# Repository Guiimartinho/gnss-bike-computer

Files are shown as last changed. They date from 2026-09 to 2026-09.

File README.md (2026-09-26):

<div align="center">

# GNSS Bike Computer

**Computador de bordo para ciclismo com GPS: segmentos do Strava em tempo real, percursos, altimetria por fusão de sensores e sensores sem fio. Portado do stravaV10 para Zephyr, do nRF52840 da myStravaB V3 para o nRF54LM20A de uma placa própria com GNSS de banda dupla e painel solar.**











</div>

O projeto leva para o nRF Connect SDK o **stravaV10**, firmware aberto de Vincent Gollé para a placa **myStravaB V3**: um aparelho em retrato com LCD de memória Sharp, GNSS MediaTek, barômetro, acelerômetro, medidor de bateria, microSD e rádio BLE + ANT+. O código original fica em [`legacy/`](legacy/) como referência de comportamento; o port em C puro sobre Zephyr fica em [`zephyr_app/`](zephyr_app/) e compila para o nRF54LM20 DK, para a placa do projeto (`gnssbike/nrf54lm20a/cpuapp`) e ainda para o nRF52840-DK, que saiu de uso. A próxima placa é própria, com o nRF54LM20A, GNSS de banda dupla, tela colorida e painéis solares na caixa que estendem a autonomia, sem sustentar o aparelho sozinhos; a especificação e a avaliação dos componentes estão em [`docs/`](docs/README.md).

> [!WARNING]
> O port **compila e passa nos testes de host, mas nunca rodou em placa nem nos DKs**. Segmentos, percursos, sensores BLE e ANT+, log no SD e a interface do legacy ainda não funcionam de ponta a ponta. A placa nova ainda não existe: nenhum componente foi comprado nem medido. O estado de cada área está em [docs/10-status-do-port.md](docs/10-status-do-port.md).

## Índice

- [Visão geral](#visão-geral)
- [Placa nova](#placa-nova)
- [Funcionalidades](#funcionalidades)
- [Início rápido](#início-rápido)
- [Estrutura](#estrutura)
- [Documentação](#documentação)
- [Estado e próximos passos](#estado-e-próximos-passos)
- [Créditos e licenças](#créditos-e-licenças)

## Visão geral

```mermaid
flowchart LR
    subgraph DEV["myStravaB V3 · nRF52840"]
        MODEL["modelo<br/>altitude, potência,<br/>segmentos, percurso"]
        VUE["interface<br/>LCD LS027 + 3 botões"]
        LOG["log no microSD"]
    end
    GNSS["GNSS M10578-A3"] -->|NMEA| MODEL
    SENS["BME280 · FXOS8700 · STC3100"] -->|I2C| MODEL
    SENSORS["frequência cardíaca, cadência,<br/>potência, rolo"] -->|"ANT+ / BLE"| MODEL
    PHONE["celular<br/>Komoot, LNS"] -->|BLE| MODEL
    MODEL --> VUE
    MODEL --> LOG
    PC["PC"] <-->|"USB / stravaAP"| DEV
```

## Placa nova

<div align="center">

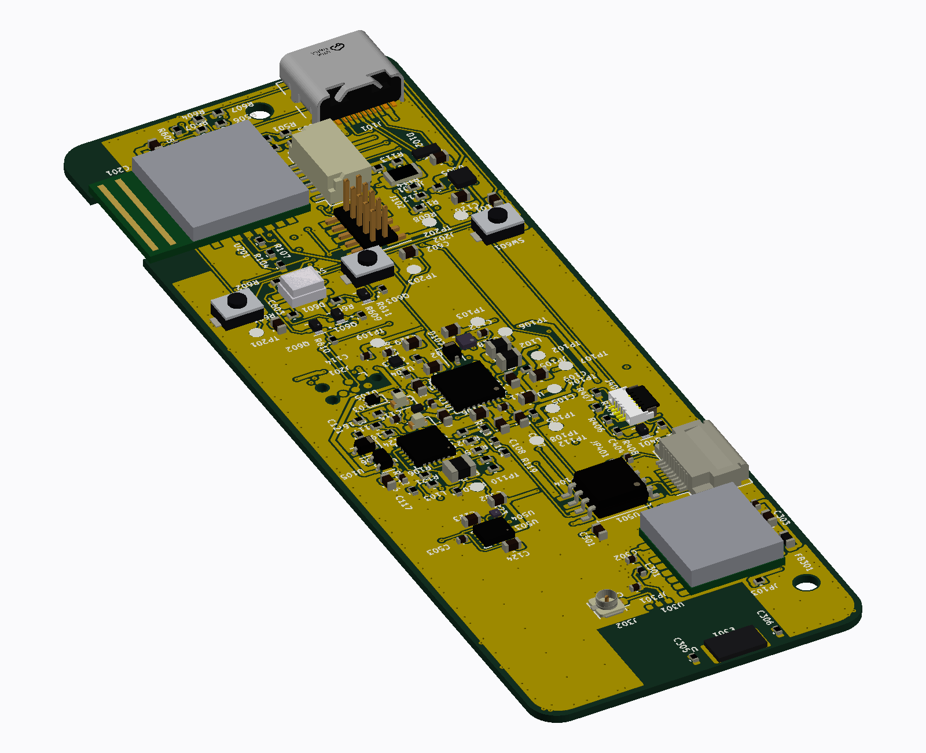
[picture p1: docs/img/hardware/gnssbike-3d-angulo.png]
A placa em CAD, vista em ângulo: o USB-C na borda de cima, o módulo de rádio à esquerda e o receptor GNSS à direita


*A placa `gnssbike`, 34 × 95 mm em 4 camadas, gerada por programa a partir dos documentos de `hardware_gnssbike/`.*

</div>

| | |
|---|---|
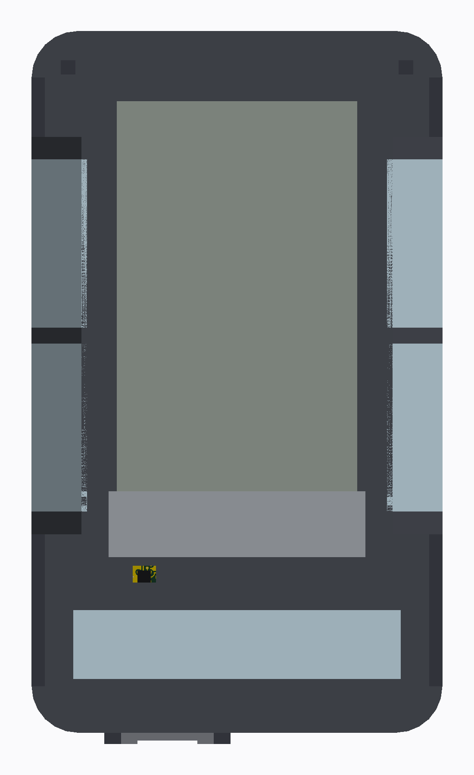
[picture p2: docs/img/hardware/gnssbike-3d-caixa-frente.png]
A caixa proposta, vista de frente: janela do display, três teclas sob a membrana, módulos solares nos chanfros e na faceta
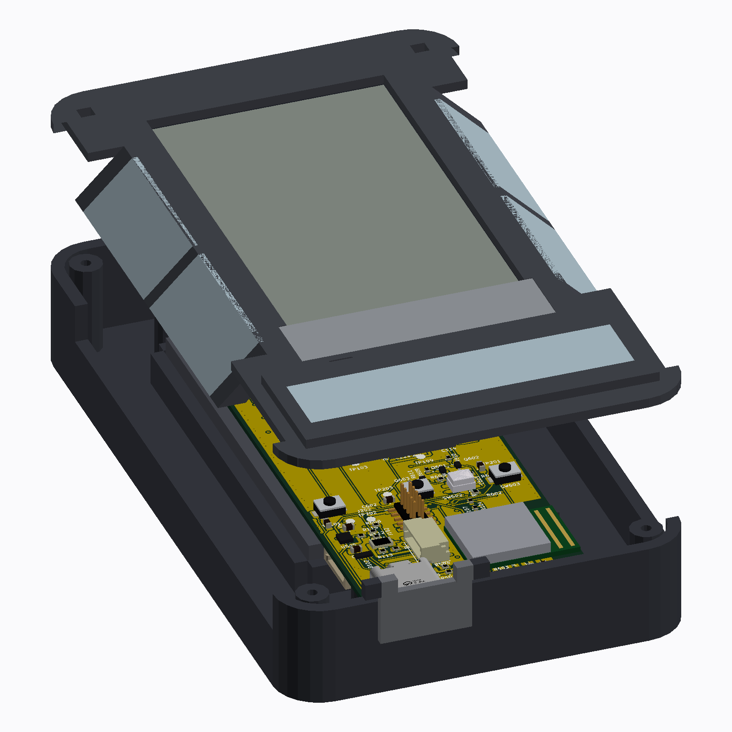
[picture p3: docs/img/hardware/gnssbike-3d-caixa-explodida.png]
A caixa em vista explodida: tampa com o display colado, teclas, módulos e coberturas, a porta do USB-C
|  |  |
| *A caixa proposta em 2026-09-26, 62 × 106 × 17 mm, medida por um dry run próprio* | *Explodida: tampa com o display, teclas, módulos solares, porta do USB-C* |

Manual de montagem: as peças em escala e os oito passos, do chicote solar ao fechamento do aparelho

A caixa foi desenhada em volta da placa real ([`hardware_gnssbike/caixa/`](hardware_gnssbike/caixa/README.md), decisões em [`hardware_gnssbike/04`](hardware_gnssbike/04-pcb-e-caixa.md#a-placa-de-hoje-dentro-da-caixa-do-conceito)); a placa, dimensionada pelo circuito e **não** pela caixa, tem 34 × 95 mm em 4 camadas, 6 módulos solares na faceta e nos chanfros laterais da caixa. A escolha de cada componente, com os números dos datasheets, está em [docs/15-avaliacao-componentes.md](docs/15-avaliacao-componentes.md); a lista de compras, validada peça a peça, em [docs/19-lista-de-compras.md](docs/19-lista-de-compras.md).

A placa existe como **arquivo de CAD**, gerado por programa: 156 peças, 114
redes, 1.417 segmentos, 549 vias, **196 ligações roteadas e 75 ainda sem
trilha**, 0 erros no DRC completo, e 25 das 29 medidas que as fichas dos
componentes e a IPC-2221B impõem, feitas uma a uma
([dry-run de 2026-09-26](hardware_gnssbike/10-dry-run-2026-09-26.md)); a
caixa existe como proposta em volta dela, medida por um dry run próprio (12
regras cumpridas, 0 violadas). Nenhuma placa foi fabricada, nada foi
impresso e nenhum componente passou por bancada. O esquemático, a placa, a
caixa e como se confere cada etapa estão em
[hardware_gnssbike/](hardware_gnssbike/README.md).

```mermaid
flowchart LR
    MCU["MinewSemi ME54BS13<br/>nRF54LM20A, BLE e ANT+"]
    GNSS2["u-blox MAX-F10S<br/>L1 + L5, 46,8 mW"] -->|UART| MCU
    LCD2["JDI LPM027M128C de 8 cores,<br/>com luz frontal integrada"] ---|SPI| MCU
    PWR["nPM1300, ADP5091, MAX17262<br/>USB-C e painel solar"] -.->|I2C| MCU
    SENS2["BMP585, BMI270,<br/>MMC5603NJ, OPT3001"] -->|I2C| MCU
    MEM["flash MX25R6435F<br/>8 MB, soldada"] ---|SPI| MCU
```

| Bloco | Escolha | Por quê |
|---|---|---|
| Carga | nPM1300 no USB-C, ADP5091 no painel, MAX17262 na célula | o painel carrega com o aparelho desligado e corte térmico próprio; o USB bloqueia a carga solar no hardware |
| GNSS | u-blox MAX-F10S, banda dupla L1 + L5, com o MAX-M10N-10B (só L1) no mesmo footprint | 1 m de CEP contra 1,5 m, e o código do L5 contra o multipercurso de prédio e mata. Custa autonomia: o aparelho gasta cerca de 58 mW e dura cerca de 115 h sem sol, e o painel devolve de 23 a 46 min por hora de sol em vez de cobrir o consumo. Com o M10N em LEAP seriam cerca de 21 mW e 310 h (estimativas) |
| Tela | JDI LPM027M128C de 8 cores, **com luz frontal integrada** (escolha do dono em 2026-09-23, no lugar do par Sharp + filme); a Sharp LS027B7DH01A com filme no mesmo conector, de reserva | o firmware atende as duas pelo mesmo driver, em retrato, com um tema para cada |
| USB e armazenamento | USB-C HRO TYPE-C-31-M-12 e flash MX25R6435F soldada | caixa sem tampas e sem cartão solto na vibração |

## Funcionalidades

| Funcionalidade | Legacy | Port |
|---|---|---|
| Segmentos do Strava com avanço contra o recorde | sim | lógica portada, sem carga de dados |
| Percurso com mapa e zoom | sim | parcial, não ligado |
| Altitude por Kalman de 3 estados, subida, inclinação | sim | portado com diferenças |
| Potência estimada | sim | fórmula diferente |
| Sensores ANT+ (FC, velocidade e cadência, rolo FE-C) | sim | a pilha do add-on `sdk-ant` compila com o NCS v3.3.0 (`ANT=1`) e o firmware abre canal escravo; **nenhum canal abre de fato**, porque os perfis ficam fora do repositório e `GNSS_ANT_*_DEV_TYPE` valem 0 |
| BLE (potência, posição do celular, Komoot) | sim | parcial |
| Zonas de potência, suffer score, variabilidade da FC | sim | portados e testados, sem dados reais |
| Log no microSD e download pelo PC | sim | FatFs de verdade, gravado pelo serviço de armazenamento; não testado com cartão |
| USB serial e mass storage | sim | serviço `usb` no build (CDC dos comandos e o disco do ciclista); não testada com cabo |
| Telas em retrato, menu, notificações, botões | sim | LVGL no firmware com driver próprio da tela, 44 quadros testados no PC; nunca vistos num painel |

## Início rápido

**Pré-requisitos** (Windows): nRF Connect SDK v3.3.0 em `C:\ncs` com o toolchain `936afb6332`, SEGGER J-Link, nRF54LM20 DK (o nRF52840-DK ainda compila, mas saiu de uso). Para o ANT, o add-on `sdk-ant` em `C:\ncs\sdk-ant`, depois de aceitar o acordo ANT+ ([07](docs/07-radio-ant-ble.md#ant-no-ncs-v330)). Para os testes de host: MinGW-w64 GCC, CMake e Ninja. Detalhes em [docs/03-ambiente-build.md](docs/03-ambiente-build.md).

Código: [github.com/Guiimartinho/gnss-bike-computer](https://github.com/Guiimartinho/gnss-bike-computer) (`git clone https://github.com/Guiimartinho/gnss-bike-computer.git`).

```sh
# Git Bash, na raiz do repositório
bash tools/fw/fw.sh build          # compila o zephyr_app (sysbuild) para o nRF54LM20 DK
bash tools/fw/fw.sh flash          # grava no DK pelo J-Link
BOARD=gnssbike/nrf54lm20a/cpuapp BUILD_DIR=zephyr_app/build_custom bash tools/fw/fw.sh build   # a placa do projeto
ANT=1 bash tools/fw/fw.sh build pristine   # com a pilha ANT do sdk-ant
bash tools/fw/host_tests.sh        # 53 conjuntos, 714 casos
python tools/ui/render_screens.py  # desenha os 44 quadros no PC (docs/telas)
python tools/docs/mermaid_check.py # valida os diagramas da documentação
```

No `cmd` ou com duplo clique: `build.bat`, `flash.bat`, `recover.bat`, `serial.bat COMx`.

O CI (`.github/workflows/ci.yml`) está **desligado**: só roda à mão, pela aba Actions do GitHub ([detalhes](docs/03-ambiente-build.md#ci)).

## Estrutura

```mermaid
flowchart TB
    ROOT["gnss_bike_computer/"]
    ROOT --> ZA["zephyr_app/<br/>port Zephyr: src, include, boards, modules, tests/host"]
    ROOT --> LEG["legacy/<br/>stravaV10 original (referência)"]
    ROOT --> LIB["libraries/<br/>bibliotecas do legacy"]
    ROOT --> TOOLS["tools/<br/>fw e docs do projeto · TDD, zpm, MMD, jumper do legacy"]
    ROOT --> HW["hardware/<br/>Eagle da myStravaB V3 (Gerbers da V2)"]
    ROOT --> HWN["hardware_gnssbike/<br/>a placa nova: docs 01 a 10, cad (KiCad e geradores),<br/>esquematico, placa, caixa (PDF, STL, dry run), datasheets"]
    ROOT --> DOCS["docs/<br/>documentação numerada, img (telas, hardware), historico"]
    ROOT --> AI["CLAUDE.md · AGENTS.md · .claude/skills/"]
    ROOT --> BAT["build.bat · flash.bat · recover.bat · serial.bat"]
```

## Documentação

| Documento | Assunto |
|---|---|
| [01 · Visão geral](docs/01-visao-geral.md) | produto, modos, legacy e port |
| [02 · Hardware](docs/02-hardware.md) | placa, pinagem, alimentação, alvo no DK |
| [03 · Ambiente e build](docs/03-ambiente-build.md) | NCS v3.3.0, scripts, gravação, problemas conhecidos |
| [04 · Arquitetura do legacy](docs/04-arquitetura-legacy.md) | tasks, modos, glossário |
| [05 · Arquitetura do port](docs/05-arquitetura-zephyr.md) | threads, fluxo de dados, pilhas, devicetree |
| [06 · Algoritmos](docs/06-algoritmos.md) | fórmulas e constantes, legacy × port |
| [07 · Rádio](docs/07-radio-ant-ble.md) | ANT+, BLE, stravaAP, Komoot |
| [08 · Interface](docs/08-interface.md) | telas, menus, botões |
| [09 · Armazenamento e USB](docs/09-armazenamento-usb.md) | formatos de arquivo, SD, USB |
| [10 · Status do port](docs/10-status-do-port.md) | matriz, correções, defeitos, roteiro, decisões |
| [11 · Qualidade e MISRA](docs/11-qualidade-misra.md) | regras e análise estática |
| [12 · Ferramentas e testes](docs/12-ferramentas-testes.md) | testes de host, simulador do legacy, licenças |
| [13 · Placa nova](docs/13-placa-nova.md) | proposta de hardware da placa própria |
| [14 · Hardware da placa nova](docs/14-hardware-placa-nova.md) | especificação técnica: alimentação, lista de materiais, pinos, PCB |
| [15 · Avaliação dos componentes](docs/15-avaliacao-componentes.md) | escolha de cada componente da placa nova, com números de datasheet |
| [16 · Arquitetura do firmware](docs/16-arquitetura-firmware.md) | arquitetura-alvo e máquinas de estado para a placa nova |
| [17 · Dispositivos BLE e ANT+](docs/17-dispositivos-ble-ant.md) | catálogo de sensores e acessórios, prioridades e limites do rádio |
| [18 · Interface e telas](docs/18-interface-telas.md) | interface LVGL da placa nova: todas as telas, desenhadas e testadas no PC, em 8 cores e em preto e branco |
| [19 · Lista de compras](docs/19-lista-de-compras.md) | peças validadas em duas passagens, trocas, correções de integração e códigos da DigiKey |
| [Hardware da placa nova](hardware_gnssbike/README.md) | o esquemático folha a folha, os cálculos, a lista de nós, a placa e a caixa, os conectores, o layout e os dois dry runs; o CAD em [`cad/`](hardware_gnssbike/cad/README.md), a caixa em [`caixa/`](hardware_gnssbike/caixa/README.md), os PDF em [`esquematico/`](hardware_gnssbike/esquematico/) e [`placa/`](hardware_gnssbike/placa/) |
| [CHANGELOG](CHANGELOG.md) | histórico de mudanças |

## Estado e próximos passos

- **Feito em 2026-09-18:** build no NCS v3.3.0 com sysbuild; correção de 13 defeitos críticos (estouro de pilha no Kalman, GPS e modelo dentro de ISR, corrupção de memória no log, botões e pinos do GPS invertidos, conflitos de pinos com o DK); testes de host; documentação e contexto para assistentes de IA.
- **Fase 1 do roteiro:** a base da arquitetura nova (serviços com thread própria, eventos no zbus, máquinas de sistema e de modo no SMF, watchdog por serviço, desligamento automático do legacy), feita em 2026-09-19.
- **Novos alvos e rádio:** o port compila para o nRF54LM20 DK, e a pilha ANT do add-on `sdk-ant` v2.1.1 compila sobre o NCS v3.3.0 nos dois DKs (`ANT=1`); nada disso foi testado em placa.
- **Interface:** os 44 quadros em LVGL, testadas no PC, rodam no firmware desde 2026-09-19 com um driver próprio da tela (JDI LPM027M128B em 8 cores ou Sharp em preto e branco, em retrato), teclas com toque longo e a máquina da luz; nunca vistas num painel.
- **Placa nova:** desenho do aparelho, especificação ([14](docs/14-hardware-placa-nova.md)) e avaliação dos componentes ([15](docs/15-avaliacao-componentes.md)). O esquemático é do dono; antes do layout vêm os testes de bancada da carga dupla, do GNSS (C/N0 por banda e isolamento da antena contra o rádio de 2,4 GHz), da coexistência dos rádios e do display.
- **Hardware da placa nova (2026-09-23 a 26):** o esquemático em sete folhas, a placa de 34 × 95 mm colocada e roteada por programa, o desenho de montagem, o manual e o chicote solar, dois dry runs (as regras das fichas e da IPC-2221 medidas no arquivo; a caixa medida contra a placa) e a proposta de caixa de 62 × 106 × 17 com STL para a primeira prova. Nada fabricado, nada impresso, nenhum componente na bancada; o que falta antes de mandar fabricar está em [`hardware_gnssbike/README.md`](hardware_gnssbike/README.md#antes-de-mandar-fabricar).
- **Decidido:** ANT+ e BLE juntos (os equipamentos externos falam ANT+) e placa própria com o nRF54LM20A. Decisões e pendências em [docs/10-status-do-port.md](docs/10-status-do-port.md#decisões-do-dono).
- **Próximo:** os testes de bancada da placa nova (carga dupla, isolamento entre as antenas, o display sobre a antena GNSS), o roteamento que falta e a primeira prova impressa da caixa; no firmware, fidelidade dos algoritmos, armazenamento, rádio e interface. Roteiro em [docs/10-status-do-port.md](docs/10-status-do-port.md#roteiro).

## Créditos e licenças

- **stravaV10** e **myStravaB**: Vincent Gollé ([vincent290587/stravaV10](https://github.com/vincent290587/stravaV10)), licenciado sob **Creative Commons Atribuição-NãoComercial 4.0 (CC BY-NC 4.0)**. O port deriva desse código; ver [`legacy/README.md`](legacy/README.md).
- Bibliotecas de terceiros em `libraries/` e `tools/` mantêm suas licenças (BSD, LGPL-2.1, GPL-2.0, Nordic, SEGGER): tabela em [docs/12-ferramentas-testes.md](docs/12-ferramentas-testes.md#bibliotecas-e-licenças).
- O add-on `sdk-ant` e o material ANT+ não fazem parte do repositório: o ANT+ Adopter Agreement proíbe redistribuir ([07](docs/07-radio-ant-ble.md#decisão-ant-e-ble)).
- **Este projeto é CC BY-NC 4.0** ([`LICENSE`](LICENSE), decisão do dono em 2026-09-26): código, hardware e documentação podem ser copiados, estudados, modificados e redistribuídos, com atribuição, e **não podem ser usados comercialmente**. É a mesma licença do stravaV10, do qual o port deriva, e por isso a restrição vale sobre o todo. Não é uma licença "open source" no sentido da OSI, que não admite restrição de uso: é código aberto com uso não comercial. Uso comercial só com autorização por escrito do dono e, para o que vem do stravaV10, do autor dele.

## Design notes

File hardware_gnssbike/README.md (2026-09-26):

<div align="center">

# Hardware · GNSS Bike Computer

**Placa `gnssbike`, nRF54LM20A no módulo MinewSemi ME54BS13**










</div>

A placa vista em ângulo, com o USB-C na borda de cima, o módulo de rádio à esquerda e o receptor GNSS à direita

O hardware completo do aparelho: cada folha do esquemático, cada ligação, a
conta que justifica cada valor — e a placa, com as peças postas, o cobre
roteado e as vistas 2D e 3D. Nasce da especificação de
[`docs/14`](../docs/14-hardware-placa-nova.md), da avaliação de
[`docs/15`](../docs/15-avaliacao-componentes.md) e da lista validada de
[`docs/19`](../docs/19-lista-de-compras.md), e fecha o que faltava: os nós
com nome, os passivos com valor, e o mapa de pinos do
[devicetree](../zephyr_app/boards/gnss/gnssbike/) levado até o pino do
componente.

> [!WARNING]
> **Nada disto foi montado, medido ou fabricado.** A placa existe como
> arquivo de CAD — 156 peças, 114 redes, 1.417 segmentos, 549 vias, **196
> ligações roteadas e 75 sem trilha** (58 itens desconectados no DRC
> completo, 0 erros) e 25 das 33 regras das fichas cumpridas
> ([09](09-dry-run-da-pcb.md), [10](10-dry-run-2026-09-26.md), 2026-09-26)
> —, e a caixa existe como proposta medida por um dry run próprio (12
> regras cumpridas, 0 violadas, [04](04-pcb-e-caixa.md#a-placa-de-hoje-dentro-da-caixa-do-conceito));
> mas nenhuma foi feita e nenhum componente passou por bancada. Este aviso já disse "0 ligações sem trilha" com 47 em aberto:
> o DRC rodava só com erros, e os não roteados são aviso. Todo valor
> abaixo vem de ficha ou de conta feita aqui, e está marcado como tal. O
> que depende de decisão, de ficha por ler ou de medida está na lista de
> [Antes de mandar fabricar](#antes-de-mandar-fabricar).

## O CAD e o que sai dele

Tudo em [`cad/`](cad/) é **gerado por programa**, não desenhado à mão: o
esquemático, o footprint de cada peça, a colocação, o roteamento e as
vistas. A cadeia inteira e os comandos estão em
[`cad/README.md`](cad/README.md). Os arquivos que se leem ficam fora das
fontes, cada um na sua pasta (2026-09-26):

| Pasta | Arquivo | O que é |
|---|---|---|
| [`esquematico/`](esquematico/) | [`gnssbike-esquematico.pdf`](esquematico/gnssbike-esquematico.pdf) | as sete páginas do esquemático, com símbolo de peça de verdade |
| [`placa/`](placa/) | [`gnssbike-pcb.pdf`](placa/gnssbike-pcb.pdf) | sete páginas: uma por camada de cobre, mais a de conjunto |
| | [`gnssbike-2d.svg`](placa/gnssbike-2d.svg) | as quatro camadas numa folha só, para olhar rápido |
| | [`gnssbike-montagem.pdf`](placa/gnssbike-montagem.pdf) | o desenho de montagem, 156 peças com linha de chamada |
| [`caixa/`](caixa/README.md) | [`gnssbike-caixa.pdf`](caixa/gnssbike-caixa.pdf) e os `caixa-*.stl` | a proposta de caixa, medida pelo `dry_run_caixa.py`, e as peças para a primeira prova impressa |
| [`docs/img/hardware/`](../docs/img/hardware/) | `gnssbike-3d-frente.png`, `-tras.png`, `-angulo.png` | a placa vista de cima, de baixo e em ângulo |
| | `gnssbike-3d-montagem.png` | a pilha: display, placa e célula |
| | `gnssbike-3d-caixa-aberta.png`, `-frente.png`, `-explodida.png` | a caixa com a placa, a célula e o display dentro |
| [`docs/img/`](../docs/img/) | [`manual-de-montagem.svg`](../docs/img/manual-de-montagem.svg) | o **manual de montagem**: as peças em escala e os oito passos |
| [`docs/img/chicote-solar.svg`](../docs/img/chicote-solar.svg) | como ligar os seis módulos solares na placa |

## Índice

| Documento | O que traz |
|---|---|
| [01 · Folhas do esquemático](01-esquematico.md) | as seis folhas, bloco a bloco, com todas as ligações |
| [02 · Cálculos](02-calculos.md) | cada valor de componente, com a conta e a origem |
| [03 · Lista de nós](03-netlist.md) | o esquemático como lista: nó, de onde sai, aonde chega |
| [04 · Placa e caixa](04-pcb-e-caixa.md) | tamanho, camadas, posicionamento, zonas proibidas |
| [05 · Materiais por folha](05-materiais.md) | o que cada folha consome, ligado à lista de compras |
| [06 · Conectores e pontos de teste](06-conectores-e-pontos-de-teste.md) | cada conector pino a pino, e onde encostar a ponta de prova |
| [07 · Sequências e proteção](07-sequencias-e-protecao.md) | em que ordem os trilhos sobem e descem, e o que protege o que sai da caixa |
| [08 · Plano de layout](08-layout.md) | regras de projeto, ordem de roteamento, terra e retorno, os nós críticos e a subida da primeira placa |
| [09 · Dry-run da placa](09-dry-run-da-pcb.md) | as regras das fichas e da IPC-2221 medidas no arquivo de CAD, com o que passa, o que falha e o que ninguém mediu |
| [10 · Dry-run de 2026-09-26](10-dry-run-2026-09-26.md) | placa roteada, esquemático, mecânica e contas, em três análises independentes: o que foi corrigido no dia e o que fica para o dono |
| [CAD](cad/README.md) | como o esquemático e a placa são gerados, e como se confere cada etapa |
| [Caixa](caixa/README.md) | a proposta de caixa em volta da placa: o gerador, o dry run de 13 regras, o PDF e os STL |

## O aparelho em blocos

```mermaid
flowchart TB
    subgraph F1["Folha 1 · Energia"]
        USBC["USB-C<br/>HRO TYPE-C-31-M-12"] --> NPM["nPM1300<br/>PMIC e carregador"]
        CELL["LiPo 1S 2000 mAh"] --> GAUGE["MAX17262<br/>medidor, sensor 7 mΩ"]
        GAUGE --> NPM
        PV["6 módulos solares<br/>KXOB25-05X3F"] --> AEM["ADP5091<br/>colheita solar"]
        AEM --> GAUGE
        NPM --> RAILS(("3V0 · SD3V0 · 3V3BL<br/>1V8 montado, sem carga"))
        CELL --> TPS["TPS7A02 1,8 V"] --> VBCKP(("VBCKP"))
    end

    subgraph F2["Folha 2 · MCU"]
        MOD["MinewSemi ME54BS13<br/>nRF54LM20A"]
        SWD["Tag-Connect TC2030-NL<br/>e J202, Cortex de 10 vias"] --- MOD
        PADS["pads do console<br/>uart20"] --- MOD
    end

    subgraph F3["Folha 3 · GNSS"]
        MAXF["u-blox MAX-F10S<br/>L1 + L5 · a 3,0 V, sem tradutor"]
        ANT1["antena L1/L5<br/>Unictron H2UJ4U1H2Q0100"] --- MAXF
    end

    subgraph F4["Folha 4 · Display"]
        FPC["Hirose FH12-10S-0.5SH<br/>10 vias"] --- PANEL["JDI LPM027M128C<br/>8 cores, com luz"]
        BL["luz do painel<br/>HC-FPC-05, 5 vias"] -.->|"ordem das vias em aberto"| PANEL
    end

    subgraph F5["Folha 5 · Memória e sensores"]
        NOR["MX25R6435F<br/>8 MB"]
        SENS["BMP585 · BMI270<br/>MMC5603NJ · OPT3001"]
    end

    subgraph F6["Folha 6 · Interface"]
        KEYS["3 teclas<br/>XunPu TS-1088R"]
        BUZ["buzzer<br/>Murata PKLCS1212"]
        RGB["LED RGB<br/>S4-3528RGBTA-A"]
    end

    RAILS --> F2
    RAILS --> F3
    RAILS --> F4
    RAILS --> F5
    RAILS --> F6
    MOD -.->|"spi00"| NOR
    MOD -.->|"i2c23"| SENS
    MOD -.->|"uart21"| TXU
    MOD -.->|"spi22"| FPC
    MOD -.->|"i2c30"| NPM
    MOD -.->|"GPIO e PWM"| F6
```

## Referências que este esquemático segue

Seguir a referência de projeto quer dizer coisas diferentes para cada
bloco, e vale dizer exatamente qual foi usada em cada caso:

| Bloco | Referência seguida | Onde foi conferida |
|---|---|---|
| Rádio de 2,4 GHz e alimentação do MCU | **módulo ME54BS13**: casamento, antena de PCB e cristais são do módulo, não deste projeto; o que sobra para a placa é o desacoplamento, a zona livre da antena e os pads de USB, SWD e console | ficha MinewSemi ME54BS13 V1.0.0, de 2026-06-23 (pinagem, p. 6 a 9; regras de PCB, 7.2 e 7.3); a pinagem e as cotas do desenho mecânico estão transcritas em [`cad/parts.py`](cad/parts.py) e [`cad/footprints.py`](cad/footprints.py) |
| Caminho de energia | **configuração 1 da lista de referência da Nordic** para o nPM1300 (tabelas 39 e 40 da ficha), com os indutores e capacitores que ela pede | ficha nPM1300 v1.1, conferida em [15](../docs/15-avaliacao-componentes.md#detalhes-para-o-esquemático) |
| Colheita solar | **lista mínima de materiais da e-peas** (tabela 43 da ficha do AEM10900), com a exceção registrada do indutor | ficha AEM1090x v2.4.0 |
| Medidor de bateria | **circuito de aplicação do MAX17262** com sensor entre BATT e SYS | ficha Maxim |
| GNSS | **projeto de referência do MAX-F10S**: entrada com SAW, LNA e SAW já dentro do módulo; a placa entrega alimentação limpa, a linha de 50 Ω e a zona livre | ficha MAX-F10S R03, conferida em [15](../docs/15-avaliacao-componentes.md#gnss) |
| Display | ficha do painel e do conector: ordem dos 10 pinos, EXTMODE no VDD, VCOM pelo EXTCOMIN | fichas JDI LPM027M128**B** Ver.01 e Sharp LS027B7DH01 (LD-28305A); do **C**, que é a tela montada, as especificações publicadas da `3LPM027M128C specification ver.02` — 10 vias de sinal, **5 vias só para a luz**, 2,67 V e 16 mA ([06](06-conectores-e-pontos-de-teste.md#j402--luz-do-lpm027m128c)). Os PDF da JDI estão 404: falta a **ordem das cinco vias** |

> [!IMPORTANT]
> **O documento de diretrizes de projeto de hardware do nRF54LM20 da
> Nordic não foi lido nesta sessão.** O que protege o projeto disso é o
> módulo: a parte de radiofrequência, que é onde essas diretrizes mandam,
> vem pronta no ME54BS13, e o que a placa faz em volta dele segue a ficha
> do módulo. Se o dono quiser o chip direto na placa algum dia, essas
> diretrizes passam a ser obrigatórias e este esquemático não serve como
> está. **O que muda com o ME54BS13 é a certificação:** a ficha V0.5.0 não
> traz nenhuma, e a V1.0.0 não foi lida quanto a isso — o BM20C trazia FCC,
> ISED, TELEC e conformidade europeia, e **esse aval não pode ser assumido
> aqui** ([abaixo](#fichas-que-precisam-ser-lidas)).

## Os dry-runs

O esquemático foi escrito e depois **revisado contra si mesmo e contra as
fontes**, duas vezes: em **2026-09-22**, sobre a primeira versão, e em
**2026-09-23**, sobre a versão completa, já com os cálculos novos e os
documentos [06](06-conectores-e-pontos-de-teste.md) e
[07](07-sequencias-e-protecao.md).

### O primeiro, em 2026-09-22

Duas passagens independentes: uma refez todas as contas e
procurou contradição interna, a outra conferiu folha por folha contra
[`docs/13`](../docs/13-placa-nova.md), [`14`](../docs/14-hardware-placa-nova.md),
[`15`](../docs/15-avaliacao-componentes.md), [`19`](../docs/19-lista-de-compras.md)
e o devicetree. Acharam **43 problemas**, sendo **6 graves**.

Vale dizer o que isso significa: quase todos os graves eram **erro de quem
escreveu o esquemático, não falha da especificação**. A especificação já
trazia o arranjo certo e o rascunho não a leu com cuidado suficiente.

| Grave | O que era | Como ficou |
|---|---|---|
| Direção dos canais do tradutor de nível | o rascunho pôs o `RX` num canal que vai do MCU ao receptor e o `RESET_N` num que vai do receptor ao MCU: **saída contra saída nos dois pares**, e o receptor nunca falaria com o MCU. Daí concluiu que "cinco sinais não cabem em quatro canais" e deixou o `EXTINT` sem componente | refeito: o `RESET_N` **não passa pelo tradutor** (dreno aberto, pull-up interno do módulo), e os quatro canais atendem `TX`, `EXTINT`, `RX` e `TIMEPULSE`, dois em cada sentido, como a [especificação](../docs/14-hardware-placa-nova.md#gnss) já dizia |
| Sensor do medidor de bateria | o rascunho criou um resistor externo de 7 mΩ e pinos `CSP`/`CSN` que o CI não tem. Montado assim, a resistência dobra e o medidor erra **toda** corrente | o sensor é **interno** à `MAX17262REWL+T`; a peça inventada saiu |
| `STO_CFG[1]` do AEM10900 | ausente de todos os arquivos. Pino de configuração aberto lê alto, e é ele que decide o limiar de carga da célula ao sol | ao `GND`, com os outros dois no `VINT`: H, L, H, carga até 3,90 V e corte em 3,01 V |
| `OE` do tradutor | não existia em nó nenhum; aberto, as saídas ficam indefinidas na partida | fixo no `VCCA` |
| `CSB` do BMP585 e do BMI270 | condição enunciada em prosa e sem nó: os dois nasceriam em SPI e o barramento não acharia ninguém | na tabela de [pinos de configuração](03-netlist.md#pinos-de-configuração-amarrados-em-cobre) |
| Acionamento do LED RGB | catodo direto no pino do MCU, com o anodo num trilho que chega a 5,5 V | um MOSFET por cor, com 1 kΩ, como a especificação já pedia |

### O segundo, em 2026-09-23

Sobre a versão completa, já com os cálculos novos e os documentos
[06](06-conectores-e-pontos-de-teste.md) e
[07](07-sequencias-e-protecao.md). Achou **65 problemas, 2 graves** — e de
novo quase tudo era erro de quem escreveu.

**Os dois graves foram na mesma peça, o LED RGB, em rodadas diferentes.**
Na primeira, o catodo estava no pino do MCU, cujo anodo chega a 5,5 V com o
cabo; entrou um MOSFET por cor. Na segunda descobriu-se que o **resistor
tinha ficado do lado errado**: o LED é de **anodo comum**, os três dies
dividem um pino, e com o resistor ali ele fica em paralelo com o die, que
passa a ver o `VSYS` nu. O resistor vai entre cada catodo e o seu MOSFET —
e a mesma inversão estava na luz do display.

Dos médios, os que mudaram o desenho: o resistor de série do `MISO` estava
na ponta que **recebe**, onde não amacia borda nenhuma; o divisor do
`DIS_STO_CH`, que é o único intertravamento sem firmware, **não tem
orientação definida em fonte nenhuma**; a derivação da tecla central para o
`SHPHLD` não estava dita como saindo depois do resistor; e a lista de
materiais montava **os dois** caminhos do termistor do colhedor, que é o
caso que mata a carga solar.

E quatro contas estavam erradas, com a pior no calor: dentro da caixa não é
"o carregador mais a perda dos reguladores", é **tudo o que entra pelo cabo
e não vira química na célula** — 1,89 W, que põem a caixa em **45,1 °C** a
25 °C de ambiente (44,7 na caixa do conceito, de 192 cm²; a proposta de
62 × 106 × 17 tem 189), empate com o corte do JEITA **antes de qualquer sol**.

### O que os dry-runs deixaram para trás

Dos 43 do primeiro, os 6 graves foram corrigidos na hora. Dos demais, os que mudavam o
circuito entraram em 2026-09-23 — a proteção das três teclas, os
resistores de série do buzzer e do SPI da flash, os pull-downs das portas
e dos sinais ativos altos, o capacitor de volume do módulo, a topologia do
painel solar, o orçamento do USB e os pontos de teste. O que **não** foi
fechado está na lista logo abaixo, e é de dois tipos: decisão do dono e
ficha por ler.

## Antes de mandar fabricar

Nada aqui é opinião: é o que precisa estar fechado para a placa poder ser
feita. Enquanto houver item aberto nas duas primeiras seções, **o
esquemático não está pronto para virar layout**.

### Decisões que são do dono

- [x] **Ligação da tecla central** — **decidido em 2026-09-26: ao `SHPHLD` e ao P1.27, com o Schottky `D107` isolando o pino do MCU** do nó do PMIC, que sobe até 5,5 V com o cabo. O firmware continua lendo a tecla pelo GPIO ([01](01-esquematico.md#folha-6--interface)).
- [x] **Alimentação do receptor GNSS** — **decidido em 2026-09-26: 3,0 V, no trilho do MCU**, `VIO_SEL` aberto (opção 1 da tabela 35 do manual de integração). O BUCK1 é de ±5 % e o projeto de 1,8 V pede ±2 %; o LDO de ±1 % custava 35 mW na bateria contra 11 mW da opção 1. Saíram o tradutor de nível e o LDO; o BUCK1 fica montado, sem carga ([02](02-calculos.md#o-receptor-no-3v0-e-o-1v8-sem-carga)).
- [x] **Corte térmico da carga solar** — **decidido em 2026-09-26: comparador TLV7031 com o divisor do NTC alimentado pelo painel**, saída em OU de diodos no `DIS_SW`. Só o lado quente; o frio está logo abaixo ([07](07-sequencias-e-protecao.md#o-corte-térmico-da-carga-solar)).
- [ ] **Carga solar abaixo de 0 °C** — o comparador só corta o lado quente, e uma célula de lítio carregada abaixo de zero deposita lítio metálico. Segundo comparador (a outra metade de um TLV7032) com a referência do frio, ou aceitar o risco pelo clima de uso ([01](01-esquematico.md#folha-1--energia)).
- [ ] **Célula de 60 mm numa placa com 58,1 mm entre as duas antenas** — a célula de 36 × 60 não cabe atrás da placa sem entrar 1,9 mm na área da antena GNSS ou na do módulo, que recusam metal; e o display de 61,8 mm cobre 7,2 mm da antena GNSS. Célula de até 58 mm, ou outra caixa ([04](04-pcb-e-caixa.md#as-duas-sombras-display-e-bateria)).
- [x] **Qual painel** — **decidido em 2026-09-23: o JDI LPM027M128C**, peça única de 2,7", 400 × 240, MIP de 8 cores e **com luz frontal integrada**, no lugar do par Sharp LS027B7DH01A + filme Azumo. Sem etapa de laminação, mesma resolução, consumo menor e cor. A Sharp continua sendo o **plano B** no mesmo conector. O que a decisão custa: R$ 776 contra US$ 90,06 do par, **sem canal autorizado e sem garantia** ([01](01-esquematico.md#folha-4--display), [19](../docs/19-lista-de-compras.md#display)).
- [x] **Qual antena** — **resolvida no CAD**: a **Unictron H2UJ4U1H2Q0100**, de 5 × 3 mm, no lugar da TE L000670 de 10,75 mm que não cabia na zona reservada. A zona da antena caiu de 40,5 × 14,5 para 15,0 × 9,35 mm e a peça passou a morar **na placa**, e não fora dela ([04](04-pcb-e-caixa.md#zonas-proibidas)).
- [ ] **Acertar `docs/15` e `docs/19` ao módulo montado** — este esquemático e o CAD já usam o **MinewSemi ME54BS13**, mas a [avaliação](../docs/15-avaliacao-componentes.md#módulo-do-mcu) e a [lista de compras](../docs/19-lista-de-compras.md#mcu-e-rádio) ainda dão o Fanstel BM20C como escolhido e o ME54BS13 como plano B a US$ 9,00, quando a loja da MinewSemi o vende a **US$ 6,00**. Os dois documentos só mudam com a decisão do dono.

### Fichas que precisam ser lidas

- [ ] **Ordem das cinco vias do conector da luz** — a ficha do C dá duas interfaces, **10 vias de sinal e 5 vias só para a luz**, as duas com passo de 0,5 mm, mais 2,67 V e 16 mA, e o `J402` já é esse conector. Falta **qual via é anodo, qual é catodo e quais não se usam**: os dois PDF da JDI respondem 404 ([06](06-conectores-e-pontos-de-teste.md#j402--luz-do-lpm027m128c)).
- [x] **Peça do conector de 5 vias** — **resolvida**: o `J402` é a **HCTL HC-FPC-05-10-5RLTAG** (LCSC C5213728), 5 vias com passo de 0,5 mm, no lugar do Molex de 4 vias herdado do filme da Sharp. Falta só a **ordem** das vias, logo acima.
- [ ] **Domínio de tensão dos pinos digitais do nPM1300** — se for o `VSYS`, o `PMIC_INT` e o I²C da energia não casam com os 3,0 V do MCU ([02](02-calculos.md#pull-ups-do-i²c)).
- [ ] **De que lado do sensor interno ficam o `BATT` e o `SYS` do MAX17262** — trocar os dois inverte o sinal da corrente ([01](01-esquematico.md#folha-1--energia)).
- [ ] **Brown-out e `VSYSPOF` do nPM1300** — a partida suave já está levantada (cerca de 1,2 ms, 360 µs/V), estes dois não ([07](07-sequencias-e-protecao.md)).
- [x] **Pinagem do cabo Tag-Connect TC2030-CTX-NL** — conferida em 2026-09-25 na ficha oficial `TC2030-CTX_1.pdf`: o `nRESET` fica no contato **3** e o `SWO` no **6**. O projeto tinha o reset no 6 e **foi corrigido** ([06](06-conectores-e-pontos-de-teste.md#j201--depuração-swd)).
- [x] **Pad de cada GPIO do módulo** — **levantado**, da ficha ME54BS13 V1.0.0 (p. 6 a 9): os 80 pads estão transcritos em [`cad/parts.py`](cad/parts.py) (`PADS_ME54BS13`), e os 31 pinos desta placa, mais os dois reservados, saem todos neles ([01](01-esquematico.md#folha-2--mcu)).
- [ ] **Espelhamento do mapa de pads do ME54BS13** — a V1.0.0 e a V0.5.0 discordam de qual lado é qual. Conferir **num módulo real** que os `GND` `D0`, `E0` e `F0` ficam do lado do `VDD` (pad 19) antes de mandar fabricar.
- [ ] **Certificação do ME54BS13** — a ficha V0.5.0 não traz nenhuma e a V1.0.0 não foi lida quanto a isso. O módulo que este esquemático descrevia antes, o Fanstel BM20C, trazia FCC, ISED, TELEC e conformidade europeia; **esse aval não vale para o ME54BS13 até alguém ler a ficha**.
- [ ] **Tolerância do cristal de 32,768 kHz do módulo** — o ANT+ pede ±50 ppm e essa tolerância **não está levantada para o ME54BS13**. Perguntar à MinewSemi, e medir o LFCLK contra o 1 PPS do receptor no protótipo.
- [ ] **Um termistor para o corte térmico, não dois** — o `RT101` da placa é o do comparador; a via 4 do `J102` (`TH_MON`) fica sem montar. Em paralelo dão 5 kΩ e o comparador corta a carga solar com cada NTC a 25,7 °C ([01](01-esquematico.md#folha-1--energia)).
- [ ] **Pinagem e faixas do TLV7031 na ficha SNOSD54** — o `U105` está em `cad/parts.py` como **não confirmado**: conferir pino a pino, e a faixa de modo comum das entradas, antes de fabricar ([07](07-sequencias-e-protecao.md#o-corte-térmico-da-carga-solar)).
- [ ] **Indutor do ADP5091** — o `L103` está em 22 µH, Isat ≥ 390 mA, **sem peça escolhida na LCSC** (`cad/parts.py`); o AEM10900 e o seu 4,7 µH saíram em 2026-09-25 ([02](02-calculos.md#colheita-solar)).
- [ ] **Os seis pinos do ADP5091 sem nó** — `REF` ganhou nó em 2026-09-26 (os divisores do `TERM` e do `SETSD` penduram nele, figura 42 da ficha, e não no `BAT` como estava); ficam abertos `SETPG`, `SETHYST`, `PGOOD` e `LLD` (saídas e ajustes do `PGOOD`, que ninguém lê) e `BACK_UP` (sem célula primária; `SETBK` ao `AGND` como a ficha manda). Conferir na Rev. A se `SETPG`/`SETHYST` abertos são aceitos ([03](03-netlist.md#pinos-de-configuração-amarrados-em-cobre)).
- [ ] **O filme Azumo na LS027B7DH01A** — só no plano B: ele foi feito para a LS027B7DH01 sem o A ([19](../docs/19-lista-de-compras.md#display)).

### O que precisa de bancada

- [ ] **Painel com um módulo tapado** — confirmar que o arranjo em paralelo sem diodo perde pouco ([02](02-calculos.md#série-ou-paralelo)).
- [ ] **Calor do carregador na caixa vedada** — 1,50 W no pior caso põem a junção perto de 73 °C e a caixa inteira de 8 a 16 °C acima do ambiente; o corte por temperatura da célula pode disparar antes do fim da carga, e ao sol isso fica pior ([02](02-calculos.md#calor-do-carregador), [calor da caixa](02-calculos.md#calor-da-caixa-inteira)).
- [ ] **Isolação entre a antena do GNSS e a do rádio** — o S21, não só a geometria ([04](04-pcb-e-caixa.md#as-duas-antenas)).
- [ ] **Tensão direta do filme de luz** — só no plano B: sem ela o `R_BL` da montagem com a Sharp não fecha. Com o JDI o `R_BL` é 39 Ω, fechado pela ficha ([02](02-calculos.md#luz-do-display)).

### O que falta definir

- [ ] **Pilha de camadas do fabricante** — sem ela não há largura de trilha, nem 50 Ω da antena, nem 90 Ω do USB ([02](02-calculos.md#corrente-por-trilho-e-largura-de-trilha)).
- [ ] **Atribuição das quatro vias do conector do filme de luz** — só no plano B: o número de vias é 4, mas **qual contato leva o quê não está em arquivo nenhum do projeto**; sai do desenho 12369-01_T4 da Azumo ([06](06-conectores-e-pontos-de-teste.md#no-plano-b-o-filme-e-o-conector-de-4-vias)).
- [ ] **Pinagem do conector da bateria, com o fabricante do pack** — o cobre segue a proposta de [06](06-conectores-e-pontos-de-teste.md#j102--bateria) desde 2026-09-26 (1 e 6 `VBAT+`, 2 e 5 `GND`, 3 `NTC_BAT`, 4 reservada); até então tinha 1, 4 e 6 com os outros soltos, e um cabo feito como o documento pedia punha o positivo no `GND`. Falta o fabricante do pack confirmar.
- [ ] **Ordem das quatro vias do chicote do painel** — a tabela de [J103](06-conectores-e-pontos-de-teste.md#j103--painel-solar) segue a ordem dos pinos do footprint; confirmar o contato 1 na marca da carcaça `ZHR-4` antes de crimpar.

## Verificação

```sh
python tools/docs/mermaid_check.py     # diagramas
python tools/docs/links_check.py       # links e âncoras
python tools/fw/board_check.py         # o mapa de pinos do firmware
python hardware_gnssbike/net_check.py  # a lista de nós contra o devicetree
python tools/docs/solar_harness_drawing.py  # o desenho do chicote solar
python tools/docs/assembly_manual.py        # o manual de montagem
```

O `net_check.py` é deste esquemático: lê a [lista de nós](03-netlist.md) e
o devicetree da placa e confere **cinco coisas, todas no nível do pino do
MCU** — pino do firmware ausente do esquemático, pino do esquemático que o
firmware não usa, pino em dois nós, pino além do tamanho da porta e nome
de nó repetido.

> [!IMPORTANT]
> **Ele não confere o circuito.** Não vê dois acionadores no mesmo nó, não
> vê entrada flutuando, e não enxerga nada fora das tabelas com coluna
> "Pino do MCU" — de modo que `STO_CFG[1]`, `OE`, `CSB` e `EXTMODE` estão
> fora do alcance dele. Ele imprimiu "esquemático e devicetree batem" com
> três erros elétricos graves dentro, que só a revisão de 2026-09-22
> achou. Passar no `net_check.py` quer dizer que os pinos do MCU batem com
> o firmware, e nada mais.

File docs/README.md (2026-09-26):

# Documentação do GNSS Bike Computer

Índice da documentação técnica. Comece pela visão geral; para trabalhar no firmware, leia o ambiente de build e o status do port.

| # | Documento | Assunto |
|---|---|---|
| 01 | [Visão geral](01-visao-geral.md) | o produto, as funcionalidades, os modos, o legacy e o port |
| 02 | [Hardware](02-hardware.md) | placa myStravaB V3, componentes, pinagem das três revisões, overlay, alimentação, alvo híbrido no DK |
| 03 | [Ambiente e build](03-ambiente-build.md) | NCS v3.3.0, scripts, build, gravação, console, problemas conhecidos |
| 04 | [Arquitetura do legacy](04-arquitetura-legacy.md) | firmware original stravaV10: tasks, modos, módulos, glossário dos nomes em francês |
| 05 | [Arquitetura do port Zephyr](05-arquitetura-zephyr.md) | threads, módulos, fluxo de dados, HAL, devicetree, Kconfig |
| 06 | [Algoritmos](06-algoritmos.md) | Kalman de altitude, drift do barômetro, potência estimada, segmentos, posição relativa, zonas, suffer score, RMSSD |
| 07 | [Rádio: ANT+ e BLE](07-radio-ant-ble.md) | perfis ANT+ do legacy, serviços BLE, stravaAP, Komoot, LNS, estratégia do port |
| 08 | [Interface](08-interface.md) | display, telas, menus, botões, notificações |
| 09 | [Armazenamento e USB](09-armazenamento-usb.md) | arquivos no SD e na flash NOR, formatos, USB CDC e MSC |
| 10 | [Status do port](10-status-do-port.md) | matriz legacy × port, defeitos conhecidos, roteiro |
| 11 | [Qualidade e MISRA](11-qualidade-misra.md) | revisão MISRA do legacy, regras do port, cppcheck |
| 12 | [Ferramentas e testes](12-ferramentas-testes.md) | simulador TDD do legacy, zpm, testes de host do port, renderizador de telas, bibliotecas e licenças |
| 13 | [Placa nova](13-placa-nova.md) | proposta de hardware da placa própria: nRF54LM20A, display colorido, GNSS e antena interna, energia com painel solar, sensores, orçamentos de pinos e de energia |
| 14 | [Hardware da placa nova](14-hardware-placa-nova.md) | especificação técnica: decisões, arquitetura, árvore de alimentação, lista de materiais, barramentos, pinos, PCB, empilhamento, regras de layout, bring-up |
| 15 | [Avaliação dos componentes](15-avaliacao-componentes.md) | escolha de cada componente da placa nova: carga por USB-C e painel solar, GNSS, MCU, display, antena, sensores, armazenamento, USB, bateria; testes de bancada antes do layout |
| 16 | [Arquitetura do firmware](16-arquitetura-firmware.md) | arquitetura-alvo para a placa nova: serviços, threads, eventos no zbus, máquinas de estado no SMF (sistema e energia, modo, gravação, GNSS, sensores, carga, interface, luz), partida e desligamento, energia por estado, atualização de firmware, migração do port |
| 17 | [Dispositivos BLE e ANT+](17-dispositivos-ble-ant.md) | catálogo dos dispositivos externos (FC, velocidade e cadência, potência, rolo, radar, luzes, câmbio, e-bike, celular), perfis ANT+ e serviços BLE, o que o SDK já tem, prioridades, limites de canais e conexões, pareamento |
| 18 | [Interface e telas](18-interface-telas.md) | interface da placa nova: LVGL sobre driver próprio, implementação em `src/ui`, teste no PC, paleta de 8 cores e tema preto e branco, grade e barra de estado, fontes, todas as telas, botões, atualização e luz, memória, diferenças para o legacy |
| 19 | [Lista de compras](19-lista-de-compras.md) | lista de materiais do protótipo da placa nova, validada em duas passagens (compra e integração): trocas, correções do circuito, códigos, estoque e preço da DigiKey, passivos, placas de avaliação, custo e compras fora da DigiKey |

Os 44 quadros da interface, um a um, com o que cada uma mostra, estão em [`telas/`](telas/README.md). Imagens da interface e fotos do aparelho ficam em [`img/`](img/); as vistas da placa e da caixa, geradas do CAD, em [`img/hardware/`](img/hardware/). Os documentos de novembro de 2025, substituídos por estes, estão em [`historico/`](historico/).

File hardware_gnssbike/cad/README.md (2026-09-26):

# Projeto KiCad da placa

Este diretório é o projeto de CAD do GNSS Bike Computer: **esquemático
hierárquico em sete folhas** e **placa com as 156 peças posicionadas e
roteadas**, em KiCad 8, gerados a partir dos documentos de
[`hardware_gnssbike/`](../README.md) e conferidos contra eles por programa.

> [!WARNING]
> **Nada aqui foi fabricado, montado ou medido.** Não existe placa, não existe
> protótipo e nenhum número desta página saiu de bancada. O roteamento é
> automático e **não está completo**: as ligações de RF ficam de fora de
> propósito e parte das ligações continua sem trilha.

## O que abrir

| Arquivo | O que é |
|---|---|
| `gnssbike.kicad_pro` | o projeto; **abra este** no KiCad |
| `gnssbike.kicad_sch` | folha raiz: o diagrama de blocos |
| `folha1-energia.kicad_sch` … `folha6-interface.kicad_sch` | as seis folhas |
| `gnssbike.kicad_pcb` | a placa |
| `gnssbike.kicad_dru` | as duas regras locais de folga |
| `zonas.dxf`, `contorno-r3.dxf`, `contorno-r4.dxf` | as zonas e o contorno da placa em DXF, gerados pelo `make_dxf.py` (entradas da placa, não saídas) |

O que se **lê** sai daqui para as pastas do assunto (reorganização de 2026-09-26): o esquemático em PDF para [`../esquematico/`](../esquematico/), a placa em PDF e SVG e o desenho de montagem para [`../placa/`](../placa/), a proposta de caixa (PDF, STL e os dois scripts dela) para [`../caixa/`](../caixa/README.md), e as vistas 3D da placa e da caixa para [`../../docs/img/hardware/`](../../docs/img/hardware/). A tabela de [`../README.md`](../README.md#o-cad-e-o-que-sai-dele) lista cada arquivo. O `gnssbike.glb` que o `kicad-cli` exporta fica aqui e fora do git (45 MB, regenerado quando a placa muda).

## O esquemático

```mermaid
flowchart TB
    RAIZ["folha raiz · A3<br/>diagrama de blocos<br/>as linhas entre as folhas"]
    RAIZ --> F1["1 Energia · A3<br/>79 posicoes em 6 blocos"]
    RAIZ --> F2["2 MCU e depuracao · A4<br/>14 posicoes em 2 blocos"]
    RAIZ --> F3["3 GNSS · A4<br/>13 posicoes em 2 blocos"]
    RAIZ --> F4["4 Display e luz · A4<br/>15 posicoes em 2 blocos"]
    RAIZ --> F5["5 Memoria e sensores · A4<br/>18 posicoes em 5 blocos"]
    RAIZ --> F6["6 Interface · A4<br/>23 posicoes em 3 blocos"]
```

### Desenhado por bloco funcional, desde 2026-09-26

Até esse dia cada folha era a lista de nós desenhada em fios: as peças numa
grade por ordem de ligação e o roteador de labirinto puxando um fio de cada
pino até o outro extremo, fosse ele do outro lado da página. O dono pediu o
padrão industrial — ligações e rótulos, A4 ou A3, peças certas, fácil de
ler, os circuitos subdivididos em caixas tracejadas —, e o `blocos.py` é
isso:

| Regra | Como | De onde vem |
|---|---|---|
| Cada folha é uma fila de **blocos funcionais**, na ordem em que o sinal flui, cada um numa **caixa tracejada com título** | a tabela `BLOCOS` de `blocos.py` diz as âncoras de cada bloco (o CI ou o conector); os passivos seguem `make_pcb.DECOPLA` e `JUNTO` (as tabelas que já dizem de quem é cada capacitor na placa), depois `sheets.SEGUE`, depois a lista de nós sem os trilhos (o vizinho mais próximo por saltos) | SparkFun, "How to read a schematic": "truly expansive schematics should be split into functional blocks", "following the flow of circuit from input to output" |
| Dentro do bloco, o passivo fica **ao lado do pino que serve**, do lado para onde o pino aponta; o desacoplamento vai numa **prateleira** sob o CI | `_colocar_bloco()`: a âncora no meio, cada membro a dois passos da ponta do pino que compartilha com ela, empurrado para fora até caber sem sobrepor nem encostar ponta de outra rede; o que só toca trilho vai para a prateleira, que quebra linha na largura da âncora | prática corrente; a razão é o roteador: um fio curto sempre passa |
| Um passivo de dois terminais é **espelhado** quando o pino que serve ao CI é o de trás, e **posto em pé** (90° ou 270°) na prateleira e quando é pull-up ou pull-down de uma linha rotulada | `Part.espelho` e `Part.rotacao`. A **biblioteca** guarda sempre o desenho base (`pin_base()`); a instância leva o giro e o espelho, e `pin_local()` diz onde as pontas ficam depois deles. **Medido** no KiCad 8 em 2026-09-26, com treze resistores de biblioteca base e um rótulo colado em cada ponta (`kicad-cli sch export netlist`): `(mirror y)` troca esquerda por direita, `(mirror x)` troca cima por baixo; `(at x y 90)` manda o pino da esquerda para **baixo**, `270` para cima; a rotação vem antes do espelho. E, pelo `sch export pdf`: a justificação do campo de texto também é transformada (sob `(mirror y)` "left" imprime como "right"; a 90° trocam os dois eixos; a 270° nada), e `instance()` escreve a justificação que **renderiza** como a pedida | a primeira "medição" saiu invertida porque foi feita através do gerador, que escrevia a biblioteca já espelhada e ainda punha o `(mirror ...)` na instância: transformação duas vezes. Foi assim que todos os capacitores em pé saíram com as duas pontas no ar em 2026-09-26 |
| Alimentação e terra por **símbolo**, apontando **para longe do pino**: deitado ao longo da linha num pino lateral (seta ou barras para fora, o nome na linha, depois delas), em pé num pino de cima ou de baixo; pinos vizinhos do mesmo trilho no mesmo lado, ou os topos de uma fileira de capacitores em pé, ganham **um fio pela ponta deles e um símbolo só** | `PowerPort.sentido` (U, D, L, R); o nome fica a 3,3 mm do ponto, entre duas linhas de pino. Em pé num pino lateral, o símbolo punha a seta na linha de cima e o nome na seguinte. O fio da corrida é um por par de vizinhos: "wires connect with other wires or pins only if their ends coincide exactly" — um pino no meio de um fio comprido **não** está nele; e cada célula do fio é marcada no roteador (só as pontas e o meio deixavam um rótulo de outra rede pousar no meio dele) | manual do Eeschema 8; prática corrente nos esquemáticos densos |
| A **prateleira** é uma fileira de capacitores em pé, agrupados por trilho, com passo de 12,7 mm; o trilho corre pelos topos e o terra pelos pés, um símbolo por fileira; os pontos de teste ficam em pé com o pad pendurado da linha | `_colocar_bloco()` (prateleira), `PASSO_PRATELEIRA`, `ENTRE_LINHAS_PRATELEIRA`, `LARGURA_PRATELEIRA`; a referência e o valor à direita da peça, escritos a 90° (o KiCad soma o giro da instância ao ângulo do campo) | é como toda folha de desacoplamento é desenhada |
| Pull-up ou pull-down de uma linha que **sai do bloco** fica **em pé, depois do rótulo**; quando a linha segue para outra âncora (os contatos do FPC ao painel), fica **fora do corredor** das linhas, acima (trilho) ou abaixo (terra), e o roteador desce um fio até a linha cruzando as outras em ângulo reto | `_colocar_bloco()`: `em_pe`, distância pelo comprimento do maior rótulo vizinho (`GAP_ROTULO` no mínimo). Deitado na linha, ficava debaixo do texto do rótulo; em pé sobre a linha, era um muro para as linhas ao lado | é como uma fileira de pull-ups é desenhada |
| Os **rótulos têm o lugar reservado antes** das peças: cada pino de âncora cuja rede sai do bloco ganha um retângulo (toco de dois passos, texto, pentágono) que nenhum corpo nem texto de membro toma; e o que cada peça ocupa é testado como retângulos **separados** (corpo com pinos, cada texto), nunca uma caixa envolvente só | `retangulos` em `_colocar_bloco()`; `Part.caixas_de_texto()`. Uma caixa só em volta do conector FPC e do seu valor de 26 mm murava todas as linhas à direita dele | — |
| Sinal que sai do bloco vira **rótulo local**; sinal que sai da folha vira **rótulo hierárquico**, os dois num toco curto saído do pino; o texto do rótulo não pousa sobre peça, valor nem nome de símbolo | `_rotulo()`: toco reto de 2 a 12 passos se o caminho está livre **e** o texto cabe, senão o labirinto leva o toco à célula livre mais próxima onde o texto caiba (e, em último caso, a qualquer célula livre, para o pino nunca ficar aberto). As duas células em frente de todo pino são da rede dele (`dono_da_celula`): nenhuma outra rede passa ali. Num conector **de passagem** (`nets.PASSA_DIRETO`: o pino está em duas redes que são um nó só) o fio do painel continua do ponto do rótulo, e as duas redes podem partilhar células no roteador (`Router.irmas`) | manual do Eeschema 8: "local labels connect items located in the same sheet"; SparkFun: "give a net a name and label it, rather than routing a wire all over the schematic" |
| Um conector de biblioteca do KiCad com os pinos todos de um lado é **espelhado** para encarar a âncora com quem fala, e **alinhado** com ela pela mediana das linhas dos pares de pinos ligados, para as linhas correrem retas | `_colocar_bloco()` (âncoras); `Part.espelho_token()` devolve `y` para símbolo do KiCad. Com os pinos virados para fora, as dez linhas do FPC davam a volta por cima | — |
| Um pino de trilho sem lugar para o símbolo ganha o símbolo no fim de um toco roteado — **nunca um rótulo local com o nome do trilho** | **medido** na lista de nós do KiCad: um rótulo local `3V0` é a rede `/folha/3V0`, outra rede, e não se junta ao `3V0` dos símbolos de alimentação | medida de 2026-09-26 |
| Tudo na **grade de 50 mil** (1,27 mm) | `snap()` em toda coordenada | manual do Eeschema 8: "always use a 50 mil grid" |
| O tamanho da folha continua **medido**: a menor de A4, A3, A2 em que os blocos cabem | `escolher_papel()` coloca os blocos na candidata e aceita quando a última prateleira termina acima da margem | ver abaixo |

O `check_sch.py` é quem diz se deu certo: a lista de nós que o KiCad extrai
tem de bater com a de `nets.py` pino a pino, o ERC não pode acusar erro novo,
nenhum fio pode cruzar componente e nada pode sair da folha. Em 2026-09-26,
depois da passada de legibilidade que o dono pediu (símbolos de alimentação
deitados nos pinos laterais, nome e número do pino escondidos neles, texto
horizontal nas peças em pé, prateleira por trilho, pull-ups em pé depois
dos rótulos, lugar dos rótulos reservado, conector do FPC espelhado e
alinhado com o painel), ele passa com a folha 1 em **A3** e as outras em
A4; oito redes fecham por rótulo em vez de fio porque o labirinto não achou
caminho dentro do bloco (sete na folha 1, uma na 6: o gerador lista quais),
e dois símbolos ficaram onde couberam, com o nome encostado em alguma coisa
(`VBAT_SYS` no `SYS` do medidor, `3V0_GNSS` no ferrite). O que ainda não está
bom: o bloco da colheita solar (os seis módulos em série e paralelo, com
três laços de 0 R, e o lado esquerdo do ADP5091, com os divisores) e a
esquerda do medidor de bateria, que continuam apertados. `SCH_DEBUG=1
python make_sch.py` imprime por que cada símbolo ou rótulo não achou lugar
reto e onde um fio não achou caminho.

### O tamanho da folha é medido, não escolhido

**Cinco das sete folhas são A4 e as outras duas A3.** Antes eram A0, A2 e
cinco A3, e a causa era a mesma do contorno da placa: o desenho era espalhado
para encher o papel em vez de o papel ser escolhido para caber o desenho.

| O que fazia | O que faz agora |
|---|---|
| Orçava **54 × 48 mm por peça**, fosse um 0402 ou um módulo de 80 pads | **desenha** na folha candidata e pergunta se a última linha terminou acima da margem — é o mesmo código que desenha, então a resposta não pode divergir do desenho |
| Nunca considerava A4: a busca começava em A3 | começa em **A4** |
| Corredores de 24 e 30 mm entre peças, mais largos que os próprios símbolos | **16 e 22 mm**, e quem prova que ainda cabe fio é o `check_sch.py`, que falha se um fio cruzar componente |
| Raiz em **A0 fixo**, blocos de 190 × 240 mm num passo de 370 × 350 | blocos dimensionados pelo que contêm (o do MCU tem 33 sinais atravessando), **A3** medido |

Um pino de folha ganhava um espaço de 5,08 mm para um rótulo de 1,27. A dois
passos de grade — o padrão do KiCad — o bloco do MCU caiu de 116 para 73 mm de
altura, e foi isso que tirou o diagrama de A2.

### Bloco é só para circuito integrado

Um retângulo com nomes de pino nas laterais é como se desenha um **CI**, e só
um CI. Este gerador desenhava **tudo** assim — 127 peças, todas retângulos:
resistores, capacitores cerâmicos, diodos, o TVS. Uma folha de blocos ligados
por linhas não mostra circuito nenhum.

Cada classe passou a ter o símbolo dela, no padrão, com o eixo dos terminais
em x e o corpo entre −1,27 e +1,27 mm:

| Classe | Símbolo | Quantas |
|---|---|---|
| `R`, `JP` | ziguezague | 42 |
| `C` | duas placas paralelas (cerâmico); placa curva e `+` quando for eletrolítico | 31 |
| `L` | quatro arcos | 4 |
| `FB` | quatro arcos dentro do retângulo, que é o que distingue a ferrite do indutor | 1 |
| `RT` | ziguezague com a seta na diagonal | 1 |
| `D` | triângulo e barra; com setas para fora se for LED | 2 |
| `SW` | dois contatos, a barra e o êmbolo | 3 |
| `LS` | círculo com a diagonal | 1 |
| `TP` | círculo na ponta do terminal | 14 |
| `U`, `J`, `DS` | **retângulo**, que é o certo para eles | 36 |

Peça de dois terminais não mostra **número nem nome de pino**: "1" e "2" num
resistor é ruído, e o símbolo já diz onde é o quê onde importa — a barra do
catodo, a placa curva.

Três tipos de nó, cada um desenhado do jeito que se faz:

| Tipo | Como aparece | Quantos |
|---|---|---|
| **Trilho** (alimentação e terra) | símbolo de alimentação junto do pino que ele alimenta; o KiCad junta todos os de mesmo nome | 18 |
| **Entre folhas** | rótulo hierárquico na margem, pino no bloco da raiz, e a linha entre os blocos | 36 |
| **Dentro da folha** | só fio | 57 |

Dentro de cada folha as peças são colocadas na ordem em que se ligam, não por
tamanho: o capacitor de desacoplamento cai ao lado do CI que ele desacopla.

## A placa

| Item | Valor |
|---|---|
| Contorno | **34 × 95 mm**, canto de 3 mm, 0,8 mm de espessura — **derivado das regras**, não escrito à mão; os 5 mm além dos 90 de 2026-09-24 são das três teclas no passo de 13,4 (a área da antena do módulo desce com ele; `GNSSBIKE_H` troca a altura) |
| Camadas | **4**: `F.Cu`, `In1.Cu` (terra), `In2.Cu` (alimentação), `B.Cu` |
| Por que esse tamanho | a 7.2 do ME54BS13 pede **50 mm entre dois módulos de rádio**, e esta placa tem dois. Varrendo cada milímetro que cumpre isso e ainda cabe a fila de teclas, 34 × 90 é o menor contorno com folga — **3.060 mm² contra os 5.335 do 55 × 97, 43 % menos** |
| Relação com a caixa | **nenhuma.** A placa sai do circuito; a caixa sai do display, da bateria e da mão. Encolher uma não encolhe a outra |
| Peças na placa | **156**, com rotação (2026-09-26); as de trás (`U502`, `RT101`, `LS601`, `J103`) estão em `make_pcb.ATRAS` |
| Fora da placa | 7 (o painel, a célula e os seis módulos solares moram na caixa; a antena GNSS passou a morar na placa) |
| Redes | **114** |
| Furos de fixação | **2**, M2, em (3,2; 7,0) e (14,4; 91,7) — decisão do dono em 2026-09-25 (dois furos), depois da conta de [02](../02-calculos.md#quantos-parafusos-a-placa-precisa); as posições são do dry run da caixa de 2026-09-26: nenhum sobre a célula, o segundo entre o USB-C (que andou 0,4 para a esquerda por ele) e o módulo, fora do lugar do sensor de luz e da faixa do verso que segura o `J103` |
| Planos de terra | **3**, em `In1.Cu` e nas duas faces, preenchidos pelo `fill_zones.py` (com o Python do KiCad) |
| Roteamento | **196 ligações**, 1.417 segmentos, 549 vias (2026-09-26, à tarde, na placa de 95 mm); o par USB à mão, num corredor reservado de `D102` a `J101`; `RF_IN`, `RF_ANT`, `RF_CHIP` e `RF_UFL` ficam de fora de propósito |
| Ligações sem trilha | **75**, em 33 redes, pelo roteador; **58 itens desconectados** em 37 redes pelo DRC completo (`--severity-all`) com as malhas preenchidas — a regra `RT1` do `dry_run_pcb.py` |
| Erros de DRC | **0** (20 avisos, todos de biblioteca de footprint); os 3 do par USB contra o ponto de teste `TP101`, que o furo M2 novo empurrou para o caminho do par, saíram com o corredor |

### O que decide a posição de cada peça

1. **A borda**, para quem tem de alcançá-la: o USB-C com a boca para fora, os
   dois cabos planos saindo pela esquerda, os contatos de mola nas laterais e
   o módulo de rádio deitado no canto de baixo à direita, com a antena sobre o
   recorte — que é o arranjo que a figura 1 da seção 7.5 da ficha dele chama
   de "Best". Nada disso é a caixa mandando no tamanho da placa: é o circuito
   dizendo de que lado cada coisa sai.
2. **A zona** de [`04-pcb-e-caixa.md`](../04-pcb-e-caixa.md), para quem tem
   uma. As zonas são **derivadas de `W` e `H`**, não retângulos fixos.
3. **A ligação**, para todo o resto: cada peça vai ao centro de gravidade das
   peças a que se liga.
4. **A rotação**: peça de dois terminais deita ao longo da linha entre as duas
   peças que ela junta, para a trilha sair reta.

### O que a regra dos 50 mm impôs ao arranjo

Com 34 mm de largura, três decisões deixaram de ser gosto:

| O que | Por quê |
|---|---|
| A fila de teclas **não** fica na borda de baixo | o módulo ocupa 17,0 mm dela e a fila pede 30,6; e os 5 mm que a 7.4 pede em volta da antena comem mais. A fila subiu para acima do módulo |
| O buzzer vai na **face de trás** | 10,5 × 9,5 mm não cabem na faixa de 9,25 mm que sobra na frente entre as teclas e o módulo. Empurrado, ele parava a 0,84 mm do TPS7A02 e tomava o anel que o desacoplamento dele precisa |
| O receptor GNSS fica a **180°** | a 0 o pino `RF_IN` saía do lado da borda, a 1,2 mm dela, e a rede π não tinha para onde ir — ficava a 10,5 mm de um pino que a 4.4 quer "as short as possible". Virado, o pino olha para dentro e a rede cabe em linha |

## Verificação

```sh
python hardware_gnssbike/cad/check_sch.py                 # regera e confere o esquematico
"D:/KiCAD/bin/kicad-cli.exe" sch export pdf --output hardware_gnssbike/esquematico/gnssbike-esquematico.pdf hardware_gnssbike/cad/gnssbike.kicad_sch
python hardware_gnssbike/cad/make_pcb.py                  # 1. coloca as pecas
python hardware_gnssbike/cad/route.py                     # 2. roteia o que consegue
"D:/KiCAD/bin/python.exe" hardware_gnssbike/cad/fill_zones.py   # 3. preenche as malhas de terra
python hardware_gnssbike/cad/check_pcb.py --como-esta      # 4. confere o arquivo como esta
python hardware_gnssbike/cad/dry_run_pcb.py               # 5. as regras das fichas
```

A ordem importa por dois motivos. Sem `--como-esta`, o passo 4 **regera a
placa** e apaga as trilhas. E **sem o passo 3 o DRC mente**: os geradores
escrevem a zona de terra como contorno e mais nada, que é arquivo legal — o
KiCad preenche ao abrir —, mas o `kicad-cli pcb drc` **não preenche**. Numa
placa sem preenchimento todo pad que só chega ao plano aparece como
desligado e toda via de costura como solta, e nenhuma folga é medida contra
o cobre despejado, que é justamente a mais importante numa placa coberta de
terra. O `fill_zones.py` chama o preenchedor do próprio KiCad, pelo `pcbnew`,
e por isso roda com o Python do KiCad. O que isso mudou nos números, medido:
**296 ligações sem trilha caíram para 100**, e apareceram **11 erros reais**
de haste térmica insuficiente que a placa vazia escondia.

Depois, as vistas:

```sh
python hardware_gnssbike/cad/make_dxf.py     # contorno e zonas em DXF
"D:/KiCAD/bin/kicad-cli.exe" pcb export glb --output hardware_gnssbike/cad/gnssbike.glb     --include-tracks --include-zones --subst-models hardware_gnssbike/cad/gnssbike.kicad_pcb
python hardware_gnssbike/cad/make_3d.py      # as quatro vistas 3D em PNG, em docs/img/hardware/
python hardware_gnssbike/caixa/dry_run_caixa.py   # a caixa medida contra a placa: 13 regras (falha = codigo 1)
python hardware_gnssbike/caixa/make_caixa.py   # a caixa: PDF e STL em caixa/, tres vistas em docs/img/hardware/
"D:/KiCAD/bin/kicad-cli.exe" pcb export svg --output hardware_gnssbike/placa/gnssbike-2d.svg     --layers "F.Cu,In1.Cu,In2.Cu,B.Cu,F.SilkS,Edge.Cuts,F.Fab"     --page-size-mode 2 --exclude-drawing-sheet hardware_gnssbike/cad/gnssbike.kicad_pcb
python hardware_gnssbike/cad/make_2d.py      # o PDF em placa/, uma pagina por camada
```

O `make_2d.py` existe por causa do preenchimento. As quatro camadas numa
folha só eram legíveis enquanto as malhas estavam vazias; cheias, o despejo é
área sólida e **cobre as trilhas de baixo**, e a folha passa a mostrar o
contorno do cobre e quase nada mais. Quem lê uma placa lê **uma camada de
cada vez**, e é o que ele gera: quatro páginas com uma camada cada sobre o
contorno e a serigrafia, mais a quinta de conjunto.

### Por que o 3D não sai do KiCad sozinho

O `kicad-cli pcb export glb` só lê modelos **STEP**. Os corpos desenhados
aqui são VRML, então eles não entram no GLB — e o `make_3d.py` desenha esses
por conta própria, lendo o `.wrl` de cada um: a forma e a **cor** que o
arquivo traz, não uma caixa. A diferença não é estética. Enquanto ele
desenhava um paralelepípedo preto de contorno de footprint para os 23 corpos
próprios, o módulo de rádio, o receptor GNSS, as três teclas, o buzzer e o
receptáculo USB-C eram **tijolos pretos iguais** numa vista que existe
justamente para conferir se a peça é a que se pensa.

**Esquemático** — os 7 arquivos abrem; o **próprio KiCad** percorre a
hierarquia e exporta o netlist; os **100 nós elétricos saem iguais** aos da
lista de nós, pino a pino; nenhum nó a mais; os 37 pinos sem ligação são
exatamente os que a lista deixa soltos; **nenhum fio passa por cima de
componente** em folha nenhuma; nada fora da folha; nenhuma peça sobre outra;
e todo rótulo hierárquico tem o pino de folha que responde por ele.

**Placa** — o KiCad abre e roda o **DRC, que fecha em zero erro**, com as
malhas preenchidas e 58 itens ainda sem trilha (2026-09-26); as **156 peças** estão lá,
uma vez cada; **todo pad leva a rede da lista de nós** e nenhuma ligação ficou
sem pad; nenhum contorno sobre outro; nada passa da borda; nada dentro das
áreas de antena; a placa cabe na caixa; os três planos de terra existem.

**Regras das fichas** ([09](../09-dry-run-da-pcb.md)) — **17 cumpridas, 0
violadas, 5 que só bancada ou fabricante decidem**. As duas que falhavam na
placa de 55 × 97 caíram sozinhas quando a placa passou a ser dimensionada
pelo circuito:

| Regra | Na placa de 55 × 97 | Na de 34 × 90 |
|---|---|---|
| `RF9`, os 25 mm do display | falhava: a sombra do display chegava a **11,3 mm** do módulo | **passa**: o display é mais largo que a placa e não fica mais sobre ela; o pior agora é o cabo plano `J402`, a 31,3 mm |
| `AL1`, desacoplamento | falhava: `C114` a 3,3 mm do `U104` contra 2 | **passa**: o buzzer saiu de cima do regulador e o anel dele ficou livre |

### As duas regras locais de folga

`gnssbike.kicad_dru` abre exceção em dois footprints, e só neles:

| Regra | Por quê |
|---|---|
| `J101`, furo a cobre ≥ **0,175 mm** | os furos da blindagem do receptáculo USB-C ficam a **0,1801 mm** dos próprios pads |
| `U104`, folga ≥ **0,115 mm** | o pad térmico do TPS7A02 em X2SON de 1 × 1 mm fica a **0,1196 mm** dos próprios pinos |

Os dois são land patterns de fabricante, não desenho nosso. O resto da placa
segue **0,127 mm** de folga e **0,2 mm** de furo a cobre, que é o que uma
fábrica de quatro camadas faz sem custo extra. **Nenhuma fábrica foi
consultada** — e a pilha de camadas, a largura de 50 Ω e a de 90 Ω
diferencial esperam a mesma resposta.

## Serigrafia e pontos de teste

**Os dezesseis pontos de teste de [06](../06-conectores-e-pontos-de-teste.md)
estão na placa**, menos dois que o próprio documento não pode ter: o `TP111`
mede `ST_STO`, que a ficha do AEM10900 não tem, e o `TP401` mede `5V0`, de um
regulador que não é montado com o painel JDI. A lista mora em `parts.TESTE` e
o `nets.py` **recusa** um ponto que aponte para um nó inexistente.

**As referências estão em serigrafia nas duas faces**, cada peça na sua, no
mínimo que a fábrica imprime — **0,8 mm de altura com traço de 0,15** — e
**nenhuma cai sobre outra**. Não é automático: com todas no mesmo deslocamento
de 1,8 mm acima da peça, **37 pares ficavam sobrepostos**. O `rotulos()` de
[`make_pcb.py`](make_pcb.py) procura, para cada rótulo, o lugar livre mais
perto do contorno da própria peça, com duas regras em ordem — nunca sobre
outro rótulo, de preferência fora do contorno de outra peça.

| Medida | Antes | Agora |
|---|---|---|
| Altura do texto | 0,7 mm, traço 0,1 | **0,8 mm, traço 0,15** (mínimo de fábrica) |
| Pares sobrepostos | **37** | **0**, medidos no export do KiCad |
| Referências visíveis | 128, uma delas `REF**` | **127** (o `REF**` do furo foi escondido) |

### O desenho de montagem não sai de camada nenhuma do KiCad

Nem a serigrafia nem o `F.Fab` dão um desenho de montagem legível desta placa,
e as duas razões são diferentes.

A **serigrafia** é serigrafia: obedece à fabricação, 0,6 mm de texto, e 127
designadores numa placa de 34 × 90 mm a 48 % de ocupação não cabem em volta
das peças sem cair um sobre o outro ou se afastar tanto da peça que deixam de
nomear alguma coisa.

O **`F.Fab`** carrega o que cada footprint da biblioteca resolveu pôr lá, no
tamanho que o autor daquele footprint escolheu, mais o valor — então imprime
`TP110` a 1,0 mm ao lado de `100 nF` a 0,5 e os dois por cima do contorno.

Desenho de montagem não é camada de cobre. É desenho, e pode fazer a única
coisa que a serigrafia não pode: pôr o rótulo onde se lê e traçar uma **linha
de chamada** até a peça. É o que o [`montagem.py`](montagem.py) faz — rótulo
dentro do contorno quando cabe, e fora com ponto e linha quando não cabe.
Das 127 peças, **92 usam chamada**.

### Por que a conferência é feita no export, e não aqui

O `make_pcb.py` tem um modelo de quanto espaço um rótulo ocupa, e ele estava
**30 % estreito**: 0,75 do tamanho do texto por caractere, contra os **1,06**
que o `textLength` do próprio KiCad mede. Com isso ele reportava **zero**
sobreposições enquanto a serigrafia exportada tinha **35 pares** um sobre o
outro. Havia um segundo erro por trás: o deslocamento era escolhido no
referencial da **placa**, e o KiCad gira uma propriedade de footprint pelo
ângulo do próprio footprint — um rótulo posto "acima" de uma peça girada 90°
saía ao lado dela.

Por isso o `check_pcb.py` **exporta as duas camadas de serigrafia em SVG** e
conta as sobreposições nos retângulos que o KiCad escreve, com o `textLength`
e o tamanho de fonte de cada texto. Modelo interno não confere modelo interno.

## Três footprints eram de outra peça

A conferência `ME3` compara o **corpo que a ficha de cada peça cota** com o
contorno do footprint desenhado para ela. Ao ganhar as cotas dos conectores,
ela pegou três casos em que o land pattern na placa é de uma peça **diferente
da que está na lista de compras** — e um land pattern errado não é detalhe:
a peça não solda.

| Peça da lista | Footprint que estava em uso | O que a ficha diz | Diferença |
|---|---|---|---|
| **Same Sky CPT-1117-83-SMT** (buzzer) | `Buzzer_CUI_CPT-9019S-SMT`, **redondo de 9 mm** | corpo **retangular de 11,0 × 9,0 × 1,7**, preso por duas abas de 2,0 × 0,2 mm, uma em cada ponta e em lados opostos, com furo de 0,8; padrão de solda de **duas ilhas de 2,5 × 2,5 a 10,5 mm** | **corrigido**: footprint desenhado aqui |
| **Molex 2036150003** (USB-C IPX8) | `USB_C_Receptacle_Palconn_UTC16-G` | corpo **9,99 × 8,58 × 4,21** | o footprint desenha **8,94 × 7,32**: falta **1,05 × 1,26 mm**. **Em aberto** |
| **Hirose FH28-10S-0.5SH(05)** (FPC do display) | `Hirose_FH12-10S-0.5SH`, outra série | corpo **9,90 × 5,70 × 2,55** | o footprint desenha **8,10** de largura: falta **1,80 mm**. **Em aberto** |

> [!CAUTION]
> **Os dois em aberto não foram consertados de propósito.** Reconstruir um
> land pattern de USB-C ou de conector FPC a partir de um desenho
> **renderizado** é exatamente o tipo de palpite que essa conferência existe
> para pegar, e errar o padrão de solda de um USB-C mata a placa. Nem a
> Molex 2036150003 nem a Hirose FH28 existem na biblioteca do KiCad 8. O que
> resolve é o arquivo de land pattern do fabricante, ou ler o desenho com
> confiança maior do que uma imagem dá. Enquanto isso, o `ME3` **falha**, e é
> para falhar.

A altura do USB-C também estava errada e foi corrigida: **4,21 mm** acima da
superfície de montagem, não os 3,26 que estavam escritos como "conferir".

## Footprints

| Origem | Quantos | O que significa |
|---|---|---|
| **EXATO** | 10 | o footprint da KiCad é desta peça |
| **ENCAPSULAMENTO** | 92 | mesmo encapsulamento, desenhado para outra peça. Cabe, e **ainda tem de ser conferido contra a ficha** |
| **GERADO** | 10 | não existe na KiCad; gerado aqui a partir das dimensões, com o land pattern **aproximado** |

O **módulo de rádio** é o `MinewSemi ME54BS13` (nRF54LM20A), 16,5 × 12,0 ×
2,4 mm, **80 pads**: 20 castelados nas laterais e uma matriz LGA de 60 no
miolo, 64 GPIO. O footprint foi gerado das cotas do desenho mecânico da ficha
V1.0.0, porque **a Minew não publica land pattern** — a ficha diz para pedir o
dela.

> [!CAUTION]
> **Os dois desenhos da Minew discordam do espelhamento.** O da ficha V1.0.0
> põe os pinos 1–10 (RF, SWD, USB) na lateral **esquerda**; o da V0.5.0 e o da
> página do produto põem na **direita**. Este projeto seguiu a V1.0.0, que é a
> mais nova e a única com números de pino. **Confira num módulo real antes de
> fabricar**: pelo desenho adotado, os três GND da primeira linha da matriz
> (D0, E0, F0) ficam do **mesmo lado do VCC (pino 19)**. Se estiverem do lado
> do SWD, o footprint está espelhado.

Oito peças **não estão na placa** porque moram na caixa: o painel `DS401`, a
antena `E301` e os seis módulos solares `PV101` a `PV106`. Os pads que os
recebem **passaram a existir**: `J302` para a antena e `J103` a `J105` para os
três grupos de módulos solares, dois pads de 2,0 × 2,0 mm a 3,0 mm de passo,
sem pasta de solda. **A mola em si ainda não foi escolhida** — a altura de
1,5 mm que o 3D desenha está declarada em `footprints.ALTURA` como não lida de
ficha nenhuma, e `parts.py` manda conferir antes de fabricar.

## De onde vem cada coisa

```mermaid
flowchart LR
    DOCS["hardware_gnssbike/<br/>01 esquematico · 03 netlist<br/>04 placa e caixa · 05 materiais"]
    DOCS --> PARTS["parts.py<br/>pecas e pinagem"]
    DOCS --> NETS["nets.py<br/>ligacoes"]
    DOCS --> DXF["make_dxf.py<br/>contorno e zonas"]
    PARTS --> SCH["make_sch.py + blocos.py + sheets.py"]
    NETS --> SCH
    PARTS --> PCB["make_pcb.py + make_pro.py"]
    NETS --> PCB
    DXF --> PCB
    FP["footprints.py + fp_load.py"] --> PCB
    SCH --> CS["check_sch.py"]
    PCB --> CP["check_pcb.py"]
    PCB --> D3["make_3d.py<br/>GLB do KiCad renderizado em numpy"]
```

Nenhum arquivo do KiCad é editado à mão: tudo sai dos geradores, e os
geradores leem os documentos. Editar no KiCad e regerar apaga a edição — o
lugar de mudar é o gerador.

## O que falta

- [ ] **Terminar o roteamento.** 127 ligações têm trilha e **101 não**; as duas
      de RF (`RF_IN`, `RF_ANT`) ficam de fora de propósito, porque impedância
      e caminho delas não são negociáveis e o roteador automático não sabe
      disso.
- [ ] **Os 25 mm entre o módulo de rádio e o display** (`RF9`): decidir entre
      blindagem, camada ou aceitar e medir na bancada.
- [ ] **O desenho cotado do Hirose FH28.** O PDF que está aqui é só a folha de
      especificação: sem vista, sem corte, sem cotas. Sem ele os 3,4 × 10 mm
      da área do FPC em [04](../04-pcb-e-caixa.md) continuam sem origem.
- [ ] Conferir cada footprint **ENCAPSULAMENTO** contra a ficha da peça; onze
      já estão conferidos, com a cota do desenho mecânico em
      `footprints.PACOTE` e a conferência automática em `ME3`.
- [ ] Desenhar os footprints exatos do Molex 2036150003 (USB-C IPX8), do
      Hirose FH28-10S-0.5SH(05) e do Molex 503480-0500, e pedir à Minew o land
      pattern oficial do ME54BS13.
- [ ] Escolher a **mola** dos contatos do painel solar e da antena. Os pads
      existem (`J103` a `J105`, `J302`); a peça não.
- [ ] A pilha de camadas do fabricante, e com ela as larguras de 50 Ω e 90 Ω.
- [ ] As pendências que os documentos já carregam: a ordem das cinco vias da
      luz, o lado do sensor do MAX17262, a orientação do divisor do
      `DIS_STO_CH`, o `I2C_ADDR` e o `ST_STO` do AEM10900 (que **não existem**
      na ficha) e a tecla central ligada em dois lugares.

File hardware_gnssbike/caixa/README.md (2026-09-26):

# A caixa

A proposta de caixa em volta da placa real, desenhada por programa e medida
por um dry run próprio. **Nada foi impresso.** As decisões, o que cada regra
mede e o que ficou para o dono estão em
[04 · Placa e caixa](../04-pcb-e-caixa.md#a-placa-de-hoje-dentro-da-caixa-do-conceito);
o que ela mudou na placa, em
[10 · Dry-run de 2026-09-26](../10-dry-run-2026-09-26.md#adendo-da-tarde-a-caixa-medida-e-o-que-ela-mudou-na-placa).

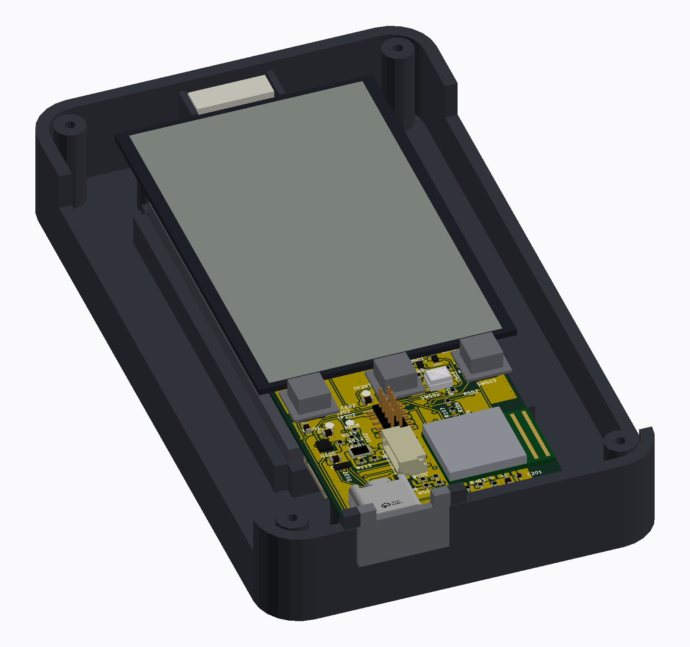
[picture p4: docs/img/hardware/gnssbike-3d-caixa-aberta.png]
A caixa aberta, com a placa, o display e a célula dentro


| Arquivo | O que é |
|---|---|
| [`make_caixa.py`](make_caixa.py) | desenha a caixa em volta de `cad/gnssbike.kicad_pcb` (o courtyard, a altura e a face de cada peça, e o GLB da placa): o PDF, as três vistas 3D e os STL |
| [`dry_run_caixa.py`](dry_run_caixa.py) | mede a mesma `Caixa` com 13 regras: folga sob a tampa e sobre a célula, o teto do display, capas sobre as chaves, janela e vidro, entalhe e porta do USB-C, bossas e pilares, bossas da tampa contra as antenas, janelas do LED e do sensor, furos do buzzer e do barômetro, bolsos, coberturas e fendas de fio dos módulos, o chanfro assentando na parede e a folga da face interna dele, o berço da antena externa; uma regra que não acha o que medir **falha** |
| [`gnssbike-caixa.pdf`](gnssbike-caixa.pdf) | três páginas: frente com a tampa e a porta, por dentro com o berço, cortes A-A e B-B, a tecla e o bolso de um módulo, as premissas, o que não bate e as peças |
| `caixa-concha.stl`, `caixa-tampa.stl` | a concha e a tampa (PETG ou ASA, 0,2 mm; a tampa de cabeça para baixo, com suporte sob os chanfros) |
| `caixa-tecla-1.stl`, `-2`, `-3` | as três capas das teclas, cada uma com a sua aba |
| `caixa-membrana-teclas.stl` | a membrana de TPU de 0,3 mm sobre as teclas |
| `caixa-cobertura-faceta.stl`, `caixa-cobertura-chanfro.stl` | as coberturas transparentes dos módulos solares (a do chanfro, quatro vezes) |
| `caixa-porta-usb.stl` | a porta do USB-C (o pino de ø1,5 à parte) |

Os STL são sopas de triângulos de caixas sobrepostas, que o fatiador une: servem
para a primeira prova impressa, não para usinar. As vistas 3D ficam em
[`docs/img/hardware/`](../../docs/img/hardware/) (`gnssbike-3d-caixa-aberta.png`,
`-frente.png`, `-explodida.png`).

## Como rodar

Depois da cadeia da placa ([`cad/README.md`](../cad/README.md#verificação)),
porque os dois leem a placa colocada e o `make_caixa.py` precisa do GLB que o
`dry_run_pcb.py` exporta:

```sh
python hardware_gnssbike/caixa/dry_run_caixa.py   # 13 regras; código 1 se alguma falhar
python hardware_gnssbike/caixa/make_caixa.py      # PDF e STL aqui, vistas em docs/img/hardware/
```

Resultado de 2026-09-26: **12 regras medidas e cumpridas, 0 violadas, 1 não
medida** (a passagem dos fios dos módulos, as juntas, o aperto das capas e os
parafusos auto-atarraxantes só uma prova impressa mede).

## O que a caixa é

| Item | Valor |
|---|---|
| Caixa | 62 × 106 × 17 mm, raio 7, paredes 2, fundo e tampa 1,5 |
| Placa | 34 × 95, centrada, a 0,5 mm da parede de baixo; duas bossas M2 e quatro pilares |
| Pilha | célula colada no fundo entre nervuras; 1,2 mm de peças do verso; placa em z 10,5 a 11,3; 3,0 mm sob o display; display colado sob a tampa em volta da janela |
| Teclas | três capas de 5 em furos de 5,6, exatamente sobre as chaves da placa (passo 13,4), sob membrana de TPU |
| Painéis | dois módulos de 23 × 8 na faceta abaixo das teclas e dois em cada chanfro de 45° e 7,5 mm, sob coberturas transparentes, com furos e fendas de fio |
| USB-C | entalhe na parede de baixo e na aba da tampa, com porta articulada por fora |
| Antena GNSS externa | berço com duas nervuras e lábio contra a parede de cima, para uma patch de 12 × 12 × 4 em pé (opção) |
| Tampa | quatro parafusos M2 nos cantos |

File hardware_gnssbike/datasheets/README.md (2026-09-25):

# Fichas técnicas

**Os arquivos deste diretório não vão para o repositório.** São documentos do
fabricante, e o repositório é público: aqui ficam só os endereços de onde
baixá-los e o que foi lido em cada um. O `.gitignore` ao lado cuida disso.

Baixe o que precisar e trabalhe localmente.

## MinewSemi ME54BS13 — o módulo de rádio

| Arquivo | O que é | Onde |
|---|---|---|
| `ME54BS13-nRF54LM20A_Datasheet_K_EN_v1.0.0.pdf` | **a ficha boa**: V1.0.0, 2026-06-23, 16 páginas, com números de pino, desenho mecânico cotado e as regras de PCB | <https://store.minewsemi.com/wp-content/uploads/2026/07/ME54BS13-nRF54LM20A_Datesheet_K_EN.pdf> |
| `ME54BS13-nRF54LM20A_Datasheet_K_EN_Brief.pdf` | versão anterior, V0.5.0 de 2026-03-06, 12 páginas. É a que a DigiKey serve | <https://en.minewsemi.com/file/ME54BS13-nRF54LM20A_Datasheet_K_EN_Brief.pdf> |
| `ME54BS13_3rdparty_girishji.kicad_mod` | footprint KiCad de terceiro, **não oficial**; a geometria bate com as cotas da ficha | <https://github.com/girishji/tmr-keyboard> |

Páginas: [produto](https://en.minewsemi.com/bluetooth-module/nrf54lm20a-me54bs13)
· [loja, US$ 6,00](https://store.minewsemi.com/product/bluetooth-modules-nrf54lm20a-me54bs13/).
Na página do produto o download pede login; pela URL direta do arquivo, não.

O que saiu dessas fichas e entrou no projeto está em
[`cad/parts.py`](../cad/parts.py) (`PADS_ME54BS13`, os 80 pads) e em
[`cad/footprints.py`](../cad/footprints.py) (`me54bs13()`, as cotas do desenho
mecânico). **A Minew não publica land pattern** — a ficha manda pedir o dela.

## As outras peças

As pinagens do nPM1300, MAX17262, AEM10900, TPS7A02, ESD761, TPD4E05U06,
MAX-F10S, TXU0204, MX25R6435F, BMP585, BMI270, MMC5633NJL, OPT3001, do
receptáculo USB-C, do JST GH, do Hirose FH28, do LED da Kingbright, da tecla
Omron e do painel JDI estão transcritas em [`cad/parts.py`](../cad/parts.py),
cada uma com o documento e a revisão de onde veio, no comentário logo acima.

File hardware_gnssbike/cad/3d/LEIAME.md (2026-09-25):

# Corpos 3D das peças

Das 113 peças da placa, **85 usam o modelo STEP da própria biblioteca do
KiCad** e aparecem sem que ninguém faça nada. As **18** desta página o KiCad
não tem, e para elas este projeto **desenha uma caixa** com a medida do
encapsulamento. As outras 5 (o furo M2, os três pontos de teste e os pads do
Tag-Connect) não têm corpo, e isso está certo: um ponto de teste é um pad.

> [!NOTE]
> Os `.wrl` desta pasta são **gerados** por
> [`../footprints.py`](../footprints.py) a cada `make_pcb.py`. Não os edite:
> a próxima execução os reescreve.

## Como pôr um modelo de verdade

Baixe o STEP do fabricante (ou do SnapEDA, Ultra Librarian, Mouser, DigiKey)
e salve em **`3d/real/`** com o **nome do footprint**. O gerador prefere o que
estiver lá e nem escreve a caixa:

```text
cad/3d/real/SW_SPST_B3S-1000.step
cad/3d/real/USB_C_Receptacle_Palconn_UTC16-G.step
```

Aceita `.step`, `.stp` e `.wrl`, nessa ordem. **STEP é melhor**: é o único
formato que a exportação GLB e STEP do KiCad lê, então só ele aparece na
imagem gerada por `make_3d.py`. Um `.wrl` aparece apenas no visualizador 3D
do KiCad.

> [!WARNING]
> **`3d/real/` não vai para o repositório.** Este repositório é público e um
> modelo 3D de fabricante vem com os termos do fabricante — a mesma razão que
> mantém as fichas fora de [`../../datasheets/`](../../datasheets/). O
> `.gitignore` da pasta cuida disso. Os `.wrl` gerados também ficam de fora,
> como todo arquivo gerado neste repositório: quem os reconstrói é o
> `make_pcb.py`. O que é versionado é o **gerador**, em
> [`../footprints.py`](../footprints.py).

## As 18 peças, e o que procurar

Nome do footprint é o nome do arquivo a salvar em `3d/real/`.

| Footprint | Peça a procurar | Medida usada (mm) | Altura: de onde veio |
|---|---|---|---|
| `SW_SPST_B3S-1000` | Omron **B3S-1002P** | 6,00 × 6,60 × **5,00** | corpo de 3,5 mais o botão — **conferir na ficha da Omron** |
| `USB_C_Receptacle_Palconn_UTC16-G` | Molex **2036150003** | 8,94 × 7,32 × **3,26** | altura corrente de receptáculo USB-C — **conferir na ficha do Molex** |
| `Buzzer_CUI_CPT-9019S-SMT` | CUI **CPT-1117-83-SMT** | 9,00 × 9,00 × **3,00** | **conferir**: a lista de compras traz o CPT-1117, não o CPT-9019S |
| `TE_0-1734839-5_1x05-1MP_P0.5mm_Horizontal` | Molex **503480-0500** | 7,93 × 4,40 × **1,20** | **conferir**: a peça ainda não está escolhida ([06](../../06-conectores-e-pontos-de-teste.md)) |
| `SOIC-8_5.23x5.23mm_P1.27mm` | Macronix **MX25R6435F** | 5,23 × 5,23 × 2,00 | altura normal do SOIC-8 |
| `QFN-28-1EP_4x4mm_P0.4mm_EP2.3x2.3mm` | e-peas **AEM10900** | 4,00 × 4,00 × 0,90 | altura normal de um QFN |
| `Texas_X2SON-4_1x1mm_P0.65mm` | TI **TPS7A0218PDQN** | 1,00 × 1,00 × 0,40 | altura normal do X2SON |
| `SOT-523` | Diodes **DMG1012T-7** | 0,80 × 1,60 × 0,60 | altura normal do SOT-523 |
| `MinewSemi_ME54BS13_16.5x12mm` | MinewSemi **ME54BS13** | 12,00 × 16,50 × 2,40 | **ficha V1.0.0, desenho mecânico** |
| `u-blox_MAX-F10S_9.7x10.1mm` | u-blox **MAX-F10S** | 9,70 × 10,10 × 2,40 | medida do encapsulamento MAX |
| `MAX17262_WLP-9_1.4x1.4mm_P0.4mm` | Analog **MAX17262REWL** | 1,40 × 1,40 × 0,50 | ficha |
| `BMP585_LGA-8_3.25x3.25mm` | Bosch **BMP585** | 3,25 × 3,25 × 1,96 | ficha |
| `MMC5633_WLP-4_0.85x0.85mm` | MEMSIC **MMC5633NJL** | 0,85 × 0,85 × 0,40 | ficha |
| `OPT3001_USON-6_2x2mm_P0.65mm` | TI **OPT3001DNPR** | 2,00 × 2,00 × 0,65 | ficha |
| `TXU0204_WQFN-14_3x2.5mm_P0.5mm` | TI **TXU0204BQAR** | 3,00 × 2,50 × 0,80 | ficha |
| `TPD4E05U06_USON-10_1x2.5mm_P0.5mm` | TI **TPD4E05U06DQAR** | 1,00 × 2,50 × 0,55 | ficha |
| `ESD761_X1SON-2_1x0.6mm` | **ESD761DPYR** | 1,00 × 0,60 × 0,45 | ficha |
| `LED_RGB_APTF1616_1.6x1.6mm` | Kingbright **APTF1616SEEZGKQBKC** | 1,60 × 1,60 × 0,70 | ficha |

### As duas que valem mais a pena

Os dois módulos são os únicos desenhados com mais de um bloco, porque neles a
forma diz alguma coisa:

- **ME54BS13** — substrato de 12,00 × 16,50 × 0,80 mm, blindagem metálica de
  1,60 mm sobre tudo **menos os 4,46 mm da ponta**, que é a antena e fica
  aberta. É o que o desenho mecânico da ficha V1.0.0 mostra, e é o que
  permite ver na imagem que a antena olha para a borda.
- **MAX-F10S** — substrato mais blindagem sobre a peça inteira, que é por que
  o manual de integração pode pedir terra por baixo dela ([§4.4](../../09-dry-run-da-pcb.md)).

**Nenhum dos dois fabricantes publica STEP.** A página do ME54BS13 na
MinewSemi e a loja deles listam só a ficha; a da u-blox não responde a
requisição automática. Por isso esses dois foram **desenhados a partir das
cotas**, não baixados.

## Prioridade, se for baixar

Só quatro alturas mudam alguma coisa, e são as das peças altas, que decidem se
a tampa fecha: a **tecla** (5,0 mm), o **USB-C** (3,26), o **buzzer** (3,0) e
o **conector da luz** (1,2). As outras catorze ficam abaixo de 2,4 mm, bem
dentro dos 2,6 mm que a sombra do display deixa
([04](../../04-pcb-e-caixa.md#as-duas-sombras-display-e-bateria)).

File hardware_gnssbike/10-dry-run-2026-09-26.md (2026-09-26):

# Dry-run de 2026-09-26: placa, esquemático, mecânica e contas

O terceiro dry-run do projeto, e o primeiro que olhou as quatro coisas de
uma vez: a placa roteada, o esquemático, a mecânica da caixa e as contas
que sustentam os dois. Foi feito em três análises independentes (placa e
roteamento; esquemático; cálculos e mecânica), cada uma com o arquivo na
mão e as fichas dos fabricantes, e depois a cadeia do CAD rodou de novo com
o que saiu delas. Este documento diz o que foi medido, o que foi corrigido
no mesmo dia, o que continua errado e o que só o dono decide.

**Nesta página:** [O que foi medido](#o-que-foi-medido-e-como) · [Placa e roteamento](#placa-e-roteamento) · [Esquemático](#esquemático) · [Mecânica](#mecânica-a-caixa-e-a-placa) · [Contas](#contas) · [O que mudou hoje](#o-que-mudou-hoje) · [O que fica](#o-que-fica) · [Verificação](#verificação)

> [!WARNING]
> **Nada foi fabricado, montado nem medido.** Todo número abaixo sai de um
> arquivo de CAD, de uma ficha ou de uma conta feita aqui, e diz de qual.
> Dois erros meus do próprio dia estão registrados onde aconteceram: a
> conta do consumo do receptor a 3,0 V (dei 21 mA e 63 mW; a ficha dá
> 19 mA e 57 mW) e o `podar_soltas` que apagou vias de costura legítimas
> antes de aprender a ver uma junção em T.

## O que foi medido, e como

```mermaid
flowchart LR
    SCH["check_sch.py<br/>esquemático regenerado,<br/>ERC do KiCad"] --> PCB["check_pcb.py<br/>placa regenerada:<br/>contorno, redes, DRC"]
    PCB --> ROUTE["route.py<br/>labirinto A*, par USB à mão"]
    ROUTE --> FILL["fill_zones.py<br/>malhas, com o Python do KiCad"]
    FILL --> DRY["dry_run_pcb.py<br/>27 regras das fichas e da IPC-2221"]
    DRY --> DOCS["04 · 09 · README · este relatório"]
    FW["fw.sh build<br/>placa própria"] --> DOCS
```

| Etapa | Resultado de 2026-09-26 |
|---|---|
| Esquemático | 6 folhas, 162 posições em `parts.py`, 124 nós, 114 elétricos; **o ERC do KiCad não acusa erro novo** (4 aceitos, um a um, com o motivo) |
| Placa gerada | 155 peças, 114 redes, 2 áreas de regra, 2 furos M2; **0 erros de DRC** antes do roteamento; nenhuma peça fora da borda, sobre outra ou em área de antena |
| Roteamento | 1.506 segmentos, 544 vias, **204 ligações fechadas, 59 sem trilha** em 26 redes; `RF_IN`, `RF_ANT`, `RF_CHIP` e `RF_UFL` de fora de propósito |
| Regras das fichas | **18 cumpridas, 5 violadas, 4 sem medida** ([09](09-dry-run-da-pcb.md#resultado-da-posição)) |
| DRC completo, malhas preenchidas | **44 itens desconectados em 30 redes**; **4 violações de isolamento** de 0,125 contra 0,127 mm (2 µm) entre `PWR_SCL` e `VBAT` junto do nPM1300; 20 avisos de biblioteca |
| Firmware da placa própria | build com **0 avisos de compilador**, FLASH 636.376 B, RAM 393.120 B, depois do devicetree acompanhar o receptor a 3,0 V |

A ordem e o intérprete importam, e errar qualquer um dos dois dá um resultado
que parece válido: o `check_pcb.py` regera a placa (nunca depois do
`route.py`), e o `fill_zones.py` só roda com `D:/KiCAD/bin/python.exe` —
com o Python do sistema ele avisa, sai, e o DRC conta centenas de pads de
terra "soltos" que não existem. Aconteceu duas vezes hoje antes de virar
armadilha registrada no `CLAUDE.md`.

## Placa e roteamento

O que a análise da placa achou, e o que foi feito com cada item:

| Achado | Gravidade | Situação |
|---|---|---|
| **Os documentos diziam "0 ligações sem trilha" com 47 e 55 em aberto.** O DRC rodava com `--severity-error`, que esconde os não roteados porque para o KiCad eles são aviso | grave (honestidade) | **corrigido**: a regra `RT1` roda o DRC com `--severity-all` e conta; `check_pcb.py` diz que não julga isso; 09 e os READMEs retificados |
| **O par USB nunca roteava.** Duas causas: a reserva de cada ilha arredondava para fora nos dois sentidos e fechava toda fileira de 0,5 mm de passo (`Grade._ret`); e nenhuma busca em labirinto tira um par de classe USB de duas fileiras de 0,5 mm em série | grave | **corrigido**: reserva pelo centro da célula; o trecho receptáculo → diodo → saída desenhado à mão (`ligar_usb()`), a 0,150 nos pescoços e 0,207 no resto; `US1` cumprida |
| A terceira tecla não cabia (a 3,56 mm da área da antena do módulo, que pede 5) | média | **corrigido**: passo 8,5 (4,5 · 13,0 · 21,5) |
| A reserva do furo M2 (1,7 mm) era menor que o courtyard do footprint (2,45): o Tag-Connect a 2,0 mm do furo, DRC de sobreposição | média | **corrigido**: reserva = courtyard + folga; o diodo do USB subiu 0,3 mm |
| `check_pcb.py` acusava o USB-C de passar da borda (centrava um courtyard que não é centrado) e cobrava um furo só | baixa | **corrigido** |
| O roteador e o verificador tomavam os números das redes do `nets.py` em vez do arquivo; uma rede acrescentada no meio de uma cadeia deslocou o `GND` em um | média | **corrigido**: `fp_load.redes_da_placa` |
| `AL2`: 3 segmentos do `VBAT_SYS` a 0,40 mm onde a IPC-2221 pede 0,57 | baixa | **em aberto**: largura por rede no `route.py` |
| `AL1`: `C117` a 6,7 mm do `U103` (limite 5) e `C114` a 2,3 do `U104` (limite 2) | baixa | **em aberto**: o colocador não achou lugar mais perto; à mão |
| 4 violações de isolamento de 2 µm entre `PWR_SCL` e `VBAT` | baixa | **em aberto**: um passo de grade à mão |
| 59 ligações sem trilha | — | **em aberto**: o roteador é A\* sem *rip-up*; o caminho é terminar no KiCad ou pelo FreeRouting ([09](09-dry-run-da-pcb.md#por-que-metade-e-o-que-fazer-com-a-outra-metade)) |
| A linha de 50 Ω calculada com Hammerstad (0,196 mm) ignora a espessura do cobre: com ela a linha fica em 44 a 46 Ω | média | **registrado** em 09; a largura final é do empilhamento do fabricante |

## Esquemático

| Achado | Gravidade | Situação |
|---|---|---|
| **Os divisores do `TERM` e do `SETSD` do ADP5091 pendiam do `BAT`, com o pino `REF` aberto.** A figura 42 da ficha (Rev. A, p. 19) pendura os quatro divisores externos no `REF`, que o CI liga ao `BAT` por chaves, com o resistor de histerese em série, e ao `TERM_REF` na comparação do fim de carga. Do jeito que estava, a equação 6 (fim de carga em 3,97 V) não valia e a histerese do `SETSD` não existia | **grave** | **corrigido**: nó `ADP_REF`; valores mantidos ([03](03-netlist.md#nós-sem-ligação-ao-mcu)) |
| **A pinagem do conector da célula em cobre não era a de [06](06-conectores-e-pontos-de-teste.md#j102--bateria)**: 1 `VBAT+`, 4 NTC e 6 `GND`, com 2, 3 e 5 soltos; um cabo feito como o documento manda punha o positivo no `GND` | **grave** | **corrigido**: 1 e 6 `VBAT+`, 2 e 5 `GND`, 3 `NTC_BAT`, 4 reservada |
| O divisor do NTC estava na placa **sem ninguém para lê-lo**: o ADP5091 não tem entrada de temperatura | grave | **corrigido** (decisão do dono): comparador TLV7031 alimentado pelo painel, saída em OU de diodos no `DIS_SW`. **Só o lado quente**: a carga abaixo de 0 °C ficou em aberto |
| A tecla central ligada ao `SHPHLD` (até 5,5 V) e ao P1.27 ao mesmo tempo | grave | **corrigido** (decisão do dono): Schottky `D107` isolando o pino |
| O receptor GNSS a 1,8 V pelo BUCK1, de ±5 %, onde a tabela 35 do manual pede ±2 % | média | **corrigido** (decisão do dono): receptor a **3,0 V** no trilho do MCU, sem tradutor; o LDO de ±1 % que existiu por umas horas custava 35 mW na bateria contra 11 da opção escolhida ([02](02-calculos.md#o-receptor-no-3v0-e-o-1v8-sem-carga)) |
| `REF`, `SETPG`, `SETHYST`, `LLD`, `BACK_UP` e `PGOOD` do ADP5091 sem nó e sem justificativa | média | `REF` **corrigido**; `SETBK` ao `AGND` como a tabela 5 manda; os outros quatro são saídas sem consumidor e ajustes do `PGOOD` — **conferir na ficha se `SETPG`/`SETHYST` abertos são aceitos** |
| `R111`, pull-up de um `IRQ` que o ADP5091 não tem, numa rede de um pino só | baixa | **corrigido**: saiu |
| `TXU0204` e o LDO de 1,8 V, com quatro capacitores | — | **saíram** com o receptor a 3,0 V |
| `FB301` com 230 mΩ onde o manual permite 0,2 Ω em série no `VCC`; `D105` de proteção do `SRC` | baixa | **corrigidos** (BLM18KG601SN1D de 150 mΩ; PESD3V3S1UB) |
| A pinagem do TLV7031 não confirmada na SNOSD54 (entrou hoje) | média | **em aberto**, marcado como não confirmado em `parts.py` |
| O `L103` de 22 µH do ADP5091 sem peça escolhida | média | **em aberto** |
| Os documentos 02, 04, 13, 14, 15 e 19 ainda dimensionam o **AEM10900**, que saiu do CAD em 2026-09-25 sem linha no CHANGELOG | média | 01, 03, 05, 06 e 07 **acertados hoje**; os outros seis **em aberto**, e o motivo da troca precisa ser registrado por quem a fez |
| O devicetree e o serviço de energia do firmware ainda falam AEM10900 e I²C `bias-pull-up` | média | **em aberto** ([10](../docs/10-status-do-port.md#defeitos-abertos)) |

## Mecânica: a caixa e a placa

Este é o achado que ninguém tinha visto, e o mais grave do dia:

> [!CAUTION]
> **A caixa desenhada (de manhã) era a da placa antiga, de 55 × 97 mm.** O
> desenho do conceito (`tools/docs/case_drawing.py`, retirado à tarde, quando
> a proposta medida de [`caixa/`](caixa/) o substituiu) e a seção "As duas sombras" de
> [04](04-pcb-e-caixa.md#as-duas-sombras-display-e-bateria) traziam
> retângulos de 47 mm de largura para uma placa de 34, e nenhum arquivo dizia
> onde o display e a célula caem sobre a placa de 34 × 90. A regra `ME2`
> passava **sem medir peça nenhuma**, e a análise mecânica apontou o que a
> regra deveria ter apontado: conector USB-C que não alcança a parede da
> caixa antiga, furo a 10 mm do lugar, peças de 4,29, 3,0 e 1,96 mm sob um
> teto de 1,2, e pilha de 19,9 mm numa caixa de 19 — **estes últimos números
> são da análise, não foram conferidos aqui**, porque a caixa certa ainda não
> existe.

O que foi feito: as duas sombras existem como **proposta** em
`cad/make_dxf.py` — o display de 61,8 mm acabando em y = 64,5 (acima das
teclas) e começando em 2,7; a célula de 60 mm de 9,9 a 69,9, logo abaixo da
antena GNSS —, a regra mede, e o que ela mede está em
[04](04-pcb-e-caixa.md#as-duas-sombras-display-e-bateria):

| Medida | Resultado |
|---|---|
| Peças mais altas que o teto da sombra | **5**: `J102` (4,25 mm), `LS601` (3,00) e `U502` (1,86) sob a célula, teto de 1,2; `J103` (3,75) e **`U301`, o próprio receptor (2,70)** sob o display, teto de 2,6 |
| O display sobre a antena GNSS | cobre **7,2 mm** da área da antena (y de 2,7 a 9,88); a ficha da Unictron não diz o que um vidro com ITO faz ao ganho |
| A célula entre as duas antenas | há **58,1 mm** entre a antena GNSS e a área da antena do módulo; a célula tem **60**: entra 1,9 mm no canto que a ficha do ME54BS13 reserva |
| `RF9` | a sombra do display fica a **6,8 mm** da área da antena do módulo; a ficha pede 25. Numa placa de 90 mm com um display de 61,8, a regra é impossível de cumprir |
| Área com teto dos dois lados | **61 %** da placa; só 25 % está livre das duas sombras |

O que segue disso é decisão do dono, e a ordem importa:

1. **A célula**: uma de até 58 mm (36 × 58 ou menor), ou aceitar o canto na
   área da antena do módulo e medir o S21 na bancada.
2. **O teto sob o display**: o receptor tem 2,70 mm e não tem para onde ir
   (fica junto da antena, que fica sob o display). O afastamento do display
   à placa tem de ser pelo menos 2,7 mm mais a folga — é número da caixa,
   não da placa.
3. **A face de trás abaixo da célula** (y de 70 a 90): é o único lugar para
   `J102`, o buzzer e o barômetro com o respiro, e o `J103` do painel
   também cabe lá. É uma nova passagem de colocação, e o roteamento inteiro
   muda com ela.
4. **`RF9`**: registrar que a regra do ME54BS13 não se cumpre com display
   nesta placa, e medir a dessensibilização na bancada.

## Os corpos 3D, peça a peça

O dono viu no 3D o conector do painel com as pernas para a borda e
desconfiou dos passivos e dos CIs. As duas coisas foram medidas em vez de
olhadas, e viraram regra:

| Medida | Resultado |
|---|---|
| `ME5`, os rabichos de solda dos cinco conectores de borda | `J101`, `J102`, `J401` e `J402` saem do corpo pelo lado das ilhas; **`J103` saía pelo lado oposto, 3,3 mm além do centro do corpo**: o giro de 180° que eu tinha posto no STEP do JST ZH em 2026-09-25 era o erro. Sem giro e com o deslocamento resolvido por medida (2,25; −2,00), o corpo cai exatamente no F.Fab |
| `ME6`, o eixo de todos os corpos contra o F.Fab | **132 peças medidas, 128 certas na primeira medida**; os quatro **SOT-523** saíam deitados (1,60 × 0,66 sobre um F.Fab de 0,80 × 1,60), porque a cota em `footprints.PACOTE` estava no eixo da ficha e não no do footprint. Corrigido; nenhum passivo e nenhum CI além desses estava fora do eixo |
| Corpos duplicados | o `make_3d.py` desenhava o `.wrl` da biblioteca por cima do `.step` que o GLB já traz: 105 passivos com dois corpos no mesmo lugar. Só quem não tem `.step` instalado é desenhado daqui agora |

O que a regra **não** mede: a marca de pino 1 de um encapsulamento quadrado
(nPM1300, ADP5091, os LGA) contra a ilha 1, e a faixa de catodo de um diodo
contra a ilha do catodo — os dois dependem de cor ou de um chanfro no
modelo, e um teste que "responde o que eu quero" já custou um dia. Ficam
para a inspeção visual do dono nas vistas 3D, que foram redesenhadas.

## Contas

| Conta | Resultado | Onde |
|---|---|---|
| Receptor a 3,0 V | 19 mA em rastreio (57 mW) e 24 na aquisição, 100 mA de pico na partida; o `3V0` vai a 47 mA em regime e 123 no pico (61,5 % do BUCK2); o `VSYS` a cerca de 74 mA; **+11 mW** na bateria contra o arranjo de 1,8 V, autonomia sem sol de cerca de 115 h para cerca de **97 h** | [02](02-calculos.md#o-receptor-no-3v0-e-o-1v8-sem-carga) |
| Rampa do `V_IO` na partida | agora pelo BUCK2: 167, 333 e 1.667 µs/V para partidas de 0,5, 1 e 5 ms, dentro de 25 a 35.000 | [02](02-calculos.md#rampa-do-v_io-na-partida) |
| Limiar do corte térmico | NTC 10 kΩ B3380 = 4,90 kΩ a 45 °C; com `R106` de 4,87 kΩ o divisor cruza a metade do `SRC` exatamente aí; com dois NTC em paralelo, corta a 25,7 °C | [01](01-esquematico.md#folha-1--energia) |
| `DIS_SW` com o cabo | 5,5 × 180 ÷ 280 = 3,5 V; acima do 1 V de nível alto, abaixo dos 6,0 V de máximo absoluto | [03](03-netlist.md#nós-sem-ligação-ao-mcu) |
| Fim de carga e corte de descarga do ADP5091 | 3/2 × 1,011 × (1 + 4,32/2,67) = **3,97 V**; 1,011 × (1 + 6,65/3,32) = **3,04 V** — válidas agora que os divisores pendem do `REF` | [03](03-netlist.md#nós-sem-ligação-ao-mcu) |
| Parafusos | a conta do dia 25 usava o braço de alavanca errado (40,8 mm em vez dos 3,7 do furo ao ponto de inserção): dois M2 dão 74 N·mm contra 40 pedidos, **1,85×**, não os "20×" que este projeto chegou a escrever | [02](02-calculos.md#quantos-parafusos-a-placa-precisa) |
| Largura de trilha | IPC-2221B com k = 0,048 externo e 0,024 interno; 0,8 A pedem 0,57 mm fora e o dobro dentro; 3 segmentos do `VBAT_SYS` a 0,40 | [09](09-dry-run-da-pcb.md) |
| Linha de 50 Ω | 0,196 mm por Hammerstad sem a espessura do cobre; 44 a 46 Ω com ela: só o empilhamento do fabricante fecha | [09](09-dry-run-da-pcb.md#por-que-rf_in-rf_ant-rf_chip-e-rf_ufl-não-são-roteadas) |
| εr | **conferido**: `ER_FR4 = 4.3` em `route.py` (marcado como assumido) e `epsilon_r 4.5` nas três camadas dielétricas do `.kicad_pcb`; os dois são palpite, e as larguras de 50 e 90 Ω saem do primeiro | **por acertar** num valor só, o do fabricante |

## O que mudou hoje

Em ordem de gravidade, tudo verificado na cadeia do CAD, no ERC e no build;
nada em placa:

1. o receptor GNSS a 3,0 V, no trilho do MCU, sem tradutor de nível nem LDO
   (CAD, devicetree, 01, 02, 03, 05, 07, 13, 14, 15, 16, 19);
2. os divisores do ADP5091 pendurados no `REF`;
3. o corte térmico da carga solar por comparador, alimentado pelo painel;
4. a tecla central isolada por Schottky;
5. a pinagem do `J102` igual à de 06;
6. as sombras do display e da célula como proposta, a regra `ME2` medindo,
   e os cinco conflitos que ela achou;
7. o par USB à mão e o roteador destravado nas fileiras de 0,5 mm;
8. a regra `RT1` e os "0 desconectados" retificados em 09 e nos READMEs;
9. as teclas a 8,5 mm de passo, a reserva dos furos igual ao courtyard, o
   `check_pcb.py` sem falsos positivos, o roteador e o verificador lendo as
   redes do arquivo;
10. `FB301`, `D105` e `R111`; os documentos 01, 03, 05, 06 e 07 acertados
    ao ADP5091.

## O que fica

**Do dono:**

- [ ] a célula de até 58 mm, ou aceitar o canto na antena do módulo;
- [ ] o teto sob o display (≥ 2,7 mm mais folga), e a caixa nova para a
      placa de 34 × 90;
- [ ] a carga solar abaixo de 0 °C: segundo comparador ou o risco;
- [ ] o motivo registrado da troca AEM10900 → ADP5091, e o `L103`.

**Do CAD:**

- [ ] nova colocação da face de trás abaixo da célula (`J102`, buzzer,
      barômetro, `J103`), e o roteamento de novo;
- [ ] as 59 ligações sem trilha, as 4 de isolamento e os 3 segmentos do
      `VBAT_SYS`;
- [x] **o esquemático no padrão industrial**, pedido do dono em 2026-09-26:
      **feito no mesmo dia** — blocos funcionais em caixas tracejadas com
      título, passivo ao lado do pino, rótulos em vez de fios compridos, A3 e
      A4 ([01](01-esquematico.md#como-as-folhas-são-desenhadas)). Fica por
      afinar a densidade em volta dos pinos do nPM1300 e do ADP5091, onde os
      nomes dos símbolos de alimentação se encostam;
- [ ] εr num valor só.

**Das fichas e da bancada:**

- [ ] pinagem e faixas do TLV7031 (SNOSD54); `SETPG`/`SETHYST` abertos no
      ADP5091;
- [ ] o display sobre a antena GNSS e a 6,8 mm da antena do módulo: medir;
- [ ] o empilhamento do fabricante, para as larguras de 50 e 90 Ω;
- [ ] tudo o que [09](09-dry-run-da-pcb.md#o-que-não-foi-medido) já
      listava.

**Do firmware** ([10](../docs/10-status-do-port.md#defeitos-abertos)):

- [ ] o standby do receptor não corta trilho nenhum: só `UBX-RXM-PMREQ`;
- [ ] o devicetree e o serviço de energia ainda falam AEM10900;
- [ ] os 46 µA do receptor em standby no orçamento.

## Adendo da tarde: a caixa medida, e o que ela mudou na placa

O dono pediu, ainda em 2026-09-26, as chaves da placa exatamente sob as capas
da caixa, um dry run da caixa inteira, a porta do USB-C, o berço de uma antena
GNSS externa e a fixação dos painéis laterais conferida. O
[`caixa/dry_run_caixa.py`](caixa/dry_run_caixa.py) mede a mesma `Caixa` que
desenha o PDF, as vistas e os STL, com 13 regras; na primeira rodada
**seis falharam**, e cada uma mudou alguma coisa:

| Regra | O que mediu | O que mudou |
|---|---|---|
| `CX1`, `CX3` | `J103` (3,75) a 0,05 mm da tampa e sob o display; `U301` (2,7) sob o display com teto de 2,6 | `J103` foi para o **verso**, em pé na borda esquerda; o teto sob o display subiu para **3,0** (a placa desceu 0,4 na caixa) |
| `CX4` | os furos das capas (5,6) entravam 1,3 mm no vidro do display, que acabava 1,5 mm acima das chaves | o display subiu 1,6 mm na placa (`make_dxf.DISPLAY_Y1` = 62,9); cobre 8,8 mm da área da antena GNSS em vez de 7,2 |
| `CX6` | o entalhe do USB-C começava 0,2 mm acima da base do receptáculo | começa 0,3 abaixo da face da placa |
| `CX10`, `CX11` | o chanfro de 6,2 tem 8,8 mm de rampa e o módulo ocupa 8,4: o degrau da cobertura passava das duas pontas; a placa da tampa atravessava a rampa 2,7 mm; o bolso atravessava a tampa de 1,5 | chanfro de **7,5** (rampa de 10,6, paredes de 1,1 nas pontas, 0,5 atrás do bolso), face rebaixada com tira de ponta a ponta, fendas de fio, placa da tampa começando dentro do sólido do chanfro, face interna a 1,0 do vidro |
| `CX12` | o berço da antena externa entrava 1,6 mm na placa | a caixa cresceu para **62 × 106** |
| `CX5` | 1,0 mm de vidro em volta da janela nos lados curtos | é o que o display dá; a regra pede 1,0 |

Depois disso: **12 regras medidas e cumpridas, 0 violadas, 1 não medida**
(fios dos módulos, juntas, aperto das capas, parafusos auto-atarraxantes).

Na placa, as mudanças do dia trouxeram três regras novas ao vermelho e todas
saíram: `OP1` contava o barômetro do verso e os 0402 como vizinhos do sensor
de luz (a regra passou a olhar só a mesma face e só peças mais altas que o
sensor); `ME6` chamava o `J202` de girado com as faces do buzzer, que está no
verso debaixo dele (a leitura dos corpos passou a separar as faces também para
os `.wrl`); `ME5` não achava rabichos no `J102` novo (o STEP do
kicad-packages3D está em `cad/3d/real/`); e o modelo do `J103` no verso
caía 2,14 mm fora do `F.Fab`, com os rabichos para o lado oposto ao das
ilhas, porque o `kicad-cli` espelha as ilhas do verso e não o modelo — e a
`ME4`, que só olhava z > 0,95, media o sensor de luz e o diodo da frente por
cima dele. Exportações do GLB com valores de prova, lidas de volta, deram
o giro de 180° e o deslocamento (−2,25; 1,86) de
`footprints.MODELO_GIRADO_VERSO`, conferidos pelas três regras; a `ME4`
passou a olhar a face da peça. O furo M2 de baixo, que
foi para (14,4; 91,7), empurrou o `TP101` para o caminho do par USB — curto,
isolamento de 0,071 e ponte de máscara no DRC —, e o par ganhou um corredor
reservado no colocador. O colocador, por sua vez, entrava em laço sem fim
quando uma peça não cabia (a mesma onda voltava a cada volta): hoje desiste
dela e diz qual.

Depois da publicação, o dono viu no 3D o **`J402`** (o FPC do filme de luz,
HCTL) com o STEP **180° fora**. Medido por cor no GLB: os cinco contatos
dourados saíam do corpo pela esquerda, sobre nada, com as ilhas de sinal à
direita; a `ME5` e a `ME6` tinham deixado passar porque a chapa das unhas de
fixação, do lado das ilhas no modelo errado, pesa mais que cinco rabichos de
0,3 mm. O modelo é girado pela `footprints.MODELO_GIRADO` (180°, sem
deslocamento, medido), e as duas regras passaram a medir pela cor dos
contatos quando o modelo a tem (`CONTATOS_POR_COR`): o modelo errado dá
−0,26 mm, lado oposto; o certo, +0,26.

| Medida | Antes (manhã) | Depois (tarde) |
|---|---|---|
| Placa | 34 × 90 | **34 × 95**, teclas em x 3,6, 17 e 30,4 (passo 13,4) |
| Regras do `dry_run_pcb.py` | 24 cumpridas, 5 violadas, 4 não medidas | **25 cumpridas, 4 violadas** (`RF9`, `AL1`, `AL2`, `RT1`), 4 não medidas |
| DRC completo | 4 erros | **0 erros**, 20 avisos de biblioteca |
| Ligações | 204 roteadas, 59 sem trilha | 196 roteadas, 75 sem trilha; 58 itens desconectados em 37 redes (`RT1`) |
| Peças fora das sombras (`ME2`) | 5 dentro | **0**: `J102` (SH, frente), `J103` e `LS601` e `U502` (verso), `U301` (teto de 3,0) |
| Caixa | conceito de 62 × 104 × 19, sem medida | **62 × 106 × 17**, 12 regras cumpridas, 0 violadas |

Nada impresso, nada montado.

## Verificação

- `python hardware_gnssbike/cad/check_sch.py`: o esquemático confere com a
  lista de nós; o ERC não acusa erro novo; 16 peças com pinagem por confirmar
  na ficha.
- `python hardware_gnssbike/cad/check_pcb.py` (regera) → `route.py` →
  `"D:/KiCAD/bin/python.exe" fill_zones.py` → `check_pcb.py --como-esta` →
  `dry_run_pcb.py` → `make_3d.py` → `make_2d.py` → `montagem.py` →
  `caixa/dry_run_caixa.py` → `caixa/make_caixa.py`: os números deste documento (o adendo
  é a rodada da tarde).
- `BOARD=gnssbike/nrf54lm20a/cpuapp BUILD_DIR=zephyr_app/build_custom bash tools/fw/fw.sh build`:
  0 avisos de compilador.
- `python tools/docs/mermaid_check.py` e `python tools/docs/links_check.py`:
  rodados depois de fechar os documentos deste dia.
- Nada testado na placa, nem no DK, nem com componente nenhum.

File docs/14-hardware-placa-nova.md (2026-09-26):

# Arquitetura de hardware da placa nova

Especificação técnica preliminar da placa própria do GNSS Bike Computer: decisões, arquitetura, alimentação, componentes principais, barramentos, alocação de pinos, placa de circuito impresso, empilhamento mecânico, regras de layout e bring-up. A pesquisa de mercado e as alternativas estão em [13-placa-nova.md](13-placa-nova.md); a avaliação que escolheu cada componente, em [15-avaliacao-componentes.md](15-avaliacao-componentes.md); o aparelho desenhado, em [Como fica o aparelho](13-placa-nova.md#como-fica-o-aparelho).

> [!IMPORTANT]
> Especificação de conceito, anterior ao esquemático. O **devicetree da placa já existe e compila** (`zephyr_app/boards/gnss/gnssbike/`, alvo `gnssbike/nrf54lm20a/cpuapp`), mas nenhum componente foi montado nem medido. Tensões, correntes e endereços vêm dos datasheets citados em [Referências](#referências); potências médias e autonomia são estimativas de [13](13-placa-nova.md#orçamento-de-energia).

**Nesta página:** [Estado das decisões](#estado-das-decisões) · [Arquitetura](#arquitetura) · [Alimentação](#alimentação) · [Componentes principais](#componentes-principais) · [GNSS](#gnss) · [Barramentos e endereços](#barramentos-e-endereços) · [Alocação de pinos](#alocação-de-pinos) · [Placa de circuito impresso](#placa-de-circuito-impresso) · [Empilhamento mecânico](#empilhamento-mecânico) · [Regras de layout](#regras-de-layout) · [Teste e bring-up](#teste-e-bring-up) · [Pendências](#pendências) · [Referências](#referências)

## Estado das decisões

| Bloco | Escolha | Estado | Como fechar |
|---|---|---|---|
| MCU e rádio | nRF54LM20A no módulo Fanstel BM20C (antena em chip) | MCU decidido; módulo conferido na ficha Draft 0.99 ([19](19-lista-de-compras.md#mcu-e-rádio)) | tolerância do cristal de 32,768 kHz, que a ficha não dá (o ANT exige no máximo ±50 ppm), e o lote: nenhum em estoque na DigiKey, 1.000 previstos para 12/11/2026 |
| Pilha de rádio | BLE do NCS v3.3.0 e ANT do `sdk-ant` v2.1.1 | decidido | — |
| Display | Sharp LS027B7DH01A (MIP monocromático, 2,7", 400 × 240, 5 V) com o filme de luz frontal Azumo 11103-06_A1; a placa aceita também o JDI LPM027M128C (MIP de 8 cores, 3,0 V) no mesmo conector | validado para compra ([19](19-lista-de-compras.md#display)); o JDI saiu da lista por falta de canal autorizado | voltar à cor é decisão do dono: amostras do JDI de revendedores ou outra tela ([19](19-lista-de-compras.md#antes-de-fechar-o-pedido)) |
| Painéis solares | 6 módulos de 3 células de 23 × 8 mm (classe ANYSOLAR KXOB25-05X3F) na frente inclinada e nos chanfros laterais | arranjo decidido | fixação, janela e vedação na mecânica |
| GNSS | u-blox MAX-F10S (L1 + L5, sem modo econômico) no footprint MAX, que aceita também o MAX-M10N-10B (L1, com LEAP) | recomendado ([15](15-avaliacao-componentes.md#gnss)) | protótipo: C/N0 por banda, trajeto, consumo e isolamento da antena; A/B com o M10N no mesmo footprint |
| Carga e medição | nPM1300 (USB e reguladores), AEM10900 (solar), MAX17262 (medidor na célula); o USB bloqueia o solar no hardware | recomendado ([15](15-avaliacao-componentes.md#carga-usb-c-e-painel-solar)) | bancada com as placas de avaliação do nPM1300 e do AEM10900 e o MAX17262 na mesma célula |
| Bateria | LiPo de 1 célula, 2000 mAh, 60 × 36 × 7 mm, com proteção (PCM) e dois NTC de 10 kΩ | recomendado | especificação com o fornecedor do pack (dois NTC, UN38.3) |
| Sensores | BMP585, BMI270, MMC5633NJL, OPT3001 | validado para compra ([19](19-lista-de-compras.md#sensores)); o LSM6DSV16X e o LIS2MDL saíram por falta de estoque | o footprint do IMU aceita o LSM6DSV16X quando ele voltar |
| Armazenamento | microSD (Hirose DM3AT-SF-PEJM5) e **MX25R6435F** (NOR SPI de 8 MB) no `spi00` no protótipo; só a NOR no produto | ficha lida e comparada com a Winbond W25Q128JV ([15](15-avaliacao-componentes.md#armazenamento)) | confirmar preço e estoque; o FatFs sobre flash já compila e roda no DK, que traz a mesma peça |
| USB | USB-C IPX8 Molex 2036150003 (o Amphenol 12402484E512A fica de alternativa até o desenho), ESD761 no VBUS e TPD4E05U06 nos dados e no CC, USB High Speed | validado ([19](19-lista-de-compras.md#usb)) | placa de 0,8 mm, anel e furo na parede pelo desenho da Molex |

O display é um LCD de memória refletivo (MIP), legível ao sol como o e-paper, e não e-paper: o e-paper colorido leva de 11 a 20 s por quadro em cor e gasta cerca de 144 mJ por atualização, contra menos de 0,2 s e cerca de 30 µJ do MIP, e o aparelho redesenha dados a cada segundo ([13](13-placa-nova.md#display)).

## Arquitetura

```mermaid
flowchart LR
    subgraph PWR["Energia"]
        USBC["USB-C"] --> PMIC["nPM1300<br/>carregador, BUCK1, BUCK2,<br/>chaves de carga, ship mode"]
        PV["6 módulos solares"] --> HARV["AEM10900<br/>MPPT"]
        PMIC --- NODE(("nó da bateria"))
        HARV --- NODE
        PMIC -.->|"VBUSOUT bloqueia a carga solar"| HARV
        NODE --- GAUGE["MAX17262"] --- CELL["LiPo 1S 2000 mAh"]
        NODE --> BCK["TPS7A02 1,8 V<br/>backup do GNSS"]
    end
    subgraph CORE["Módulo BM20C"]
        MCU["nRF54LM20A<br/>BLE e ANT+"]
    end
    subgraph GNSSB["GNSS"]
        ANT["antena L1/L5"] --> GMOD["u-blox MAX-F10S<br/>ou MAX-M10N-10B"]
        GMOD --- DIRETO["sem tradutor: receptor a 3,0 V<br/>no mesmo trilho do MCU (2026-09-26)"]
    end
    subgraph HMI["Interface"]
        LCD["Sharp LS027B7DH01A<br/>com luz frontal, ou JDI"]
        KEYS["3 botões"]
        BUZ["buzzer piezo"]
        LED["LED RGB"]
        ALS["OPT3001"]
    end
    subgraph SENS["Sensores"]
        BARO["BMP585"]
        IMU["BMI270"]
        MAG["MMC5633NJL"]
    end
    SD["microSD e flash NOR"]
    XLAT ---|"uart21"| MCU
    LCD ---|"spi22"| MCU
    SD ---|"spi00"| MCU
    BARO ---|"i2c23"| MCU
    IMU ---|"i2c23"| MCU
    MAG ---|"i2c23"| MCU
    ALS ---|"i2c23"| MCU
    PMIC -.-|"i2c30"| MCU
    GAUGE -.-|"i2c30"| MCU
    HARV -.-|"i2c30"| MCU
    USBC ---|"USB HS"| MCU
    KEYS --> MCU
    MCU --> BUZ
    MCU --> LED
    BCK --> GMOD
```

## Alimentação
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

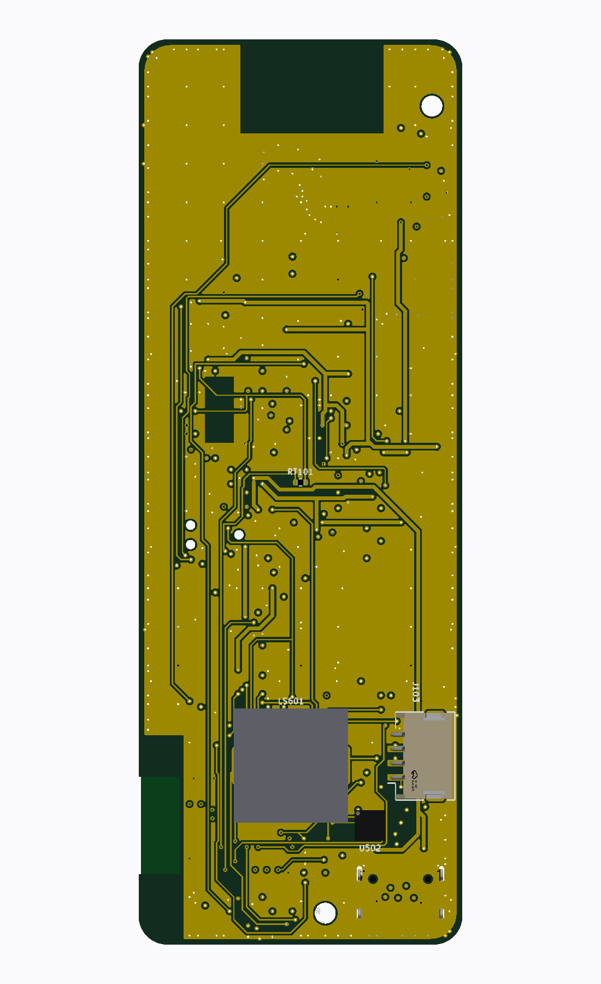
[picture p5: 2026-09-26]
docs/img/hardware/gnssbike-3d-tras.png

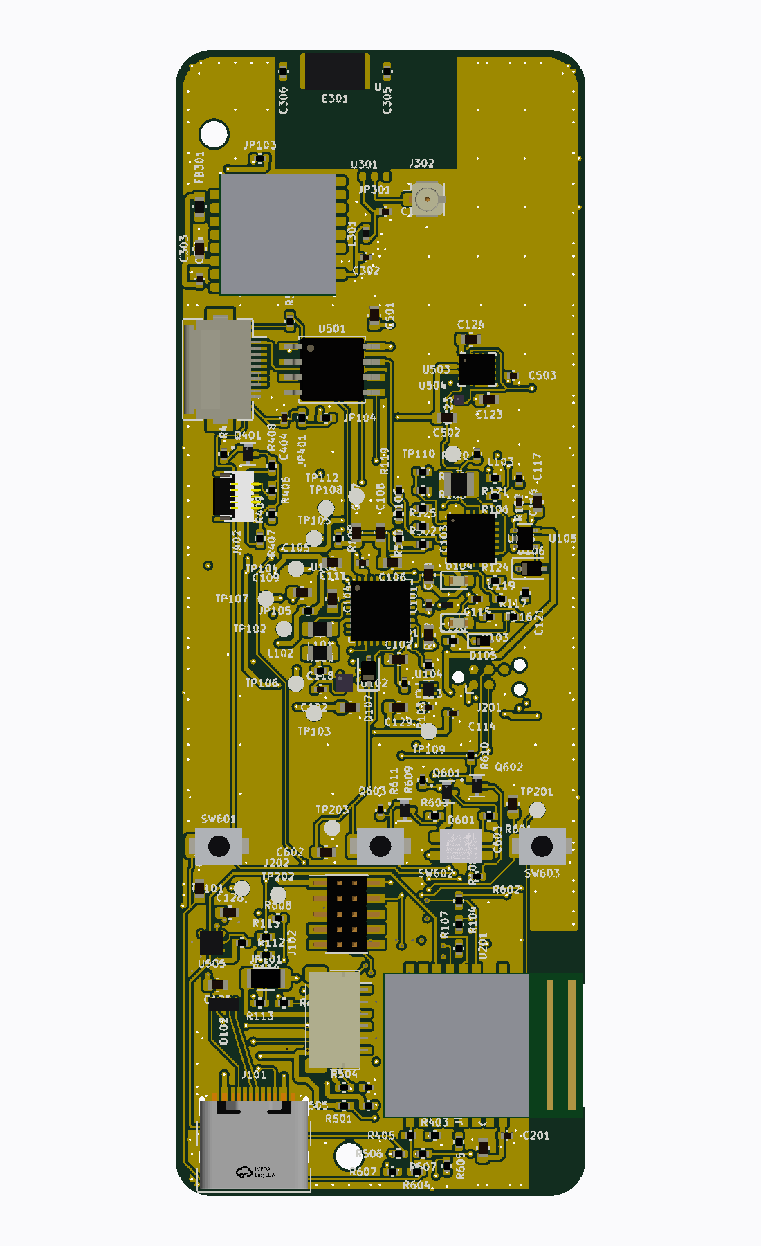
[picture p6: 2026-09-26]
docs/img/hardware/gnssbike-3d-frente.png

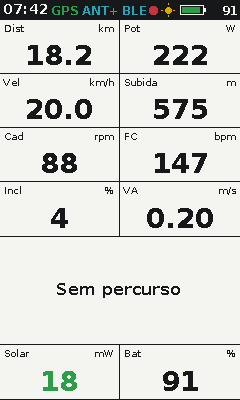
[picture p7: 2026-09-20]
docs/telas/14_prc_sem_percurso_cor.png

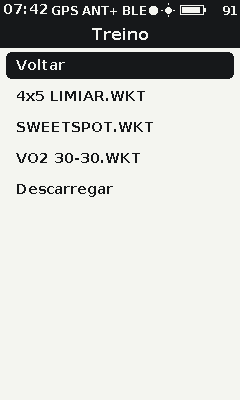
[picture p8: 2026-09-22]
docs/telas/40_treinos_mono.png

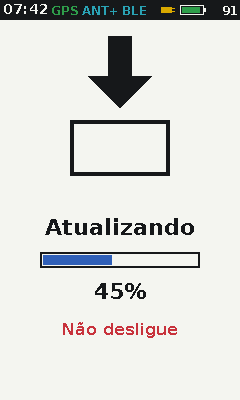
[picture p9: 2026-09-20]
docs/telas/28_atualizacao_cor.png

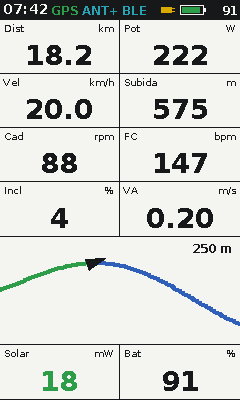
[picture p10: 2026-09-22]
docs/telas/34_proxima_subida_cor.png

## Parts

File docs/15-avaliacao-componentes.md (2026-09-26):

# Avaliação dos componentes da placa nova

Avaliação de engenharia, bloco a bloco, dos componentes principais da placa nova. Para cada bloco: o que ele precisa atender, os candidatos comparados com números de datasheet, os riscos, a escolha e os detalhes que o esquemático precisa. A especificação que resulta daqui está em [14-hardware-placa-nova.md](14-hardware-placa-nova.md); a pesquisa de mercado e as fontes de cada bloco, em [13-placa-nova.md](13-placa-nova.md).

> [!IMPORTANT]
> Avaliação feita sobre datasheets e notas de aplicação, sem bancada: nenhum componente foi montado nem medido. Cada escolha diz qual medida a confirma. Preço e estoque são da DigiKey em 2026-09-18 e mudam rápido.

> [!NOTE]
> A [lista de compras](19-lista-de-compras.md) validou cada peça em duas passagens, compra e integração, e o texto abaixo já traz o que mudou: o BMI270 e o MMC5633NJL entram no lugar do LSM6DSV16X e do LIS2MDL, sem estoque; o BUCK2 dá os 3,0 V e o BUCK1, os 1,8 V, pela tabela dos resistores de VSET; o indutor do AEM10900 passa a 4,7 µH; o ESD761, o NTC da TDK, o JST GH e o receptáculo da Molex substituem o ESD751, o NTC da Murata, o JST SH e o Amphenol.
>
> **A tela voltou a ser o JDI em 2026-09-23**, por decisão do dono: o
> **LPM027M128C**, peça única com luz frontal integrada, no lugar do par
> Sharp LS027B7DH01A + filme Azumo que a lista tinha adotado. A Sharp segue
> como plano B ([Display](#display)).

**Nesta página:** [Resumo](#resumo) · [Critérios](#critérios) · [Carga: USB-C e painel solar](#carga-usb-c-e-painel-solar) · [GNSS](#gnss) · [Módulo do MCU](#módulo-do-mcu) · [Display](#display) · [Antena GNSS](#antena-gnss) · [Sensores](#sensores) · [Armazenamento](#armazenamento) · [USB-C e proteção](#usb-c-e-proteção) · [Bateria](#bateria) · [Tradutor de nível e backup do GNSS](#tradutor-de-nível-e-backup-do-gnss) · [Interface](#interface) · [Bancada antes do layout](#bancada-antes-do-layout) · [Referências](#referências)

## Resumo

| Bloco | Escolha | Por quê | Plano B |
|---|---|---|---|
| Carga pelo USB-C | Nordic nPM1300 (QFN32) | carregador de 32 a 800 mA com power path, CC sem resistor externo, 2 bucks, 2 chaves, ship mode de 370 nA e driver no NCS v3.3.0 | nenhum candidato junta tudo isso com driver |
| Carga pelo painel | e-peas AEM10900 (QFN28), indutor de 4,7 µH | o único avaliado com MPPT na faixa das strings de 3 células, cerca de 90 % de rendimento a 1,5–1,7 V e corte térmico sem MCU | nenhum com corte térmico e 80 mA; o BQ25798 pediria strings de 7 células ou mais |
| Convivência das cargas | o USB bloqueia o solar no hardware (DIS_STO_CH pelo VBUSOUT) | os dois carregadores nunca trabalham juntos | bloqueio por registrador, pelo firmware |
| Medição | Analog Devices MAX17262 | vê as duas fontes, também com o aparelho desligado | nRF Fuel Gauge corrigido pelo APM (perde a carga em ship mode) |
| GNSS | u-blox MAX-F10S, L1 + L5 | 1 m de CEP contra 1,5 m, no mesmo encapsulamento MAX e com o mesmo driver UBX; é o multibanda que menos consome (46,8 mW contra 59 do LC79H e 79 do LC29H). Custa autonomia: o aparelho vai a cerca de 58 mW e dura cerca de 115 h, contra 21 mW e 310 h do MAX-M10N-10B em LEAP | MAX-M10N-10B no mesmo footprint |
| MCU | Fanstel BM20C (nRF54LM20A) | módulo certificado, 64 GPIO, antena e cristais inclusos; o QFN52 não tem pinos suficientes | chip em CSP98 com antena própria |
| Display | **JDI LPM027M128C**, MIP de 8 cores com luz frontal integrada (decidido em 2026-09-23) | peça única: sem etapa de laminação, mesma resolução, 30 µW a 1 quadro/s contra 175 µW da Sharp, e cor. Custa R$ 776 contra US$ 90,06 do par, **sem canal autorizado e sem garantia** | Sharp LS027B7DH01A com o filme Azumo 11103-06_A1, no mesmo conector |
| Antena GNSS | TE L000670 no protótipo | L1 e L5 numa alimentação só: o F10S precisa das duas bandas, e ela ainda serve ao M10N do A/B | elementos de parede sob medida |
| Barômetro | Bosch BMP585 | robusto a água e produtos químicos (15 bar sem efeito, pela ficha), 1,3 µA a 1 Hz, ±0,5 Pa/K | ST LPS28DFW |
| IMU e magnetômetro | Bosch BMI270 e Memsic MMC5633NJL | em estoque, com driver no NCS v3.3.0 e despertar por movimento; o footprint do IMU aceita o ST LSM6DSV16X | ST LSM6DSV16X e LIS2MDL, quando voltarem ao estoque |
| Luz ambiente | TI OPT3001 | resposta do olho humano, 1,8 µA | Vishay VEML7700 |
| Armazenamento | **flash NOR SPI soldada** (microSD só no protótipo) | preço: o SD NAND de 1 Gbyte sai por mais que o resto do armazenamento vale, e o aparelho usa dezenas de megabytes, não gigabytes | SD NAND XTX; microSD em soquete com tampa |
| USB-C | receptáculo IPX8 Molex 2036150003 | dispensa a tampa de borracha; o desenho confirma o anel de vedação | Amphenol 12402484E512A, depois do desenho; GCT USB4105-GF-A com tampa |
| Proteção do USB | TI ESD761 no VBUS, TI TPD4E05U06 no D+, D−, CC1 e CC2 | o TVS do VBUS não conduz até 24 V e preserva os 22 V do nPM1300 | TI TVS2200 no VBUS |
| Bateria | LiPo de 1 célula, 2000 mAh, com PCM e 2 NTC | 60 × 36 × 7 mm; o PCM é obrigatório (o nPM1300 não tem UVLO) | 2500 mAh se a caixa crescer |
| Backup do GNSS | TI TPS7A02 | 25 nA no backup | — |
| Tradutor de nível | **nenhum, desde 2026-09-26**: o receptor passou a 3,0 V, no trilho do MCU (opção 1 da tabela 35 do manual de integração) | o BUCK1 é de ±5 % e o projeto de 1,8 V pede ±2 %; o LDO de ±1 % custava 35 mW na bateria, a opção 1 custa 11 | TI TXU0204 com o receptor a 1,8 V, o que era |

## Critérios

1. **Energia no uso típico.** O GNSS domina o [orçamento de energia](13-placa-nova.md#orçamento-de-energia): cada miliwatt economizado nele vale mais que em qualquer outro bloco e decide se o painel sustenta o aparelho num pedal de sol.
2. **Funcionar desligado e ao sol.** O painel carrega com o MCU em ship mode, então toda proteção da célula precisa funcionar sem firmware.
3. **Driver no NCS v3.3.0**, ou um esforço conhecido para escrever um.
4. **Montagem do protótipo:** QFN, LGA e módulos com castelação antes de WLCSP de passo fino.
5. **Compra:** estoque em distribuidor autorizado, datasheet público e ciclo de vida ativo.
6. **Robustez:** chuva, vibração e a faixa de 0 a 60 °C da caixa ao sol.
7. **Risco técnico:** comportamento não documentado conta contra e vira item de [bancada](#bancada-antes-do-layout).

## Carga: USB-C e painel solar

### Requisitos

| Requisito | Valor | Origem |
|---|---|---|
| Entrada USB | USB-C de 5 V como sink, sem USB PD; capacidade da fonte lida pelo CC (padrão, 1,5 A ou 3 A) | [14](14-hardware-placa-nova.md#alimentação) |
| Carga pelo USB | 2000 mAh em cerca de 3,5 h (600 mA, 0,3C), JEITA, fim de carga em 4,20 V (ou 4,10 V para vida longa) | [14](14-hardware-placa-nova.md#carga) |
| Painel | 6 módulos ANYSOLAR KXOB25-05X3F em paralelo, em 3 faces com orientações diferentes. Cada módulo é uma string de 3 células: 2,07 V em aberto a 25 °C (cerca de 2,30 V a −20 °C) e 1,67 V com 18,4 mA no ponto de máxima potência a 1 sol | [13](13-placa-nova.md#painel-solar) |
| Corrente do painel | pico de cerca de 80 a 88 mA ao meio-dia, com o aparelho na horizontal; de 1 a 30 mA na maior parte do tempo | cálculo abaixo |
| Carga desligado | o painel carrega com o aparelho em ship mode; o corte térmico não pode depender do MCU, porque a caixa ao sol passa de 45 °C | [13](13-placa-nova.md#dois-carregadores-na-mesma-célula) |
| Medição | estado de carga com as duas fontes, inclusive o que o painel põe com o aparelho desligado | — |

Pico do painel: com o sol a pino e o aparelho na horizontal, os 2 módulos da face da frente (inclinada cerca de 10°, pelo [desenho](13-placa-nova.md#como-fica-o-aparelho)) dão 2 × 18,4 × cos 10° ≈ 36 mA, e os 4 dos chanfros de 45° dão 4 × 18,4 × cos 45° ≈ 52 mA: cerca de 88 mA antes das perdas da janela. Com o sol de lado, um chanfro recebe o sol de frente e o outro só luz difusa, e o total cai para 65 a 72 mA. As 3 faces nunca recebem o sol de frente ao mesmo tempo, então os 110 mA da soma dos 6 módulos nunca acontecem.

### Topologias comparadas

| Topologia | Como funciona | Veredito |
|---|---|---|
| **A. nPM1300 + AEM10900 + MAX17262** | cada fonte com o seu carregador, os dois no nó da bateria; o medidor fica entre esse nó e a célula | **escolhida** |
| B. TI BQ25798 sozinho | um carregador buck-boost com duas entradas e MPPT | descartada. A entrada começa em 3,6 V, o que pede strings de 7 células ou mais em série; a 65 °C, a tensão de máxima potência de 7 células cai para cerca de 3,4 V (−1,74 mV/K por célula) e o carregador para no sol forte. Uma string em série atravessaria faces com sol diferente e ficaria presa à célula mais escura. Consome 17 µA só com a bateria, não tem reguladores nem driver no NCS, e o rendimento com poucos miliwatts não é publicado |
| C. Painel direto no VBUS do nPM1300 | sem harvester | descartada. O VBUS pede de 4,0 a 5,5 V, e o nPM1300 só limita a corrente (100 mA até o firmware mudar) e desliga o SYSREG abaixo do VBUSMIN: sem regulação da tensão de entrada não há MPPT. O carregador é linear, com cerca de 75 % de rendimento de 5 V para 3,7 V |
| D. Harvester no VSYS do nPM1300 | o solar alimentaria o sistema | descartada. O datasheet proíbe ("VSYS must not be supplied from an external source"), e nada carregaria com o aparelho desligado |
| E. A, com outro harvester | BQ25570, ADP5091, MAX20361, AEM10330, AEM10941 | ver [Harvester](#harvester) |
| F. A, sem o MAX17262 | o nRF Fuel Gauge do nPM1300, corrigido pela energia que o APM do AEM10900 informa | descartada. O nRF Fuel Gauge só vê a corrente que passa pelo nPM1300; a correção pede o fator α do APM (a e-peas fornece sob pedido) e perde tudo o que o painel carrega em ship mode. O MAX17262 custa 5,2 µA e um CI |

### Harvester

O corte térmico autônomo é eliminatório: com o aparelho desligado ao sol, só o harvester decide se carrega uma LiPo a 50 °C.

| CI | Entrada (MPPT) | Partida a frio | Corrente de entrada | Corte térmico sem MCU | Encapsulamento | Veredito |
|---|---|---|---|---|---|---|
| **e-peas AEM10900** | 0,12 a 2,73 V (circuito aberto até 3,0 V) | 250 mV, 2,47 µW | 65,5 mA com 6,8 µH e 175,5 mA com 3,3 µH (tabela 6; a fórmula da seção 6.7.2 dá 85 mA com 6,8 µH) | sim (0 e 45 °C por padrão) | QFN28 de 4 × 4 mm | **escolhido** |
| e-peas AEM10941 | 50 mV a 4,5 V | 380 mV, 3 µW | 110 mA | não listado | QFN | sem corte térmico confirmado; os 2 LDOs internos não servem aqui |
| e-peas AEM10330 | 0,1 a 4,5 V | 275 mV, 3 µW | curva publicada até 50 mA | não (só o bloqueio externo EN_STO_CH) | QFN | sem corte térmico |
| TI BQ25570 | 0,1 a 5,1 V depois da partida | 600 mV | 100 mA | não | QFN | sem corte térmico; limiares por resistores |
| ADI ADP5091 | 0,08 a 3,3 V | 380 mV | 6 µW a 600 mW | não confirmado | LFCSP | corte térmico não confirmado |
| ADI MAX20361 | não confirmada | 225 mV | 15 µW a mais de 300 mW | sim (0 e 45 °C) | WLP de 1,63 × 1,23 mm | difícil de montar no protótipo; faixa de entrada não confirmada |

Por que o AEM10900:

- **Faixa certa para strings de 3 células:** MPPT até 2,73 V e circuito aberto até 3,0 V cobrem os 2,30 V das 3 células a −20 °C com folga; 4 células chegariam a 2,97 V a −5 °C, no limite.
- **Rendimento publicado:** a figura 4 do datasheet (com 6,8 µH) dá cerca de 87 a 91 % com 1,5 a 1,7 V na entrada, de 0,1 a 10 mA, com a bateria de 2,85 a 4,5 V.
- **Tudo sem firmware:** limiares de carga pelos pinos, corte térmico por NTC, bloqueio da carga pelo pino DIS_STO_CH, keep-alive pela bateria (162 a 242 nA).
- **Com firmware, se quiser:** I2C para limiares, medidor de energia (APM) e interrupção. Não há driver no Zephyr; são poucos registradores.

### Medição da carga

O nRF Fuel Gauge da Nordic roda no MCU e usa a corrente que o nPM1300 mede no próprio caminho da bateria. A corrente do AEM10900 entra na célula por fora desse caminho, e em ship mode ninguém mede nada. O MAX17262 fica em série com a célula e vê a corrente líquida de todas as fontes, também com o aparelho desligado, com o algoritmo ModelGauge m5 EZ, que dispensa a caracterização da célula.

| Item | Valor (ficha da Maxim) |
|---|---|
| Encapsulamento | WLP de 9 pinos, 1,5 × 1,5 mm, passo de 0,4 mm (a DigiKey lista o MAX17262REWL+T, ativo); não há versão com terminais, então a montagem é por estêncil e forno |
| Ligação | BATT no positivo da célula (depois do PCM), com 0,1 µF; SYS no nó da bateria (VBAT do nPM1300 e STO do AEM10900); o sensor de 7 mΩ fica entre os dois pinos |
| Corrente | 1,7 A contínuos, 2,4 A com 10 % de uso e 3,1 A em pulsos de 250 ms: sobra para os 600 mA de carga e os picos de descarga |
| Consumo | 5,2 µA em hibernação (12 µA no máximo), 16 µA ativo, 0,5 µA desligado |
| Medição de tensão | erro de ±7,5 mV a 25 °C (±20 mV de −40 a 85 °C) |
| Temperatura | TH no BATT, usando o sensor interno de ±1 °C: os dois NTC da célula já estão ocupados; o CI fica junto do conector da bateria. A configuração de fábrica (0x2210) liga o ETHRM, e o firmware grava ETHRM = 0 com TSel = 0 |
| Outros pinos | REG (1,8 V interno) com 0,47 µF, sem carga externa; ALRT em dreno aberto para o MCU |
| I2C | 0x36; binding `maxim,max17262`, que pede capacidade, tensões de projeto, de carga e de vazio, e a corrente de carga |

### Convivência das duas cargas

1. **USB presente bloqueia o solar no hardware.** O pino DIS_STO_CH do AEM10900 recebe o VBUSOUT do nPM1300 por um divisor de 100 kΩ e 1 MΩ: cerca de 4,5 V com 5 V no VBUS, abaixo dos 5,5 V do máximo absoluto do pino. O VBUSOUT só existe com VBUS válido e já desliga acima de 5,5 V. O AEM10900 lê o pino a cada 1 s, e o pino vale mesmo com a configuração por I2C. Assim o nPM1300 nunca carrega junto com outro carregador, e a detecção de fim de carga funciona como a Nordic especifica. O MCU deixa de gastar um pino nisso.
2. **Sem USB, só o AEM10900 carrega**, até 3,90 V pelos pinos (STO_CFG = H, L, H, o perfil "Li-ion long life"). Parada ao sol, a célula fica longe dos 4,2 V, que envelhecem a LiPo no calor. Com o aparelho ligado e a célula fria, o firmware pode subir o limiar para cerca de 4,05 V por I2C.
3. **Dois NTC na célula:** o do pack no nPM1300, com JEITA de 0, 10, 45 e 60 °C, e um segundo no AEM10900, com corte em 0 e 45 °C.
4. **Proteção do pack (PCM) obrigatória:** o nPM1300 não tem proteção contra descarga profunda ("An undervoltage lockout circuit is not included on the device and must be set up on the battery pack").

```mermaid
stateDiagram-v2
    [*] --> Solar
    Solar --> USB: VBUS válido
    USB --> Solar: VBUS some
    note right of Solar
        só o AEM10900 carrega
        até 3,90 V pelos pinos
        corte fora de 0 a 45 °C
    end note
    note right of USB
        DIS_STO_CH alto pelo VBUSOUT
        só o nPM1300 carrega, até 4,20 V
        JEITA pelo NTC do pack
    end note
```

### Bloco escolhido

```mermaid
flowchart LR
    USBC["USB-C<br/>VBUS, CC1, CC2"] --> PROT["TVS no VBUS<br/>ESD no CC e no D+ e D−"]
    PROT --> NPM["nPM1300 QFN32<br/>carregador linear de 32 a 800 mA<br/>BUCK2 3,0 V, BUCK1 1,8 V"]
    NPM -->|"VBUSOUT"| DIV["divisor<br/>100 kΩ e 1 MΩ"]
    DIV -->|"DIS_STO_CH"| AEM
    PV["6 módulos de 3 células<br/>em paralelo"] --> AEM["AEM10900 QFN28<br/>MPPT a 80 %, indutor de 4,7 µH"]
    NPM ---|"VBAT"| NODE(("nó da bateria"))
    AEM ---|"STO"| NODE
    NODE --- FG["MAX17262<br/>sensor interno"]
    FG --- CELL["LiPo 1S 2000 mAh<br/>PCM e 2 NTC"]
    CELL -.-|"NTC 1"| NPM
    CELL -.-|"NTC 2"| AEM
```

### Detalhes para o esquemático

**nPM1300**

- QFN32 de 5 × 5 mm. O WLCSP é sensível à luz, segundo o datasheet, e a caixa tem janelas.
- VBUS com capacitor de 10 µF e 25 V (o CI tolera 22 V em transitório) e a proteção de [USB-C e proteção](#usb-c-e-proteção). CC1 e CC2 direto no conector: o Rd de 5,1 kΩ é interno.
- VBUSOUT com o capacitor de desacoplamento; alimenta o VBUS do BM20C e o divisor do DIS_STO_CH.
- BUCK2 em 3,0 V (RVSET2 de 150 kΩ) e BUCK1 em 1,8 V (RVSET1 de 47 kΩ), resistores de 5 % no máximo: a tabela do VSET1 vai de 1,0 a 2,7 V e não tem 3,0 V, e a do VSET2 vai de 1,8 a 3,3 V (tabelas 18 e 19); é a configuração 1 da referência da Nordic (tabela 39), e nenhum VSET pode ficar aberto. Indutores de 2,2 µH com DCR abaixo de 400 mΩ, em 0806, como na lista de referência (tabela 40): Murata DFE201610E-2R2M=P2, com 140 mΩ. A lista de referência tem ainda dois de 1,0 µF e 10 V, nove de 10 µF e 25 V, um de 2,2 µF e 16 V e um de 100 nF.
- LDSW1 como chave do armazenamento (100 mA), com entrada no 3V0; LDSW2 como LDO de 3,3 V com entrada no VSYS, para a luz do display (até 50 mA; entrada de 2,6 V ao VSYS; tabelas 23 e 24).
- NTC do pack no pino NTC; botão de ligar só no SHPHLD, que tem pull-up interno de 50 kΩ; GPIO3 como interrupção para o MCU, que recebe os eventos `NPM13XX_EVENT_SHIPHOLD_PRESS` e `RELEASE`. Segurar o botão mais de 10 s religa o sistema inteiro (reset por toque longo, ligado de fábrica e desligável pelo registrador LPRESETCONFIG).
- **LED de carga sem firmware:** o LED1 do nPM1300 sai de fábrica como indicador de carga (registrador `LEDDRV1MODESEL` = 1) e o LED0 como indicador de erro do carregador (`LEDDRV0MODESEL` = 0). Cada um afunda 5 mA; com o anodo no VSYS, o LED de carga acende com o aparelho desligado.
- **Firmware:** o limite do VBUS começa em 100 mA e volta a 100 mA a cada reconexão; depois da detecção pelo CC, o firmware sobe para 500 mA, 1,5 A ou 3 A. Carga de 600 mA, limite de descarga alto (1 A).
- **Calor:** o carregador é linear e dissipa (VBUS − VBAT) × ICHG, de 0,7 a 1,0 W na fase de corrente constante a 600 mA. A regulação térmica do CI reduz a corrente se precisar; a temperatura da célula se mede na bancada.

**AEM10900**

- QFN28 de 4 × 4 mm. O WLCSP16 só tem o R_MPP[0] e perde o T_MPP e o ZMPP.
- **Indutor de 4,7 µH:** TDK VLS252012HBX-4R7M-1 (2,5 × 2,0 × 1,2 mm, 1,4 A de saturação, 240 mΩ). No modo de alta potência, que vem ligado, a tabela 6 do datasheet dá 65,5 mA de entrada máxima com 6,8 µH e 175,5 mA com 3,3 µH, e a fórmula da seção 6.7.2 (579 / L) dá 85 mA com 6,8 µH. Os dois números não batem, e o pico estimado do arranjo é de 88 mA: com 4,7 µH, a entrada vai de 95 mA (escalando a tabela) a 123 mA (pela fórmula). O de 6,8 µH (VLS252012HBX-6R8M-1), o valor das curvas de rendimento publicadas, fica para a comparação na bancada; o datasheet pede pico de pelo menos 1 A com 3,3 µH, e menos com indutância maior. A dúvida da tabela vai para a e-peas.
- CSRC e CINT de 22 µF, 0402 e 6,3 V: a lista mínima do datasheet pede o Murata GRM158R60J226ME01, sem estoque, e a [lista de compras](19-lista-de-compras.md#passivos) usa o Samsung CL05A226MQ5N6J8. No CSTO, 22 µF de 10 V em 0603 dá cerca de 9 µF com 4 V aplicados, acima dos 5 µF efetivos que o datasheet pede com a bateria num conector.
- R_MPP[2:0] no VINT (abertos também leem alto): 80 %, a razão do silício monocristalino (1,67 V / 2,07 V = 0,81).
- T_MPP[1:0] no VINT (padrão); o tempo entre medidas do MPP se ajusta na bancada, pedalando sob árvores.
- STO_CFG[2:0] = H, L, H (STO_CFG[2] e STO_CFG[0] no VINT, STO_CFG[1] no GND): 3,90 V de carga e 3,01 V de descarga.
- KEEP_ALIVE no VINT; I2C_ADDR no I2C_VDD (endereço 0x41); I2C_VDD no 3V0; IRQ para o MCU; ST_STO num ponto de teste.
- TH_REF e TH_MON com NTC de 10 kΩ e B3380 e RDIV de 22 kΩ 1 %, os valores dos limites padrão de 0 e 45 °C. O NTC vem do pack (segundo NTC, pelo conector) ou é um TDK NTCG103JF103FT1 na face de trás da placa, sob a célula; o Murata NCP15XH103J03RC da lista do datasheet não é mais recomendado para projetos novos.
- **Layout:** nó SWDCDC curto e sem plano embaixo, indutor e capacitores junto dos pinos, nó TH_REF com pouca capacitância (seção 13 do datasheet).
- **Firmware:** esperar o IRQ subir, gravar os registradores e validar com `CTRL.UPDATE`. Os registradores partem dos valores de fábrica, não dos pinos (o VOVCH de fábrica é 4,1 V), então o firmware grava todos antes de validar, mantendo TMONEN, HPEN e KEEPALEN em 1. Com o keep-alive, a configuração por I2C continua valendo com o 3V0 desligado, até a bateria cair abaixo do limiar de descarga sem luz no painel. Por isso, antes do ship mode, o firmware volta o limiar para 3,90 V ou devolve o controle aos pinos (`CTRL.UPDATE` = 0).

## GNSS

### Requisitos

- **Precisão** em estrada, na cidade e sob árvores: os segmentos do Strava são a razão de ser do legacy.
- **Consumo:** o GNSS é o maior bloco do orçamento.
- **Partida rápida sem celular:** o equivalente do EPO do legacy.
- **Convivência com o rádio de 2,4 GHz** do nRF54LM20A, que transmite até +8 dBm na mesma placa.
- **Footprint e driver.**

### Candidatos

Rastreio contínuo a 1 Hz, GPS + Galileo + BeiDou (o padrão de cada módulo), com os números das fichas. Os do M10N vêm da ficha do MAX-M10N-10B (R05, UBXDOC-304424225-18248), que dá figura de ruído de 3 dB contra 1,5 dB do 00B, por causa do SAW na frente do LNA; os do F10S, da UBXDOC-963802114-12732 R03 (tabelas 2, 15, 16 e 17).

| | **u-blox MAX-F10S** | u-blox MAX-M10N-10B | u-blox MAX-M10S | Quectel LC76G(PA) | Quectel LC29H(AA) | Quectel LC79H(AL) |
|---|---|---|---|---|---|---|
| Bandas | **L1 + L5** | L1 | L1 | L1 | L1 + L5 | L1 + L5 |
| Sistemas | GPS, Galileo, BeiDou, QZSS, NavIC e SBAS; sem GLONASS | GPS, Galileo, BeiDou, QZSS e SBAS; sem GLONASS | GPS, Galileo, BeiDou, GLONASS, QZSS e SBAS | GPS, GLONASS, Galileo, BeiDou e QZSS | GPS, GLONASS, Galileo, BeiDou, QZSS e SBAS | GPS, GLONASS (L1), Galileo, BeiDou, QZSS e NavIC |
| Consumo em rastreio | 26 mA a 1,8 V (46,8 mW); 19 mA a 3,0 V (57 mW) | LEAP: 7,6 mA a 1,8 V (13,7 mW); potência plena: 15,2 mA (27,4 mW) | 15,2 mA a 1,8 V (27 mW) | 10 mA a 3,3 V (33 mW); modo ALP: 5,5 mA (18 mW) | 24 mA a 3,3 V (79 mW) | 33 mA a 1,8 V (59 mW) |
| Modo econômico | nenhum: a ficha do F10 não tem o grupo `CFG-PM` | LEAP, com 1,5 m de CEP | rastreio cíclico | ALP | citado sem número na ficha | não levantado |
| CEP em céu aberto | **1 m** | 1,5 m | 1,5 m | 1,5 m | 1 m | 1 m |
| Sensibilidade de rastreio | −167 dBm | −167 dBm; −159 dBm em LEAP | não levantada | −166 dBm | −165 dBm | não levantada |
| Backup de hardware | 28 µA | 34 µA | 28 µA | não levantado | 25 µA | não levantado |
| Entrada de RF | SAW, LNA e SAW | SAW, LNA e SAW | LNA e SAW (pede SAW externo) | LNA com cancelador de interferência | não levantada | LNA e SAW |
| Firmware | ROM; AssistNow Offline e Autonomous, só de L1 | flash, atualizável; AssistNow Live Orbits vitalício | ROM | EASY e EPO | não levantado | não levantado |
| Encapsulamento | **MAX, 10,1 × 9,7 × 2,5 mm** | MAX, o mesmo | MAX | L76, 10,1 × 9,7 × 2,4 mm | 16,0 × 12,2 × 2,5 mm | L76 (pinagem igual à do LC76G não confirmada) |
| Protocolo e driver | UBX; driver próprio do port (`u-blox,max-f10`) | UBX; o mesmo driver | UBX | NMEA; `quectel,lc76g` no NCS v3.3.0 | NMEA com `PQTM` próprio; driver novo | não levantado |
| Preço (DigiKey) | US$ 13,14 | US$ 14,52 | US$ 11,42 | US$ 9,72 | não levantado | US$ 14,09 |

```mermaid
xychart-beta
    title "GNSS em rastreio contínuo a 1 Hz (mW)"
    x-axis ["M10N LEAP", "M10N plena", "M10S", "LC76G", "F10S", "LC79H", "LC29H"]
    y-axis "mW" 0 --> 80
    bar [13.7, 27.4, 27, 33, 46.8, 59, 79]
```

Entre os de banda dupla — F10S, LC29H(AA) e LC79H(AL) — o F10S é o que menos consome, o menor, o único no encapsulamento que a placa já tem e o único que fala o protocolo que o firmware já implementa.

### Efeito no aparelho

Resto do aparelho no uso típico do [orçamento](13-placa-nova.md#orçamento-de-energia): 5,5 mW (MCU e rádios, display, sensores e armazenamento, PMIC), com o **JDI**, que é a tela decidida; no plano B, a Sharp com o REG710 somaria cerca de 0,2 mW. Reguladores a cerca de 90 % e 90 % dos 7,4 Wh da célula de 2000 mAh utilizáveis.

| GNSS | Aparelho, na bateria | Autonomia sem sol | Pedal de sol com os painéis do desenho (22 a 44 mW) |
|---|---|---|---|
| MAX-M10N-10B em LEAP (13,7 mW), a alternativa | cerca de 21 mW | cerca de 310 h | o painel cobre o consumo e a bateria carrega enquanto se pedala |
| MAX-M10N-10B em potência plena (27,4 mW) | cerca de 37 mW | cerca de 180 h | devolve de 36 a 72 min por hora |
| **MAX-F10S (46,8 mW), o escolhido** | cerca de 58 mW | cerca de 115 h | devolve de 23 a 46 min por hora |

### Banda dupla vale o consumo?

- **A favor:** o L5 tem código 10 vezes mais rápido e resiste melhor ao multipercurso de prédios e árvores; a u-blox fala em precisão de metro em ambiente urbano, e a ficha do F10S dá 1 m de CEP contra 1,5 m do M10.
- **Contra:**
  - O MAX-F10S gasta 3,5 vezes o M10N em LEAP e não tem modo só L1 ("Single-band operation is not supported. Both L1 and L5 signals must be enabled or disabled", seção 1.3 da ficha) nem modo econômico nenhum: a descrição de interface do F10 (UBX-23002975 R02, seção 4.8) não tem o grupo `CFG-PM`.
  - O GPS L5 ainda é pré-operacional e a ficha o deixa fora da solução por padrão; o ganho vem do Galileo E5a, do BeiDou B2a e do QZSS.
  - Numa caixa pequena, o L5 é o ponto fraco da antena: a TE L000670 tem 56 % de eficiência em L5 contra 66 % em L1, num plano de 90 × 41 mm, sem LCD nem bateria. A placa tem 55 mm de largura.
  - O AssistNow do F10S só cobre os sinais de L1, e o módulo é ROM: não tem o AssistNow Live Orbits vitalício do M10N, que é de flash.
- **No mercado:** Garmin, COROS e Wahoo têm banda dupla, mas a Garmin a oferece como modo à parte, que "roughly halves your battery" segundo o DC Rainmaker.

### Escolha: MAX-F10S

> [!NOTE]
> Esta seção foi refeita em 2026-09-20. A avaliação de 2026-09-19 escolhia o MAX-M10N-10B pela energia; o dono decidiu pela banda dupla ("aceito mudar para pegarmos um que nos atenda, consuma pouco e melhore a precisão e caiba na case e na PCB"). O M10N continua válido no mesmo footprint e é a peça do teste A/B.

O F10S é, entre os multibanda avaliados, o que menos consome (46,8 mW contra 59 do LC79H(AL) e 79 do LC29H(AA) a 3,3 V), o único no mesmo encapsulamento da placa e o único que não pede driver novo.

1. **Cabe sem mexer em nada.** Encapsulamento MAX de 10,1 × 9,7 × 2,5 mm, pino a pino com o M10N-10B na alimentação, na UART, no RESET_N, no EXTINT, no TIMEPULSE e no RF_IN. A antena TE L000670 do protótipo já é de L1 e L5, escolhida para este A/B. Layout, empilhamento e caixa não mudam.
2. **Precisão:** 1 m de CEP contra 1,5 m, sensibilidade de rastreio de −167 dBm, partida a frio em 28 s e a quente em 1 s. O código do L5 é dez vezes mais rápido que o do L1, que é o que ataca o multipercurso de prédio e de mata — o pior caso do legacy.
3. **Firmware:** o driver do port (`u-blox,max-f10`, no mesmo arquivo do M10) já falava UBX; as chaves da UART, da taxa, do modelo dinâmico e da saída de mensagens têm os mesmos IDs nas duas firmwares. Muda o grupo `CFG-SIGNAL`, que ganha L5 e NavIC, e some o `CFG-PM`.
4. **Rádio na mesma placa:** entrada com SAW, LNA e SAW, como o 10B — obrigatória com o BLE a +8 dBm do nRF54LM20A a centímetros da antena.
5. **Preço:** US$ 13,14 contra US$ 14,52 do M10N (DigiKey, 2026-09-18).

**O que custa, sem maquiagem:**

- **Energia.** O aparelho passa de cerca de 21 mW para cerca de 58 mW, e a autonomia sem sol cai de cerca de 310 h para cerca de 115 h. O painel deixa de cobrir o consumo num pedal de sol e passa a devolver de 23 a 46 min por hora ([Efeito no aparelho](#efeito-no-aparelho)).
- **Não dá para economizar desligando o L5:** a peça não faz banda única.
- **Sem modo econômico de rastreio.** O que sobra é o standby por software (`UBX-RXM-PMREQ`), que o firmware já usa entre modos, e o backup de hardware de 28 µA.
- **ROM, sem flash:** perde o AssistNow Live Orbits vitalício; ficam o AssistNow Offline e o Autonomous, e só de L1.
- **GPS L5 pré-operacional:** os satélites ainda transmitem como não saudáveis e ficam fora da solução. O ganho de hoje é Galileo E5a, BeiDou B2a e QZSS L5.

O **MAX-M10N-10B** fica como a peça do teste A/B no mesmo footprint, e como saída se a bancada mostrar que a autonomia importa mais que o metro de precisão: 13,7 mW em LEAP a 1,8 V, 1,5 m de CEP, firmware de flash com AssistNow Live Orbits vitalício. O firmware aceita os dois pelo devicetree, sem recompilar nada além do overlay.

O LC76G(PA) e o LC29H(AA) ficam de fora. O LC76G(PA) é de banda única, tem driver no NCS v3.3.0, GLONASS e EPO, mas gasta 33 mW (18 mW em ALP), tem outro footprint e não especifica imunidade ao rádio de 2,4 GHz. O LC29H(AA) é de banda dupla e 1 m de CEP, mas gasta 79 mW a 3,3 V, mede 16,0 × 12,2 mm e fala NMEA com comandos proprietários `PQTM`, ou seja, driver novo.

Não avaliado: o ST Teseo-LIV4F, da mesma classe de tamanho. A busca do dia se esgotou e o site da ST não respondeu; fica como segundo candidato se o A/B da bancada decepcionar.
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

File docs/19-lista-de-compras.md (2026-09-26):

# Lista de compras da placa nova

Lista de materiais do protótipo da placa nova, com cada peça validada em duas passagens: a **compra** (a peça existe, está ativa e tem estoque num distribuidor autorizado) e a **integração** (a peça funciona no circuito da [especificação](14-hardware-placa-nova.md): pinos, tensões, componentes externos, altura, driver e firmware). Onde uma peça falhou, a lista já traz a substituta, e a especificação, a [avaliação](15-avaliacao-componentes.md) e a [arquitetura do firmware](16-arquitetura-firmware.md) seguem as correções.

> [!IMPORTANT]
> Estoque e preço são da DigiKey em 2026-09-18, em US$ por unidade para 1 e 10 peças, e mudam rápido: confira no dia do pedido. A Mouser bloqueia acesso automático, então **nenhum dado da Mouser foi conferido**. Nenhuma peça foi montada nem medida: a validação é sobre datasheets, desenhos e o código do NCS v3.3.0.

> [!NOTE]
> **A tela mudou em 2026-09-23, por decisão do dono:** entra o **JDI
> LPM027M128C**, peça única de 2,7", 400 × 240, MIP de 8 cores e **com luz
> frontal integrada**, e saem do pedido a Sharp LS027B7DH01A, o filme Azumo
> 11103-06_A1, o conector dele (Molex 5034800440) e o REG710NA-5/3K dos 5 V.
> A Sharp com o filme continua na lista como **plano B**, no mesmo conector.
> Custo: **+US$ 54 na tela** e cerca de **+US$ 52 na placa** ([Custo](#custo)),
> **sem canal autorizado de compra e sem garantia** ([Display](#display)).

**Nesta página:** [Como a lista foi validada](#como-a-lista-foi-validada) · [Resultado](#resultado) · [Trocas](#trocas) · [Correções de integração](#correções-de-integração) · [Lista por bloco](#lista-por-bloco) · [Passivos](#passivos) · [Placas de avaliação e ferramentas](#placas-de-avaliação-e-ferramentas) · [Custo](#custo) · [Compras fora da DigiKey](#compras-fora-da-digikey) · [Antes de fechar o pedido](#antes-de-fechar-o-pedido) · [Referências](#referências)

## Como a lista foi validada

```mermaid
flowchart LR
    P["peça da avaliação"] --> C{"passagem 1 · compra<br/>PN, estoque, preço,<br/>ciclo de vida"}
    C -->|"falha"| S["substituta<br/>com estoque"]
    S --> C
    C -->|"passa"| I{"passagem 2 · integração<br/>pinos, tensões, externos,<br/>altura, driver"}
    I -->|"falha"| F["correção do circuito<br/>ou troca da peça"]
    F --> I
    I -->|"passa"| L["lista de compras"]
```

- **Passagem 1, compra:** o PN que se encomenda, a página da DigiKey (estoque, preço, situação, prazo de fábrica) e, quando a DigiKey não vende, a página do fabricante ou de outro distribuidor. Passa a peça ativa, com ficha pública e estoque que cubra 5 placas.
- **Passagem 2, integração:** a peça contra o circuito, pino a pino com a ficha; os máximos absolutos contra os trilhos; os componentes externos que a ficha exige; a altura contra o [empilhamento](14-hardware-placa-nova.md#empilhamento-mecânico); o driver no NCS v3.3.0 local; e o que o firmware precisa fazer.
- **Protótipo:** 5 placas. Os CIs têm uma peça de reserva; os passivos saem em múltiplos de 10.

## Resultado

| Bloco | Peças conferidas | Trocadas na compra | Correções de integração |
|---|---|---|---|
| MCU e rádio | 1 | — | tamanho real do módulo, regras da antena, refusões |
| Energia | 14 | NTC, conector da bateria | trilhos dos bucks, pinos do AEM10900, indutor, configuração do MAX17262, luz pela LDSW2 |
| GNSS | 6 | módulo, do MAX-M10N-10B para o MAX-F10S | V_IO travado em 1,8 V, 0 dBm no RF_IN sem exceção fora da banda |
| Sensores | 5 | IMU, magnetômetro | pinos comuns do IMU, CSB do barômetro, nada de varredura no I2C |
| Display | 7 | tela, conectores, REG710 — e a tela **de volta ao JDI** em 2026-09-23 | tela de 8 cores com luz integrada em 3,0 V; o REG710 e os 5 V saíram da montagem |
| Armazenamento | 2 | preço e estoque da NOR ainda não conferidos | MX25R6435F de 8 MB, pull-ups de WP e HOLD, pinos com o trilho desligado |
| USB | 4 | TVS do VBUS, receptáculo | placa de 0,8 mm |
| Interface | 4 | botões sem vedação | LEDs no VSYS, buzzer em alta corrente |
| Passivos | 18 | três capacitores sem estoque ou obsoletos | capacitância efetiva pelo DC bias |

Todas as peças passam na integração, com as ressalvas de cada linha. Na compra ficam **três** pendências: o BM20C, sem estoque hoje, com 1.000 previstos para 12/11/2026 na DigiKey e venda direta pela Fanstel, prazo que cabe no tempo do layout, com o plano B na linha dele; o AEM10900, que a DigiKey não vende e que só a Mouser, não conferida, ou a e-peas fornecem; e, desde 2026-09-23, **o JDI LPM027M128C**, que **nenhum distribuidor autorizado vende** e que a decisão do dono aceita comprar de revendedor, sem garantia. Cinco compras saem da DigiKey: o AEM10900, a flash NOR, a bateria, a ferramenta da Tag-Connect e a tela ([Compras fora da DigiKey](#compras-fora-da-digikey)).

## Trocas

| Peça da avaliação | Problema | Substituta | Consequência |
|---|---|---|---|
| ~~JDI LPM027M128C (tela de 8 cores)~~ | nenhum canal autorizado: a DigiKey não tem a peça e marca como obsoletos os módulos da Azumo com ela; a Switch Science encerrou as vendas; a Data Modul não lista JDI; o site da JDI não tem mais MIP | ~~Sharp **LS027B7DH01A** com o filme de luz frontal **Azumo 11103-06_A1**~~ | **Troca desfeita em 2026-09-23**, por decisão do dono: volta o JDI LPM027M128C, e o risco de compra é aceito. O par Sharp + Azumo vira o plano B, no mesmo conector ([Display](#display)) |
| Sharp LS027B7DH01 | sem estoque (400 previstos para 10/11/2026) | Sharp LS027B7DH01A | mesma pinagem; polarizador novo e 1,625 mm de espessura |
| SMK CFP-4610-0150F e Molex 51441-1093 (conectores da ficha antiga da Sharp) | o primeiro sem venda encontrada, o segundo obsoleto | Hirose FH28-10S-0.5SH(05) | as fichas do JDI e da Sharp atual citam o FH28, com contato por baixo |
| TI REG710NA-5/250 | sem estoque | TI REG710NA-5/3K | a mesma peça em rolo maior, vendida em fita cortada |
| ST LSM6DSV16X | sem estoque, como todas as IMUs da ST na DigiKey | Bosch BMI270 no mesmo footprint | sem a fusão interna (vetor de gravidade); driver `bosch,bmi270` |
| ST LIS2MDL | sem estoque | Memsic MMC5633NJL | WLP de 0,85 mm; driver `memsic,mmc56x3`; o barramento não pode ser varrido |
| Murata NCP15XH103J03RC | não recomendado para projetos novos | TDK NTCG103JF103FT1 | o mesmo B3380 e 10 kΩ ±1 % |
| TI ESD751DYAR | sem estoque até 27/11/2026 | TI ESD761DPYR | a mesma família em X1SON de 1,0 × 0,6 mm |
| JST SH de 4 vias | 1 A por contato e trava por atrito | JST GH de 6 vias | VBAT e GND em dois contatos; trava positiva; 4,25 mm de altura |
| JST GH de 6 vias (SM06B-GHS-TB) | 4,25 mm de altura: a caixa desenhada em 2026-09-26 deixa 4,2 mm entre a face da placa e a tampa fora do display, e no verso a faixa livre não o segura ([04](../hardware_gnssbike/04-pcb-e-caixa.md#a-placa-de-hoje-dentro-da-caixa-do-conceito)) | JST SH de 6 vias (SM06B-SRSS-TB, 2,9 mm), carcaça SHR-06V-S-B e terminais SSH-003T-P0.2 | volta a trava por atrito: o cabo da célula é preso à caixa com fita. A alternativa é a caixa 0,5 mm mais alta com o GH; **decisão do dono** |
| Indutor de 6,8 µH do AEM10900 | a tabela 6 da ficha dá 65,5 mA de entrada, abaixo dos 88 mA do painel ao meio-dia | TDK VLS252012HBX-4R7M-1 (4,7 µH) | de 95 a 123 mA; o de 6,8 µH vai para a bancada |
| Amphenol 12402484E512A | o desenho não abriu (403): o anel de vedação incluso não foi confirmado | Molex 2036150003 | o desenho confirma o anel e o IPX8; pede placa de 0,8 mm |
| Chaves táteis comuns (E-Switch TL3340, Panasonic EVP-AA, Omron B3FS) | sem grau IP | Omron B3S-1002P | IP67 pela ficha; a E-Switch TL3780AF240QG, IP67 e mais baixa, fica de alternativa |
| Tag-Connect TC2030-IDC-NL | termina num conector IDC de 6 vias com passo de 0,1", e não no conector Cortex do J-Link | TC2030-CTX-NL e TC2030-CLIP | conector Cortex de 10 vias do J-Link |
| Molex 503480-0400 (sugerido pela Azumo para o filme) | obsoleto | Molex 5034800440 | — |
| Murata GRM188R61E106KA73D, GRM158R60J226ME01D e GRM155R61A105KE15D | os dois primeiros sem estoque, o terceiro obsoleto | ver [Passivos](#passivos) | — |

## Correções de integração

Achados da segunda passagem que mudam o circuito ou o firmware. A especificação já traz todos; as ligações fixas de cada CI estão em [14](14-hardware-placa-nova.md#ligações-fixas-dos-cis).

1. **Trilhos dos bucks trocados.** O resistor do VSET1 só escolhe de 1,0 a 2,7 V e o do VSET2, de 1,8 a 3,3 V (tabelas 18 e 19 do nPM1300): o 3,0 V, de que o MCU depende para ligar, só sai do BUCK2. Fica BUCK2 em 3,0 V com 150 kΩ e BUCK1 em 1,8 V com 47 kΩ, a mesma configuração 1 da referência da Nordic (tabela 39). Nenhum VSET pode ficar aberto.
2. **1V8 travado — superado em 2026-09-26.** Com o VIO_SEL em GND, o V_IO do MAX-F10S tem máximo absoluto de 1,98 V (tabela 12 da UBXDOC-963802114-12732 R03, igual à do M10N-10B), e o registrador do BUCK1 aceita até 3,3 V: o devicetree fixava o mínimo e o máximo do BUCK1 em 1,8 V. Desde 2026-09-26 o receptor está no 3V0 com o VIO_SEL **aberto** (opção 1 da tabela 35 do manual de integração), o BUCK1 ficou sem carga e o tradutor de nível saiu ([hardware_gnssbike/02](../hardware_gnssbike/02-calculos.md#o-receptor-no-3v0-e-o-1v8-sem-carga)).
3. **Luz da tela pela LDSW2.** A LDSW2 do nPM1300 vira LDO de 3,3 V alimentado pelo VSYS (até 50 mA, entrada de 2,6 V ao VSYS), com resistor e N-MOSFET no PWM. O 3,0 V deixaria só 0,33 V para o resistor do LED de 2,67 V do JDI.
4. **Pinos do AEM10900:** STO_CFG[2] e STO_CFG[0] no VINT e STO_CFG[1] no GND (carga até 3,90 V, corte em 3,01 V); R_MPP[2:0] e T_MPP[1:0] no VINT; KEEP_ALIVE no VINT; I2C_ADDR no I2C_VDD (0x41); DIS_STO_CH pelo divisor de 100 kΩ e 1 MΩ do VBUSOUT.
5. **Indutor do AEM10900 em 4,7 µH.** A tabela 6 e a fórmula da seção 6.7.2 da ficha discordam (65,5 contra 85 mA com 6,8 µH); a pergunta vai para a e-peas, e a bancada compara 4,7 e 6,8 µH.
6. **MAX17262:** a configuração de fábrica (0x2210) já deixa o COMMSH e o THSH em 0; com o TH ligado ao BATT, o firmware grava ETHRM = 0 e mantém TSel = 0 (temperatura interna).
7. **Botão de ligar:** só o botão central vai ao SHPHLD, que tem pull-up interno de 50 kΩ; o nPM1300 avisa o MCU pelo GPIO3 (`NPM13XX_EVENT_SHIPHOLD_PRESS` e `RELEASE`). Segurar mais de 10 s religa o sistema inteiro, recurso ligado de fábrica que serve de reset de emergência.
8. **BM20C:** 10,0 × 16,2 mm, e não 14,8 mm; os últimos 5,5 mm são a área da antena, que fica fora da placa ou sem terra e sem trilhas em todas as camadas, com o módulo na borda. No máximo duas passagens pelo forno, com o lado do módulo por último. USB em G6 (D−), G7 (D+) e H7 (VBUS de 4,4 a 5,5 V). A ficha não dá a tolerância do cristal de 32,768 kHz, que o ANT pede em ±50 ppm.
9. **Entrada de RF do GNSS:** a tabela 12 da ficha do **MAX-F10S** dá um único máximo absoluto de **0 dBm** no RF_IN, sem a exceção de +15 dBm fora da banda que a ficha do 10B traz. Com o BLE a +8 dBm na mesma placa, quem segura o nível é o isolamento entre as antenas: meça o S21 em 2,44 GHz antes de ligar o rádio na potência cheia, e o bloqueio pelo C/N0 com o rádio transmitindo ([14](14-hardware-placa-nova.md#gnss)).
10. **IMU com dois fabricantes no mesmo footprint:** pinos 2 e 3 no VDDIO (a Bosch proíbe GND), 10 e 11 abertos, 12 no VDDIO, 1 no GND; o BMI270 responde em 0x68 e o LSM6DSV16X, em 0x6A. O devicetree declara os dois, e o firmware usa o que responder. O despertar por movimento do BMI270 pede a configuração `base` do driver (8 KB, com o compatível extra `bosch,bmi270-base`), sem exemplo no NCS: a testar.
11. **MMC5633NJL:** o endereço 0x7E no barramento o põe em I3C até faltar energia, então o firmware nunca varre o I2C; o VDD pede pelo menos 2,2 µF junto do pino. O ID 0x10 e o mapa de registradores conferem com o driver `memsic,mmc56x3`.
12. **BMP585:** o CSB precisa estar no VDDIO na partida, ou o I2C fica desligado até o próximo reset de energia; o SDO no VDDIO dá o endereço 0x47.
13. **Flash NOR soldada:** o SD NAND XTX saiu em 2026-09-20 e no lugar dele vai a Macronix **MX25R6435F** de 64 Mbit (8 Mbyte), a mesma peça do nRF54LM20 DK, sozinha no `spi00` com CS em P2.05 e `spi-max-frequency = 8000000`. Ela entra no devicetree como `jedec,spi-nor`, e uma partição que toma a peça inteira vira disco por `zephyr,flash-disk`, montado em `/SD:` com FatFs (`CONFIG_DISK_DRIVER_FLASH=y` e `CONFIG_DISK_DRIVER_SDMMC=n`); **não há cartão nem SD NAND na placa**. WP e HOLD levam pull-up; com o trilho da flash desligado, os pinos do `spi00` ficam em nível baixo ou em alta impedância, para não alimentar o chip pelos pinos. Nada disso foi testado em placa.
14. **USB-C da Molex:** o desenho recomenda placa de 0,8 mm, e a especificação passa de 1,0 para 0,8 mm; o anel de vedação passa da borda da placa (a borda fica 2,73 mm atrás da frente do conector); furo de 9,54 × 3,76 mm numa parede de pelo menos 1,2 mm.
15. **Tela.** Com o **JDI LPM027M128C**, decidido em 2026-09-23: VDD e VDDA em 3,0 V do BUCK2 (máximo absoluto de 3,6 V), EXTMODE no VDD da tela, luz de 16 mA a 2,67 V com o resistor de 39 Ω pela LDSW2, e **o REG710 e o trilho de 5 V deixam de ser montados** — com eles o `DISP_PWR_EN` (P3.07) volta a ficar livre. **Falta uma coisa que nenhum documento do projeto tem:** o FPC de 10 vias não traz par para o LED, de modo que **não se sabe por onde a luz do C se liga**; sai da ficha do C ou de uma amostra, **antes do layout**. No **plano B**, com a Sharp: 5 V do REG710 com o EN num pino do MCU, para a sequência de ligar e para cortar os 65 µA do conversor; entradas com VIH a partir de 2,7 V, que a lógica de 3,0 V atende; e o filme de luz com um LED de 10 mA típicos (25 mA no máximo), no Molex 5034800440.
16. **TPS7A02:** pelo menos 0,5 µF efetivos na saída, EN ligado ao IN.
17. **Capacitância efetiva:** pelas curvas da Taiyo Yuden, o 10 µF de 25 V em 0603 fica com cerca de 4,9 µF a 5 V e 7,2 µF a 3 V, e o 22 µF de 10 V, com cerca de 9,0 µF a 4 V, acima dos 5 µF efetivos que o AEM10900 pede no STO.
18. **LEDs e buzzer:** o LED RGB tem anodo comum no VSYS e um N-MOSFET por cor, porque um pino do MCU em 3,0 V não segura um catodo cujo anodo vai a até 5,5 V (com o USB, o VSYS acompanha o VBUS); o brilho varia com a tensão do VSYS. O buzzer usa dois pinos em alta corrente.

## Lista por bloco

Colunas: função, peça, código da DigiKey, estoque, preço em US$ para 1 e 10 peças, quantidade por placa, compra sugerida para 5 placas e situação depois das duas passagens.

### MCU e rádio

| Função | Peça | DigiKey | Estoque | US$ 1 / 10 | Por placa | Compra | Situação |
|---|---|---|---|---|---|---|---|
| Módulo com o nRF54LM20A | Fanstel BM20C | 1914-BM20CCT-ND | 0; 1.000 previstos para 12/11/2026 | 11,47 / 9,96 | 1 | 6 | aprovada com ressalva: sem estoque até novembro (a Fanstel vende por e-mail a US$ 6,50); tolerância do cristal de 32,768 kHz a confirmar |

Plano B, se o BM20C atrasar: MinewSemi ME54BS13-1Y20TI (6024-ME54BS13-1Y20TITR-ND, 50 peças no Marketplace da DigiKey, US$ 9,00), com o nRF54LM20A, antena de PCB e 16,5 × 12,0 × 2,4 mm. O footprint é outro e a ficha (V0.5.0) não traz certificação.

### Energia

| Função | Peça | DigiKey | Estoque | US$ 1 / 10 | Por placa | Compra | Situação |
|---|---|---|---|---|---|---|---|
| PMIC | Nordic nPM1300-QEAA-R (QFN32) | 4823-NPM1300-QEAA-RCT-ND | 10.710 | 2,95 / 2,21 | 1 | 6 | aprovada; o rolo de 7" (-R7) está sem estoque |
| Indutores dos bucks | Murata DFE201610E-2R2M=P2 | 490-17728-1-ND | 90.749 | 0,25 / 0,206 | 2 | 12 | aprovada; 140 mΩ, 2,4 A; alternativa TDK TFM201610ALM-2R2MTAA (445-174186-1-ND, 54.319) |
| Carregador solar | e-peas AEM10900 (10AEM10900C0002, QFN28) | não vende | — | — | 1 | 6 | fora da DigiKey: Mouser (não conferida) ou e-peas |
| Indutor do AEM10900 | TDK VLS252012HBX-4R7M-1 | 445-173029-1-ND | 897 | 0,25 / — | 1 | 6 | aprovada; 1,4 A de saturação, 240 mΩ |
| Indutor de comparação | TDK VLS252012HBX-6R8M-1 | 445-173030-1-ND | 4.174 | 0,25 / 0,206 | — | 3 | para a bancada |
| Medidor de carga | Analog Devices MAX17262REWL+T | 175-MAX17262REWL+TCT-ND | 20.109 | 4,10 / 3,10 | 1 | 6 | aprovada; WLP, montagem por estêncil e forno |
| LDO do backup do GNSS | TI TPS7A0218PDQNR | 296-TPS7A0218PDQNRCT-ND | 5.793 | 0,84 / 0,601 | 1 | 6 | aprovada |
| NTC do AEM10900 | TDK NTCG103JF103FT1 | 445-2550-1-ND | 1.668.979 | 0,11 / 0,075 | 1 | 10 | aprovada; na face de trás, sob a célula |
| Painéis solares | ANYSOLAR KXOB25-05X3F-TR | KXOB25-05X3FCT-ND | 5.038 | 3,23 / 2,64 | 6 | 36 | aprovada |
| Grampo da entrada solar (`D105`) | Nexperia PESD3V3S1UB-N | — | LCSC C920299: 14.270 | 0,023 | 1 | 10 | **escolhido em 2026-09-25**: ESD unidirecional 3,3 V em SOD-523, 1 µA de fuga máx., grampeia polaridade trocada em −0,7 V; não protege de fonte errada sustentada |
| Conector do painel | JST S4B-ZR-SM4A-TF | — | — | — | 1 | 6 | **a conferir na LCSC**; ZH de 1,5 mm, 4 vias, SMD lateral ([J103](../hardware_gnssbike/06-conectores-e-pontos-de-teste.md#j103--painel-solar)) |
| Carcaça do cabo do painel | JST ZHR-4 | — | — | — | 1 | 6 | **faltava na lista**; a contraparte do `J103` |
| Terminais do cabo do painel | JST SZH-002T-P0.5 | — | — | — | 4 | 50 | **faltava na lista**; AWG 32 a 28, crimpagem com o alicate da JST |
| Fio do chicote do painel | AWG 28 flexível, siliconado, 4 cores | — | — | — | ~1 m | 10 m | **faltava na lista**; 110 mA no arranjo inteiro, 37 mA por face |
| LED de carga | Kingbright APT1608SURCK | 754-1123-1-ND | 1.084.493 | 0,21 / 0,144 | 1 | 10 | aprovada; 1,82 V a 5 mA, no LED1 do nPM1300 |
| Conector da bateria | JST SM06B-GHS-TB | 455-1568-1-ND | 34.778 | 0,49 / 0,42 | 1 | 6 | aprovada |
| Carcaça do cabo | JST GHR-06V-S | 455-1596-ND | 67.681 | 0,16 / 0,136 | 1 | 6 | aprovada |
| Terminais do cabo | JST SSHL-002T-P0.2 | 455-1606-500-ND | 3.500 | fita de 500 a 0,0715 | 6 | 500 | a crimpagem pede o alicate da JST |
| Bateria | LiPo de 1 célula, 2000 mAh, 60 × 36 × 7 mm, com PCM e NTC de 10 kΩ B3380 | — | — | — | 1 | 6 | sob encomenda a um fabricante de packs, com UN38.3 |

### GNSS

| Função | Peça | DigiKey | Estoque | US$ 1 / 10 | Por placa | Compra | Situação |
|---|---|---|---|---|---|---|---|
| Módulo GNSS | u-blox MAX-F10S-00B | 672-MAX-F10S-00BCT-ND | 10.818 | 13,14 / — | 1 | 6 | aprovada; L1 + L5; MSL 4: secar antes do forno se a embalagem ficou aberta |
| Módulo do teste A/B | u-blox MAX-M10N-10B | 672-MAX-M10N-10BCT-ND | 1.571 | 14,52 / — | — | 2 | mesmo footprint; a alternativa econômica, só L1 |
| ~~Tradutor de nível~~ | ~~TI TXU0204BQAR~~ | 296-TXU0204BQARCT-ND | 3.776 | 1,17 / 0,846 | **0** | **0** | **saiu em 2026-09-26**: o receptor passou a 3,0 V, no trilho do MCU; não comprar |
| Antena | TE L000670-01 | 343-L000670-01CT-ND | 2.738 | 1,50 / — | 1 | 6 | aprovada; com o F10S a sintonia tem de fechar **L1 e L5** na mesma rede em π, e não só L1: a TE mede com 0 Ω em série e paralelos vazios, e a sintonia na caixa escolhe os valores |
| Ferrite do 1V8 | Murata BLM18KG601SN1D | — | LCSC C85833: 371.955 | 0,019 | 1 | 10 | **trocada em 2026-09-25**: 600 Ω a 100 MHz, 1,3 A, **DCR 150 mΩ** (a BLM15PX601SN1D de 0402 tinha 230 mΩ, acima dos 0,2 Ω que o manual do MAX-F10S, 4.1.1, permite em série no VCC); 0603 |
| Sintonia da antena | Murata GJM1555C1H2R2BB01D (2,2 pF C0G) e LQW15AN3N9C00D (3,9 nH) | — | 86.930 e 60.715 | 0,11 / 0,057 e 0,11 / — | — | 10 de cada | valores de partida para a rede em π; o VNA decide os valores finais |
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

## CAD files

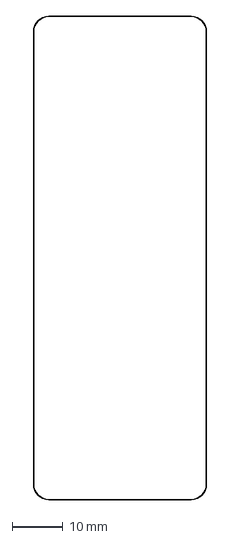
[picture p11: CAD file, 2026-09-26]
hardware_gnssbike/cad/contorno-r3.dxf
34.0 x 95.0 mm

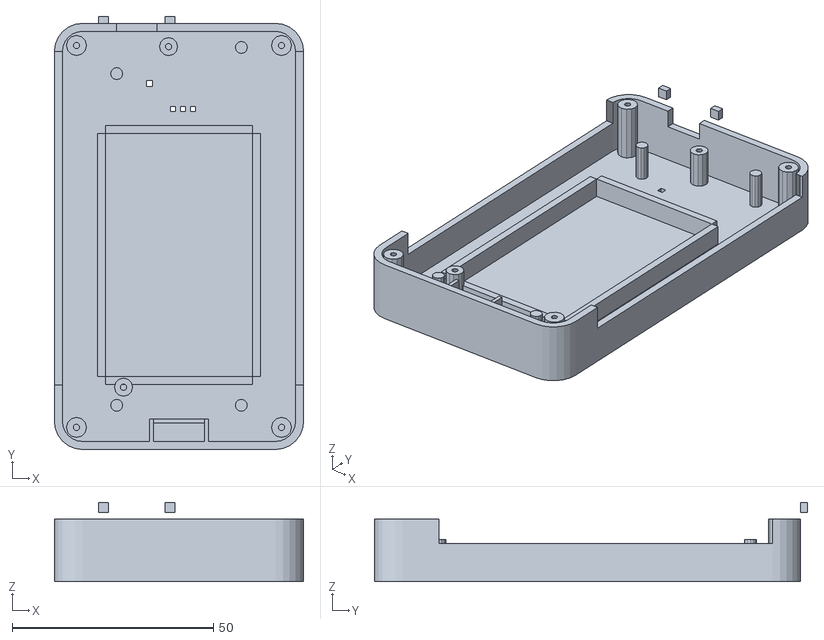
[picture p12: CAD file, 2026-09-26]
hardware_gnssbike/caixa/caixa-concha.stl
62.0 x 107.7 x 19.7

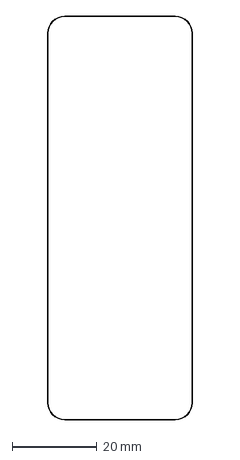
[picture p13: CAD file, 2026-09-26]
hardware_gnssbike/cad/contorno-r4.dxf
34.0 x 95.0 mm

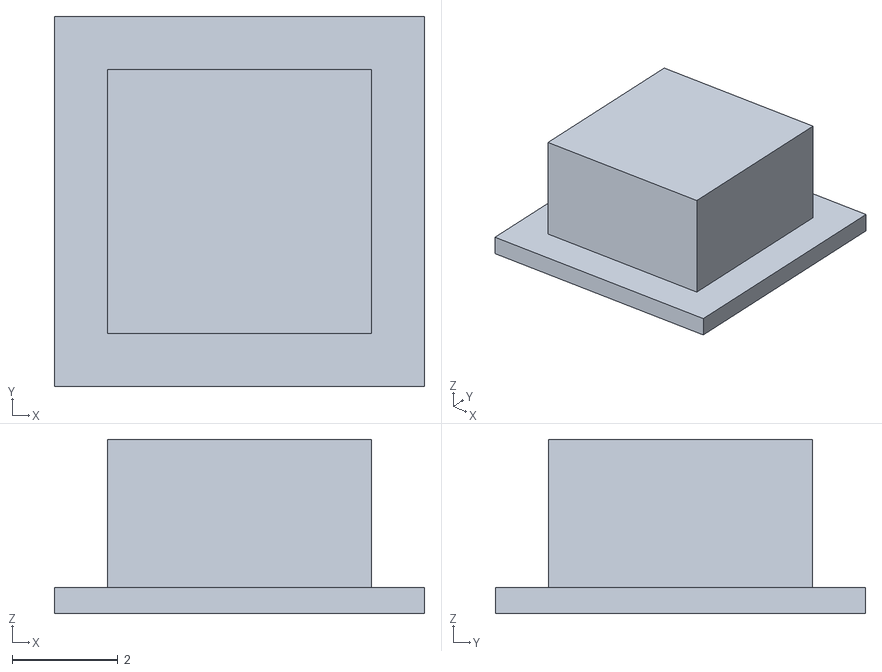
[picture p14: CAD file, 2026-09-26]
hardware_gnssbike/caixa/caixa-tecla-1.stl
7.00 x 7.00 x 3.30

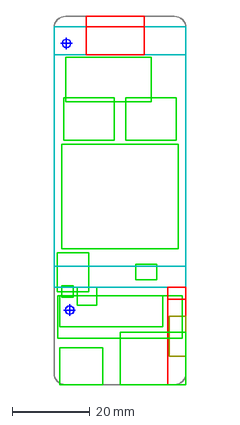
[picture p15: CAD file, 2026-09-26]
hardware_gnssbike/cad/zonas.dxf
34.0 x 95.0 mm

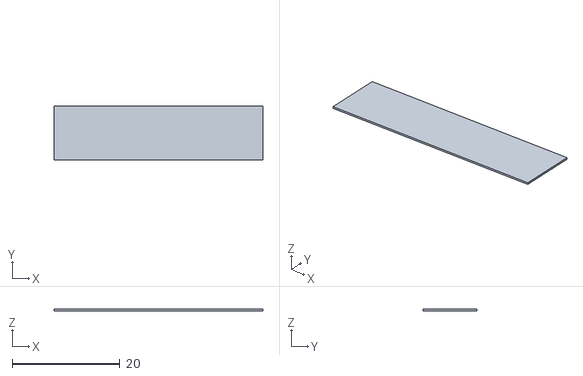
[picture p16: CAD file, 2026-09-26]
hardware_gnssbike/caixa/caixa-membrana-teclas.stl
38.8 x 10.0 x 0.3

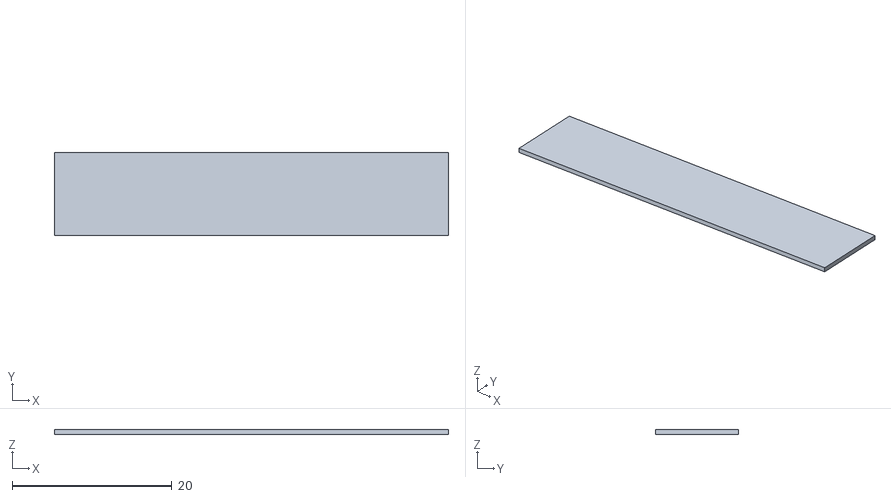
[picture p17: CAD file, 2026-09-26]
hardware_gnssbike/caixa/caixa-cobertura-faceta.stl
49.4 x 10.4 x 0.6

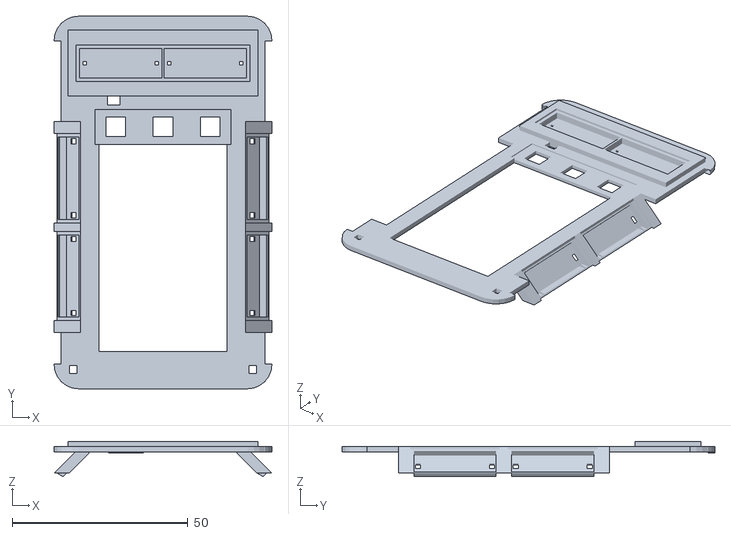
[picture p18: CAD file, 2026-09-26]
hardware_gnssbike/caixa/caixa-tampa.stl
62.0 x 106.0 x 9.99

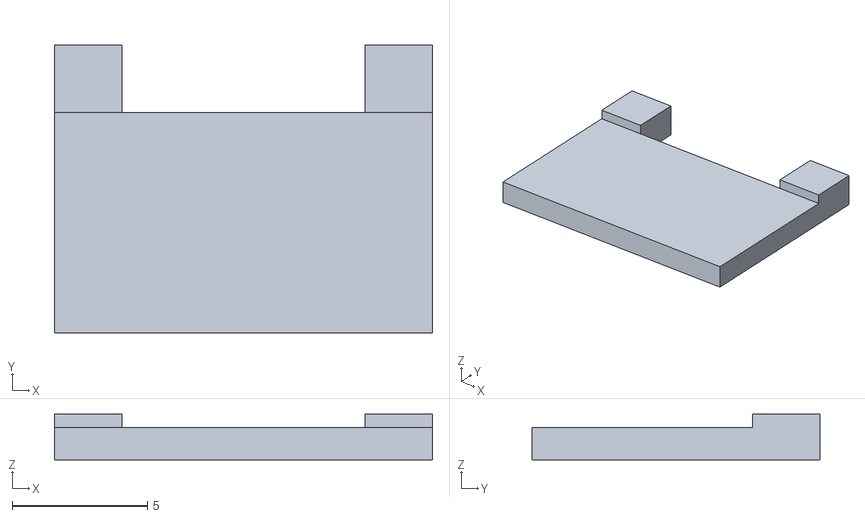
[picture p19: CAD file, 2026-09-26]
hardware_gnssbike/caixa/caixa-porta-usb.stl
14.0 x 10.7 x 1.70

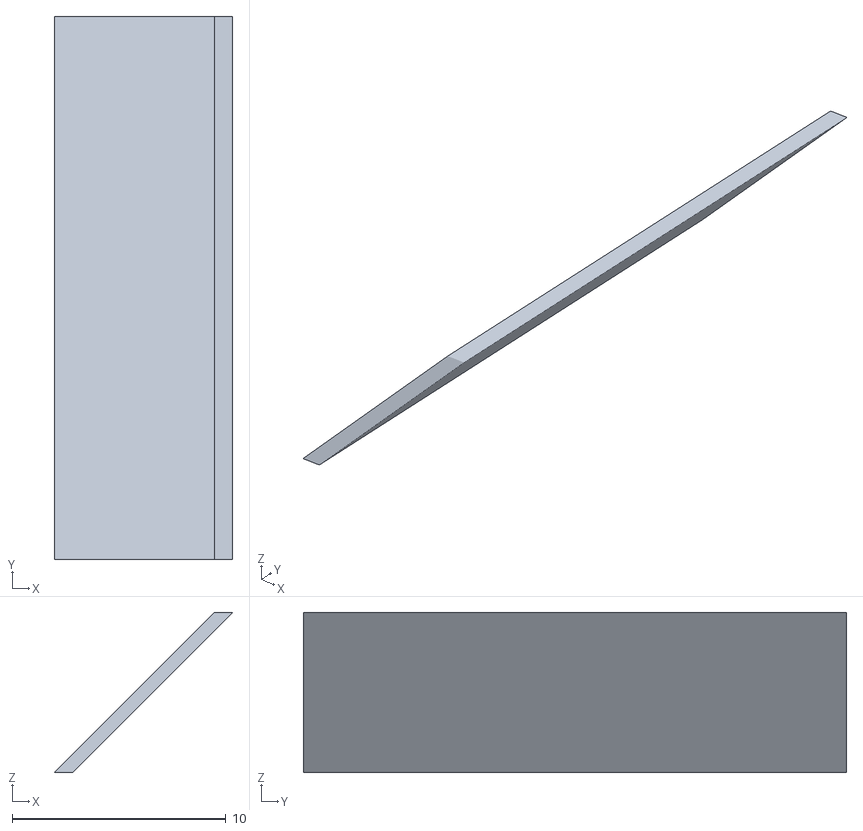
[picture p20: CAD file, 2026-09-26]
hardware_gnssbike/caixa/caixa-cobertura-chanfro.stl
8.35 x 25.4 x 7.50

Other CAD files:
hardware_gnssbike/caixa/caixa-tecla-3.stl
hardware_gnssbike/caixa/caixa-tecla-2.stl

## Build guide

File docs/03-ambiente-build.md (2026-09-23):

# Ambiente, build, gravação e console

Como montar o ambiente do nRF Connect SDK no Windows, compilar o port Zephyr, gravar o DK, ver o log, rodar os testes de host e validar a documentação. Tudo aqui foi executado nesta máquina em 2026-09-18, salvo onde está dito o contrário.

**Nesta página:** [Ferramentas](#ferramentas) · [Scripts](#scripts) · [Build do firmware](#build-do-firmware) · [Gravar e ver o log](#gravar-e-ver-o-log) · [Testes e análise estática](#testes-e-análise-estática) · [Documentação](#documentação) · [CI](#ci) · [Legacy](#legacy) · [Problemas conhecidos](#problemas-conhecidos)

## Ferramentas

| Ferramenta | Versão | Onde | Uso |
|---|---|---|---|
| nRF Connect SDK | v3.3.0 (Zephyr 4.3.99) | `C:\ncs\v3.3.0` | firmware |
| Toolchain do NCS | `936afb6332`: Zephyr SDK 0.17.0, GCC 12.2.0, CMake 4.2.1, Ninja, west 1.5.0, Python 3.12.4, dtc 1.4.7 | `C:\ncs\toolchains\936afb6332` | firmware |
| nrfutil | 8.1.1 com o comando `device` 2.17.5 | no toolchain (`nrfutil\bin`) | gravar, recover, listar placas |
| SEGGER J-Link | V8.76, V8.96, V9.24a | `C:\Program Files\SEGGER` | driver do J-Link OB do DK |
| MinGW-w64 GCC | 15.2.0 (com gcov) | `C:\ProgramData\mingw64\mingw64\bin` | testes de host |
| CMake / Ninja | 4.1.2 / 1.13 | `C:\Program Files\CMake`, pip do Python 3.11 | testes de host |
| cppcheck | 2.20.0 | scoop | análise estática |
| clang-format / clang-tidy | LLVM do scoop | scoop | formatação e lint (sem configuração no projeto ainda) |
| Node.js | 22.18.0 | `C:\Program Files\nodejs` | mermaid-cli (cache do npx) e `tools/zpm` |
| Python | 3.11.9 | usuário | scripts de documentação |

O NCS v3.1.0 e o toolchain `b8b84efebd`, usados até dezembro de 2025, **não existem mais** nesta máquina. Os builds gerados com eles, em outras pastas (`C:\Users\...\Documents\88.Personal\1.Projects\gnss-bike-computer` e `...\stravaV10`), foram apagados em 2026-09-18.

## Scripts

```mermaid
flowchart LR
    subgraph CMD["cmd / duplo clique"]
        BUILD["build.bat [pristine]"]
        BNCS["build_ncs.bat"]
        FLASH["flash.bat [keep]"]
        REC["recover.bat"]
        SER["serial.bat [COMx] [baud]"]
    end
    subgraph BASH["Git Bash"]
        FW["tools/fw/fw.sh build · flash · recover · devices · size"]
        HT["tools/fw/host_tests.sh"]
        BC["tools/fw/board_check.py"]
        MC["tools/docs/mermaid_check.py"]
        LC["tools/docs/links_check.py"]
    end
    BUILD --> ENVB["tools/fw/ncs_env.bat"]
    BNCS --> BUILD
    FLASH --> ENVB
    REC --> ENVB
    SER --> ENVB
    FW --> ENVS["tools/fw/ncs_env.sh"]
```

| Variável | Onde vale | Efeito |
|---|---|---|
| `NCS_ROOT`, `NCS_VERSION`, `NCS_TOOLCHAIN` | `ncs_env.*` | trocam o SDK (padrão `C:\ncs`, `v3.3.0`, `936afb6332`; o `.sh` descobre o toolchain pelo `toolchains.json`) |
| `BUILD_DIR` | `build.bat`, `flash.bat`, `fw.sh` | outra pasta de build (padrão `zephyr_app/build`); relativa, vale a partir da pasta atual |
| `BOARD` | `build.bat`, `flash.bat`, `recover.bat`, `fw.sh` | outro alvo. Os padrões **não são os mesmos**: no `fw.sh` é `nrf54lm20dk/nrf54lm20a/cpuapp` (`tools/fw/fw.sh:33`), nos `.bat` ainda é `nrf52840dk/nrf52840` (`build.bat:27`, `flash.bat:32`, `recover.bat:16`). A placa do projeto é `gnssbike/nrf54lm20a/cpuapp`; o overlay `zephyr_app/boards/<placa>.overlay` entra pelo nome |
| `ANT` | `build.bat`, `fw.sh` | `1` compila com o ANT: o add-on `sdk-ant` em `SDK_ANT_DIR`, `zephyr_app/modules/ant_ncs33_compat` e `zephyr_app/ant.conf`; ao trocar, use `pristine` ou outra `BUILD_DIR` |
| `SDK_ANT_DIR` | `build.bat`, `fw.sh` | pasta do add-on (padrão `C:\ncs\sdk-ant`) |
| `FAMILY` | `flash.bat`, `recover.bat`, `fw.sh` | família do `nrfutil`; sem ela, vem da `BOARD` (`nrf54l` para as placas nRF54L, `nrf52` no resto) |
| `NRF_SERIAL` | `flash.bat`, `recover.bat`, `fw.sh` | escolhe o J-Link pelo número de série |
| `SERIAL_PORT` | `serial.bat` | porta padrão do console (padrão `COM11`) |
| `NOPAUSE` | todos os `.bat` | não espera tecla no fim |

Os `ncs_env.*` reproduzem o `environment.json` do toolchain (PATH, `PYTHONPATH`, `NRFUTIL_HOME`, `ZEPHYR_TOOLCHAIN_VARIANT=zephyr`, `ZEPHYR_SDK_INSTALL_DIR`) e definem `ZEPHYR_BASE`. Eles **não** definem `TOOLCHAIN_ROOT` (ver [problemas conhecidos](#problemas-conhecidos)).

## Build do firmware

```sh
bash tools/fw/fw.sh build            # incremental
bash tools/fw/fw.sh build pristine   # do zero
```

Ou `build.bat` / `build.bat pristine` no cmd. Por baixo (`tools/fw/fw.sh:97-100`):

```sh
source tools/fw/ncs_env.sh
cd zephyr_app
python -m west build -p auto -b nrf54lm20dk/nrf54lm20a/cpuapp -d build --sysbuild . \
  -- -DBOARD_ROOT=<caminho do zephyr_app> -Dmcuboot_BOARD_ROOT=<caminho do zephyr_app>
```

- **Alvo padrão:** `nrf54lm20dk/nrf54lm20a/cpuapp`, com `boards/nrf54lm20dk_nrf54lm20a_cpuapp.overlay` (pinos no conector de expansão do DK) e `boards/nrf54lm20dk_nrf54lm20a_cpuapp.conf` (configurações no ZMS), que o Zephyr aplica pelo nome da placa. Detalhes em [05](05-arquitetura-zephyr.md#devicetree-e-alvos).
- **Placa do projeto:** `BOARD=gnssbike/nrf54lm20a/cpuapp BUILD_DIR=zephyr_app/build_custom bash tools/fw/fw.sh build`. A board mora em `zephyr_app/boards/gnss/gnssbike/`, fora do caminho padrão do Zephyr: quem a encontra são os `-DBOARD_ROOT` e `-Dmcuboot_BOARD_ROOT` que o `fw.sh` passa, o segundo porque o sysbuild constrói o MCUboot à parte. **Não existe placa física:** por enquanto o alvo só compila.
- **nRF52840 DK:** `BOARD=nrf52840dk/nrf52840 bash tools/fw/fw.sh build` ainda compila, com os pinos da myStravaB em `zephyr_app/boards/nrf52840dk_nrf52840.overlay`, mas o alvo **saiu de uso**. Nos `.bat` ele continua sendo o padrão, então ali o alvo do projeto pede `set BOARD=nrf54lm20dk/nrf54lm20a/cpuapp`.
- **ANT:** `ANT=1 bash tools/fw/fw.sh build pristine` (ou `set ANT=1` antes do `build.bat`). Precisa do add-on em `C:\ncs\sdk-ant` ([07](07-radio-ant-ble.md#ant-no-ncs-v330)); mostra um aviso esperado a mais, `Deprecated symbol SOC_SERIES_NRF54LX is enabled` (ou `SOC_SERIES_NRF52X`).
- **Sysbuild** é o fluxo padrão do NCS. O `zephyr_app/sysbuild.conf` desliga o Partition Manager (`SB_CONFIG_PARTITION_MANAGER=n`), depreciado no NCS 3.3; o layout vem do devicetree. O MCUboot entra só nos alvos com o nRF54LM20A (`zephyr_app/Kconfig.sysbuild`): no nRF52840 não cabem dois slots.
- **Saída:** `zephyr_app/build/zephyr_app/zephyr/zephyr.hex` (e `.elf`, `.map`, `.config`, `zephyr.dts`). Nos alvos com o nRF54LM20A o sysbuild gera também `mcuboot/zephyr/zephyr.hex`, a imagem assinada `zephyr_app/zephyr/zephyr.signed.hex` e o `dfu_application.zip` da atualização por BLE. Não há `merged.hex` em nenhum alvo.

### Mapa de memória

**nRF54LM20A** (nRF54LM20 DK e placa do projeto usam o mesmo layout, o do `nrf54lm20_a_b_cpuapp_partition.dtsi`). Dos 2.036 KB de RRAM, os últimos 96 KB são do FLPR: sobram cerca de 1.940 KB.

| Região | Endereço | Tamanho | Conteúdo |
|---|---|---|---|
| RRAM: `mcuboot` | `0x000000` | 64 KB | gerenciador de boot |
| RRAM: `image-0` (slot0) | `0x010000` | 920 KB | firmware; a imagem cabe em 921.456 B, o resto é o rodapé do MCUboot (`CONFIG_ROM_END_OFFSET=0x5090`) |
| RRAM: `image-1` (slot1) | `0x0F6000` | 920 KB | imagem recebida pela atualização por BLE |
| RRAM: `storage` | `0x1DC000` | 36 KB | settings no ZMS: bonds BLE e configurações do usuário |
| RAM | `0x20000000` | 511 KB | tudo |

**nRF52840 DK**, o alvo fora de uso, sem MCUboot:

| Região | Endereço | Tamanho | Conteúdo |
|---|---|---|---|
| flash: aplicação | `0x00000` | até 992 KB | firmware (`CONFIG_FLASH_LOAD_OFFSET=0`) |
| flash: `storage_partition` | `0xF8000` | 32 KB | settings/NVS: bonds BLE e configurações do usuário |
| RAM | `0x20000000` | 256 KB | tudo |

### Resultado de referência

Build com sysbuild da `develop` em 2026-09-23 (atualizado a cada commit que muda o tamanho):

| Alvo | FLASH | RAM | MCUboot | Avisos |
|---|---|---|---|---|
| `nrf54lm20dk/nrf54lm20a/cpuapp` | 636.144 B (69,04 % dos 921.456 B do slot) | 393.080 B (75,12 % dos 511 KB) | 45.676 B de FLASH, 22.880 B de RAM | 0 |
| `gnssbike/nrf54lm20a/cpuapp` | 636.376 B (69,06 %) | 393.120 B (75,13 %) | 45.880 B de FLASH, 22.888 B de RAM | 0 |

Erros: 0 nos dois alvos.

Medidas antigas, de 2026-09-19, não refeitas desde então:

| Item | Valor |
|---|---|
| Tempo de build | cerca de 1 min do zero (pelos horários dos logs) |
| nRF52840 DK | FLASH 474.268 B (45,23 % de 1 MB), RAM 220.352 B (84,06 % de 256 KB), 0 avisos |
| Com `ANT=1` | nRF52840 DK: FLASH 502.860 B, RAM 225.152 B; nRF54LM20 DK: FLASH 528.172 B, RAM 254.928 B; só o aviso do símbolo obsoleto |

Maiores consumidores de RAM (`bash tools/fw/fw.sh size`): o heap do LVGL 32.768 B (`CONFIG_LV_Z_MEM_POOL_SIZE`), `seg_runtime` 22.000 B, o buffer de desenho do LVGL 19.200 B, o heap do sistema 16.384 B (`CONFIG_HEAP_MEM_POOL_SIZE`), o quadro da tela (12.482 B da Sharp no nRF52840, 36.482 B do JDI no nRF54LM20), `points` 8.000 B, a pilha da thread `ui` (6.144 B), o pool do controlador BLE 5.247 B, as outras pilhas ([05](05-arquitetura-zephyr.md#pilhas)) e quatro cópias do retrato da tela (`ui_model_t`, 2.404 B: a do modelo, a do canal, a da thread `ui` e a da interface).

A interface ocupa no nRF54LM20 DK cerca de 151 KB de flash: LVGL 92.467 B, telas 28.753 B, fontes 26.904 B e o driver da tela 2.972 B ([18](18-interface-telas.md#memória)).

## Gravar e ver o log

```sh
bash tools/fw/fw.sh devices      # precisa aparecer um dispositivo com o trait jlink
bash tools/fw/fw.sh flash        # apaga tudo (ERASE_ALL) e grava
bash tools/fw/fw.sh flash keep   # apaga só as faixas do firmware: mantém a storage_partition
bash tools/fw/fw.sh recover      # chip protegido: apaga tudo e libera o APPROTECT
```

- Os scripts filtram `--traits jlink` e a família do chip (`nrf52`, ou `nrf54l` quando a `BOARD` é uma placa nRF54L): nesta máquina costuma haver um ST-LINK e outras seriais USB conectados.
- **Console:** no nRF54LM20 DK o `zephyr,console` é o `uart20` (TX P1.16, RX P1.17, 115200 baud), exposto pela porta VCOM do J-Link; na placa do projeto é o mesmo `uart20`, em TX P1.00 e RX P1.31; no nRF52840 DK é o `uart0` (TX P0.06, RX P0.08). `serial.bat COMx` abre o miniterm do Python do toolchain (pyserial 3.5); `Ctrl+]` sai. O log usa o backend UART; o RTT está desligado no `prj.conf`.
- Até 2026-09-23 nenhum DK foi conectado a esta máquina: **nada foi gravado nem testado em placa**.

## Testes e análise estática

```sh
bash tools/fw/host_tests.sh             # configura, compila e roda todos
bash tools/fw/host_tests.sh -R segment  # filtra pelo nome
```

Os testes compilam os módulos de lógica de `zephyr_app/src` com o GCC do PC e shims mínimos do Zephyr: 53 conjuntos, 714 casos, todos verdes em 2026-09-23. Detalhes em [12-ferramentas-testes.md](12-ferramentas-testes.md) e na skill `fw-testes`.

```sh
cppcheck --enable=warning,style,performance,portability --std=c11 --inline-suppr --quiet \
  --suppress=missingIncludeSystem --suppress=missingInclude --suppress=unusedFunction \
  -I zephyr_app/include zephyr_app/src
```

Sem os headers do Zephyr, o cppcheck acusa `syntaxError` nas macros de GATT e devicetree (`BT_GATT_*`, `DT_*`): são falsos positivos. Os achados reais estão em [11-qualidade-misra.md](11-qualidade-misra.md).

```sh
python tools/fw/board_check.py                  # a placa do projeto
python tools/fw/board_check.py <pasta-da-placa>  # outra
```

O `board_check.py` lê o devicetree da placa e procura o que o build aceita calado: pino em duas funções, SCL de TWIM ou SCK de SPIM fora dos pinos de clock da tabela 79, pads do NFC (P1.01 e P1.02) sem `nfct-pins-as-gpios`, cristal em P1.20/P1.21, limite de pinos de cada porta, dois periféricos no mesmo bloco serial e apelido que falta. Sai com 1 se achar problema. Em 2026-09-23 a placa do projeto passa: **31 pinos usados de 66**, 31 livres, 12 deles de clock.

## Documentação

```sh
python tools/docs/mermaid_check.py   # extrai, procura diagramas em texto e renderiza cada Mermaid
python tools/docs/links_check.py     # links relativos e âncoras
```

O `mermaid_check.py` usa o mermaid-cli que já está no cache do npx e o Chrome headless do puppeteer; não instala nada. Padrão de escrita na skill `docs-gnss`.

## CI

O `.github/workflows/ci.yml` existe, mas está **desligado** por decisão do dono (2026-09-18): o único gatilho é `workflow_dispatch`, então nada roda sozinho no GitHub Actions. Para rodar, use "Run workflow" na aba Actions.

| Job | O que faz |
|---|---|
| `host-tests` | os testes de host no Ubuntu com o GCC do sistema |
| `docs` | `links_check.py` e `mermaid_check.py` com o mermaid-cli do npm (`.github/puppeteer-ci.json` passa `--no-sandbox` ao Chrome) |
| `firmware` | build com sysbuild no container `ghcr.io/nrfconnect/sdk-nrf-toolchain:v3.3.0`, com `west init` do sdk-nrf v3.3.0 |

Nenhum job rodou no GitHub até agora; o Linux pode acusar avisos que o MinGW não acusa. Ligar gatilhos automáticos (`push`, `pull_request`) só com pedido do dono.

## Legacy

O firmware original não compila nesta máquina: exige **nRF5 SDK 16.0.0**, **SoftDevice S340 6.1.1** e **GCC 6 2017-q2-update**, que não estão instalados. Os comandos originais (`make`, `make flash_softdevice`, `make flash`, DFU segurando o botão direito) estão em [`legacy/README.md`](../legacy/README.md). O `nrfutil` antigo do pip (para pacotes DFU do nRF5 SDK), em `Python311\Scripts`, está quebrado.

## Problemas conhecidos

| Sintoma | Causa e solução |
|---|---|
| `ValueError: path is on mount 'F:', start on mount 'C:'` | o `west` calcula caminhos relativos a partir do diretório atual; com o NCS em `C:` e o projeto em `F:`, rode de dentro do `zephyr_app` (os scripts fazem isso). Os `.bat` antigos faziam `cd C:\ncs\...` e só funcionavam com o projeto em `C:` |
| `include could not find requested file: ...\936afb6332\cmake\toolchain\zephyr\generic.cmake` | a variável de ambiente `TOOLCHAIN_ROOT` está definida: o Zephyr a lê como raiz das definições de toolchain. Não a defina; os `.bat` antigos a definiam |
| `Build directory ... is for application ...` | build antigo de outra pasta; `-p auto` (padrão dos scripts) refaz do zero |
| aviso `SB_CONFIG_PARTITION_MANAGER is enabled ... deprecated` | falta o `zephyr_app/sysbuild.conf` |
| `multiple definition of 'ant_stack_init'` | o add-on já define `ant_stack_init()`; no código do port use nomes fora do prefixo `ant_` (`rf_ant_init()`) |
| `lib/soft-float/libant.a ... missing` | o `ant_ncs33_compat` não entrou no build: compile pelos scripts com `ANT=1` |
| `--no-sysbuild` | ainda funciona para imagem única, mas está depreciado desde o NCS 2.7 |
| `JLink.exe` abre a ferramenta do Java | o `JLink.exe` do PATH é do Eclipse Adoptium; o da SEGGER fica em `C:\Program Files\SEGGER\JLink_V924a\` |
| pino da placa se comportando como outro periférico no DK | um nó do DK voltou a ocupar o pino; o overlay desliga `qspi` e `mx25r64`, `spi3` e `pwm0` e tira RTS/CTS do `uart0` (ver [02-hardware.md](02-hardware.md#alvo-híbrido-no-dk)) |
| cppcheck com `syntaxError` nos `ble_*.c` ou nos `#if DT_...` dos serviços | macros do Zephyr sem os headers; falso positivo. Nos serviços, passe `"-DDT_NODE_HAS_STATUS(n,s)=1"` e `"-DDT_ALIAS(a)=a"` |
| diagnósticos do clangd nos testes de host | o clangd usa o `compile_commands.json` do firmware; `zephyr_app/tests/host/.clangd` aponta para o dos testes depois do primeiro `host_tests.sh` |

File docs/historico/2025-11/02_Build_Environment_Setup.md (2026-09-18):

# stravaV10 - Configuracao do Ambiente de Build

**Versao:** 1.0
**Data:** 2025-11-25

---

## 1. Visao Geral

Este documento descreve duas opcoes de ambiente:

| Opcao | SDK | RTOS | Uso |
|---|-----|---|-----|
| **A** | nRF5 SDK 17.1.0 | Nenhum | Buildar codigo atual |
| **B** | nRF Connect SDK 3.x | Zephyr | Migracao futura |

**Recomendacao:** Configurar ambos - usar Opcao A para manter o projeto funcionando enquanto migra para Opcao B.

---

## 2. Opcao A: nRF5 SDK (Codigo Atual)

### 2.1 Requisitos

| Componente | Versao | Link |
|---|---|---|
| VS Code | Latest | https://code.visualstudio.com/download |
| GCC ARM | 10.3-2021.10 | https://developer.arm.com/downloads/-/gnu-rm |
| nRF5 SDK | 17.1.0 | https://www.nordicsemi.com/Products/Development-software/nRF5-SDK/Download |
| nRF Command Line Tools | Latest | https://www.nordicsemi.com/Products/Development-tools/nrf-command-line-tools/download |
| Make | GNU Make 4.x | Incluido no Git for Windows |

### 2.2 Instalacao GCC ARM

1. Baixar de: https://developer.arm.com/downloads/-/gnu-rm
   - Arquivo: `gcc-arm-none-eabi-10.3-2021.10-win32.exe`

2. Instalar em: `C:\Tools\gcc-arm-none-eabi-10.3-2021.10`

3. Adicionar ao PATH do sistema:
   ```
   C:\Tools\gcc-arm-none-eabi-10.3-2021.10\bin
   ```

4. Verificar instalacao:
   ```bash
   arm-none-eabi-gcc --version
   # Esperado: arm-none-eabi-gcc (GNU Arm Embedded Toolchain 10.3-2021.10) 10.3.1
   ```

### 2.3 Instalacao nRF5 SDK

1. Baixar de: https://www.nordicsemi.com/Products/Development-software/nRF5-SDK/Download
   - Versao: 17.1.0

2. Extrair para: `C:\Nordic\nRF5_SDK_17.1.0`

3. Configurar toolchain - Editar `C:\Nordic\nRF5_SDK_17.1.0\components\toolchain\gcc\Makefile.windows`:
   ```makefile
   GNU_INSTALL_ROOT := C:/Tools/gcc-arm-none-eabi-10.3-2021.10/bin/
   GNU_VERSION := 10.3.1
   GNU_PREFIX := arm-none-eabi
   ```

### 2.4 Instalacao nRF Command Line Tools

1. Baixar de: https://www.nordicsemi.com/Products/Development-tools/nrf-command-line-tools/download

2. Instalar (inclui nrfjprog e mergehex)

3. Verificar:
   ```bash
   nrfjprog --version
   ```

### 2.5 Configurar Projeto stravaV10

Editar `pca10056/s340/armgcc/Makefile.local`:

```makefile
# Windows
SDK_ROOT := C:/Nordic/nRF5_SDK_17.1.0
OUTPUT_DIRECTORY := _build_W
COM_PORT := COM8
```

### 2.6 VS Code Extensions (para nRF5 SDK)

Instalar:
- C/C++ (Microsoft)
- Cortex-Debug
- ARM (dan-c-underwood)

### 2.7 VS Code Tasks

Criar `.vscode/tasks.json`:

```json
{
    "version": "2.0.0",
    "tasks": [
        {
            "label": "Build",
            "type": "shell",
            "command": "make",
            "options": {
                "cwd": "${workspaceFolder}/pca10056/s340/armgcc"
            },
            "group": {
                "kind": "build",
                "isDefault": true
            },
            "problemMatcher": ["$gcc"]
        },
        {
            "label": "Clean",
            "type": "shell",
            "command": "make clean",
            "options": {
                "cwd": "${workspaceFolder}/pca10056/s340/armgcc"
            }
        },
        {
            "label": "Flash",
            "type": "shell",
            "command": "make flash",
            "options": {
                "cwd": "${workspaceFolder}/pca10056/s340/armgcc"
            },
            "dependsOn": "Build"
        },
        {
            "label": "Flash SoftDevice",
            "type": "shell",
            "command": "make flash_softdevice",
            "options": {
                "cwd": "${workspaceFolder}/pca10056/s340/armgcc"
            }
        },
        {
            "label": "Erase All",
            "type": "shell",
            "command": "make erase",
            "options": {
                "cwd": "${workspaceFolder}/pca10056/s340/armgcc"
            }
        }
    ]
}
```

### 2.8 VS Code Debug (J-Link)

Criar `.vscode/launch.json`:

```json
{
    "version": "0.2.0",
    "configurations": [
        {
            "name": "Cortex Debug (J-Link)",
            "type": "cortex-debug",
            "request": "launch",
            "servertype": "jlink",
            "cwd": "${workspaceFolder}",
            "executable": "${workspaceFolder}/pca10056/s340/armgcc/_build_W/nrf52840_xxaa.out",
            "device": "nRF52840_xxAA",
            "interface": "swd",
            "runToEntryPoint": "main",
            "svdFile": "${workspaceFolder}/../nRF5_SDK_17.1.0/modules/nrfx/mdk/nrf52840.svd",
            "rtos": "FreeRTOS"
        }
    ]
}
```

### 2.9 VS Code IntelliSense

Criar `.vscode/c_cpp_properties.json`:

```json
{
    "configurations": [
        {
            "name": "nRF52840",
            "includePath": [
                "${workspaceFolder}/**",
                "C:/Nordic/nRF5_SDK_17.1.0/**"
            ],
            "defines": [
                "NRF52840_XXAA",
                "BOARD_CUSTOM",
                "SOFTDEVICE_PRESENT",
                "S340",
                "BLE_STACK_SUPPORT_REQD",
                "ANT_STACK_SUPPORT_REQD",
                "NRF_SD_BLE_API_VERSION=6",
                "APP_TIMER_V2",
                "APP_TIMER_V2_RTC1_ENABLED",
                "USB_ENABLED",
                "DEBUG",
                "DEBUG_NRF",
                "DEBUG_NRF_USER",
                "__HEAP_SIZE=150000",
                "FLOAT_ABI_HARD",
                "ARM_MATH_CM4"
            ],
            "compilerPath": "C:/Tools/gcc-arm-none-eabi-10.3-2021.10/bin/arm-none-eabi-gcc.exe",
            "cStandard": "c11",
            "cppStandard": "c++14",
            "intelliSenseMode": "gcc-arm"
        }
    ],
    "version": 4
}
```

### 2.10 Build e Flash

```bash
# Terminal no VS Code (Ctrl+`)
cd pca10056/s340/armgcc

# Limpar build anterior
make clean

# Compilar
make -j8

# Flash (primeira vez - inclui SoftDevice)
make flash_softdevice
make flash

# Flash (atualizacoes)
make flash
```

---

## 3. Opcao B: nRF Connect SDK (Zephyr)

### 3.1 Requisitos

| Componente | Versao | Link |
|---|---|---|
| VS Code | Latest | https://code.visualstudio.com/download |
| nRF Connect for VS Code | Latest | VS Code Marketplace |
| nRF Connect SDK | 3.0.0+ | Via VS Code extension |
| nRF Command Line Tools | Latest | https://www.nordicsemi.com/Products/Development-tools/nrf-command-line-tools/download |

### 3.2 Instalacao nRF Connect for VS Code

1. Abrir VS Code

2. Extensions (Ctrl+Shift+X)

3. Buscar "nRF Connect for VS Code Extension Pack"

4. Instalar (Nordic Semiconductor)

5. Reiniciar VS Code

### 3.3 Configurar SDK via Extension

1. Clicar no icone nRF Connect na Activity Bar (lateral esquerda)

2. Welcome > Manage SDKs

3. Install SDK > Selecionar versao (recomendado: v3.0.0 ou mais recente)

4. Escolher diretorio: `C:\ncs` (curto, sem espacos!)

5. Aguardar download (~2-5 GB)

### 3.4 Criar Novo Projeto Zephyr

Para iniciar migracao:

1. nRF Connect > Create a new application

2. Selecionar:
   - Application type: Standalone
   - SDK version: v3.0.0+
   - Board: nrf52840dk_nrf52840 (ou custom)
   - Application template: Blank ou sample

3. Estrutura criada:
   ```
   my_app/
   ├── CMakeLists.txt
   ├── prj.conf
   ├── src/
   │   └── main.c
   └── boards/
       └── (custom overlays)
   ```

### 3.5 Build com nRF Connect

1. nRF Connect panel > Add Build Configuration

2. Selecionar board target

3. Clicar em "Build"

4. Flash via "Flash" button

### 3.6 Estrutura de Projeto Zephyr

```
stravaV10_zephyr/
├── CMakeLists.txt
├── prj.conf                 # Configuracao Kconfig
├── Kconfig                  # Custom configs
├── west.yml                 # Manifest (se standalone)
├── boards/
│   └── nrf52840_strava.overlay  # Device tree overlay
├── dts/
│   └── bindings/            # Custom DT bindings
├── src/
│   ├── main.c
│   ├── model/
│   ├── vue/
│   ├── rf/
│   └── drivers/
└── include/
    └── (headers)
```

---

## 4. Comparacao: nRF5 SDK vs nRF Connect SDK

| Aspecto | nRF5 SDK | nRF Connect SDK |
|---|---|---|
| RTOS | Opcional (FreeRTOS) | Zephyr (obrigatorio) |
| Build System | Makefile/SES | CMake + west |
| Device Config | sdk_config.h | Kconfig + Device Tree |
| Debugging | Segger/GDB | nRF Connect Debug |
| BLE Stack | SoftDevice s340 | Zephyr BLE ou SoftDevice |
| ANT+ | Suportado (s340) | Requer SoftDevice |
| Manutencao | Legacy (sem updates) | Ativo |
| Documentacao | InfoCenter | docs.nordicsemi.com |

---

## 5. Estrategia de Migracao Recomendada

### Fase 1: Setup Paralelo
1. Manter build nRF5 SDK funcionando (Opcao A)
2. Instalar nRF Connect for VS Code (Opcao B)
3. Criar projeto Zephyr vazio para nRF52840

### Fase 2: Migracao HAL
1. Abstrair GPIO, SPI, I2C, UART no codigo atual
2. Criar drivers Zephyr equivalentes
3. Testar drivers isoladamente

### Fase 3: Migracao de Modulos
1. Portar drivers (ls027, sensors)
2. Portar model layer (Boucle, Attitude, Locator)
3. Portar RF (BLE primeiro, depois ANT+)
4. Portar Vue

### Fase 4: Integracao
1. Integrar todos modulos
2. Testes de sistema
3. Otimizacao de memoria e performance

---

## 6. Troubleshooting

### Build falha: "arm-none-eabi-gcc not found"
- Verificar PATH contem diretorio bin do GCC
- Reiniciar terminal/VS Code

### Build falha: "SDK_ROOT not found"
- Verificar Makefile.local tem path correto
- Usar barras "/" nao "\" no Windows

### Flash falha: "No J-Link found"
- Verificar J-Link conectado
- Instalar drivers J-Link
- Verificar nrfjprog funciona: `nrfjprog --ids`

### IntelliSense nao funciona
- Recarregar VS Code window
- Verificar c_cpp_properties.json tem paths corretos
- Rodar "C/C++: Reset IntelliSense Database"

---

## 7. Referencias

- [nRF5 SDK Download](https://www.nordicsemi.com/Products/Development-software/nRF5-SDK/Download)
- [nRF Connect for VS Code](https://marketplace.visualstudio.com/items?itemName=nordic-semiconductor.nrf-connect-extension-pack)
- [nRF Connect SDK Docs](https://docs.nordicsemi.com/bundle/ncs-latest/page/nrf/index.html)
- [GCC ARM Downloads](https://developer.arm.com/downloads/-/gnu-rm)
- [Nordic DevZone](https://devzone.nordicsemi.com/)
- [Zephyr Project Docs](https://docs.zephyrproject.org/)

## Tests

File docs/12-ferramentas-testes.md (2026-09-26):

# Ferramentas e testes

As ferramentas herdadas do stravaV10 em `tools/` (simulador de host, scripts Node, debug em monitor mode, emulador), as ferramentas novas do projeto (`tools/fw/`, `tools/docs/`, `tools/ui/`), os testes de host do port, o renderizador das telas e as bibliotecas de terceiros com suas licenças.

**Nesta página:** [Mapa de tools/](#mapa-de-tools) · [Testes de host do port](#testes-de-host-do-port) · [Renderizador de telas](#renderizador-de-telas) · [Simulador TDD do legacy](#simulador-tdd-do-legacy) · [Outras ferramentas herdadas](#outras-ferramentas-herdadas) · [Bibliotecas e licenças](#bibliotecas-e-licenças)

## Mapa de tools/

| Pasta | Origem | Uso |
|---|---|---|
| `tools/fw/` | projeto | `ncs_env.sh`/`.bat` (ambiente do NCS), `fw.sh` (build, flash, recover, devices, size), `host_tests.sh`, `board_check.py` (confere o mapa de pinos de uma placa do projeto: pino em dois lugares, SCL de TWIM ou SCK de SPIM fora dos pinos de clock da tabela 79, pads do NFC e do cristal, limite de cada porta, dois periféricos no mesmo bloco serial e apelido faltando) |
| `tools/docs/` | projeto | `mermaid_check.py` e `links_check.py` (skill `docs-gnss`); `assembly_manual.py` gera o [manual de montagem](img/manual-de-montagem.svg) e `solar_harness_drawing.py` o [chicote solar](img/chicote-solar.svg) da placa nova; `screens_drawing.py`, as maquetes das [telas](18-interface-telas.md#telas). O `case_drawing.py`, desenho do conceito da caixa, foi retirado em 2026-09-26: a proposta medida está em [`hardware_gnssbike/caixa/`](../hardware_gnssbike/caixa/README.md) |
| `tools/ui/` | projeto | `font_gen.py` (fontes de 1 bit da interface) e `render_screens.py` (compila e roda o [renderizador de telas](#renderizador-de-telas) e gera `docs/img/telas-lvgl/`) |
| `tools/TDD/`, `tools/TDDW/` | stravaV10 | simulador de host do firmware original (Linux e Windows) |
| `tools/zpm/` | stravaV10 | scripts Node: posição do Zwift (`$LOC`), download de logs, conversão para GPX |
| `tools/MMD/` | stravaV10 | monitor mode debugging do J-Link |
| `tools/jumper/` | stravaV10 | descrição de placa para o Jumper Virtual Lab |

## Testes de host do port

Os módulos de lógica do `zephyr_app/src` compilam com o GCC do PC contra shims mínimos do Zephyr e rodam com Unity e CTest.

```sh
bash tools/fw/host_tests.sh             # tudo
bash tools/fw/host_tests.sh -R tilt     # um conjunto
```

São **53 conjuntos e 714 casos**, todos verdes em 2026-09-22 (`ctest`: 53/53).

| Conjunto | Código testado | Casos | O que garante |
|---|---|---|---|
| `test_segment_file` | `model/segment_file.c` | 6 | nome de segmento do legacy (12 caracteres, `#` e `.` nas posições certas), posição em base 36 no nome, leitura da linha `lat ; lon ; rtime ; alt`, ida e volta nome↔posição e a conferência dos **138 segmentos reais** de `tools/TDD/DB`: o nome tem de bater com o primeiro ponto de dentro |
| `test_segment` | `model/segment.c`, com `liste_points.c`, `vecteur.c` e `segment_file.c` | 14 | o cartão sem segmento não carrega nada, a varredura pega os nomes do legacy sem abrir os arquivos, o segmento longe fica fechado e o a menos de 300 m entra, o mais comprido que a fatia é partido ao meio, o quarto espera vaga, afastar-se descarrega, entrar ativa e chegar ao fim conclui, a posição ruim é recusada e a lista dos próximos sai em ordem de distância |
| `test_liste_points` | `model/liste_points.c` | 15 | ordem das listas (segmento em ordem de arquivo, histórico com o mais novo no índice 0), corte do histórico, distância à lista, caixa e centro em graus, e a posição relativa com cinco pontos, projetada e fora do triângulo |
| `test_vecteur` | `model/vecteur.c` | 25 | distância dentro de 0,5 % da fórmula do legacy, sinais dos eixos, produto escalar, normalização |
| `test_crash_recovery` | `model/crash_recovery.c` | 8 | a partida limpa não restaura nada, o bloco volta inteiro (com o recorde), não depende de falha registrada, um byte trocado quebra o CRC, o bloco limpo não é aceito e a segunda gravação vale |
| `test_kalman_altitude` | `model/kalman_altitude.c`, `udmatrix.c` | 6 | a elevação acompanha a subida pelo pitch, a rampa e a velocidade vertical saem do filtro, o offset de montagem é estimado, parado não atualiza e a descida dá velocidade vertical negativa |
| `test_udmatrix` | `model/udmatrix.c` | 8 | `ones` preenche tudo (P0 = 900), `bound` compara valor absoluto e mantém covariância negativa, e soma e subtração com o destino igual a uma das entradas |
| `test_distance` | `model/distance.c` | 9 | descarte dos primeiros 25 m, instantâneo a cada 15 m (e um só quando a época traz 100 m), parado não soma, total igual ao do legacy em 300 m e a volta do total pela recuperação de falha |
| `test_attitude` | `model/attitude.c`, com `distance.c`, `power_estimate.c`, `kalman_altitude.c`, `udmatrix.c` e `crash_recovery.c` | 18 | a época pedalada que conta um segundo ativo e o limiar de 7 do legacy, as épocas pouco abaixo de um segundo que ainda contam, a bicicleta parada e o receptor calado que não somam nada, a coordenada zerada e a fora do planeta recusadas, o primeiro salto descartado, a distância que conta qualquer que seja a velocidade, a potência pela velocidade com que a época chegou, a rugosidade como desvio médio absoluto, a referência que espera 15 pontos, o pedal retomado depois de uma queda que mantém os segundos e o de outro dia recusado |
| `test_power_estimate` | `model/power_estimate.c` | 7 | a fórmula do legacy em 64 pontos de velocidade e rampa contra a transcrição em `legacy_ref.h`, os 147 W a 30 km/h no plano, os 151 W a 12 km/h em 5 %, potência negativa na descida e a saturação do `int16_t` |
| `test_power_zone` | `model/power_zone.c` | 6 | limites das 7 zonas pelo FTP, janela de 50 a 1950 W, acumulação |
| `test_power_metrics` | `model/power_metrics.c` | 19 | as métricas de Coggan: nada antes de 30 s e a NP no trigésimo segundo, uma hora no limiar dando TSS 100, meia hora dando metade, o pedal irregular custando mais do que a média diz, a oscilação mais rápida que a janela que não conta, a janela de exatamente 30 s, o pico impossível valendo um segundo de zero, sem FTP não há IF nem TSS, e trocar o FTP muda o que o pedal valeu |
| `test_suffer_score` | `model/suffer_score.c` | 5 | zonas de FC e pontos por hora do legacy |
| `test_rr_zone` | `model/rr_zone.c` | 14 | os intervalos RR por zona: a amostra sem relógio ignorada, a primeira só acertando o relógio, o coração estável sem variabilidade, o denominador que é o buffer e não as diferenças, cada limite do legacy, a faixa pela FC da última amostra, a zona lida como a sua média, os totais e o buffer que nunca passa do fim |
| `test_alerts` | `model/alerts.c` | 22 | os 12 alertas: quem não configurou nada nunca é interrompido, passar do limite avisa uma vez, o limite em si não é passar dele, o rearme com margem (15 W na potência, décimos de km/h na velocidade), o sensor ausente que não dispara alerta de mínimo, a cada 10 km, o intervalo contando só tempo em movimento, mais de um alerta na mesma época e o pedal novo que recomeça |
| `test_workout` | `model/workout.c` | 32 | os arquivos `.WKT`: a sessão mais simples, linhas em branco e comentários, cada tipo de duração e de alvo, a repetição achatada em ordem, a aninhada recusada, a nunca fechada, a sessão grande demais recusada inteira, os passos em sequência, o fim uma vez só, o passo que acaba por distância e o que espera o ciclista, o rolo recebendo o meio da faixa e onde o ciclista está em relação ao alvo |
| `test_sd_logger` | `model/sd_logger.c` | 7 | intervalo de 15 m, lote de 5 com cabeçalho CSV, **nenhuma escrita fora do buffer sem cartão** |
| `test_ui_fmt` | `ui/ui_fmt.c` | 10 | números como o `_fmkstr` do legacy numa varredura, truncamento em `float` (0,21 vira `0.20`), negativos, limite de 100000, NaN, buffer pequeno, horas e hora desconhecida, larguras do `cadran` e do `cadranH`, valores com sinal |
| `test_tilt` | `svc/sensors/tilt.c` | 8 | inclinação, rolagem e rumo contra leituras construídas por rotação (aerospacial, norte-leste-baixo), janela de 50 amostras, rugosidade contra o laço de `fxos.cpp:761-766` |
| `test_backlight` | `svc/ui/backlight.c` | 11 | luz por 10 s depois de uma tecla, nova tecla reinicia, automática com pouca luz até a luz voltar, histerese entre 20 e 50 lux, desligada pelo menu, volta do contador de 32 bits |
| `test_max17262` | `modules/gnss_drivers`: `max17262_regs.h` | 10 | passos da tabela 2 da ficha (78,125 µV, 156,25 µA com sinal, 1/256 %, 0,5 mAh, 5,625 s, 1/256 °C), tempo desconhecido, arredondamento da carga, `DesignCap`, `IChgTerm`, `VEmpty` (o 0xA561 de fábrica) e `ModelCfg` |
| `test_aem10900` | `modules/gnss_drivers`: `aem10900_regs.h` | 7 | limiares de carga e de descarga da ficha (0x32 é 4,05 V, 0x2D é 3,04 V, passos de 56,25 mV, mínimos de 2,70 V e 2,51 V), tensão da bateria (4,8 V em 256 passos), energia do APM (`POWER << OFFSET`, além de 32 bits) e potência em µW sem calibração |
| `test_ubx_m10` | `modules/gnss_drivers`: `ubx_m10.c` | 24 | quadros UBX com o checksum de Fletcher, `UBX-CFG-VALSET` de uma chave e de um lote (`ubx_m10_valset_many()`, usado nos sinais de L5 do F10) e `VALGET` (tamanho do valor pelos bits 30 a 28 da chave, camadas RAM e BBR), `UBX-RXM-PMREQ` com backup e force, `UBX-CFG-RST` de partida fria, e a leitura do `UBX-NAV-PVT` (92 B, Nancy, bits de `valid`, psmState, rumo negativo) e do `UBX-NAV-SAT` (truncado e com elevação negativa); os vetores vêm de uma implementação independente das seções das fichas do F10 SPG 6.00 e do M10 SPG 5.30 |
| `test_activity` | `model/activity.c` | 19 | o cronômetro que conta só em movimento, o semáforo que o para depois de 3 s e o retomar acima de 3 km/h, a bicicleta empurrada a 2 km/h que não faz o cronômetro oscilar, a volta automática por distância e a volta pela tecla, a volta aberta que fecha no fim, a descida com a banda morta de 2 m contra o ruído do barômetro, as médias só do tempo em movimento e a cinta que cai sem derrubar a média |
| `test_fit_encode` | `model/fit_encode.c` | 15 | o cabeçalho de 14 bytes e o `.FIT`, as mensagens de definição e de dados, os tipos base, as escalas de altitude, distância e velocidade, os valores "inválidos" do formato, os semicírculos, a data do legacy virando `date_time`, as voltas numeradas, o CRC-16 conferido contra o cálculo direto para 33 tamanhos de arquivo, o resíduo zero do cabeçalho (que é o que deixa o arquivo fechar sem reler o que foi gravado) e um passeio inteiro lido de volta mensagem a mensagem |
| `test_climb` | `model/climb.c` | 16 | o que é e o que não é subida (a ponte curta demais, o falso plano de 1 %), os números de uma subida de verdade, o falso plano que não parte um colo em dois e o vale que parte, o percurso que acaba no topo, as categorias pelo ganho, o que falta ao ciclista em cada ponto da subida, a próxima subida anunciada no vale, a inclinação dos próximos 200 m e o percurso com mais subidas do que cabem |
| `test_parcours` | `model/parcours.c`, com `route_file.c` e `gpx_scan.c` | 10 | o percurso no formato do legacy, o fim de linha dele que não trava o carregador, o ponto sem altitude, a última linha sem fim de linha, o percurso de um ponto recusado, o arquivo que não existe, a carga que substitui a anterior, o comprimento e o desnível, o ciclista que anda pelo percurso e sai dele, e os percursos reais de `tools/TDD/DB` |
| `test_route_file` | `model/route_file.c` | 11 | a assinatura que separa o `.RTE` do texto do legacy, o cabeçalho que o menu precisa, os pontos que saem como entraram, o ponto abaixo do nível do mar e ao sul do equador, a curva com o nome da rua, a direção desconhecida virando "siga em frente", a versão errada e o arquivo cortado recusados, o CRC do zlib e o do corpo conferido contra o do cabeçalho |
| `test_gpx_scan` | `model/gpx_scan.c` | 11 | a trilha do Strava, os espaços de nomes e as extensões, os atributos em qualquer ordem, o ponto sem altitude tomado como zero, a rota de waypoints valendo como percurso, o arquivo que chega em pedaços, o último ponto que ainda vem, o que não é ponto ignorado, o arquivo que não é GPX reconhecido, o elemento maior que o buffer e mil pontos em ordem |
| `test_route_profile` | `model/route_profile.c`, com `map_project.c` e `vecteur.c` | 8 | o percurso curto que guarda cada ponto e o longo percorrido com passo, a coluna do ciclista, a subida que falta contando só o que está à frente, o percurso plano sem subida nem faixa, o abaixo do nível do mar, a falta de percurso e o ciclista além do fim |
| `test_map_project` | `model/map_project.c` e `vecteur.c` | 8 | o ciclista no centro, a borda da janela igual ao alcance, o metro igual nos dois eixos, o norte para cima e o leste para a direita, o ponto distante que fica fora, os cinco passos de zoom do port, a barra de escala em número redondo e a lista longa percorrida com passo |
| `test_csc_calc` | `model/csc_calc.c` | 13 | a volta de roda por segundo que são 7,58 km/h (o número que o port devolvia como zero), a velocidade de pedalada, a roda de 29", a bicicleta parada com o sensor ainda mandando, a volta do contador de tempo a cada 64 s e a do contador de voltas, a leitura impossível descartada sem travar o sensor, a cadência de 90 rpm, a roda-livre e a volta do contador de pedivela |
| `test_ftms_parse` | `model/ftms_parse.c` | 10 | o pacote que a maioria dos rolos manda (velocidade, cadência e potência instantâneas), o bit *More Data* invertido, os campos de média que têm de ser pulados e não lidos, a notificação com todos os campos, os quatro bytes da energia, a potência negativa, a notificação que mente sobre o próprio tamanho, e a checagem de que as constantes dos flags são uma sequência sem lacuna nem repetição |
| `test_cps_parse` | `model/cps_parse.c` | 23 | o medidor de potência pelo BLE: o que manda só a potência, a potência com sinal, o sprint de 1500 W, o payload curto demais e a notificação que mente sobre o próprio tamanho, o balanço em passos de meio por cento com a perna nomeada, uma volta de pedivela por segundo dando 60 rpm, o relógio da roda ao dobro do relógio do pedivela, 30 km/h, a volta dos contadores, a cadência e a velocidade impossíveis descartadas, os campos de análise de pedalada pulados pela largura certa e o pedido de offset zero |
| `test_lns_parse` | `model/lns_parse.c` | 17 | a posição do celular: só `LNS_POS_OK` é aceito, a estimada e a antiga são recusadas, o status bom sem coordenadas não vale, a velocidade em centésimos de m/s, a posição a sul e a oeste, a elevação abaixo e acima do mar, o rumo, todos os campos de uma vez com o último no lugar certo, a lacuna no meio que não desloca o resto e o payload curto para os flags |
| `test_komoot_turn` | `model/komoot_turn.c` | 13 | as 24 direções do Komoot nas 9 setas: as curvas simples, o início apontando em frente, o fim dizendo que chegou, a bifurcação que não é esquina, todo retorno na mesma seta, a rotatória pelo lado em que se pedala e sem saída nomeada, as duas que são mensagem e não curva, a direção desconhecida, a distância que passa direto e a curva mais longe do que a tela sabe dizer |
| `test_notif_filter` | `model/notif_filter.c` | 23 | o filtro das notificações do iPhone: as categorias que um ciclista quer e a que ele desligou, tudo o que o celular já tinha antes descartado, a notificação retirada, a chamada que ignora as outras regras e a que passa a segui-las, "só chamadas", a chamada perdida que não é recebida, a silenciosa, a repetida, os últimos identificadores lembrados, o intervalo mínimo com a importante furando a fila, e o celular que reconecta começando limpo |
| `test_radar` | `model/radar.c` e `model/radar_wire.c` | 20 | o carro que aparece com a distância, o mais perto vindo primeiro, o mesmo veículo mantendo o lugar enquanto se aproxima, o quadro perdido que não faz a marca piscar, o que sai de alcance, o nível de ameaça por distância e velocidade, o nível que o rádio manda ganhando do palpite, mais veículos do que o modelo guarda, o radar que se desconecta limpando a pista, e os quadros do Varia pelo BLE (dois carros, pista limpa, casa vazia, pacote que não é nosso) |
| `test_incident` | `model/incident.c` | 20 | sobretudo o lado do **não**: pedalar não é incidente, meio-fio não é queda, semáforo não é queda, bicicleta que volta a rolar cancela, vento não toca o alarme; e o lado do sim: a queda que abre contagem, a contagem que zera, a tecla que cancela e desarma, o carro que bate na bicicleta parada, e a amostra sem número que não pode parecer queda |
| `test_e2e_activity` | `model/activity.c` e `model/fit_encode.c` juntos | 6 | um passeio inteiro saindo de Nancy — plano, subida de 400 m, semáforo de 3 min, descida e arrancada — que vira arquivo FIT: as 2.100 mensagens de ponto, as marcas de cronômetro da pausa, a sessão com os mesmos números do modelo, as voltas automáticas a cada 5 km, o CRC do arquivo e o tamanho por ponto |
| `test_e2e_route` | `model/parcours.c`, `route_file.c`, `gpx_scan.c`, `route_profile.c`, `map_project.c`, `file_policy.c` e `vecteur.c` juntos | 9 | um percurso de 100 km que o celular manda: a política aceita percurso e recusa o resto, o percurso vai até o fim, o ciclista o segue e a tela mostra, o perfil sai do mesmo percurso, um segundo substitui o primeiro, o GPX do celular dispensa conversão, o convertido é menor e conferido, o cortado no meio pelo rádio é recusado e as curvas saem em ordem |
| `test_loc_arbiter` | `model/loc_arbiter.c` | 14 | quem manda na posição: sem nada chegando não há fonte, o receptor sozinho é tomado, a amostra é oferecida uma vez só, o pedal simulado ganha do receptor e nada se intromete entre dois quadros dele, o receptor volta quando a simulação para, o celular é recusado com fix e aceito sem, um receptor recente ainda bloqueia o celular, a idade de cada fonte e a volta do contador de 32 bits |
| `test_gnss_power` | `svc/gnss/gnss_power.c` | 21 | backup fora de CRS e PRC, aquisição até o primeiro fix, configuração de novo com 10 s de silêncio e reset com 30 s. Com LEAP (o MAX-M10N): LEAP no rastreio, potência plena depois de 10 épocas sem fix e volta ao LEAP depois de 60 s com fix. **Sem LEAP** (o MAX-F10S, que não tem o grupo `CFG-PM`): os mesmos cinco cenários, conferindo que a máquina nunca pede um modo de energia e mostra o rastreio como potência plena |
| `test_battery` | `svc/power/battery.c` | 10 | bateria fraca uma vez a 10 %, de novo só depois de 15 %, crítica a 0 % descarregando e nunca carregando (VBUS ou corrente do painel) |
| `test_charge` | `svc/power/charge.c` | 11 | cada estado da máquina de carga pelos bits do `BCHGCHARGESTATUS`, do `BCHGERRREASON` e do `NTCSTATUS`; VBUS acima do sol; frio e quente pausam, fresco e morno não; erro vira falha só com VBUS |
| `test_memlcd` | `modules/gnss_drivers`: `memlcd_frame.c` e `memlcd_pixel.h` | 19 | quantização (cores puras, bordas cinza pela média, luminância na Sharp), retrato do legacy e as outras rotações, bits de cada painel, quadro da Sharp com os 12.482 B do legacy e endereços de 10 bits do JDI, linhas marcadas, `pitch`, área fora da tela, trechos de linhas |
| `test_power_scheduler` | `model/power_scheduler.c` | 7 | 15 min exatos mantêm ligado, pings de posição e do rolo, ping desconhecido não conta, nova tentativa 15 min depois, volta do contador de 32 bits |
| `test_sys_fsm` | `svc/power/sys_fsm.c` + `lib/smf/smf.c` do Zephyr | 16 | Partida e Ligado, desligamento que espera cada serviço por até 5 s, System OFF com USB, auto-off por modo (CRS, PRC e DBG pela posição, FEC pelo rolo), bateria no fim, MSC, desligamento no boot, comandos durante o desligamento, energia cortada uma vez só |
| `test_mode_fsm` | `model/mode_fsm.c` + `lib/smf/smf.c` do Zephyr | 22 | começa em CRS e publica o modo na entrada e uma vez por troca, o modo que não existe é recusado, pedir o modo em que já se está não muda nada, o PRC é recusado sem percurso e abre com ele, o percurso que some derruba o ciclista para CRS, a gravação não pula de família mas anda livre dentro dela, e a família de cada modo |
| `test_cmd_parser` | `model/cmd_parser.c` | 12 | as sentenças do legacy: posição do PC, posição a sul e a oeste, FC e cadência, ordem e pergunta, notificação do celular; a sentença que chega pedaço a pedaço, o lixo antes dela jogado fora, o tipo desconhecido ignorado, a que não tem fim de linha e ainda conta, a nova que derruba a anterior, o termo maior que a linha que não transborda e as ordens destrutivas que só saem do menu |
| `test_file_policy` | `model/file_policy.c` e `segment_file.c` | 10 | o que cada nome é (percurso, segmento do legacy, atividade, desconhecido), a transferência presa à raiz, o celular que manda percurso e segmento mas não atividade nem `.FIT`, o arquivo que o firmware não lê e não ocupa espaço, e o nome mais longo do que o armazenamento aceita |
| `test_qry` | `model/qry.c`, com `file_policy.c` e `segment_file.c` | 17 | o `$QRY`: uma linha da listagem, o total no fim, o armazenamento vazio que ainda termina, o arquivo sem tamanho e o maior do que caberia, o nome que não cabe na linha, as respostas de sucesso e de erro com uma palavra por motivo, o pedido de arquivo que aponta para o outro caminho (`USESMP`), o percurso que pode ser apagado e a atividade que não, o nome que sobe para fora do armazenamento e o que não existe |
| `test_dfu_state` | `model/dfu_state.c` | 12 | a atualização recusada em atividade e com bateria fraca e aceita no carregador com qualquer bateria, o progresso que acompanha a imagem, o pedaço repetido que não anda para trás, os bytes além do anunciado que param no fim, a falta de tamanho sem porcentagem, a imagem marcada para bootar que está pronta e a transferência que desistiu |

```mermaid
flowchart LR
    SRC["zephyr_app/src/*.c<br/>modules/gnss_drivers"] --> EXE["test_x.exe"]
    SHIM["tests/host/shim/zephyr/<br/>kernel.h · logging/log.h · fs/fs.h · sys/util.h"] --> EXE
    SUP["tests/host/support/<br/>host_kernel · host_fs · legacy_ref.h"] --> EXE
    ZEP["lib/smf/smf.c do Zephyr<br/>(ZEPHYR_BASE)"] --> EXE
    T["tests/host/test_x.c"] --> EXE
    UNITY["Unity 2.6.1<br/>FetchContent com SHA-256"] --> EXE
    EXE --> CT["ctest"]
```
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

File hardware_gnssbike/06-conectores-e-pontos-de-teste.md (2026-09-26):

# Conectores e pontos de teste

Todo conector e todo ponto de teste da placa, **contato a contato**. As
[folhas do esquemático](01-esquematico.md) dizem quais sinais existem e a
[lista de nós](03-netlist.md) diz de onde cada um sai e aonde chega;
nenhuma das duas diz **em que contato** de cada conector o sinal entra. É
essa lacuna que este documento fecha, porque ela é a forma clássica de
inverter a polaridade da bateria na primeira montagem — e de descobrir
isso pelo cheiro.

**Nesta página:** [Como ler](#como-ler) · [De onde vem cada pinagem](#de-onde-vem-cada-pinagem) · [J101 · USB-C](#j101--usb-c) · [J102 · Bateria](#j102--bateria) · [J201 · Depuração SWD](#j201--depuração-swd) · [J401 · Display](#j401--display) · [A luz do LPM027M128C](#j402--luz-do-lpm027m128c) · [JP401 · Tensão do display](#jp401--tensão-do-display) · [JP101 · Jumper de medição de corrente](#jp101--jumper-de-medição-de-corrente) · [Pontos de teste](#pontos-de-teste) · [O que falta conferir](#o-que-falta-conferir)

> [!WARNING]
> **Nada disto foi montado, medido ou fabricado.** Não existe placa, não
> existe layout, nenhum conector foi encaixado e nenhum ponto de teste foi
> tocado por ponta de prova. Cada pinagem abaixo vem de uma norma, de uma
> ficha de fabricante ou de uma escolha feita aqui, e **está marcada como
> tal**. O que não foi encontrado em fonte nenhuma está dito como
> faltando, não preenchido por simetria.

## Como ler

- **Contato**: o número do contato como o desenho do fabricante o numera.
  Onde o fabricante usa nome em vez de número (o USB-C usa `A1`, `B5`), o
  nome é o do fabricante.
- **Direção**: do ponto de vista **da placa**. `entrada` é o que chega,
  `saída` é o que a placa aciona, `bidir` é linha compartilhada, `alim` é
  alimentação ou retorno.
- **Origem da pinagem**: cada seção diz, logo no começo, se a ordem dos
  contatos é **padrão da indústria**, veio da **ficha do fabricante** ou é
  **escolha deste projeto**. As três coisas têm graus de confiança
  diferentes e quem for fabricar a placa precisa saber qual é qual.
- Os designadores (`J101`, `JP401`, `TP203`) seguem o esquema por folha
  já usado em [05](05-materiais.md#como-ler): a centena é o número da
  folha do esquemático.

```mermaid
flowchart LR
    subgraph EXT["Fora da placa"]
        CABO["cabo USB-C"]
        PACK["pack LiPo 1S<br/>PCM e NTC"]
        PAINEL["painel JDI LPM027M128C<br/>2,7&quot;, com luz integrada"]
        SONDA["J-Link<br/>cabo TC2030-CTX-NL"]
    end
    CABO --> J101["J101 · USB-C<br/>Molex 2036150003<br/>16 contatos"]
    PACK --> J102["J102 · bateria<br/>JST SM06B-SRSS-TB<br/>6 vias"]
    PAINEL --> J401["J401 · display<br/>Hirose FH28-10S<br/>10 vias"]
    PAINEL -.->|"por onde?"| LUZ["conector da luz<br/>não definido"]
    SONDA --> J201["J201 · SWD<br/>Tag-Connect TC2030-NL<br/>6 pads, sem peça"]
    SONDA --> J202["J202 · SWD<br/>Cortex Debug 2 × 5, 1,27 mm<br/>adaptador de 9 vias do J-Link"]
    J101 --> F1["folha 1 · energia"]
    J102 --> F1
    J201 --> F2["folha 2 · MCU"]
    J202 --> F2
    J401 --> F4["folha 4 · display"]
    LUZ -.-> F4
```

## De onde vem cada pinagem

| Conector | Origem da pinagem | Quem fecha o assunto |
|---|---|---|
| `J101` USB-C | **padrão da indústria**: USB Type-C, receptáculo de 16 contatos (USB 2.0) | a norma define os sinais; o desenho da Molex dá o número do pad no footprint |
| `J102` bateria | **escolha deste projeto** — não existe padrão para isto | o fabricante do pack, antes de fechar o pedido |
| `J201` depuração | **conferido em 2026-09-25** na ficha `TC2030-CTX_1.pdf` da Tag-Connect: 1 `VCC`, 2 `SWDIO`, 3 `nRESET`, 4 `SWCLK`, 5 `GND`, 6 `SWO`. O projeto tinha o reset no 6 e foi corrigido | ficha oficial da Tag-Connect |
| `J202` depuração, conector | **padrão da ARM** (Cortex Debug Connector, 10 vias): 1 `VTref`, 2 `SWDIO`, 3 `GND`, 4 `SWDCLK`, 5 `GND`, 6 `SWO`, 7 chave, 8 TDI, 9 `GNDDetect`, 10 `nRESET`; é a pinagem do adaptador Cortex-M de 9 vias do J-Link | a norma; a peça (Samtec FTSH-105-01-L-DV-K ou equivalente) ainda não foi escolhida |
| `J401` display | **ficha do fabricante**, e a mesma ordem nas duas telas | fichas JDI LPM027M128B Ver.01 e Sharp LS027B7DH01A (LD-28305A) |
| Conector da luz do JDI | **falta tudo**: não se sabe sequer se ele existe como conector separado ou se o C traz um FPC maior | ficha do **LPM027M128C**, ou uma amostra |
| `JP401` tensão do display | **escolha deste projeto** | este documento |
| `JP101` medição | **escolha deste projeto**, e peça que ainda não existe na lista | o dono |

## J101 · USB-C

**Molex 2036150003**, receptáculo IPX8, SMT, USB 2.0, **16 contatos**
([14](../docs/14-hardware-placa-nova.md#componentes-principais),
[15](../docs/15-avaliacao-componentes.md#usb-c-e-proteção)).

**A pinagem é padrão da indústria.** Ela não é escolha deste projeto nem
da Molex: é a norma do USB Type-C, e todo receptáculo a segue. Um
receptáculo USB 2.0 de 16 contatos é o de 24 contatos **sem os oito da
faixa de alta velocidade** (`A2`, `A3`, `A10`, `A11`, `B2`, `B3`, `B10` e
`B11`), que só existem para USB 3.x. Sobram estes:

| Contato | Sinal | Direção | Nota |
|---|---|---|---|
| `A1` | `GND` | alim | retorno |
| `A4` | `VBUS` | entrada | 4,0 a 5,5 V; ao `VBUS` do nPM1300, com o TVS **ESD761** junto do conector |
| `A5` | `CC1` | bidir | **direto** ao `CC1` do nPM1300, com o **TPD4E05U06**; o Rd de 5,1 kΩ é interno ao PMIC |
| `A6` | `D+` | bidir | unido ao `B6`; par de 90 Ω até o pad 8 do ME54BS13 |
| `A7` | `D−` | bidir | unido ao `B7`; par de 90 Ω até o pad 7 do ME54BS13 |
| `A8` | `SBU1` | — | **não usado**, deixado aberto |
| `A9` | `VBUS` | entrada | mesmo nó do `A4` |
| `A12` | `GND` | alim | retorno |
| `B1` | `GND` | alim | retorno |
| `B4` | `VBUS` | entrada | mesmo nó do `A4` |
| `B5` | `CC2` | bidir | **direto** ao `CC2` do nPM1300, com o TPD4E05U06 |
| `B6` | `D+` | bidir | unido ao `A6` |
| `B7` | `D−` | bidir | unido ao `A7` |
| `B8` | `SBU2` | — | **não usado**, deixado aberto |
| `B9` | `VBUS` | entrada | mesmo nó do `A4` |
| `B12` | `GND` | alim | retorno |
| carcaça | `SHIELD` | alim | ao `GND`, direto, junto com as abas de fixação |

**Os quatro `VBUS` são um nó só e os quatro `GND` também.** Isso não é
economia: é o que faz o cabo funcionar nas duas orientações, e é também o
que divide os até 1,5 A do `VBUS` ([02](02-calculos.md#corrente-por-trilho-e-largura-de-trilha))
por quatro contatos.

**Os dois `D+` são unidos na placa, e os dois `D−` também.** A norma manda
exatamente isso num receptáculo USB 2.0: como o cabo pode entrar de
qualquer lado, o par ativo cai ora na faixa A, ora na B, e o aparelho não
tem como saber qual é. Unir os dois resolve sem multiplexador.

**O `CC1` e o `CC2` vão ao nPM1300 sem nada no meio além do ESD.** O
resistor Rd de 5,1 kΩ que anuncia "sou um consumidor" é **interno** ao
PMIC ([14](../docs/14-hardware-placa-nova.md#ligações-fixas-dos-cis)).

> [!CAUTION]
> **Não acrescente Rd externo no `CC1` e no `CC2`.** É o erro quase
> automático de quem já projetou USB-C com outro CI: os 5,1 kΩ de fora em
> paralelo com os 5,1 kΩ de dentro dão cerca de 2,6 kΩ, que **não é Rd
> nem Ra** — cai no meio da faixa indefinida da norma. O resultado não é
> "carrega mais devagar", é a fonte podendo nunca ligar o `VBUS`, e um
> aparelho que não carrega sem que nada esteja queimado.

**O `SBU1` e o `SBU2` ficam abertos, e não no `GND`.** São as linhas de
banda lateral, que um acessório de áudio ou de vídeo aciona; aterradas,
seriam saída contra terra.

## J102 · Bateria

**JST SM06B-SRSS-TB** na placa e **SHR-06V-S-B** no cabo, com terminais
SSH-003T-P0.2 (a conferir no catálogo eSH ao fechar o pedido). Série SH,
passo de 1,0 mm, 6 vias, **1 A por contato**, entrada lateral, **2,9 mm de
altura**. Até 2026-09-26 era o GH SM06B-GHS-TB, escolhido pela trava
positiva ([19](../docs/19-lista-de-compras.md#trocas)); a caixa desenhada
nesse dia deixa **4,2 mm** entre a face da placa e a tampa fora do display,
e o GH tem 4,25. O SH cabe e perde a trava: o cabo da célula, curto, é preso
à caixa com fita (a alternativa é a caixa 0,5 mm mais alta, com o GH:
decisão do dono). Fica **na frente**, em pé na borda esquerda do bolso entre
o SWD `J202` e o USB-C, a 270°: o footprint do KiCad tem as ilhas de sinal em
y −2 e a boca do lado oposto, e a rotação manda a boca para a esquerda, para
a parede da caixa, por cima do diodo `D102`; a célula fica debaixo da placa.

> [!IMPORTANT]
> **A pinagem abaixo é escolha deste projeto.** Não existe padrão de
> indústria para conector de bateria: cada fabricante de pack monta o cabo
> como o cliente pedir, e é o cliente que erra. A proposta abaixo é
> argumentada contato a contato justamente para poder ser discutida com o
> fabricante do pack antes de a placa ir para fabricação.

### O que o conector precisa levar

Quatro sinais, em seis vias:

- **`VBAT+`** e **`GND`**, o par de potência;
- **`NTC_BAT`**, o NTC do pack, que vai ao pino `NTC` do nPM1300 e serve
  ao perfil JEITA de 0, 10, 45 e 60 °C;
- **`TH_MON`**, um **segundo NTC**, que corta a carga solar fora de 0 a
  45 °C. Desde 2026-09-26 quem o lê é o comparador `U105` (TLV7031), porque
  o ADP5091 que substituiu o AEM10900 não tem entrada de temperatura: o
  divisor `RT101`/`R106` é alimentado pelo próprio painel e a saída do
  comparador leva o `DIS_SW` para cima pelo `D106`
  ([01](01-esquematico.md#folha-1--energia), [03](03-netlist.md#nós-de-alimentação)).

### Proposta

| Contato | Sinal | Direção | Nota |
|---|---|---|---|
| 1 | `VBAT+` | alim, nos dois sentidos | com o contato 6; positivo da célula, **depois** do PCM do pack |
| 2 | `GND` | alim | com o contato 5; retorno do par 1–2 |
| 3 | `NTC_BAT` | entrada analógica | ao pino `NTC` do nPM1300; 10 kΩ, B3380, referenciado ao negativo da célula |
| 4 | `TH_MON` | entrada analógica | **via reservada e não populada** na montagem escolhida: o NTC do `TH_MON` é o `RT101`, na face de trás da placa ([05](05-materiais.md#folha-1--energia)). Montar os dois mata a carga solar |
| 5 | `GND` | alim | com o contato 2; retorno do par 5–6 |
| 6 | `VBAT+` | alim, nos dois sentidos | com o contato 1 |

### Por que assim

**`VBAT+` e `GND` em dois contatos cada, por causa dos 600 mA de carga.**
O pior caso do nó `VBAT` é a carga pelo USB, 600 mA
([02](02-calculos.md#corrente-por-trilho-e-largura-de-trilha)), e o
contato da série GH vale 1 A. Um contato só daria 1,67 vezes de folga, que
é pouco para uma peça que o usuário vai desconectar e reconectar. Dois dão
3,3 vezes. E há um segundo motivo, menos óbvio: a resistência de contato
fica **em série com a célula**, antes do pino `BATT` do MAX17262, de modo
que a queda sobre ela entra direto na tensão que o medidor usa para
estimar a carga. Dobrar os contatos corta essa queda pela metade.

**A ordem é um palíndromo, de propósito.** Lida ao contrário — que é
exatamente o que acontece quando o fabricante do pack numera o cabo pela
face oposta —, `VBAT+, GND, NTC, NTC, GND, VBAT+` continua sendo
`VBAT+, GND, NTC, NTC, GND, VBAT+`. Um cabo espelhado troca **só os dois
NTC entre si**, e os dois são a mesma peça, 10 kΩ com B3380, na mesma
célula: o nPM1300 passa a ler o NTC do AEM e vice-versa, e os dois
continuam funcionando. Com a ordem "natural"
(`VBAT+, VBAT+, GND, GND, NTC, NTC`), o mesmo cabo espelhado poria **4,2 V
no pino `NTC` do nPM1300 e no `TH_MON` do AEM10900**, e os dois CI
morreriam antes de alguém medir coisa alguma.

**Cada par de potência fica junto.** Os contatos 1–2 e 5–6 são dois pares
`VBAT+`/`GND` adjacentes: duas espiras de corrente estreitas em vez de uma
larga, o que importa porque essa é a única espira de 600 mA da placa.

**Os dois NTC têm de compartilhar o negativo da célula.** É isso que faz
os quatro sinais caberem em seis vias: um fio para cada termistor, com a
outra ponta no negativo do pack. Se o fabricante entregar um pack com os
termistores isolados, cada um passa a precisar de duas vias e **seis não
bastam** — aí o conector muda para oito vias e este documento junto.

> [!CAUTION]
> **O NTC do pack e o NTC de placa não podem conviver.** A [lista de
> compras](../docs/19-lista-de-compras.md#energia) aprovou um **TDK
> NTCG103JF103FT1 na face de trás da placa, sob a célula**, e a
> [avaliação](../docs/15-avaliacao-componentes.md#carga-usb-c-e-painel-solar)
> trata o segundo NTC do pack e o NTC de placa como alternativas — "vem do
> pack **ou** é um TDK". Montar os dois põe dois termistores de 10 kΩ em
> paralelo no `TH_MON`, isto é, 5 kΩ. **Conta feita aqui:** com B3380 e
> 10 kΩ a 25 °C, 5 kΩ correspondem a **44,4 °C**, e o limite superior do
> AEM10900 é 45 °C. O aparelho sairia da bancada com a carga solar
> desligada a qualquer temperatura ambiente acima de uns 25 °C, sem
> mensagem nenhuma, porque **nada disso passa por firmware**. Ou se monta
> o NTC de placa e as vias 4 do conector e do cabo ficam vazias, ou se usa
> o do pack e o footprint do TDK fica sem peça. **Escolher é decisão do
> dono.**

> [!NOTE]
> **O `VBAT+` que chega ao contato 1 já saiu do PCM do pack.** Quando a
> proteção abre por subtensão ou por curto, a placa vê a célula
> desaparecer, não vê a célula descarregada. É o comportamento correto — o
> nPM1300 não tem UVLO de bateria, e é justamente por isso que o PCM é
> obrigatório ([15](../docs/15-avaliacao-componentes.md#bateria)) —, mas
> muda o que se espera na bancada.

## J103 · Painel solar

**JST S4B-ZR-SM4A-TF** na placa e **ZHR-4** no cabo, com terminais
SZH-002T-P0.5. Série ZH, passo de 1,5 mm, 4 vias, SMD lateral, com trava.

> [!IMPORTANT]
> **Os seis módulos não são soldados na placa, e não há um conector por
> módulo.** Eles ficam nas paredes da caixa, virados para o sol — dois na
> face inclinada e dois em cada chanfro —, enquanto a placa fica dentro,
> atrás do display. Entre os dois há **um chicote**, e ele entra na placa
> por **um único conector de 4 vias**. Quem junta os módulos é o chicote,
> não a placa.

### Pinagem

| Contato | Sinal | O que chega nele |
|---|---|---|
| 1 | `PV_A` | o **positivo** dos dois módulos da **face inclinada** (`PV101`, `PV102`), já unidos no chicote |
| 2 | `PV_B` | o **positivo** dos dois módulos do **chanfro esquerdo** (`PV103`, `PV104`), já unidos |
| 3 | `PV_C` | o **positivo** dos dois módulos do **chanfro direito** (`PV105`, `PV106`), já unidos |
| 4 | `GND` | o **negativo dos seis**, todos unidos num fio só |

### Por que quatro vias e não doze

Os seis módulos ficam **em paralelo**, e isso não é escolha de arranjo: é
obrigação. Cada KXOB25-05X3F já tem 3 células em série e abre em **2,07 V**,
e o MPPT do colhedor rastreia de 0,12 a **2,73 V**. Dois módulos em série
dariam 4,14 V, 1,4 V acima do teto
([04](04-pcb-e-caixa.md#como-os-painéis-chegam-à-placa)).

Em paralelo, os seis negativos são **o mesmo nó elétrico**. Levar seis fios
de terra até a placa seria repetir o mesmo nó seis vezes: mais crimpagem,
mais conector, e um corpo de 6 vias que tem 13,5 mm e faria sombra no sensor
de luz ambiente, que pede o dobro da própria altura livre em volta.

Os positivos poderiam ser um só pela mesma lógica, mas são **três**, um por
face, de propósito: na placa cada um passa por um resistor de 0 Ω
(`R113`, `R114`, `R115`) antes de se juntarem. Abrindo um deles, mede-se
**uma face sozinha no sol**. Com um fio só, os seis dariam um número só e
nunca se saberia qual face está rendendo.

### Como montar o chicote

São **12 pontos de solda nos módulos** e **4 terminais crimpados** no
conector.

Como ligar os seis módulos solares na placa: onde fica cada módulo na caixa, o chicote desenrolado com os 12 pontos de solda e as 4 emendas, e o conector J103 na placa com os três resistores de 0 Ω

O desenho acima está **em escala** e sai de
[`tools/docs/solar_harness_drawing.py`](../tools/docs/solar_harness_drawing.py):
os módulos têm os 23 × 8 mm de verdade, o conector tem o passo de 1,5 mm de
verdade, e o `J103` está na posição que ocupa na placa. Ele é a folha para
levar à bancada.

Passo a passo:

1. **Solde um par de fios em cada módulo**, no `+` e no `−` da serigrafia do
   verso. A ficha do KXOB25-05X3F **não numera os terminais**: ela só marca
   `+` e `−` no desenho do verso, e é essa marca que vale.
2. **Una os dois positivos de cada face** numa emenda, e leve um fio dessa
   emenda ao conector. São três emendas, uma por face.
3. **Una os seis negativos** numa emenda só, e leve um fio dela ao contato 4.
4. **Crimpe os quatro fios** nos terminais SZH-002T-P0.5 e encaixe na
   carcaça ZHR-4, na ordem da tabela acima.

**Fio:** a corrente máxima do arranjo inteiro é **110 mA**, e a de uma face
é 37 mA. O terminal SZH-002T-P0.5 aceita de **AWG 32 a 28**; AWG 28 é o que
usar, com folga de sobra em corrente e a flexibilidade que um fio dentro de
caixa precisa.

> [!WARNING]
> **Confira a polaridade com um multímetro antes de plugar, com os módulos
> no sol.** O conector certo já impede plugar a bateria aqui — a célula usa
> um **JST GH de 1,25 mm** e os dois não entram um no outro, de propósito
> ([J102](#j102--bateria)) —, mas **fio invertido no crimp é erro de
> bancada, não de projeto**. O `D105` na entrada é o grampo que existe para
> esse caso, e **a peça dele ainda não foi escolhida**: até escolher, a
> proteção é o multímetro.

> [!NOTE]
> **A ordem das quatro vias no chicote ainda não foi conferida contra um
> conector real.** A tabela acima é a ordem dos pinos do footprint; confirme
> o contato 1 na marca da carcaça antes de crimpar.
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

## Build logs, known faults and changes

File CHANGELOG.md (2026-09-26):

# Changelog

Mudanças relevantes do projeto. Formato inspirado no [Keep a Changelog](https://keepachangelog.com/pt-BR/1.1.0/); a versão do firmware é a de `APP_VERSION_*` em `zephyr_app/include/app_types.h`. Toda mudança entra em **Não lançado** no mesmo commit do código.

## [Não lançado]

Revisão completa de 2026-09-18: análise do legacy e do port, migração para o NCS v3.3.0, correções críticas, testes de host e documentação. Nada foi testado na placa nem no nRF52840-DK.

### Adicionado

- **A licença do projeto: CC BY-NC 4.0** (`LICENSE` na raiz, decisão do dono em 2026-09-26: código aberto, sem uso comercial). O arquivo traz o aviso do projeto, o que a licença cobre (o que é obra do projeto em `zephyr_app/`, `hardware_gnssbike/`, `docs/` e `tools/fw`, `tools/docs`, `tools/ui`), o que não cobre (as bibliotecas e ferramentas de terceiros, com as licenças de [`docs/12`](docs/12-ferramentas-testes.md#bibliotecas-e-licenças); o NCS, o Zephyr e o `sdk-ant`, que não estão aqui; o material ANT+, que não pode estar) e o texto legal completo da Creative Commons. É a mesma licença do stravaV10, de que o port deriva, então a atribuição a Vincent Gollé e a restrição de uso não comercial valem sobre o todo. Não é uma licença OSI, que não admite restrição de uso. O README, o `docs/01`, o `docs/10`, o `docs/12`, o `legacy/README.md` e o `CLAUDE.md` deixam de dizer "a definir".
- **O dry run da caixa** (`hardware_gnssbike/caixa/dry_run_caixa.py`, pedido do dono em 2026-09-26): 13 regras medidas na mesma `Caixa` que desenha o PDF, as vistas e os STL — folga de toda peça sob a tampa (`CX1`) e sobre a célula ou o fundo (`CX2`), o teto do display (`CX3`), as capas sobre as chaves e os furos delas contra a janela (`CX4`), a janela contra o vidro (`CX5`), o entalhe e a porta do USB-C contra o `J101` e as bossas (`CX6`), bossas e pilares contra a célula e o verso (`CX7`), as bossas da tampa contra as antenas (`CX8`), as janelas do LED e do sensor, os furos do buzzer e do barômetro (`CX9`), os bolsos, coberturas e fendas de fio dos módulos, medidos no perfil do chanfro (`CX10`), o chanfro assentando na parede e a folga da face interna dele ao vidro, à placa, à célula e aos apoios (`CX11`), o berço da antena externa (`CX12`); a `CX13` diz o que só uma prova impressa mede. Uma regra que não acha o que medir **falha**. Na primeira rodada seis falharam, e cada uma mudou a caixa ou a placa ([10](hardware_gnssbike/10-dry-run-2026-09-26.md#adendo-da-tarde-a-caixa-medida-e-o-que-ela-mudou-na-placa)); depois, 12 cumpridas, 0 violadas, 1 não medida.
- **Na caixa: a porta do USB-C, o berço da antena GNSS externa e as fendas de fio dos módulos dos chanfros** (`hardware_gnssbike/caixa/make_caixa.py`): uma porta de 14 × 8,2 × 1,2 por fora da parede de baixo, em dois ressaltos, que fecha sobre o entalhe com 2 mm de aba (`caixa-porta-usb.stl`); um berço de 12,6 × 4,6 entre duas nervuras contra a parede de cima, com lábio, para uma patch de 12 × 12 × 4 em pé, com o rabicho U.FL a 15 mm do `J302`; duas fendas de 1,5 × 2 no fundo de cada bolso do chanfro, até a face interna.
- **`footprints.MODELO_GIRADO_VERSO` e `modelo_no_verso()`**: o giro e o deslocamento de um modelo de fabricante numa peça do **verso**, medidos — o `kicad-cli` espelha as ilhas do footprint no verso, mas não o modelo: o JST ZH do `J103`, certo na frente com (0°; 2,25; −2), caía 2,14 mm fora do `F.Fab` atrás e com os rabichos para o lado oposto ao das ilhas. Exportações do GLB com valores de prova, lidas de volta, deram **(180°; −2,25; 1,86)**: o corpo sobre o `F.Fab` (ME4), os rabichos do lado das ilhas (ME5) e o eixo certo (ME6). E a `ME4` passou a olhar a face da peça: só via corpos com z > 0,95 e, para o `J103` no verso, media o sensor de luz e o diodo da frente por cima dele.
- **Um corredor reservado para o par USB no colocador** (`make_pcb.corredores`), do diodo `D102` ao receptáculo `J101`: o `ligar_usb()` desenha as duas diagonais ali das posições reais, e o colocador não sabia; o furo M2 novo empurrou o `TP101` para cima do par (curto, isolamento de 0,071 e ponte de máscara no DRC).
- **O conector de depuração SWD de 10 vias, `J202`** (pedido do dono em 2026-09-26; `cad/parts.py`, `nets.py`, `footprints.py`, `make_pcb.py`, `blocos.py`): o Cortex Debug Connector de 2 × 5 a 1,27 mm, SMD, sem carcaça (2,5 mm: o blindado de 4,83 não cabe sob a tampa da caixa proposta; peça a escolher), em (11,3; 72,2), abaixo das teclas, **ao lado** do footprint Tag-Connect `J201`, nas mesmas redes (`SWDIO`, `SWDCLK`, `MOD_RESET`, `3V0` no `VTref`, `GND`), com a pinagem da ARM; é onde o adaptador Cortex-M de 9 vias do J-Link encaixa sem clipe. `SWDCLK` e `nRESET` dele são `passive` no ERC, para não haver duas saídas na mesma rede. O esquemático confere com a lista de nós; a placa foi recolocada e roteada de novo com ele ([06](hardware_gnssbike/06-conectores-e-pontos-de-teste.md#j202--depuração-swd-o-conector), [03](hardware_gnssbike/03-netlist.md), [05](hardware_gnssbike/05-materiais.md), [docs/14](docs/14-hardware-placa-nova.md), [docs/19](docs/19-lista-de-compras.md)).
- **Uma proposta de caixa em volta da placa, em 2D, 3D e STL** (`cad/make_caixa.py`, pedidos do dono em 2026-09-26): 62 × 104 × **17** mm (o conceito tinha 19; com 16 o USB-C e o conector SWD batiam na tampa), raio 7, paredes 2, chanfros de 45° nas arestas longas com dois módulos solares por lado e uma faceta plana abaixo das teclas com mais dois, todos em bolsos sob coberturas transparentes de 0,6 mm coladas num degrau, com furos de fio; a placa centrada e a 0,5 mm da parede de baixo, com o USB-C no entalhe da parede; a célula colada no fundo entre quatro nervuras; a placa numa bossa M2 e três pilares; o display colado por baixo da tampa em volta da janela; **as três capas das teclas espalhadas na largura do display**, no passo de 14 mm do conceito, cada uma com uma barra por baixo da tampa até a sua chave na placa (a zona da antena do módulo não deixa a terceira chave passar de x = 21,5), sob uma membrana de TPU num rebaixo; 4 parafusos M2 nos cantos; furos do buzzer e respiro do barômetro no fundo; janelas do LED e do sensor de luz em posições **propostas**, porque na placa os dois estão debaixo do display. Saem `gnssbike-caixa.pdf` (frente, por dentro, cortes A-A e B-B, detalhes da tecla e do bolso, premissas, o que não bate, peças), três vistas 3D (`gnssbike-3d-caixa-aberta/-frente/-explodida.png`, com o GLB da placa) e os STL `caixa-concha`, `caixa-tampa`, `caixa-tecla-1/2/3`, `caixa-membrana-teclas`, `caixa-cobertura-faceta` e `caixa-cobertura-chanfro` (sopas de triângulos para o fatiador, não sólidos de CAD). O que não bate está em [04](hardware_gnssbike/04-pcb-e-caixa.md#a-placa-de-hoje-dentro-da-caixa-do-conceito): um furo M2 da placa fica sobre a célula, o LED e o sensor de luz estão sob o display, cinco peças passam do teto das sombras. Os volumes do display e da célula em `make_3d.MONTAGEM`, que ainda eram os da placa de 55 mm, passaram aos da placa de 34 × 90 (`make_dxf.ZONES`).
- **Duas regras que perguntam ao modelo 3D de que lado ele está** (`dry_run_pcb.py`). A `ME4` só media se as ilhas ficam sob o corpo, e um corpo simétrico passa girado 180°. A **`ME5`** mede, para cada conector, se o que sai do corpo junto da placa — os rabichos de solda — sai pelo lado das ilhas de sinal (faces do GLB acima do cobre, fora do F.Fab, projetadas no eixo corpo → ilhas): o `J103` reprovou na primeira medida e foi corrigido. A **`ME6`** mede **todas** as 132 peças com corpo: o eixo do corpo contra o F.Fab (um 0402 é duas vezes mais comprido que largo) e, onde as fileiras de ilhas são desiguais, as pernas contra as fileiras: os quatro SOT-523 reprovaram e foram corrigidos. É a pergunta do dono sobre passivos e CIs "girados", respondida peça a peça em vez de a olho ([09](hardware_gnssbike/09-dry-run-da-pcb.md#as-regras-e-a-origem-de-cada-uma)).

- **O terceiro dry-run, sobre a placa roteada, o esquemático, a mecânica e as contas, em [`hardware_gnssbike/10-dry-run-2026-09-26.md`](hardware_gnssbike/10-dry-run-2026-09-26.md).** Três análises independentes (placa e roteamento; esquemático; cálculos e mecânica) e o que saiu delas, com o que foi corrigido no mesmo dia e o que fica para o dono. O achado grave que ninguém tinha visto: **a caixa desenhada é a da placa antiga, de 55 × 97**, e a posição do display e da célula sobre a placa de 34 × 90 não estava em arquivo nenhum — a regra `ME2` passava sem medir peça nenhuma. Agora as duas sombras existem como **proposta** em `cad/make_dxf.py`, a regra mede, e cinco peças não cabem (o conector da célula, o buzzer e o barômetro sob a célula; o conector do painel e o próprio receptor GNSS, de 2,70 mm, sob o display de 2,6). E dois conflitos que não são de altura: o display cobre 7,2 mm da antena GNSS e a célula de 60 mm não cabe entre as duas antenas (há 58,1 mm).

- **O corte térmico da carga solar voltou a existir, por comparador.** O ADP5091, que substituiu o AEM10900 no CAD em 2026-09-25, não tem entrada de temperatura, e o divisor do NTC estava na placa sem ninguém para lê-lo. Decisão do dono: o divisor `RT101`/`R106` alimentado pelo **próprio painel**, um TLV7031 comparando com a metade do `SRC` e a saída em OU de diodos (`D106`) no `DIS_SW`, o mesmo pino que o USB já usa para bloquear o solar. Só o lado quente: a carga abaixo de 0 °C ficou **em aberto**, registrada em [01](hardware_gnssbike/01-esquematico.md#folha-1--energia) e [07](hardware_gnssbike/07-sequencias-e-protecao.md#o-corte-térmico-da-carga-solar).

- **A tecla central chega ao P1.27 por um Schottky** (`D107`, decisão do dono): o nó do `SHPHLD` sobe até 5,5 V com o cabo e um pino de 3,0 V amarrado nele teria o diodo de proteção conduzindo. A leitura por GPIO fica, e a ligação dupla que o esquemático chamava de conflito deixou de ser ([03](hardware_gnssbike/03-netlist.md#interface)).

- **A regra `RT1` do dry-run conta os itens desconectados do DRC completo** (`--severity-all`), e o `check_pcb.py` diz que não os julga: até então o DRC rodava com `--severity-error`, que esconde os "não roteados", e os documentos anunciaram **"0 desconectados"** duas vezes com 47 e 55 ligações em aberto. O número honesto está em [09](hardware_gnssbike/09-dry-run-da-pcb.md).

- **O manual de montagem** (`tools/docs/assembly_manual.py` → [`docs/img/manual-de-montagem.svg`](docs/img/manual-de-montagem.svg)): as peças em escala e os oito passos, do chicote solar ao fechamento. Tem também **o aparelho montado**: a caixa vista de frente com os seis módulos nas paredes e a placa por transparência, e **dois cortes** — o A-A pela largura, que mostra os dois chanfros de 45° com um módulo em cada, e o B-B pelo comprimento, que mostra a frente inclinada e a pilha inteira dentro dos 19 mm. É o quadro que responde onde a placa fica em relação aos painéis, que é o que não dava para ver nos passos separados. Caixa de 62 × 104, placa de 34 × 90, display de 40,08 × 61,8, célula de 36 × 60, módulos de 23 × 8, e **cada conector na posição que ocupa no arquivo da placa** — quando um deles se move no CAD, a folha se move junto. A ordem tem motivo: o chicote vem primeiro porque é o único trabalho de bancada demorado e porque a polaridade se confere com os módulos no sol; os dois FPC do display entram **com a placa fora da cavidade**, porque a trava de um conector de 0,5 mm não se alcança com ela assentada; e a bateria liga antes de a placa entrar, porque o `J102` fica no **verso** e depois estaria contra o fundo da caixa. O manual também diz, em vermelho, as três coisas que **não estão definidas em arquivo nenhum**: como o módulo é preso à parede, como o painel é preso à frente e onde ficam os parafusos da caixa.

- **O desenho do chicote solar, em escala** (`tools/docs/solar_harness_drawing.py` → [`docs/img/chicote-solar.svg`](docs/img/chicote-solar.svg)). A seção do `J103` explicava a ligação em tabela e num diagrama de blocos, e o dono disse que continuava sem entender — com razão: **caixa ligada a caixa não mostra a ninguém o que montar**. O desenho mostra: onde cada um dos seis módulos fica na caixa, com o nome que ele tem no esquemático; o chicote desenrolado, com os módulos **vistos por trás**, que é o lado onde se solda, os 12 fios, as 3 emendas de positivo e a emenda dos seis negativos; e onde tudo isso entra na placa, com o `J103` na posição real, os três 0 Ω e o conector ampliado 4,8 ×. Está em escala de verdade — os módulos com os 23 × 8 mm da ficha, o conector com o passo de 1,5 mm —, e por isso serve de folha de bancada e não de ilustração.

- **O conector do painel solar ganhou documento, e o chicote dele ganhou peças.** O `J103` era o único conector da placa **ausente** de [06](hardware_gnssbike/06-conectores-e-pontos-de-teste.md), e por isso a pergunta mais prática do projeto — "vou soldar o positivo e o negativo em cada painel, e ligo onde?" — não tinha resposta em lugar nenhum. Agora tem: os seis módulos **não são soldados na placa** e **não há um conector por módulo**; eles ficam nas paredes da caixa e entram por **um conector de 4 vias**, com três positivos (um por face, para se poder medir cada face sozinha no sol abrindo o seu 0 Ω) e **um terra só**, porque em paralelo os seis negativos são o mesmo nó. O documento traz a pinagem, o porquê das quatro vias, o passo a passo dos **12 pontos de solda e 4 terminais crimpados**, a bitola do fio (AWG 28, para 110 mA no arranjo inteiro) e o aviso de conferir a polaridade no multímetro — o conector diferente já impede plugar a bateria ali, mas fio invertido no crimp é erro de bancada. E a **lista de compras não tinha as peças do chicote**: entraram a carcaça `ZHR-4`, os quatro terminais `SZH-002T-P0.5` e o fio.

- **Onze encapsulamentos com a cota do desenho mecânico da própria ficha**, em `footprints.PACOTE`: corpo, standoff, pad exposto, largura e comprimento do terminal, passo, e a figura ou tabela de onde cada número saiu. Entraram nesta passagem o **MX25R6435F** em SOP 8L 200MIL (página 79 da ficha v1.6: D 5,23, E1 5,28, A máximo 2,16, A1 0,15, b 0,41, L 0,65, e 1,27), o **BMI270** em LGA-14 (página 143 da BST-BMI270-DS000: D 3,00, E 2,50, A máximo 0,87, A1 0,13, e 0,50 BSC, com os oito pads laterais de 0,475 × 0,250 e os seis de topo de 0,250 × 0,475) e o **APTF1616**, que deixou de ser um bloco e virou o que é: corpo branco de 1,6 × 1,6 × 0,25 e lente `Water Clear` em tronco de pirâmide de 1,2 até 1,1, subindo a 0,7 — cotas do bloco `PACKAGE DIMENSIONS` da página 1 da Kingbright, com o que **não** está cotado dito como conta (a altura da lente) ou como leitura de foto (o branco do corpo). A conferência `ME3` compara o corpo da ficha com o contorno desenhado para ele, ignorando orientação, e passa nos onze. **O FH28 do display não entrou**: o PDF que está em `datasheets/` é só a folha de especificação ELC4-153887-02, **sem vista, sem corte e sem tabela de cotas** — e com isso os 3,4 × 10 mm que [04](hardware_gnssbike/04-pcb-e-caixa.md) usa para a área do FPC ficam **sem origem verificável**, o que virou linha de pendência.

- **A vista da pilha montada**, `cad/gnssbike-3d-montagem.png`: display em cima, placa no meio, célula LiPo embaixo, aberta para as três serem visíveis de uma vez. Cada retângulo e cada vão sai de uma linha da tabela de zonas de [04](hardware_gnssbike/04-pcb-e-caixa.md) — o display de 40,08 × 61,8 mm em x 7,46–47,54 e y 5,1–66,9 com teto de 2,6 mm, a bolsa de 36 × 60 × 7 mm em x 9,5–45,5 e y 22,5–82,5 com teto de 1,2 mm. Os seis módulos solares **não** estão lá de propósito: eles moram nas paredes da caixa e documento nenhum os põe nas coordenadas da placa, então desenhá-los sobre ela seria desenhar um palpite. Eles chegam pelos `J103` a `J105`, que estão na placa e têm corpo.

- **A placa em KiCad passou a ser medida, não só desenhada.** Duas
  ferramentas novas em `hardware_gnssbike/cad/`: o `route.py`, que roteia
  metade das ligações (90 de 177) sem violar uma regra de projeto sequer, e
  o `dry_run_pcb.py`, que confere a placa contra as regras que as fichas dos
  componentes e a IPC-2221B impõem e que verificação de regras nenhuma
  conhece — distância da antena a conversor chaveado, desacoplamento por
  valor, largura por corrente, costura de terra, a placa dentro da caixa.
  O resultado está em [`hardware_gnssbike/09-dry-run-da-pcb.md`](hardware_gnssbike/09-dry-run-da-pcb.md):
  **8 regras cumpridas, 1 marginal, 3 que só a bancada ou o fabricante
  decidem**. Nada foi fabricado nem medido.

- **A ficha do LPM027M128C, e com ela a pendência que travava o layout.** A JDI tirou as fichas de MIP do ar — os dois PDF dela respondem 404 e o arquivo histórico está bloqueado —, mas a Switch Science, que vendia o módulo, publica as especificações citando a `3LPM027M128C specification ver.02`. E elas respondem a pergunta: a luz do C **não** passa pelo FPC de 10 vias, como se suspeitava. Ela tem **conector próprio, de 5 vias e passo de 0,5 mm**, ao lado do de sinal. O `J402`, que existia para o filme da Sharp, passou a ser esse conector — e o Molex de 4 vias que estava lá **não serve**. A mesma ficha confirma, com número em vez de hipótese, os **2,67 V e 16 mA** com que os 39 Ω do `R_BL` foram calculados, e explica por que a luz vem do `3V3BL` e não do `3V0`: com 3,0 V o resistor cairia para 17,5 Ω e a corrente ficaria refém da tolerância da tensão direta. O consumo do painel também saiu da ficha: 5 µW parado, 30 µW a 1 quadro/s e 180 µW a 10. **O que resta é menor e não trava o layout**: a ordem das cinco vias, que não está em fonte nenhuma, e a escolha da peça — posicionar o conector já dá, rotear é que espera.

  Duas referências encontradas no caminho e registradas: o [`pizero_bikecomputer`](https://github.com/hishizuka/pizero_bikecomputer), um ciclocomputador que usa **exatamente este painel** e aciona a luz com um GPIO em PWM, e a [`JDI_MIP_Display`](https://github.com/Gbertaz/JDI_MIP_Display), que publica esquemático, BOM e Gerber de uma placa de teste para o **B com luz**. A segunda serve de referência de topologia, **não de pinagem**: ela usa FPC de 4 vias e o autor registra que os 820 Ω dele deixaram a luz fraca.

- **O esquemático fechado** (`hardware_gnssbike/`, de 4 para 7 documentos e de 1.400 para 3.315 linhas). Entraram os dois documentos que faltavam — [06](hardware_gnssbike/06-conectores-e-pontos-de-teste.md), com cada conector pino a pino e dezesseis pontos de teste, e [07](hardware_gnssbike/07-sequencias-e-protecao.md), com a ordem em que os trilhos sobem e descem e o que protege o que sai da caixa — e **nove contas novas**: o orçamento do USB (671 mA, e a carga cai para 429 mA numa fonte comum), a autonomia dos dois extremos (25 h no pior caso, 115 h no típico, que **bate exatamente** com o orçamento de energia de [13](docs/13-placa-nova.md), escrito separado), a corrente de cada trilho para a largura de trilha, o calor da caixa inteira (de 8 a 16 °C acima do ambiente, e só carregando), a topologia do painel (paralelo, porque seis em série dariam 12,4 V, e sem diodo de bloqueio, porque um módulo sombreado fica em 0,56 V por célula, abaixo do joelho), o capacitor de volume do módulo, a proteção das teclas, o resistor de série do buzzer e o do SPI da flash. O esquemático ganhou **20 componentes** que essas contas criaram, e nenhum é enfeite: cada um sai de uma conta ou de um modo de falha descrito. A lista de conferência **antes de mandar fabricar** tem 19 itens, e enquanto houver item aberto nas duas primeiras seções o esquemático não vira layout.

- **O segundo dry-run, sobre o esquemático completo**, em duas passagens independentes como o primeiro. Achou **65 problemas, 2 graves**, e de novo quase tudo era erro de quem escreveu, não das fontes. Os dois graves foram no **LED RGB**, a mesma peça duas vezes: na primeira rodada o catodo estava no pino do MCU, cujo anodo chega a 5,5 V com o cabo — corrigido com um MOSFET por cor; na segunda descobriu-se que o resistor tinha ficado **do lado errado**. O LED é de **anodo comum**: os três dies dividem um pino, de modo que não existe resistor por cor no anodo, e com o resistor ali ele fica **em paralelo com o die**, que passa a ver o `VSYS` nu. O resistor vai entre cada catodo e o seu MOSFET. E a mesma inversão estava na luz do display. Dos médios: o `MISO` da flash levava resistor de série na ponta que **recebe**, onde ele não amacia borda nenhuma; o divisor do `DIS_STO_CH` — o único intertravamento que não passa por firmware — não tem orientação definida em fonte nenhuma, e as duas óbvias dão 5,0 V ou 0,5 V num pino referenciado ao `VINT`; a derivação da tecla central para o `SHPHLD` não estava dita como saindo **depois** do resistor de proteção, sem o que a rede protege só um dos dois ramos; e a lista de materiais montava **os dois** caminhos do termistor do colhedor, que é exatamente o caso que mata a carga solar.

- **Quatro defeitos de firmware que o esquemático expôs**, todos registrados em [10](docs/10-status-do-port.md#defeitos-abertos): ninguém liga a chave de alimentação da flash, e **junto com isso** o serviço de armazenamento aciona um SPI de 8 MHz contra uma peça sem `VCC`, que se alimenta pelos diodos de grampo; o buzzer e o LED RGB **não têm código nem canal** — o devicetree declara um canal de PWM em cada e nada em `src/` os menciona, de modo que a contrafase que dá os 6 Vpp não existe e das três cores só a primeira acenderia; com a Sharp, que era a tela que a lista comprava, o **COM fica em 1 Hz com a luz acesa**, porque a interface pede 120 Hz, o driver recusa acima de 20 Hz e ninguém lê o erro (**esse deixou de existir em 2026-09-23, com a troca da tela pelo JDI**, cujo limite é 140 Hz); e o driver do AEM10900 não grava `TMONEN`, `HPEN` nem `KEEPALEN`, embora o keep-alive seja o que faz a configuração sobreviver ao trilho desligado.

- **Contas que estavam erradas e foram refeitas.** O calor dentro da caixa não é "o carregador mais a perda dos reguladores": é **tudo o que entra pelo cabo e não vira química na célula**, 1,89 W e não 1,54 W, o que põe a caixa em **44,7 °C** com 25 °C de ambiente e o pior coeficiente — **empate com o corte de 45 °C do JEITA, antes de qualquer sol**. A junção do carregador, pelo mesmo motivo, vai a cerca de 93 °C e não aos 73 °C que usavam o ar de fora. O buzzer estava contado com 3 V na média e 6 V no pico, e a constante de tempo com um resistor quando o laço tem dois. E a "conferência cruzada" dos 115 h de autonomia era circular: os 58 mW vêm do orçamento de energia e a divisão é a mesma.

- **Três achados que só apareceram ao desenhar**, todos com a conta ao lado. **Um termistor para o AEM10900, nunca dois**: a fonte oferece o do pack *ou* um SMD na placa, e montar os dois põe 10 kΩ em paralelo com 10 kΩ no `TH_MON` — 5 kΩ, que com B3380 equivalem a **44,4 °C** contra o corte de 45 °C do colhedor, de modo que a carga solar morreria com o ambiente pouco acima do de uma sala, sem erro e sem aviso. **Ninguém liga a chave de alimentação da flash**: o `LDO1` do nPM1300 está no devicetree sem `regulator-boot-on` e sem apelido, a `mx25r6435f@0` não declara `supply` e nada em `src/` referencia o regulador — na placa do projeto isso é armazenamento sem energia, em silêncio, e no DK não aparece porque lá a flash é alimentada pelo kit. E **o firmware não assina `NPM13XX_EVENT_SHIPHOLD_PRESS`**: hoje ele lê a tecla central por P1.27, que é justamente a ligação em conflito com a especificação de hardware.

- **A busca por uma tela com luz**, pedida pelo dono com teto de R$ 509, registrada em [15](docs/15-avaliacao-componentes.md#a-luz-da-tela-procurada-em-2026-09-23). Achou um fato que muda a pergunta: **estas telas não aceitam backlight**. São MIP refletivas, e luz atrás delas não ilumina nada; o que elas usam é **luz frontal**, um guia de luz laminado sobre o vidro — óptica especializada, e é por isso que o filme custa US$ 66,45, que é 38 % da lista inteira. A única forma de a luz sair barata é vir integrada de fábrica, que é o que o LPM027M128**C** tem e o **B**, a tela decidida, não tem. Dentro do teto não há nada melhor do que a lista já escolhe: a Sharp com o filme Azumo dá cerca de R$ 486, e o filme escolhido é o **mais barato** da família. Também se achou que existiu um filme Azumo feito para o JDI B (`12380-06_T3`), hoje obsoleto, e que o **C** aparece no AliExpress a partir de R$ 324 — em anúncios que nomeiam o B e o C no mesmo título, o que é cara ou coroa justamente na característica que se compra. **O dono decidiu por cima disso no mesmo dia**, e passando do teto: o C por R$ 776, num anúncio que diz WLED (ver Mudado).

- **O esquemático da placa, numa pasta nova** (`hardware_gnssbike/`, com `README.md`, as seis folhas em `01`, os cálculos em `02`, a lista de nós em `03`, a placa e a caixa em `04`, os materiais por folha em `05` e a ferramenta `net_check.py`). Até aqui o projeto tinha a especificação do hardware ([14](docs/14-hardware-placa-nova.md)), a avaliação de cada peça ([15](docs/15-avaliacao-componentes.md)) e a lista de compras validada ([19](docs/19-lista-de-compras.md)), e **nenhum lugar onde as três virassem circuito**: nó com nome, passivo com valor, e o pino do devicetree ligado ao pino do componente. Agora há. Os valores saem de conta feita à vista ou de ficha citada, e o que depende de medida está dito como dependendo de medida. O `net_check.py` lê a lista de nós e o devicetree e reclama quando os dois discordam — pino do firmware que o esquemático não tem, pino do esquemático que o firmware não usa, pino em dois nós, pino além do tamanho da porta, nome de nó repetido; quatro mutações, quatro mortas. **Nada foi montado: não há placa, não há layout, nenhum componente passou por bancada.**

- **O dry-run do esquemático**, em duas passagens independentes: uma refez todas as contas e procurou contradição interna, a outra conferiu folha por folha contra o [13](docs/13-placa-nova.md), o [14](docs/14-hardware-placa-nova.md), o [15](docs/15-avaliacao-componentes.md), o [19](docs/19-lista-de-compras.md) e o devicetree. Acharam **43 problemas, 6 graves**, e quase todos os graves eram **erro de quem escreveu o esquemático, não falha da especificação** — o projeto já tinha a resposta certa e o rascunho não a leu com cuidado. Os seis: (1) os canais do TXU0204 têm **direção fixa**, e o rascunho pôs o `RX` num canal que vai do MCU ao receptor e o `RESET_N` num que vai do receptor ao MCU, **saída contra saída nos dois pares** — e daí concluiu que "cinco sinais não cabem em quatro canais", quando o `RESET_N` **não passa pelo tradutor**, como o [14](docs/14-hardware-placa-nova.md#gnss) já dizia; (2) o rascunho criou um resistor de medida **externo** de 7 mΩ, com pinos `CSP`/`CSN` que o CI não tem, quando o sensor é **interno** à `MAX17262REWL+T` — montado assim a resistência dobra e o medidor erra toda corrente; (3) o `STO_CFG[1]` do AEM10900 não estava em nó nenhum, e é ele que decide o limiar de carga da célula ao sol; (4) o `OE` do tradutor idem, e aberto deixa as saídas indefinidas na partida; (5) o `CSB` do BMP585 e do BMI270 estavam só em prosa, de modo que os dois nasceriam em SPI e o barramento não acharia ninguém; (6) o LED RGB com o catodo no pino do MCU, cujo anodo chega a 5,5 V com o USB. Os seis foram corrigidos. **Passar no `net_check.py` não quer dizer que o circuito está certo**: ele confere pinos do MCU contra o firmware, e imprimiu "batem" com três desses erros dentro — o README diz isso agora com todas as letras.

- **Três decisões que só apareceram porque alguém desenhou**, e que ficam para o dono: a **tecla central está ligada em dois lugares** (quatro documentos dizem que ela vai só ao `SHPHLD`, e o devicetree declara `key_centre` em P1.27; em ship mode o diodo de proteção do pino grampeia o `SHPHLD` e o PMIC pode ler tecla presa — resolver muda o firmware); a **tela decidida não tem luz** (o JDI LPM027M128**B** é a mesma tela sem backlight, e quem tem é o **C**, sem canal autorizado de compra) — **resolvida no mesmo dia: o dono escolheu o C**, e a decisão está em Mudado; e a **antena escolhida não cabe na zona reservada** (10,75 mm contra os 8 mm da faixa de `docs/14`).

- **O ANT+ abre canais** (`src/rf/ant/ant_channel.c` e `include/rf/ant_channel.h`, `src/rf/ant/ant_sensors.c` e `.h`, mais a ligação do radar e do medidor de potência). Era 35 linhas: a pilha subia, a chave ANT+ entrava na rede e **nenhum canal era aberto**, de modo que nenhum sensor ANT+ podia ser encontrado — e a maioria dos equipamentos de ciclismo fala ANT+. Agora há o mecanismo: um canal escravo com número de dispositivo curinga, que acha o sensor que estiver perto, uma busca limitada a 30 s (um canal buscando para sempre mantém o rádio ligado e a bateria descendo atrás de um sensor que não existe) e o travamento no número de série depois da primeira mensagem, para seguir o sensor do ciclista e não o da bicicleta que passou. Quatro usos: frequência cardíaca, cadência, potência e radar. **Os parâmetros continuam fora**: tipo de dispositivo, período e frequência são dos perfis ANT+, sob licença que proíbe redistribuir, e vêm do Kconfig, onde são zero; a decodificação das páginas é função fraca definida em `src/rf/ant/sensor_pages.c`, que o `.gitignore` mantém fora. Um canal com tipo zero não abre e responde `-ENOTSUP`, que é como todo o ANT+ se comporta neste repositório: presente, ligado e calado. Quem tem sensor Bluetooth não precisa de nada disso. **Nada foi testado com sensor nenhum.**

- **O `$QRY` responde** (`src/model/qry.c` e `.h` com `test_qry` de 19 casos, `src/app/app_cmd.c`). Era um toco que devolvia `$QRY,0` e registrava "not answered yet". O `$QRY` **não existe no legacy** — é invenção do port —, então a semântica foi definida aqui: `$QRY,1` lista o que há no armazenamento (uma linha por arquivo com nome e tamanho, e `END` com a contagem), `$QRY,3,<nome>` apaga um arquivo, e **`$QRY,2` recusa de propósito**. Mandar arquivo pela serial em notificações de vinte bytes seria mais lento e sem nada do que o mcumgr sobre SMP já faz com deslocamento, soma de verificação e retomada; a resposta aponta para lá (`ERR,USESMP`). Apagar passa pela política de `model/file_policy.h`, que já existia para as transferências pelo ar: **uma atividade não pode ser apagada pela serial**, porque apagar é escrever e a regra já dizia que atividade sai e não entra. Quatro horas de pedal não vão embora porque alguém mandou uma frase. Os motivos vão em palavra (`NOTFOUND`, `FORBIDDEN`) e não em número, porque quem lê é uma pessoa num terminal ou um script.

- **A placa própria do projeto existe no firmware** (`zephyr_app/boards/gnss/gnssbike/`, alvo `gnssbike/nrf54lm20a/cpuapp`, e `tools/fw/board_check.py`). Até aqui só havia overlay do **nRF54LM20 DK**, que põe os periféricos da placa em pinos livres de um kit; agora há a placa: cada dispositivo que o aparelho carrega, no pino em que ele o carrega, com `board.yml`, `.dts`, pinctrl, Kconfig e defconfig. Escrever o devicetree achou três coisas que a alocação de pinos do [14](docs/14-hardware-placa-nova.md#alocação-de-pinos) não previa, todas do silício e nenhuma visível no papel:
  1. **`i2c30` e `uart30` são o mesmo bloco serial.** Cada bloco do nRF54LM20A tem um periférico; a alocação punha o I²C da energia e o console do lado. O console foi para o bloco 20 (P1.00 e P1.31).
  2. **O MCUboot é construído do mesmo arquivo de placa** e não tem driver de flash SPI: uma `fixed-partitions` na NOR externa a punha no mapa de flash de todas as imagens e deixava o bootloader ligando contra um dispositivo que nunca foi compilado. A tabela de partições e o disco foram para o overlay da aplicação.
  3. **O driver do GNSS inicializava antes do regulador que o alimenta** (prioridade 80 contra 86 do nPM1300). Isso só apareceu porque a placa declara `vcc-supply = <&npm1300_buck1>`, que o overlay do DK não tem; o Zephyr recusa o link e a prioridade do receptor passou para 90.
  O microSD saiu da definição: um arquivo de placa descreve **uma** placa, e a do produto não tem soquete (decisão do dono em 2026-09-20). O `board_check.py` confere o mapa a cada mudança — pino em dois lugares, SCL e SCK fora dos pinos de clock (tabela 79), pads do NFC e do cristal ocupados, pino além do tamanho da porta, dois periféricos no mesmo bloco serial e apelido que falta — e foi ele que mostrou que o RESET_N do GNSS estava planejado e não ligado. Sobram 31 pinos livres, 12 deles de clock. **Nada disso foi montado: não há esquemático nem unidade**, e o mapa ainda precisa ser conferido contra a pinagem do módulo BM20C quando ela chegar.

- **Notificações do celular na tela** (`src/model/notif_filter.c` e `.h` com `test_notif_filter` de 23 casos, `src/rf/ble_ancs_client.c` e `.h`, Kconfig do ANCS). Uma chamada, uma mensagem ou um lembrete de agenda aparecendo no guidão, para o ciclista decidir se vale tirar a mão do guidão. O transporte é o **Apple Notification Center Service** e o cliente é o que o nRF Connect SDK já traz (`bt_ancs_client`), como manda a regra de usar os subsistemas do SDK; nada dele foi reescrito. Vale para **iPhone**: o serviço é da Apple, e o Android não tem equivalente a que um aparelho simplesmente se conecte — precisaria de um app próprio, que este projeto não tem. O trabalho de verdade está no **filtro**, que é módulo à parte e testado: o celular entrega tudo o que tem, e quem vê tudo desliga o recurso antes do fim do primeiro pedal. As regras, em ordem: o que o celular marca como **pré-existente** é descartado (senão uma manhã de mensagens não lidas cai na tela na primeira pedalada), evento de remoção não mostra nada, **chamada recebida passa por cima de todas as outras regras**, o modo "só chamadas" serve para treino duro, o que o celular silenciou fica silencioso, categoria desligada não passa, identificador repetido não passa (mensagem editada chega de novo com o mesmo) e nada dentro de 20 s da anterior passa, a menos que o celular a marque como importante — um grupo faz trinta notificações por minuto. Achado ao escrever o teste: o identificador **zero** colidia com os espaços vazios do anel de repetidas, e a primeira mensagem de um pedal sumia. No nRF52840 o SMP, o pareamento e o ANCS levam a RAM a 90,0 %; no alvo de verdade, o nRF54LM20A, ficam em 74,8 %. Não testado com celular nenhum.

- **Treino estruturado e controle ERG do rolo** (`src/model/workout.c` e `.h`, `test_workout` com 32 casos, arquivos `.WKT` listados pelo armazenamento, comandos `APP_CMD_WORKOUT_SELECT`, `_START` e `_STOP`). "Dez minutos leve, depois quatro vezes cinco minutos a 280 W com três de intervalo, depois dez leve": qualquer outro ciclocomputador aceita isso e conta regressivamente, e este não aceitava — e o `ble_fec_client_set_target_power()` que já existia não era chamado por ninguém, de modo que o rolo era **assistido e nunca comandado**. O arquivo é texto, uma instrução por linha (`NAME`, `S`, `REPEAT`, `END`, `#`), no espírito dos arquivos de percurso do projeto; um passo termina por tempo, por distância ou **na tecla de volta**, e mira potência, batimento, cadência ou nada. As repetições são **achatadas** na carga — `REPEAT 4` sobre dois passos vira oito —, o que custa memória e paga uma contagem que nunca precisa perguntar onde está e um "passo 6 de 11" que quer dizer isso mesmo. Um arquivo que não cabe ou que tem uma linha errada é recusado **inteiro**: meio plano é pior que nenhum, porque o ciclista pedalaria o treino errado sem saber. No ERG o rolo recebe o meio da faixa, e só dentro de casa: pedir watts a uma máquina que não está ali não faz sentido. Não testado com rolo nenhum.

- **Alertas configuráveis** (`src/model/alerts.c` e `.h`, `test_alerts` com 22 casos, comando `APP_CMD_SET_ALERT`, guardados nas configurações). Doze: frequência cardíaca, potência, velocidade e cadência, cada uma alta e baixa; distância a cada tanto; tempo, beber e comer a cada tantos minutos **em movimento**, de modo que uma hora no café não aproxima o próximo lembrete. O alerta em si é uma comparação; o que o módulo resolve é **não encher o saco**: quem fica exatamente no limite é avisado uma vez, não a cada época, e só volta a ser avisado depois de cair de volta para dentro por uma margem (3 bpm, 15 W, 1,0 km/h, 3 rpm — absolutas, porque 5 % de 40 bpm é 2 e 5 % de 1.000 W é 50) **e** depois de um minuto. Um alerta "abaixo de" só fala depois que a grandeza apareceu, senão uma cinta desconectada, que lê zero, diria que o coração parou. Um salto que passa dois marcos de distância de uma vez avisa uma vez. As configurações ganharam a versão 4: um bloco salvo pela anterior é descartado pela checagem de versão, como já era o desenho.

- **Cliente de medidor de potência**, por Bluetooth e por ANT+ (`src/model/cps_parse.c` e `.h` com `test_cps_parse` de 23 casos, `src/rf/ble_cps_client.c` e `.h`, `src/rf/ant/power_ant.c` e `include/rf/power_ant.h`, ligação no gerenciador BLE, no serviço de rádio e no modelo). Era a maior lacuna do port: havia cliente de frequência cardíaca, de cadência, de rolo e de radar, mas **nenhum** de potência, e ao ar livre a potência na tela era só a **estimativa** da fórmula do legacy sobre velocidade, inclinação e peso. Agora quem tem medidor vê o que o medidor diz, e `ride_power_w()` no serviço do modelo escolhe: medidor fresco primeiro, depois o rolo, depois a estimativa. A leitura da característica (0x2A63) fica num módulo puro porque a caminhada pelos campos opcionais é onde moram os erros — a armadilha é que **o relógio da roda bate a 1/2048 s** enquanto o da pedivela e os dois do serviço de cadência batem a 1/1024 s, e quem assume um só reporta o dobro ou a metade da velocidade. Vêm junto o balanço entre as pernas, o torque acumulado, a energia e o pedido de zero offset. O lado ANT+ segue o mesmo arranjo do radar: a tubulação está aqui e o perfil Bicycle Power fica fora do repositório (`CONFIG_GNSS_ANT_POWER_DEV_TYPE` é zero, `src/rf/ant/power_pages.c` está no `.gitignore`), porque a licença do perfil proíbe redistribuir e o repositório é público. A ordem e as larguras dos campos vêm da especificação como este port a entende: **nenhum medidor foi à bancada**, e a primeira sessão com um deve confirmar a caminhada pela cadência, onde um deslocamento aparece na hora.

- **Potência normalizada, fator de intensidade, estresse de treino e índice de variabilidade** (`src/model/power_metrics.c` e `.h`, `test_power_metrics` com 19 casos, faixa nova na tela do rolo). São os três números que um ciclista com medidor de potência olha no fim do pedal, e que faltavam: duas horas firmes a 200 W e duas horas alternando 100 e 300 W têm a mesma média e custam coisas muito diferentes ao corpo. O método é o de Andrew Coggan, o mesmo de todo head unit e de todo site de treino: média móvel dos últimos 30 s de potência, cada valor elevado à quarta, média disso, raiz quarta. Daí saem IF (`NP/FTP`), TSS (`t × NP × IF / (FTP × 3600) × 100`, de modo que uma hora exata no limiar dá 100) e VI (`NP/média`, que diz o quanto o pedal foi irregular). O modelo alimenta **um valor por segundo de tempo em movimento** — o cronômetro da atividade já tira as pausas, então parar no semáforo não enche a janela de zeros. Sem FTP configurado, IF e TSS ficam em zero em vez de inventar número. Uma potência acima de 2.500 W entra como zero, não como descarte, porque descartar deslocaria a janela. Não testado com medidor nenhum.

### Corrigido

- **O STEP do conector do filme de luz (`J402`, HCTL HC-FPC-05-10-5RLTAG) estava 180° fora do footprint, e o dono viu no 3D.** Medido no GLB exportado, por cor: os cinco contatos dourados corriam de x 3,14 a 6,33 da placa, com os rabichos saindo do corpo branco (x 3,71 a 6,53) pela **esquerda**, sobre nada, enquanto as ilhas de sinal ficam em x 6,63, à direita, e as de fixação em 3,82, à esquerda. A `ME5` e a `ME6` deixaram passar porque pesam área: a chapa metálica das unhas de fixação, que no modelo errado ficava do lado das ilhas (até x 7,75), pesa mais que cinco rabichos de 0,3 mm. Agora `footprints.MODELO_GIRADO` gira esse modelo 180° (sem deslocamento: os contatos passam a correr de 3,87 a 7,06 e saem do corpo sobre as ilhas; medido com exportações de prova) — e a linha de modelo dos footprints **gerados** passa pela mesma `linha_de_modelo()`, porque o bloco deles escrevia `rotate 0` fixo e a tabela nunca chegava à placa —, `dry_run_pcb.CONTATOS_POR_COR` guarda a cor dos contatos desse modelo e as duas regras medem por ela quando ela existe (a versão errada passa a acusar −0,26 mm, lado oposto; a certa, +0,26), e a `mecanica()` da `ME5` reconhece `MP1`/`MP2` como ilhas de fixação (antes contavam como sinal e puxavam o centro das ilhas para as unhas).
- **O chanfro da tampa não segurava o módulo solar.** A 6,2 mm a rampa de 45° tem 8,8 mm e o módulo de 23 × 8 ocupa 8,4 atravessado nela: o degrau da cobertura passava das duas pontas, e o bolso de 2,5 atravessava a tampa de 1,5. Agora o chanfro tem **7,5** (rampa de 10,6, paredes de 1,1 nas pontas e 0,5 atrás do bolso, `CHANFRO_ESP`), a face é rebaixada de 0,6 no vão dos dois módulos e recebe uma **tira** transparente de ponta a ponta (a rampa não tem lugar para degrau), a face interna do sólido é paralela à rampa até 1,0 mm do vidro e sobe vertical dali, e a placa da tampa começa em x 7,5 ao lado dos chanfros — de x 2 ela **atravessava a rampa 2,7 mm** em z 15,5. Tudo medido pela `CX10` e pela `CX11` ([04](hardware_gnssbike/04-pcb-e-caixa.md#a-placa-de-hoje-dentro-da-caixa-do-conceito)).
- **Os furos das capas das teclas entravam 1,3 mm no vidro do display.** O display acabava 1,5 mm acima das chaves e a capa tem 5,6: subiu 1,6 mm na placa (`make_dxf.DISPLAY_Y1` = 62,9, a sombra `SOMBRA_DISPLAY_JDI_MAX_3-0MM`), porque as teclas não podem descer (o SWD, o conector da célula e o USB-C ocupam y 67,75 a 85,44 até 0,4 mm) e o dono quer as capas exatamente sobre as chaves. Custa 1,6 mm a mais de vidro sobre a área da antena GNSS (8,8 dos 9,88), conflito já registrado.
- **Três regras do `dry_run_pcb.py` acusavam o que não existia.** `OP1` contava o barômetro do **verso** e os 0402 como vizinhos altos do sensor de luz (agora só a mesma face e só peças mais altas que o sensor); `ME6` chamava o `J202` de girado 90° medindo as faces do buzzer, que está no verso debaixo dele (`_faces_da_peca` separa as faces também para os corpos `.wrl`); `ME5` não achava rabichos no `J102` novo porque a biblioteca instalada não tem o modelo do JST SH (o STEP do kicad-packages3D está em `cad/3d/real/`, fora do git).
- **O colocador entrava em laço sem fim quando uma peça não cabia**: ela voltava para a mesma onda a cada volta, e cada volta refazia a espiral inteira (uma pilha de chamadas a cada dois minutos mostrou o `espiral()` para sempre). Hoje desiste dela e diz qual (`NAO COLOCADAS`).
- **O modelo 3D do conector do painel (`J103`) estava girado 180°, e o giro era meu.** Em 2026-09-25 eu tinha posto o STEP do JST ZH a 180° porque "a caixa batia com o F.Fab" — e batia nos dois sentidos, porque a caixa é simétrica e o desvio em Y foi absorvido pelo deslocamento. O dono viu no 3D as pernas de solda apontando para a borda e as ilhas para dentro. Medido no GLB: o que sai do corpo junto da placa estava 3,3 mm do lado oposto ao das ilhas. Sem giro e com o deslocamento resolvido por duas medidas de prova e um mapa linear — (2,25; −2,00) —, o corpo cai em x 27,00..33,00 e y 27,50..36,50, que é exatamente o F.Fab, e os rabichos ficam do lado das ilhas ([09](hardware_gnssbike/09-dry-run-da-pcb.md#resultado-da-posição)).

- **Os quatro MOSFET SOT-523 (`Q401`, `Q601` a `Q603`) apareciam deitados sobre as próprias ilhas.** A cota da ficha em `footprints.PACOTE` estava (1,60; 0,80) — D e E1 nos eixos da ficha —, e a tabela é no eixo do footprint, onde a fileira de pinos (D) corre em Y. O corpo saía 1,60 × 0,66 sobre um F.Fab de 0,80 × 1,60. A entrada virou (0,80; 1,60) e o corpo redesenhado mede 0,80 × 1,46.

- **O `make_3d.py` desenhava duas vezes cada passivo da biblioteca.** O `kicad-cli --subst-models` troca o `.wrl` da biblioteca pelo `.step` que fica ao lado, então os 105 resistores, capacitores e indutores já vinham no GLB — e o renderizador desenhava por cima o `.wrl` deles também, corpo sobre corpo. Agora só desenha o `.wrl` de quem não tem `.step` instalado (o SOT-523 e o X2SON-4): de 47.308 corpos desenhados aqui para 2.308.

- **Os divisores do `TERM` e do `SETSD` do ADP5091 pendiam do `BAT`, com o pino `REF` aberto.** A figura 42 da ficha (Rev. A, p. 19) põe os quatro divisores externos entre `REF` e `AGND`: o CI liga o `REF` ao `BAT` por dentro, por chaves, com o resistor de histerese em série, e ao `TERM_REF` na hora de comparar o fim de carga. Pendurados no `BAT`, a equação 6 (fim de carga em 3,97 V) não valia e a histerese do `SETSD` não existia. Os topos de `R118` e `R120` foram ao `REF` (nó `ADP_REF`); os valores não mudam ([03](hardware_gnssbike/03-netlist.md#nós-sem-ligação-ao-mcu)).

- **A pinagem do conector da célula em cobre não era a que o documento manda ao fabricante do pack.** [06](hardware_gnssbike/06-conectores-e-pontos-de-teste.md#j102--bateria) propõe 1 e 6 `VBAT+`, 2 e 5 `GND`, 3 `NTC_BAT`, 4 reservada; o cobre tinha 1 `VBAT+`, 4 NTC e 6 `GND`, com 2, 3 e 5 soltos — um cabo feito como o documento pedia punha o positivo do pino 6 no `GND` da placa. Corrigido no `nets.py`.

- **O `check_pcb.py` acusava o USB-C de passar da borda e cobrava um furo só.** Ele centrava o courtyard na origem do footprint (o do USB-C não é centrado: acaba 0,14 mm dentro, não 0,42 fora) e comparava com "1 furo" escrito à mão quando `make_dxf.py` já tinha dois. Agora usa a caixa que o colocador usou e a lista de furos do `make_dxf`.

- **O colocador reservava 1,7 mm em volta do furo M2 e o footprint do KiCad (`MountingHole_2.2mm_M2`) tem courtyard de 2,45:** o Tag-Connect caiu a 2,0 mm do furo e o DRC acusou sobreposição. A reserva passou a ser o courtyard do footprint mais a folga; o diodo do USB, que ficava a 78,8, subiu para 79,1.

- **A terceira tecla não cabia em y = 66 com passo de 9 mm:** a 23,0 ela ficava a 3,56 mm da área da antena do módulo, que pede 5. Passo de 8,5 (4,5 · 13,0 · 21,5) e o contorno acaba a 5,06 mm.

- **O `route.py` e o `dry_run_pcb.py` tomavam os números das redes do `nets.py` em vez do arquivo da placa.** Uma rede acrescentada no meio de uma cadeia deslocou o número do `GND` em um, o roteador escreveu as vias de terra com o número novo num arquivo que usava o velho, e o verificador contou 7 vias de terra onde havia 316. Os dois passaram a ler a tabela de redes do próprio `.kicad_pcb` (`fp_load.redes_da_placa`).

- **Um parafuso não segurava a placa, e agora são dois.** A placa passou meses com **um** furo M2, em (3,2; 45,0) — decisão de 2026-09-23, "para deixar área para peças e trilhas". Medido: enfiar o plugue USB-C aplica, no pior caso da norma, **20 N a 40,8 mm daquele parafuso, ou 816 N·mm**, enquanto um M2 num pilar de plástico impresso resiste a cerca de **40 N·mm** por atrito sob a cabeça (0,05 N·m de aperto, 125 N de pré-carga, μ 0,2 num raio de 1,6 mm). **Vinte vezes menos.** Uma inserção comum de 5 N ainda é cinco vezes, e apertar a tecla central já empata. E com 12 mm de folga para a parede da cavidade de cada lado, não há nada em que a placa esbarre antes de girar. O segundo furo foi para (4,0; 75,75), ao lado do USB-C: os dois ficam a 30,8 mm e o momento vira binário de **26,5 N de cisalhamento por parafuso**, contra os cerca de 870 N que um M2 4.8 rompe. A premissa da decisão de 2026-09-23 também caiu por medição: **7.402 pontos da placa aceitam um furo M2**, o mais folgado com 5,2 mm de raio livre. O primeiro lugar tentado, no canto livre da direita, foi **recusado pela regra `RF3`**: caía a 3,2 mm da área da antena do módulo de rádio, e a ficha do ME54BS13 quer 5 mm livres de metal. Placa refeita e conferida: 926 segmentos, 429 vias, 0 violações, 0 ligações sem trilha, 21 regras de ficha cumpridas.

- **O modelo 3D do USB-C e o do conector da bateria vinham 180° girados de fábrica, e a placa foi desenhada em cima disso.** O STEP que a LCSC publica para o `HRO TYPE-C-31-M-12` está 180° fora do referencial do footprint: como vem, as 16 ilhas de contato caem **1,45 mm além do corpo**, do lado oposto, e a **boca do conector aponta para o miolo da placa** — ninguém encaixaria um cabo. O JST ZH do `J103` tem o mesmo defeito, mais 1,61 mm de deslocamento em X, que deixava uma das duas ilhas de fixação de fora do corpo. Verificação nenhuma pegava: o 2D só tem as ilhas, que estão certas; o DRC não lê modelo 3D; e as ilhas de um receptáculo USB-C são quase simétricas em y, de modo que a peça "cabe" nos dois sentidos. **Quem viu foi o dono, no desenho 3D, e precisou dizer três vezes** — nas duas primeiras a correção saiu no footprint, que era a única coisa certa. O alvo do conserto não é palpite: o `F.Fab` do footprint do próprio KiCad põe o corpo do USB-C em X −4,47..+4,47 e **Y −3,65..+3,65**, e o do JST em X −4,50..+4,50 e Y −2,00..+4,00; girados e deslocados pela tabela `footprints.MODELO_GIRADO`, os dois caem exatamente aí (medido: −4,25..+3,65 no USB-C, os 0,6 a mais sendo os rabichos de solda). Com o corpo no lugar, o `J101` andou 1,05 mm para a borda e a **boca ficou a 0,64 mm dela** — estava 2,74 mm para dentro, onde o sobremolde do plugue bateria no canto da placa antes de o conector assentar.

- **Os 105 passivos da biblioteca não tinham corpo 3D nenhum.** O leitor de VRML só entendia o dialeto que este projeto escreve, com uma face por linha e vírgula entre as faces; a biblioteca do KiCad põe **vírgula entre todos os índices**, de modo que cada pedaço virava um índice só, nenhum triângulo saía e a peça não aparecia. O desenho mostrava **cobre nu onde havia componente**, e foi isso que o dono viu quando disse que os resistores em volta do módulo pareciam girados 90°. A lista de índices passou a ser lida como uma sequência única cortada a cada −1, que é o que o VRML especifica. Corpos desenhados: de 2.644 para **42.484**. Na mesma investigação: o `${KICAD8_3DMODEL_DIR}` nunca era resolvido, de modo que nem modelo legível da biblioteca era usado; `J101`, `J103` e `J402` eram desenhados **duas vezes** — o STEP do fabricante e, por cima, o paralelepípedo que este projeto tinha escrito antes de conseguir o STEP, com 4,50 mm de altura no JST contra os 3,75 reais; e o `(offset ...)` do bloco `(model ...)` era ignorado, o que punha o U.FL do `J302` meio milímetro fora das ilhas no desenho.

- **O desenho 3D podia ser feito de uma placa velha.** O `gnssbike.glb` era usado como estivesse, e chegou a ficar **sete horas mais velho que o `.kicad_pcb`**: o desenho misturava a placa de antes com os corpos de agora, e o resultado parecia peça torta, com o pad fora da ilha. Agora o GLB é refeito sempre que for mais velho que a placa.

- **A regra `ME4`, e a primeira versão dela, que era palpite disfarçado de medida.** A primeira perguntava de que lado ficava a **boca** do conector, lançando um raio pela cavidade — e não serve, porque a traseira de um receptáculo USB-C também é oca e o raio responde o que se quer ouvir. A que ficou não tem opinião nenhuma dentro: **um rabicho de solda fica em cima da sua ilha**, logo o corpo do modelo tem de cobrir as ilhas da peça. É a assinatura exata do defeito, foi conferida contra ele (com o modelo de volta na posição errada, a rodada falha) e foi ela que achou sozinha o do `J103`, que ninguém tinha visto. O dry-run passou a medir **22 regras**, com 21 cumpridas e 1 violada de propósito (`US1`, o par diferencial do USB, que espera acabamento à mão).

- **A antena GNSS passou a chegar por u.FL, não por contato de mola.** A linha que ela alimenta é o caminho **L1 + L5** do MAX-F10S, e a 4.4 do manual de integração pede **50 Ω em todo ele**. Um par de pads de ouro em que uma lâmina encosta não tem impedância definida a 1,2 e 1,6 GHz, não tem caminho de retorno definido e tem resistência de contato que muda com o jeito que a caixa fechou. O `J302` virou um **Hirose U.FL-R-SMT-1**, que é a transição coaxial de 50 Ω que todo projeto de referência de módulo GNSS usa para elemento externo. Custa 2,6 × 2,6 mm de placa e troca um encaixe mecânico por um cabo — decisão mecânica que não estava registrada em lugar nenhum. O caminho de RF encurtou de 8,2 para **5,7 mm**. Os três contatos de mola dos painéis solares continuam contatos de mola: ali não há RF.

- **O desenho de montagem deixou de sair de camada do KiCad.** Nem a serigrafia nem o `F.Fab` dão um desenho legível desta placa. A serigrafia obedece à fabricação — 0,6 mm de texto, e 127 designadores a 48 % de ocupação não cabem em volta das peças sem cair um sobre o outro ou se afastar tanto que deixam de nomear algo. O `F.Fab` carrega o que cada footprint da biblioteca resolveu pôr lá, no tamanho que o autor daquele footprint escolheu, mais o valor, e imprime `TP110` a 1,0 mm ao lado de `100 nF` a 0,5, os dois sobre o contorno. Desenho de montagem **não é camada de cobre**: é desenho, e pode fazer o que serigrafia não pode — pôr o rótulo onde se lê e traçar uma **linha de chamada** até a peça. O `montagem.py` novo gera `gnssbike-montagem.pdf`, frente e verso, com o rótulo dentro do contorno quando cabe e fora com ponto e linha quando não cabe: das 127 peças, **92 usam chamada**.

- **O rótulo de serigrafia fugia da própria peça.** A busca preferia um lugar livre do contorno de **qualquer** peça a um lugar perto da própria, e numa placa a 48 % isso empurra o designador a milímetros de distância — uma nuvem em que nenhum aponta para nada. Proximidade passou a mandar: candidatos do mais perto para o mais longe, o primeiro que não cai sobre **outro rótulo** ganha, e pisar contorno só desempata entre candidatos da mesma distância. Um rótulo sobre o contorno da própria peça continua dizendo qual peça é; a 4 mm dela, não.

- **O esquemático desenhava tudo como bloco, e bloco é só para circuito integrado.** Retângulo com nome de pino nas laterais é como se desenha um CI; este gerador desenhava assim as **127 peças** — resistores, capacitores cerâmicos, diodos, o TVS —, e uma folha de blocos ligados por linhas não mostra circuito nenhum. Cada classe ganhou o símbolo dela, no padrão: **ziguezague** para resistor e jumper de 0 Ω (42), **duas placas paralelas** para o cerâmico e placa curva com `+` para o eletrolítico (31), **quatro arcos** para o indutor (4), os mesmos arcos dentro de um retângulo para a **ferrite** (1), ziguezague com seta na diagonal para o **termistor** (1), **triângulo e barra** para o diodo, com setas para fora no LED (2), dois contatos com barra e êmbolo para a **tecla** (3), círculo com diagonal para o **buzzer** (1) e círculo na ponta do terminal para o **ponto de teste** (14). Os 36 que continuam retângulo são os que devem ser: CI, conectores e o display. Peça de dois terminais deixou de mostrar **número e nome de pino** — "1" e "2" num resistor é ruído, e o símbolo já diz onde é o quê onde importa.

- **O rótulo do símbolo de alimentação não tinha lugar reservado, só o símbolo.** Dois pinos de terra a dois passos de grade recebiam cada um o seu símbolo, os símbolos não colidiam e as palavras imprimiam uma sobre a outra — `GNDGNDGND` na base de cada chip. Agora o que se reserva é o conjunto, nome incluído, e o coto procura primeiro um lugar onde o nome também caiba. **Com um limite**: a primeira tentativa esticava o coto até quatorze passos de grade e um deles atravessou um componente e **partiu um nó**. Coto longo é pior que rótulo colado, então ele para em oito e o rótulo cede.

  Uma tentativa de agrupar todos os pinos do mesmo trilho num símbolo só foi **descartada e revertida**: a linha que junta os cotos corre ao longo da borda da peça e cruza o que estiver entre eles, o que juntou dois terras através do nó de chaveamento no meio e **fundiu treze nós**. Agrupar exige olhar o que há entre os pinos, e isso fica para uma passagem própria — um esquemático com o netlist errado é pior que um esquemático feio.

- **As folhas do esquemático eram grandes demais, e pela mesma causa do contorno da placa.** A raiz era **A0**, a folha de energia **A1** e as outras cinco **A3** — para um projeto de 135 posições. O desenho era espalhado para encher o papel em vez de o papel ser escolhido para caber o desenho: o seletor orçava **54 × 48 mm por peça**, fosse um 0402 ou um módulo de 80 pads, **nunca considerava A4** (a busca começava em A3), e a raiz era A0 escrito à mão com blocos de 190 × 240 mm num passo de 370 × 350. Agora o tamanho é **medido**: o seletor desenha na folha candidata e pergunta se a última linha terminou acima da margem, usando o **mesmo código que desenha**, de modo que a resposta não pode divergir do desenho. Os corredores entre peças caíram de 24 e 30 mm para 16 e 22, e quem prova que ainda cabe fio é o `check_sch.py`, que falha se um fio cruzar componente — a primeira tentativa, a 14 e 18, partiu o `DISP_SCK` em dois e foi rejeitada por ele. Na raiz, um pino de folha ganhava 5,08 mm de espaço para um rótulo de 1,27: a dois passos de grade, que é o padrão do KiCad, o bloco do MCU (33 sinais atravessando) caiu de 116 para 73 mm de altura. **Resultado: cinco folhas em A4 e duas em A3**, com os mesmos 100 nós elétricos e 994 fios, nenhum sobre componente e nada fora da folha.

- **Onze dos dezesseis pontos de teste não existiam na placa.** [06](hardware_gnssbike/06-conectores-e-pontos-de-teste.md) especifica dezesseis, e só os três da folha do console (`TP201`–`TP203`) estavam lá: um trilho em que não se encosta ponta de prova é um trilho que não se depura. Entraram os onze da folha de energia — `VBUS`, `VBUSOUT`, `VBAT`, `VSYS`, `3V0`, `1V8`, `SD3V0`, `3V3BL`, `VBCKP`, `VINT` e o `GND` de referência —, cada um colocado ao lado do que ele mede, que é o que o documento pede ponto a ponto. Os dois que **não** entraram são ausência do próprio documento: o `TP111` mede `ST_STO`, que a ficha do AEM10900 não tem, e o `TP401` mede `5V0`, de um REG710NA-5 que não é montado com o painel JDI. A lista vive em `parts.TESTE` e o `nets.py` **falha se um ponto apontar para um nó que não existe**.

- **O 3D não tinha serigrafia nenhuma, e as peças estavam afundadas na placa.** `kicad-cli pcb export glb` não tem opção de serigrafia, então a vista 3D mostrava um retângulo verde com peças em cima e **nem um designador**. O export em **SVG** carrega, e carrega da forma mais simples possível: 6.484 `<path d="M x y L x y"/>`, um por traço, glifos incluídos — nenhuma fonte é necessária e nada é aproximado. Exportado na folha inteira, os milímetros do SVG **são as coordenadas do arquivo da placa**. Ao pôr isso no lugar, apareceu um erro maior: medindo o GLB, o substrato vai de z 0 a 0,820 e o cobre até **0,855**, mas o renderizador usava 0 e −0,8 — ou seja, **toda peça da frente estava 0,855 mm dentro da placa** e a serigrafia, enterrada sob o despejo de cobre. As duas faces passaram a ser constantes medidas.

- **O 2D tinha o silk, e ele era ilegível.** A serigrafia do KiCad é um creme claro; sobre o vermelho de um despejo de cobre cheio — que é exatamente o que essas páginas são — não se lê. Entraram **duas páginas de montagem**, frente e verso, só com a serigrafia e **em preto e branco**, que é o desenho que uma pessoa usa para achar o `R602` numa placa. O `F.Fab` saiu delas: ele traz a cópia da referência que o footprint da biblioteca já tem, e com ele cada designador saía duas vezes, um grande e um pequeno, sobrepostos.

- **A serigrafia não identificava nada.** As referências saíam todas a 1,8 mm acima da peça, num tamanho de 0,7 mm com traço de 0,1 — **abaixo do mínimo que fábrica nenhuma imprime** (0,8 mm de altura e 0,15 de traço) — e **37 pares de designadores ficavam um em cima do outro**. Agora o texto está no mínimo da fábrica e cada rótulo é **posicionado**: candidatos em volta do contorno da própria peça, do mais perto para o mais longe, com duas regras em ordem — um rótulo nunca pode cair sobre outro, e deve evitar o contorno de outra peça, o que numa placa a 48 % de ocupação nem sempre dá. Resultado: **127 referências visíveis, 0 sobrepostas** — e esse zero passou a ser medido **no que o KiCad desenha**, não no que este projeto acha que desenhou. O modelo interno de largura de rótulo estava **30 % estreito** (0,75 do tamanho do texto por caractere, contra os 1,06 que o export mede em `textLength`), de modo que ele reportava zero enquanto a serigrafia exportada tinha **35 pares** um sobre o outro. Havia ainda um segundo erro por trás: o deslocamento do rótulo era escolhido no referencial da **placa**, e o KiCad gira uma propriedade de footprint pelo ângulo do próprio footprint — um rótulo posto "acima" de uma peça girada 90° saía ao lado dela. O `check_pcb.py` agora exporta as duas camadas de serigrafia e conta as sobreposições nos retângulos do próprio KiCad. O `REF**` do furo de fixação foi escondido: ele não nomeia peça nenhuma e era o último rótulo sentado em cima de outro.

- **A malha de terra ganhou costura na área, não só na borda.** A costura de borda impede que o contorno dos dois despejos de superfície vire fenda irradiante; ela não faz nada pelo **miolo**, onde um trecho de despejo que só alcança o plano interno por uma via a 20 mm de distância não é terra a 2,4 GHz. Entrou uma malha de vias de terra a **4,0 mm** sobre a placa toda — abaixo dos 6,1 mm de λ/10 em FR-4 —, colocada por último, sobre o que sobrou, para que uma costura nunca custe uma ligação.

- **A busca do roteador passou a conhecer o campo de pad, e isso valeu 4 ligações.** O estreitamento junto ao pad existia só na hora de **emitir** — e emitir só vê caminhos que a busca já achou. Com uma largura única para a busca inteira, uma trilha larga não saía de um encapsulamento de passo fino, por mais que fosse afinar depois. Agora o A\* usa a largura do **pad** dentro do campo do encapsulamento e a largura da rede fora dele, e as ligações roteadas foram de **126 para 130**. O primeiro corte disso pôs o `USB_DM` a 0,335 mm do `KEY_R` onde a geometria pede 0,378: a busca estreitava para a largura mínima da placa e o `emitir` desenhava a largura do **pad**, que é maior. As duas passaram a usar o mesmo número.

- **O par diferencial do USB: medido em vez de suposto (`US1`).** Ele saía com **zero segmentos** — não estava roteado de forma nenhuma — e o relatório do roteador não dizia isso, porque imprimia só as doze primeiras falhas e todas eram de via de terra. Duas coisas mudaram. O relatório passou a ser **agrupado por rede**, com a contagem e um exemplo de cada. E entrou o `US1`, que mede o par: se está roteado, com que largura, e contra os **0,352 mm** que dão 90 Ω diferenciais nesta pilha. A resposta honesta da placa de hoje é que **não cabe**: a 0,352 mm com a folga de 0,2 mm da classe USB não há canal do receptáculo num canto de baixo até o módulo no outro, e os dois pads de cada sinal num Type-C são o **mesmo sinal em fileiras opostas**, de modo que juntá-los atravessa o campo de pads do próprio conector. O par é roteado na largura que cabe e o `US1` **falha**, imprimindo as duas geometrias lado a lado — é um par que tem de ser terminado à mão, e dizer isso é a versão honesta de um par que silenciosamente não é 90 Ω.

- **O `AL5` deixou de ser "não medido".** A 7.2 pede **footprint de filtro π reservado** no pino de alimentação do módulo, por ele vir de fonte chaveada. Agora a regra mede a **forma** de um π: elemento em série entre o trilho e o pino, com capacitor para terra dos dois lados. A placa passa, e o que ela tem está escrito: `C105+C106+C107+C108 | JP102 | C201+C210`, com o elemento em série a **3,9 mm** do pino.

- **O cristal de 32,768 kHz: está dentro do módulo, e a ficha não o menciona.** O `ME54BS13` **não expõe P1.20 e P1.21**, que são o LFXO do nRF54LM20A — o que só faz sentido com um cristal ligado a eles lá dentro —, e por isso não há cristal no esquemático nem na placa. O que continua em aberto é a **tolerância**: a ficha V1.0.0 não traz a palavra "crystal" em página nenhuma, e o **ANT+ exige ±50 ppm** ([14](docs/14-hardware-placa-nova.md)).

- **Três footprints eram de outra peça, e a conferência de cotas os pegou.** Ao ganhar o corpo cotado de cada conector, o `ME3` — que compara o que a ficha cota com o contorno desenhado — achou três land patterns de peças **diferentes das da lista de compras**. O **buzzer** era o pior: o footprint em uso, `Buzzer_CUI_CPT-9019S-SMT`, é **redondo de 9 mm**, e o Same Sky CPT-1117-83-SMT comprado é **retangular de 11,0 × 9,0 × 1,7**, preso por duas abas de 2,0 × 0,2 mm em pontas opostas, com padrão de solda de duas ilhas de 2,5 × 2,5 a 10,5 mm. **Corrigido**: o footprint passou a ser desenhado aqui, das cotas da página 2 da ficha, e o corpo 3D deixou de ser uma lata redonda e virou o que é, com as abas e os sete furos de som. Os outros dois ficaram **em aberto de propósito**: o `USB_C_Receptacle_Palconn_UTC16-G` desenha 8,94 × 7,32 contra os **9,99 × 8,58** do Molex 2036150003, e o `Hirose_FH12-10S-0.5SH` desenha 8,10 de largura contra os **9,90** do FH28-10S-0.5SH. Reconstruir um land pattern de USB-C a partir de um desenho **renderizado** é o palpite que essa conferência existe para pegar, e nenhuma das duas peças está na biblioteca do KiCad 8 — o `ME3` falha, e é para falhar. A altura do USB-C também estava errada: **4,21 mm** acima da superfície de montagem, não os 3,26 escritos como "conferir".

- **Mais cinco encapsulamentos com cota de ficha**, somando dezenove: o JST GH SM06B-GHS-TB (10,75 × 4,05 × 4,25, corpo de PA natural, entrada lateral), o Molex 2036150003 (9,99 × 8,58 × 4,21, carcaça de aço inoxidável, anel de vedação de borracha de sílica preta de 1,15 mm que é o que dá o IPX8, boca de 8,34 × 2,56), o Hirose FH28-10S-0.5SH (9,90 × 5,70 × 2,55 fechado e 5,4 com o atuador aberto a 116°, isolador de LCP **cinza** e atuador de LCP **preto**, contato por baixo), o Kingbright APT1608SURCK (1,6 × 0,8 × 0,75, base de 0,25 e resina em tronco de 1,2 para 1,1, lente `Water Clear`; a cor do corpo **não consta** na ficha e está dito assim) e o buzzer. O corpo do USB-C foi redesenhado com essa geometria: carcaça, anel de vedação e boca, em vez de uma caixa de aço só.

- **A placa era dimensionada pela caixa, e isso não tem lógica nenhuma.** Os 55 × 97 mm estavam escritos à mão em `cad/make_dxf.py`, justificados pela medida interna da caixa, e o plano de piso inteiro era um conjunto de retângulos absolutos nessa moldura — duas das zonas eram as *sombras* do display e da bateria, ou seja, peças da caixa ditando onde a placa podia ter componente. Nada disso se sustenta: **a placa sai do circuito e a caixa sai do display, da bateria e da mão**, e encolher uma não encolhe a outra. O contorno passou a ser derivado das regras, e quem manda é a **7.2** da ficha do ME54BS13, que pede **50 mm entre dois módulos de rádio** — esta placa tem dois, o ME54BS13 e o MAX-F10S. Varrendo cada milímetro inteiro que cumpre isso e ainda cabe a fila de três teclas na largura, o menor contorno com folga é **34 × 90 mm: 3.060 mm² contra 5.335, 43 % menos placa**, com a ocupação dos contornos subindo de 28 % para 48 %. As zonas passaram a sair de `W` e `H`; as sombras do display e da bateria saíram do plano de piso, porque o que fica por cima da placa é questão do arranjo mecânico e não do tamanho dela. Três consequências do aperto estão escritas no lugar em que valem: a fila de teclas saiu da borda de baixo (o módulo ocupa 17,0 mm dela e a fila pede 30,6), o buzzer foi para a **face de trás** (10,5 × 9,5 mm não cabem na faixa de 9,25 que sobra na frente, e empurrado ele parava a 0,84 mm do TPS7A02) e o receptor GNSS girou **180°** (a 0 o pino `RF_IN` saía do lado da borda, a 1,2 mm dela, e a rede π ficava a 10,5 mm de um pino que a ficha quer "as short as possible"). O colocador também deixou de tratar frente e verso como a mesma área: uma peça no verso não tira lugar de uma peça na frente, e fingir que tira é como uma placa pequena fica sem espaço que tem.

- **O `RF7` cobrava a coisa errada.** Ele exigia que os **três** elementos da rede π estivessem a menos de 5 mm do pino `RF_IN`. O `C301` é o shunt do lado da **antena** — é o fim da rede por construção —, de modo que uma rede π montada corretamente falhava por estar correta. E o limite de 2 mm que os shunts chegaram a carregar era invenção: a ficha escreve "as short as possible" e não dá figura. Agora se mede o **caminho de RF** do pino até o contato da antena, contra **λ/10 em L1 = 10,5 mm**, e o toco de cada shunt contra **λ/20 = 5,3 mm** — números que saem da conta de ε_eff 3,27 da microstrip de 0,196 mm sobre os 0,10 mm de pré-impregnado desta pilha, e que estão escritos no documento.

- **O `AL1` cobrava de conector o que a regra pede de CI.** A regra é "do módulo de rádio a 0,5 mm do pino; dos **demais CIs**, 2 mm o de alta frequência" — e um conector não é CI. O capacitor que fica no trilho que sai pelo cabo plano do display é reserva para o cabo, não desacoplamento de um pino de alimentação, e estava sendo reprovado a 3,1 mm contra 2.

- **A regra dos 20 mm do módulo de rádio foi apagada por engano, e voltou.** Em 2026-09-24 a documentação e o `dry_run_pcb.py` passaram a afirmar que *"20 mm entre a antena do módulo e qualquer conversor chaveado"* **não existia** na ficha do ME54BS13. Existe: está na **7.2**, `Interference Isolation Rule` — a busca tinha sido feita na 7.3, que só traz o qualitativo *"do not place modules adjacent to strong interference sources"*. Enquanto a afirmação valeu, a restrição saiu do posicionador e o indutor de potência `L103` chegou a **6,8 mm** do módulo. A regra voltou como `RF9`, e não como uma distância só: a 7.2 é uma **tabela de quatro linhas**, e a linha de **25 mm de display, câmera ou cabo FPC** nunca tinha sido carregada por documento nenhum. Ela **não é cumprida e não pode ser** — o display de 40,08 × 61,8 mm numa placa de 55 × 97 fica a **11,3 mm** do módulo, e não existe posição que resolva; a saída que a própria ficha dá é blindagem ou camada, e está registrada em [04](hardware_gnssbike/04-pcb-e-caixa.md) com o aviso de que só bancada mede a consequência. Entrou junto o `RF10`, os **50 mm entre dois módulos de rádio** da mesma seção (medidos: 59,4 mm). Repor os 20 mm custou **1,3 mm** ao desacoplamento do `U104`, que foi de 1,7 para 3,3 mm contra um limite de 2 — troca registrada, não acidente.

- **O 3D desenhava vinte e três peças como o mesmo tijolo preto.** O `make_3d.py` montava um paralelepípedo do tamanho do *contorno do footprint*, numa cor fixa, para todo componente sem modelo STEP — e jogava fora a forma e a cor que o `.wrl` de cada um já trazia, porque o `kicad-cli pcb export glb` só lê STEP e os corpos próprios são VRML. Na vista que existe para conferir se a peça é a que se pensa, o módulo de rádio, o receptor GNSS, as três teclas, o buzzer e o receptáculo USB-C eram cinco tijolos iguais. Agora o renderizador **lê o VRML**: o módulo e o GNSS aparecem como as latas metálicas que são, a tecla com o êmbolo, o buzzer como lata redonda com o furo de som, o USB-C em aço. Os corpos desenhados subiram de 264 triângulos para 3.588.

- **Quatro peças não tinham corpo nenhum, e são as que o projeto ainda não escolheu.** Os contatos de mola do painel solar e da antena (`J103` a `J105`, `J302`) apareciam como nada. Ganharam lâmina dourada sobre cada pad de 2,0 × 2,0 mm — com a altura declarada em `ALTURA` como **não lida de ficha**, porque mola nenhuma foi escolhida ainda.

- **A malha de terra não estava preenchida, e o DRC media o que não havia.** Os geradores escrevem a zona como contorno e mais nada, que é arquivo legal — o KiCad preenche ao abrir —, mas o `kicad-cli pcb drc` não preenche. O resultado era um DRC que reportava **296 ligações sem trilha** (204 delas de `GND`) e **180 vias soltas**, nenhuma real, e que **nunca media folga contra o cobre despejado**. O `fill_zones.py` novo chama o preenchedor do próprio KiCad pelo `pcbnew`: as ligações sem trilha caíram para **100** e apareceram **11 erros verdadeiros** de haste térmica insuficiente, em `U101`, `U102`, `U104`, `U503`, `U504`, nas duas fileiras de blindagem do USB-C e em três passivos. Corrigidos ligando os pads de terra **maciço** à malha em vez de por hastes: numa placa montada por refusão — 0402, um WLP-9 e um QFN de passo 0,4 — a haste térmica é um recurso de solda manual, e uma haste só é um estrangulamento de 0,3 mm em série com a corrente de retorno da blindagem do USB e do MCU. O custo está escrito no gerador: retrabalho manual mais difícil e um pouco mais de risco de lápide num 0402.

- **O roteador atravessava a placa em diagonal.** O custo do passo diagonal era 1,414, o que fazia uma corrida de *n* passos em 45° sempre ganhar do L equivalente, e o desenho saía com trilhas cruzando a placa inteira de canto a canto — que ninguém rotea. Achado olhando o 2D, não nos números, que estavam todos verdes. Com o passo diagonal em 2,2 e a virada de 45° cobrada como meia virada (0,2 contra 0,7), o traçado virou **tronco ortogonal com chanfro no canto**: 203 diagonais de **mediana 0,42 mm** e só 4 acima de 5 mm.

- **O estreitamento junto ao pad durava até o fim da corrida.** A largura era decidida pelo primeiro ponto do trecho, então uma corrida que começasse dentro do campo do pad ficava estreita inteira: o `VBAT`, que carrega 800 mA, saía do MAX17262 com 0,20 mm e seguia assim por **9,9 mm**, contra os 0,22 mm que a IPC-2221 pede. E o "campo do pad" era um raio calculado sobre **todos** os pads num quadrado de 6 mm, o que o inflava para 4,9 mm em volta de uma peça cercada. Agora o campo é a caixa dos pads do **próprio componente** e o trecho é cortado na borda dela.

- **O desacoplamento era colocado por distância entre centros, e a ficha cobra pad a pad.** O `C111` ficou a 2,02 mm do pino `3V3BL` do `U101` contra um limite de 2,00 enquanto uma vaga a 1,90 mm estava livre um passo de grade acima — invisível para o critério antigo, porque por distância de centro aquela vaga era a pior das duas. O colocador passou a pontuar cada vaga livre pela distância **de pad a pad** e a testar as duas orientações.

- **O cliente do Komoot chutava o descritor da inscrição.** O `ble_komoot_client.c` escrevia `subscribe_params.ccc_handle = nav_handle + 1U`, com o comentário "CCC is typically next handle". *Typically* não é uma regra do GATT: o CCC costuma vir logo depois da característica, e um celular que disponha o serviço de outro jeito faria este cliente gravar a inscrição em cima do atributo que estivesse ali. Os outros clientes já tinham sido corrigidos em 2026-09-20 e este passou batido — a mesma armadilha, o último a cair. Agora o host acha o descritor sozinho (`BT_GATT_AUTO_DISCOVER_CCC_HANDLE`), o que exige, além do `disc_params`, saber **onde o serviço acaba**: o `end_handle` passou a ser guardado do `bt_gatt_service_val` da descoberta primária e usado também para limitar a busca da característica, que antes herdava o limite da descoberta anterior. Não testado com celular nenhum.

- **Toda a documentação revalidada contra o código** (README, AGENTS, CHANGELOG, `docs/01` a `19`, `docs/telas/` e cinco skills). A revisão achou cerca de 110 afirmações vencidas, quase todas do mesmo tipo: **recurso que foi implementado e a documentação continuou dizendo que faltava**, e **número que um arquivo copiou do outro em vez de medir**. As contagens estavam erradas em seis arquivos ao mesmo tempo (o README trazia "65 casos" de teste de host quando são 714, e "31 telas" e "29 telas" no mesmo arquivo quando são 44 quadros); o nRF52840 ainda aparecia como alvo atual em cinco; o `$QRY`, o sistema de arquivos, a USB, os comandos, o mapa na tela e a recuperação de falha eram descritos como ausentes ou em stub, e todos existem. A matriz de `docs/10` foi recontada linha a linha: 30 áreas, e **nenhuma mais está ausente, em stub, não ligada ou quebrada** — a lista de defeitos abertos ficou vazia pela primeira vez, e no lugar dela entrou o que de fato continua em aberto, que não é defeito: a chave de desenvolvimento do MCUboot, o ANT+ que não abre canal, o AssistNow que o F10S não tem, o fator da e-peas, o pad LGA de cada GPIO no BM20C e o fato de **nada ter rodado em hardware**. Quatro PNG órfãos de uma numeração antiga (`36_treino`, `37_treino_sem_arquivo`) saíram de `docs/telas/`.

- **A alocação de pinos de `docs/14` era a do DK, não a da placa.** A tabela repetia os pinos do overlay do nRF54LM20 DK, e comparar pino a pino com o devicetree achou **23 divergências**. Três são erros que o papel não tinha como pegar e o silício pegou: o console no `uart30` ao lado do `i2c30` (mesmo bloco serial, o nRF54LM20A recusa), o EXTINT e o TIMEPULSE do GNSS em P1.07 e P1.13 (pinos de clock, que só o `i2c` e o `spi` podem usar) e dois botões em P1.08 e P1.09, que no plano novo são justamente o EXTINT e o TIMEPULSE — o plano tinha dois sinais no mesmo pino. A tabela passou a ser a da placa, com uma seção registrando o que mudou e por quê, e o total caiu de "37 no protótipo" para os **31 GPIO** que o devicetree usa.

- **Mais dois escritos e não ligados**, o mesmo padrão que o dono pegou nas telas. O **Komoot** era iniciado e conectado e **ninguém lia o que ele mandava**: a navegação nunca chegava ao modelo, e a curva na tela só vinha de arquivo de percurso. As vinte e quatro direções do aplicativo viraram as nove setas da tela em `model/komoot_turn.c`, com as três decisões que não são óbvias registradas e testadas — bifurcação leva a seta suave e não a fechada, as três meias-voltas são uma seta só, e "fora de rota" e "pegar a balsa" **não recebem seta nenhuma**, porque são recados e uma seta apontaria o ciclista para algum lugar. A **posição do celular** nunca era alimentada: o `ble_lns.c` que existia é o lado que *conta* onde o aparelho está, e o ramo LNS do `model/loc_arbiter.c` — escrito e com teste próprio — era inalcançável. Agora há o cliente (`src/rf/ble_lns_client.c`, com a leitura em `model/lns_parse.c`), e a posição entra como uma época de GNSS com o sinalizador `phone`, de modo que segue o mesmo caminho da do receptor e o árbitro decide pela regra do legacy. O que manda ali é o **estado da posição**: um celular sem fix manda as coordenadas assim mesmo, com dois bits dizendo que não valem nada, e só `LNS_POS_OK` é aceito — uma posição estimada ou a última conhecida põe o ciclista onde o celular achou que estava, e isso parece uma resposta, que é o que a torna pior do que não mostrar nada.

- **Três recursos prontos que o ciclista não alcançava.** O treino estruturado, a escolha de um treino e os doze alertas estavam no modelo, com teste, e **sem caminho até o dedo**: a tela de treino existia na tabela e nada navegava até ela, os `.WKT` eram listados e não havia onde escolher, e o `APP_CMD_SET_ALERT` funcionava sem tela que o mandasse. Agora o menu tem **Treino**, que abre a sessão carregada ou a lista para escolher (com *Descarregar* enquanto há uma), e os ajustes têm **Alertas** e **Lembretes**. Ao desenhar apareceu um defeito: o `ui_list_create()` desenha **doze linhas e não rola**, então Voltar mais doze alertas deixaria o lembrete de comer inalcançável — daí os dois grupos, que é a divisão que um ciclista faria de qualquer jeito (os oito que vigiam um número e os quatro que tocam de tempos em tempos). Três telas novas no renderizador (`40_treinos`, `41_alertas`, `42_lembretes`).

- **A potência do medidor não chegava na tela.** O `model_ui.c:246` mostrava `att.pwr`, que é a **estimativa** da fórmula do legacy: com um medidor ligado, o campo de potência continuava exibindo o palpite. A cadência era lida só do sensor de cadência separado, de modo que um medidor de pedivela — que conta o pedal — não aparecia. A escolha entre medidor, rolo e estimativa saiu do serviço e virou `model_ride_power_w()` e `model_ride_cadence_rpm()` no modelo, e **a tela e a gravação passam pela mesma**, de modo que não podem discordar sobre o que o pedal estava fazendo.
- **O treino estruturado não tinha tela nenhuma.** O ciclista não via passo, contagem, alvo nem "passo 6 de 11". Agora há `UI_SCREEN_WORKOUT` (`ui_scr_modes.c`): nome da sessão, passo e total, rótulo do passo, quanto falta (tempo, metros ou "tecla"), alvo, valor atual **na cor da resposta** — verde dentro da faixa, vermelho fora, porque na guidão se lê uma cor antes de um número — e uma barra com a faixa alvo e a marca de onde o ciclista está. Duas telas novas no renderizador (`38_treino`, `39_treino_sem_arquivo`). Ao desenhar apareceram dois defeitos do primeiro traçado: o campo corta em 6 caracteres e vira `---`, e a fonte grande de valor só tem dígitos, de modo que a letra da unidade saía como caixa; a unidade foi para o canto do campo e o valor virou número puro.

### Mudado

- **O repositório do hardware ganhou uma pasta por assunto** (pedido do dono em 2026-09-26): o que se **lê** saiu de `hardware_gnssbike/cad/`, que fica só com o projeto KiCad, os geradores e o dry run da placa. O esquemático em PDF está em `hardware_gnssbike/esquematico/`; a placa em PDF e SVG e o desenho de montagem, em `hardware_gnssbike/placa/`; a caixa inteira (`make_caixa.py`, `dry_run_caixa.py`, o PDF e os STL, com um `README.md`), em `hardware_gnssbike/caixa/`; as sete vistas 3D da placa e da caixa, em `docs/img/hardware/`. Os geradores escrevem nos lugares novos, os documentos apontam para eles (`links_check.py`: 0 quebrados) e o README raiz mostra a placa, a caixa e o manual de montagem. Saíram do repositório o `gnssbike-3d.glb` (39 MB, gerado, sem uso; `*.glb` passou a ser ignorado) e o desenho do conceito da caixa (`tools/docs/case_drawing.py` e `docs/img/placa-nova-caixa.svg`, da placa antiga de 55 × 97), que a proposta medida substitui.
- **A placa é 34 × 95 mm, e as três teclas ficam no passo de 13,4** (x 3,6, 17 e 30,4, y 66; pedido do dono em 2026-09-26: as chaves da placa exatamente sob as capas da caixa, espalhadas na largura do display, sem barras). 13,4 é o maior passo que a margem de 0,8 da borda deixa a um contorno de 5,5; a terceira chave só passa pela área da antena do módulo com o módulo 5 mm mais baixo, e a área desce com `H` (`GNSSBIKE_H` em `make_dxf.py`). 3.230 mm².
- **O teto sob o display é 3,0 mm, não 2,6**: o MAX-F10S tem 2,7 no máximo (cota C da ficha) e fica sob o vidro; a caixa desce a placa 0,4 mm (`make_caixa.DISPLAY_VAO`) e a célula acaba a 0,3 mm do fundo. `ME2` e o `make_dxf` mudaram junto.
- **Cinco peças saíram das sombras**: `J102` virou o **JST SH SM06B-SRSS-TB** (2,9 mm), **na frente**, em pé em (13,5; 80,4) a 270° — o GH de 4,25 não cabe sob a tampa (4,2 mm) nem na faixa do verso, e a troca perde a trava positiva (o cabo é preso à caixa; decisão do dono registrada em [19](docs/19-lista-de-compras.md#trocas)); `J103` foi para o **verso**, em pé na borda esquerda, (4,9; 75,2) a 270°, com o chicote saindo para a parede; `LS601` (18; 76,2) e `U502` (9,7; 82,5) no verso, fora da célula; `U301` ficou, com o teto novo. O manual de montagem, o desenho do chicote e os docs 04, 05, 06 e 14 acompanham (a bateria liga **depois** de a placa entrar; o chicote solar, antes).
- **Os dois furos M2 estão em (3,2; 7,0) e (14,4; 91,7)**, nenhum sobre a célula; o segundo estava em (4,0; 75,75), onde a reserva dele ocupava o lugar do sensor de luz (`U505`, agora em (3; 74)) e a faixa do verso que segura o `J103`. Para a reserva caber entre o USB-C e o módulo, o `J101` andou 0,4 para a esquerda (x 6,5). O binário dos parafusos sobe para 85,4 mm ([02](hardware_gnssbike/02-calculos.md#quantos-parafusos-a-placa-precisa)); a caixa dá bossa aos dois e um quarto pilar ao canto do USB-C.
- **A caixa proposta é 62 × 106 × 17** (era 62 × 104): 2 mm de comprimento para o berço da antena externa caber entre a placa e a parede de cima; a área externa vai a 189 cm² e a conta de calor de [02](hardware_gnssbike/02-calculos.md#calor-da-caixa-inteira) sobe 0,4 °C.
- **O esquemático é desenhado por bloco funcional, no padrão que o dono pediu** (`cad/blocos.py`, `make_sch.py`, `sheets.py`, `sch_lib.py`). Cada folha virou uma fila de blocos na ordem do fluxo do sinal, cada um numa caixa tracejada com título; dentro do bloco o passivo fica ao lado do pino que serve e o desacoplamento numa prateleira sob o CI; alimentação e terra por símbolo, um fio pelas pontas dos pinos vizinhos do mesmo trilho; o que sai do bloco é rótulo local e o que sai da folha é rótulo hierárquico, num toco curto — nenhum fio atravessa a página. Folha 1 em A3, as outras em A4. Até então cada folha era a lista de nós desenhada em fios. Três fatos do KiCad medidos no caminho, porque a primeira versão supôs errado e o `check_sch.py` pegou: `(mirror x)` troca esquerda por direita (não `mirror y`); um rótulo local com o nome de um trilho é a rede `/folha/TRILHO`, outra rede; e um pino no meio de um fio comprido não está nele — "wires connect ... only if their ends coincide exactly". Conferido: ERC sem erro novo, lista de nós igual à de `nets.py` pino a pino, nenhum fio sobre componente ([cad/README](hardware_gnssbike/cad/README.md#desenhado-por-bloco-funcional-desde-2026-09-26)).

- **O esquemático ficou legível: referências, valores e rótulos deixaram de se sobrepor** (pedido do dono em 2026-09-26; `cad/sch_lib.py`, `blocos.py`, `make_sch.py`, `sheets.py`). Os símbolos de alimentação escondem o número e o nome do pino (cada um imprimia um "1" e o nome do trilho duas vezes) e apontam para longe do pino, deitados na linha dos pinos laterais com o nome na linha; a prateleira de desacoplamento é uma fileira de capacitores em pé por trilho, um fio pelos topos e um símbolo por fileira, os pontos de teste em pé; a referência e o valor ficam à direita das peças em pé e entre as linhas vizinhas das deitadas, e nome de bloco, texto de peça e nome de símbolo são obstáculo para o roteador e para quem coloca símbolo ou rótulo; pull-up e pull-down de linha rotulada ficam em pé depois do rótulo (e fora do corredor quando a linha segue para outra âncora); o lugar dos rótulos é reservado antes das peças; o conector do FPC é espelhado e alinhado com o painel, e o fio do painel continua do rótulo (`Router.irmas`); as duas células em frente de cada pino são da rede dele; `DISP_VDD` virou trilho; os blocos são empacotados por altura e a folha 1 cabe em A3. A biblioteca guarda o desenho base e a instância leva giro e espelho: antes o gerador escrevia a biblioteca já espelhada **e** o `(mirror ...)`, e a "medição" de `(mirror x)` estava invertida por isso — refeita em arquivo mínimo: `(mirror y)` troca esquerda por direita, `90` manda o pino da esquerda para baixo, e a justificação do campo é transformada junto (`CLAUDE.md`, `cad/README.md`). `SCH_DEBUG=1` explica cada símbolo, rótulo ou fio sem lugar. Restam apertados a colheita solar e a esquerda do medidor; oito redes fecham por rótulo.
- **O receptor GNSS roda a 3,0 V, no trilho do MCU** (decisão do dono, 2026-09-26; opção 1 da tabela 35 do manual de integração UBXDOC-963802114-12892: `VCC` e `V_IO` juntos, `VIO_SEL` aberto). O BUCK1 é de ±5 % e o projeto de 1,8 V pede ±2 %; o LDO de ±1 % que o substituiria por umas horas custava 35 mW na bateria, a opção 1 custa 11 (57 mW no receptor em vez de 46,8; a autonomia sem sol vai de cerca de 115 h para cerca de 97 h). Saíram o TXU0204 e o LDO, com quatro capacitores; o BUCK1 fica montado, sem carga, `regulator-boot-off` no devicetree, e o `vcc-supply` do receptor aponta para o BUCK2 — que é sempre ligado, de modo que o receptor deixou de ter trilho que se desliga e só dorme por `UBX-RXM-PMREQ` (46 µA; firmware por ajustar, [10](docs/10-status-do-port.md#defeitos-abertos)). Build da placa própria: 0 avisos, FLASH 636.376 B, RAM 393.120 B ([02](hardware_gnssbike/02-calculos.md#o-receptor-no-3v0-e-o-1v8-sem-carga)).

- **O colhedor solar do CAD é o ADP5091 desde 2026-09-25, e este registro estava faltando.** A troca (AEM10900 → ADP5091ACPZ-2, com `L103` de 22 µH ainda sem peça) entrou no `nets.py` e no esquemático sem linha aqui, e os documentos 02, 04, 13, 14, 15 e 19 ainda dimensionam o AEM10900 — 01, 03, 05, 06 e 07 foram acertados em 2026-09-26; o resto está na lista do [relatório](hardware_gnssbike/10-dry-run-2026-09-26.md). O `R111`, pull-up do `IRQ` que o ADP5091 não tem, saiu da lista.

- **As três teclas ficam abaixo do display**, em y = 66 com passo de 8,5 mm (decisão do dono): o LPM027M128C tem 61,8 mm de altura numa placa de 90 e cobria a fila de y = 58; uma tecla debaixo do vidro não se aperta. O display passa a ter de acabar em y ≤ 64,5 ([04](hardware_gnssbike/04-pcb-e-caixa.md#as-duas-sombras-display-e-bateria)).

- **A documentação da placa nova passou a descrever o MinewSemi ME54BS13 como o módulo montado**, no lugar do Fanstel BM20C, que virou alternativa histórica. O CAD já usava o ME54BS13 — o `U201` com o mapa `PADS_ME54BS13` de 80 pads, as redes por nome de pad dele, a zona `ZONA_MODULO_ME54BS13` e o `KEEPOUT_ANTENA_MODULO` —, e os nove documentos de [`hardware_gnssbike/`](hardware_gnssbike/README.md) diziam o contrário. Acertados: as medidas (**16,5 × 12,0 × 2,4 mm**, e não 10,0 × 16,2 × 2,0), a antena (de **PCB**, nos últimos 4,46 mm de uma ponta de 12 mm, virada para a borda direita, com o módulo deitado acima das teclas na face da frente), os pads dedicados (`D−` no 7, `D+` no 8, `VBUS` no 9, `SWDIO` no 5, `SWDCLK` no 6, reset no 4, `VDD` no 19 e o pad 2 de antena externa aberto) e as regras de processo (**20 pads castelados na borda mais 60 ilhas LGA**, e não só LGA). O **orçamento de área** de [04](hardware_gnssbike/04-pcb-e-caixa.md) foi refeito a partir dos retângulos novos: a união do módulo com a zona proibida da antena passou de 240,0 mm² (4,5 %) para **270,6 mm² (5,1 %)**, a soma bruta de 2.099,3 para **2.129,9 mm²**, as sobreposições de 120,0 para **102,5 mm²** — sumiu a do botão da direita na zona proibida, de 21 mm², e entrou a do módulo na zona de energia, de 3,5 mm² — e a área livre de 3.355,7 para **3.307,6 mm², 62,0 %**. Três consequências que a troca trouxe e que **ninguém mediu**: a separação entre as duas antenas caiu de 87,2 para **67,2 mm** (de 0,71 λ para 0,55 λ em 2,44 GHz), a regra 7.3 da ficha — 20 mm entre a antena e qualquer conversor chaveado ou indutor — **não é cumprida**, porque a zona de energia fica a 11,5 mm, e a sobreposição do módulo com a sombra da bateria subiu de 5,5 para **105,4 mm²**, o que deixa de ser escolha e **obriga** o módulo à face da frente. Em aberto: o espelhamento do mapa de pads (a ficha V1.0.0 e a V0.5.0 discordam), a certificação (a V0.5.0 não traz nenhuma e a V1.0.0 não foi lida quanto a isso), a tolerância do cristal de 32,768 kHz, a faixa aceita no pad `VBUS` e o número de refusões. **[`docs/15`](docs/15-avaliacao-componentes.md) e [`docs/19`](docs/19-lista-de-compras.md) continuam dando o BM20C como escolhido**, e acertá-los é decisão do dono.

- **A tela do aparelho passa a ser o JDI LPM027M128C** (decisão do dono, 2026-09-23), no lugar do par Sharp LS027B7DH01A + filme de luz Azumo 11103-06_A1 que a validação de compra tinha adotado. É **peça única**: 2,7", 400 × 240, MIP de 8 cores e com **luz frontal integrada**, sem a etapa de laminação do filme, na mesma resolução — a interface não muda uma linha —, com menos consumo parado (30 µW a 1 quadro/s contra 175 µW) e com cor. A decisão atravessa o hardware inteiro. **Sai o caminho de 5 V:** com o painel em 3,0 V, o REG710NA-5 (`U401`), o capacitor de bombeamento e os dois de 10 µF de entrada e de saída **não são montados**, e o trilho `5V0` deixa de existir na placa construída; o `DISP_PWR_EN` (P3.07), que era o `EN` do conversor, **volta a ficar livre** — o devicetree ainda o declara como `power-gpios`, com o pull-down de 100 kΩ segurando o nível, e é linha a limpar. **Saem o filme e o conector dele** (`DS402` e o `J402`, Molex 5034800440), porque a luz agora é do painel. **O `JP401` deixa de ser seletor** e vira um 0 Ω fixo na posição do 3,0 V, com a posição do 5 V **não montada**: o footprint fica, porque é ele que faz o plano B — a Sharp, que continua a reserva — ser uma troca de montagem e não uma placa nova. O `R_BL` de **39 Ω** continua valendo, porque a conta sempre foi a do LED de 16 mA a 2,67 V do JDI, e o `Q401` e o trilho `3V3BL` seguem como estavam. A folha 4 passou de 15 para **9 posições de componente**, e a placa de 120 para **114**.

  **E resolve um defeito de graça.** O `docs/10` registrava que "o COM da tela fica em 1 Hz com a luz acesa, na Sharp": a interface pede 120 Hz e o driver recusa acima de **20 Hz** nesse painel, devolvendo um `-EINVAL` que ninguém lia. No JDI o limite do driver é **140 Hz** (`MEMLCD_COM_HZ_MAX_JDI`, em `zephyr_app/modules/gnss_drivers/drivers/display/memlcd.c:46`), de modo que os 120 Hz passam e **o defeito deixa de existir** — sem uma linha de código, e voltaria a existir se alguém montasse o plano B sem mexer no firmware.

  **O que ela custa, dito com todas as letras.** Dinheiro: o anúncio escolhido é de **R$ 776**, cerca de **US$ 144** a R$ 5,40 por dólar, contra os US$ 23,61 + US$ 66,45 = **US$ 90,06** do par — **US$ 54 a mais por placa** na tela, e cerca de US$ 52 a mais na placa inteira, porque o REG710 e o conector do filme saem junto; o total estimado vai de US$ 173 para cerca de **US$ 225**. Procedência: **não há canal autorizado** — a JDI não lista mais MIP, a Switch Science encerrou as vendas e nenhum distribuidor tem a peça —, de modo que se compra de revendedor, **sem garantia**, e em anúncios que chegam a nomear o B e o C no mesmo título, sendo que **o B não tem luz**. RAM: o quadro do JDI ocupa 36.482 B contra 12.482 B da Sharp, **24.000 B a mais**.

  **E abre uma pendência de alta prioridade, que precisa sair antes do layout:** **não se sabe por onde a luz do C se liga**. O FPC de 10 vias que as duas telas compartilham — `SCLK`, `SI`, `SCS`, `EXTCOMIN`, `DISP`, `VDDA`, `VDD`, `EXTMODE`, `VSS`, `VSSA` — **não tem par para o LED**, e o `J402` existia justamente para a luz separada da Sharp. O C tem de trazer um FPC com mais vias **ou** um rabicho próprio, e **nenhum documento do projeto traz isso**: a ficha que o projeto leu é a do **B**, que não tem luz e nem poderia responder. Sem essa informação não dá para desenhar a folha 4 nem posicionar o conector, e ela sai da ficha do LPM027M128C ou de uma amostra na mão.

- **O nRF52840 deixou de ser o alvo padrão** (decisão do dono, 2026-09-22): `tools/fw/fw.sh` compila para `nrf54lm20dk/nrf54lm20a/cpuapp` sem `BOARD`. O nRF52840 DK ainda compila com `BOARD=nrf52840dk/nrf52840`, mas não é mais verificado nem reportado.

- Quatro defeitos no coração do modelo, achados ao escrever o primeiro teste do `attitude.c` (`src/model/attitude.c`, `src/model/crash_recovery.c`, com `test_attitude` de 18 casos e `test_crash_recovery` de 8).
  1. **Segundos ativos pela metade.** O contador estava atrás de `(now - last_update) >= 1000`, medido no relógio do sistema no instante em que a thread chegava à época, e o `last_update` só andava quando o teste passava. Uma época chegando 998 ms depois da anterior não contava **e** não movia a referência, então a seguinte passava com dois períodos de intervalo e ainda contava **um**: alguns milissegundos de jitter de escalonamento viravam um conta-perde-conta-perde e cortavam o número ao meio. A velocidade média da página 1 é `dist × 3,6 / nbsec_act`, então o denominador pela metade mostrava o dobro da velocidade. Passa a contar uma vez por época pedalada, que é o que o `legacy/source/model/Attitude.cpp:509` faz.
  2. **Pedal recuperado voltava com um segundo.** O `restore_from_crash()` punha `saved.nbsec_act` na estrutura publicada mas deixava o contador por trás dela em zero, e a primeira época pedalada depois do restauro escrevia 1 por cima dos segundos do pedal inteiro.
  3. **Pedal recuperado voltava com desnível zero.** O bloco do nível do mar marcava `is_altitude_initialized = false` e **depois** restaurava; o `update_climb()` da mesma época via a marca e zerava o desnível recém-restaurado. O legacy faz na ordem certa — chama o `filterElevation()`, que é quem zera, **antes** de restaurar (`Attitude.cpp:390-416`).
  4. **O pedal restaurado era o próprio pedal em curso.** O bloco da recuperação fica em RAM não inicializada e o pedal em andamento o reescreve a cada 15 m, a partir dos primeiros 25 m de movimento; o restauro, porém, só acontece quando a referência do nível do mar aparece, depois de mais de quinze posições — um ou dois minutos adentro. Nessa altura o pedal novo já tinha sobrescrito o antigo uma dúzia de vezes, e o que voltava era o pedal que já estava rodando: a recuperação inteira não servia para nada. **O legacy tem o mesmo buraco** (`Attitude.cpp:393-416` lê o bloco vivo naquele momento tardio); aqui o bloco passa a ser copiado no boot, dentro do `crash_recovery_init()`, antes que qualquer coisa possa escrevê-lo. Junto foi o caso da partida nova: o `memset` do `init()` deixava `crc = 0`, e o CRC-8 de um bloco de zeros é zero, então um aparelho ligando pela primeira vez anunciava ao ciclista que um pedal tinha sido recuperado e restaurava um pedal de nada.

- Radar traseiro por ANT+ que nunca abriria o canal (`svc/radio/radio_svc.c`). O serviço de rádio sobe a pilha ANT e inicia o radar por BLE, mas ninguém chamava `radar_ant_start()`: a ligação faltava. Neste repositório a chamada responde `-ENOTSUP`, porque os parâmetros do canal do perfil ANT+ Bike Radar não estão aqui (`CONFIG_GNSS_ANT_RADAR_DEV_TYPE` é zero: o perfil está sob licença que proíbe redistribuir e o repositório é público), mas é o gancho que faltava para quem tem o perfil. Achado por uma varredura de módulos sem nenhum chamador em todo o firmware.

- `src/model/kalman.c` e `.h`, 139 linhas de filtro de Kalman escalar e de posição sem nenhum cliente: o único era o `locator.c`, que saiu. O `kalman_altitude.c`, que é o filtro de 3 estados portado do `Attitude.cpp`, não depende dele. O binário não mudou de tamanho, o que confirma que o linker já o descartava.
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

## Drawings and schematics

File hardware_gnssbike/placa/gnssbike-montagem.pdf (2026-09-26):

# Montagem - frente

# GNSS Bike Computer - placa 34 x 95 mm - NADA FABRICADO NEM MEDIDO

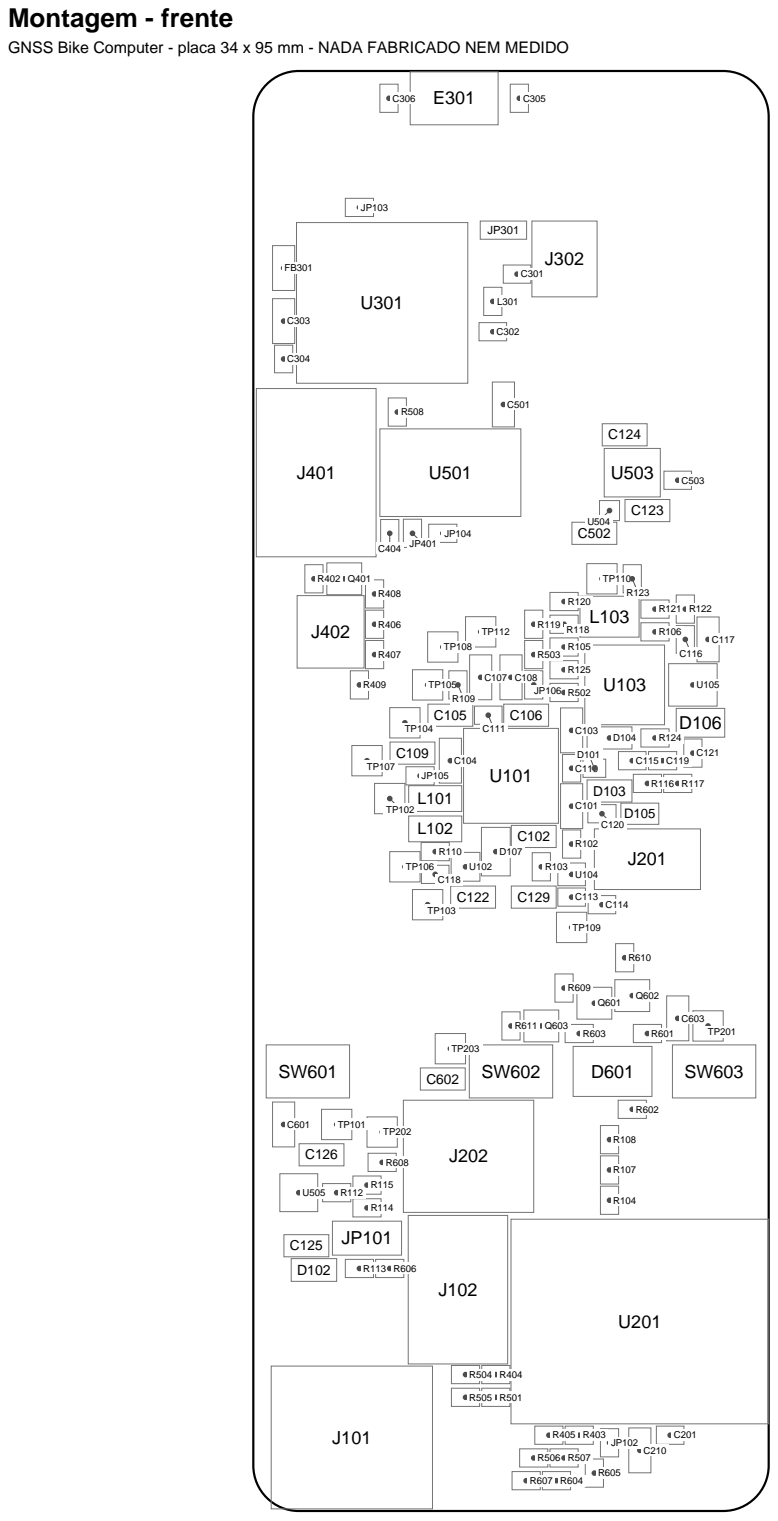
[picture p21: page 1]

# Montagem - verso

# GNSS Bike Computer - placa 34 x 95 mm - NADA FABRICADO NEM MEDIDO

LS601

J103

U502

RT101

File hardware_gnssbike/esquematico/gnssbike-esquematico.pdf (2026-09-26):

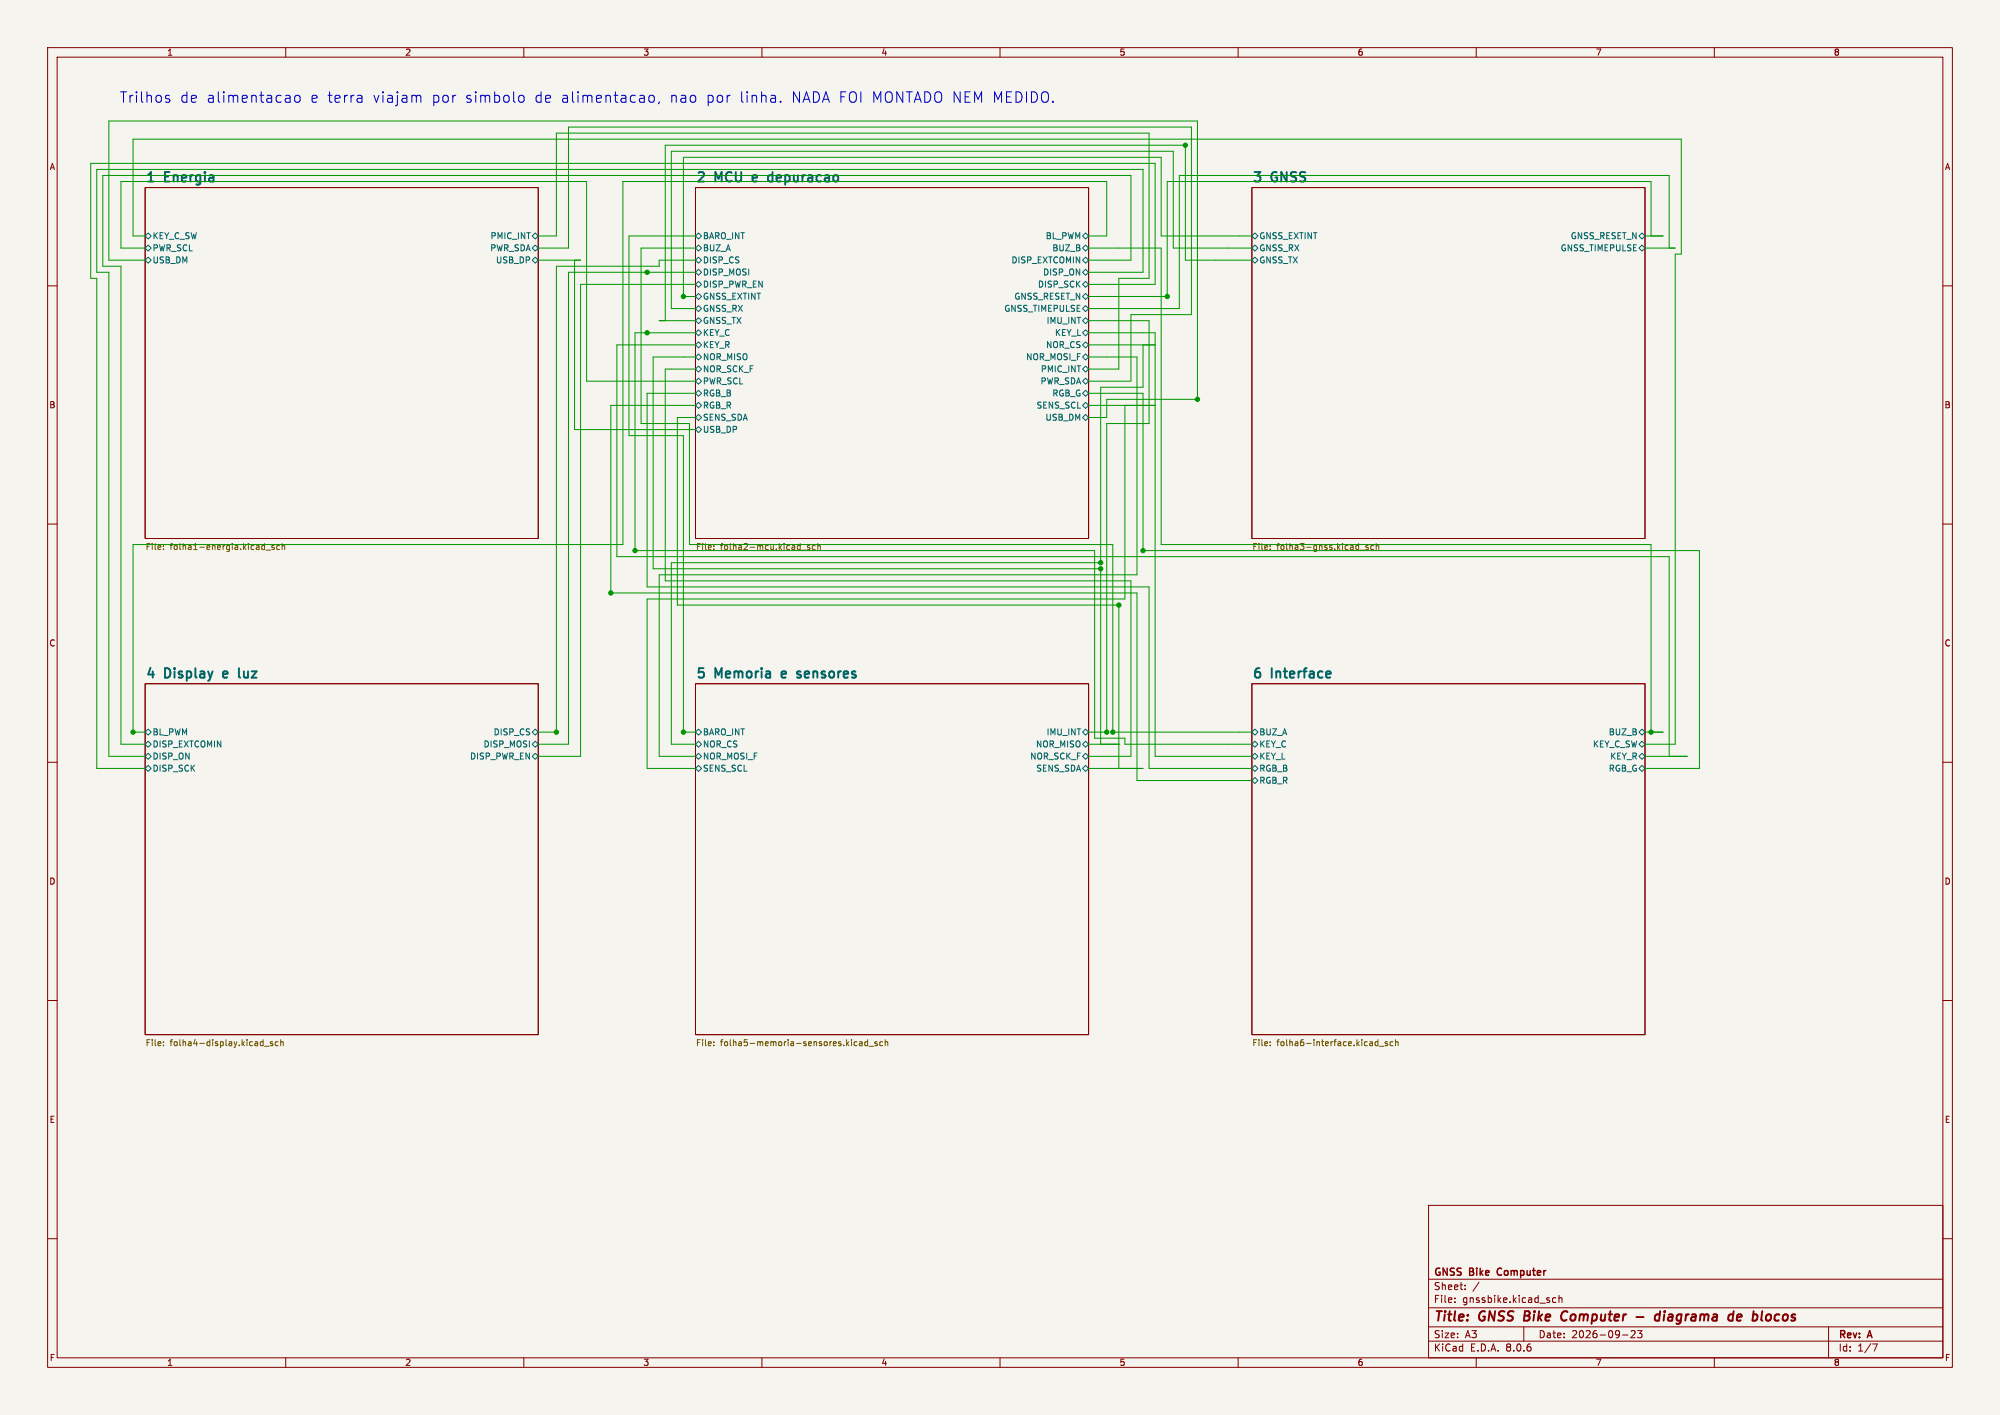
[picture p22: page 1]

Id: 1/7 Title: GNSS Bike Computer - diagrama de blocos

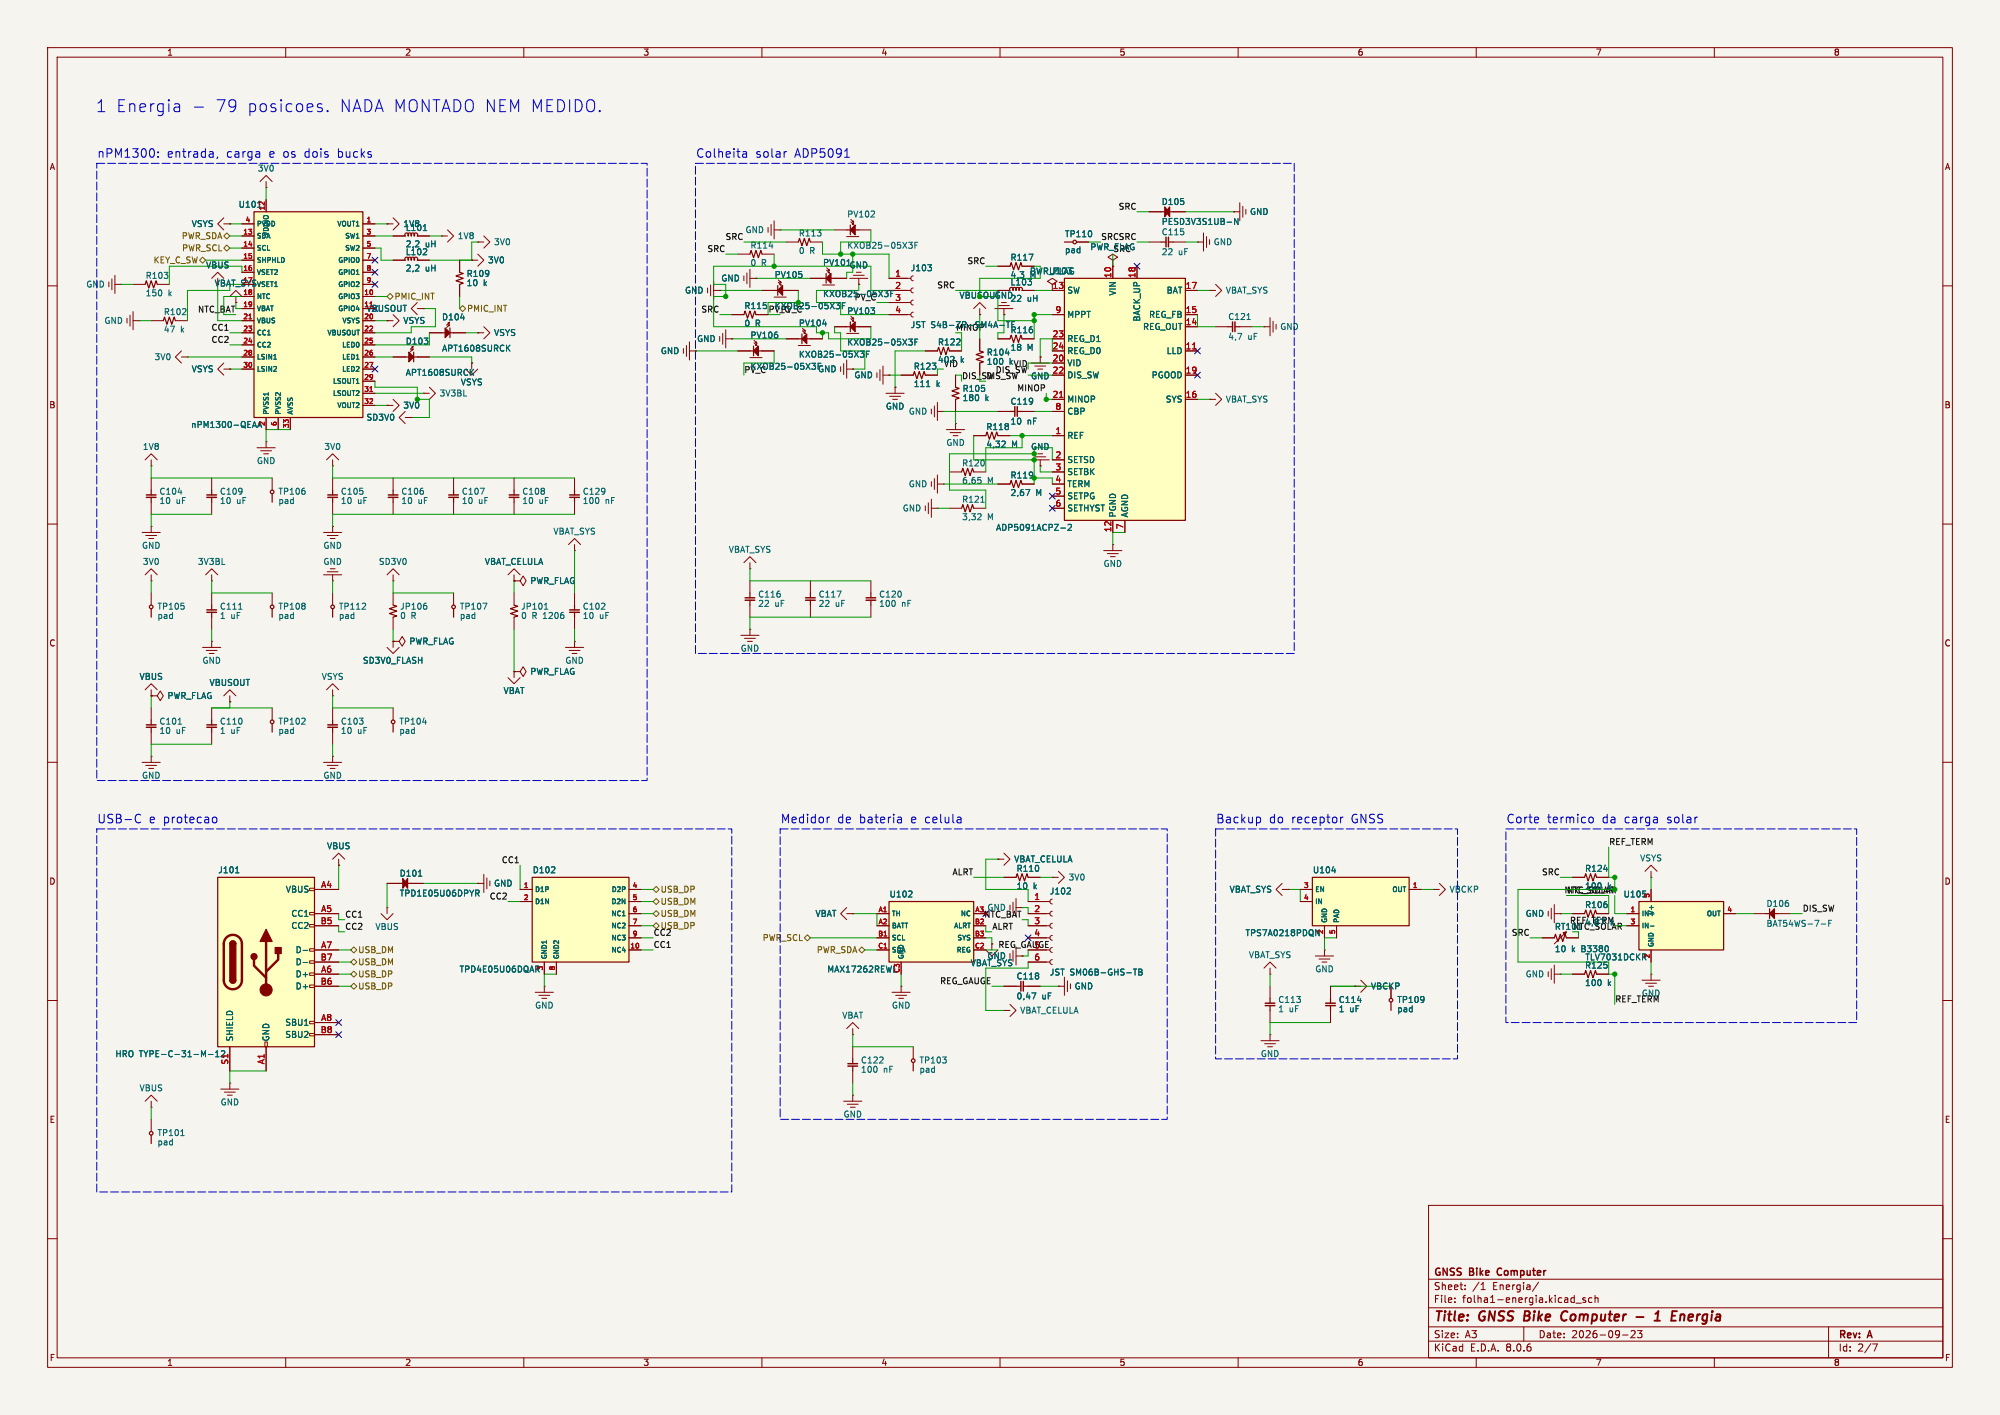
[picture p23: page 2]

1 Energia - 79 posicoes. NADA MONTADO NEM MEDIDO.

Id: 2/7 Title: GNSS Bike Computer - 1 Energia

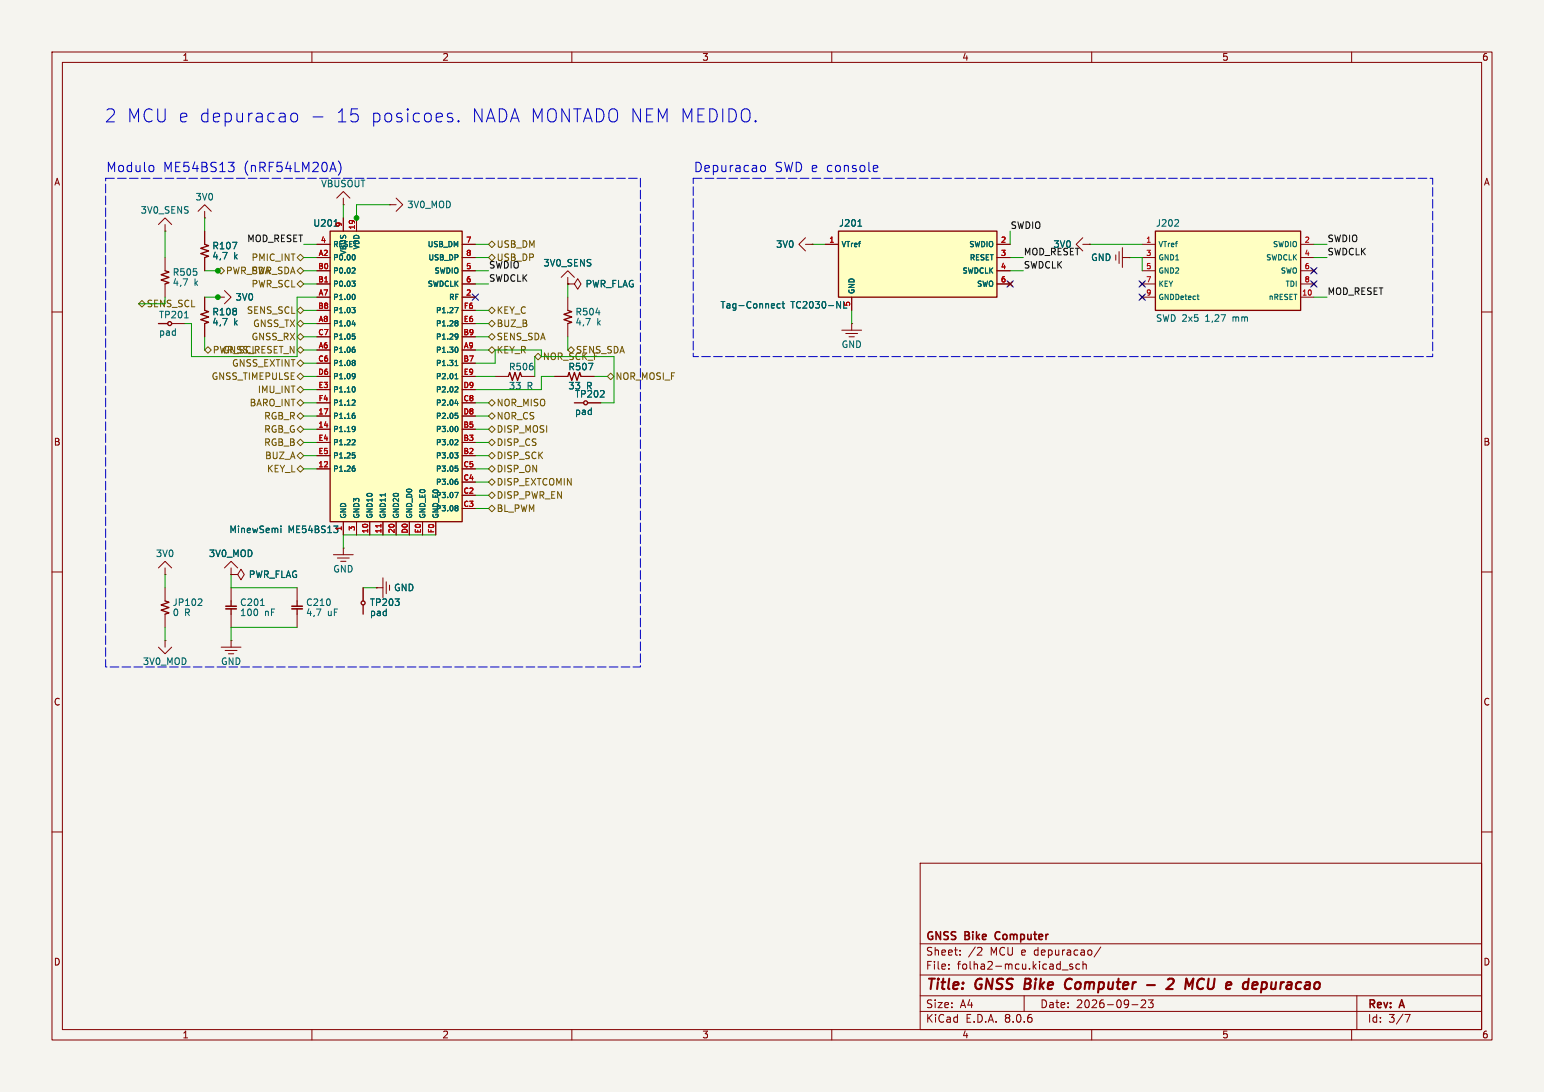
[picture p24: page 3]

2 MCU e depuracao - 15 posicoes. NADA MONTADO NEM MEDIDO.

5 SWO 6 J201 Tag-Connect TC2030-NL

3 RESET 4 SWDIO 5 SWDCLK 6 USB_DM 7 USB_DP VBUS 8

Id: 3/7 Title: GNSS Bike Computer - 2 MCU e depuracao

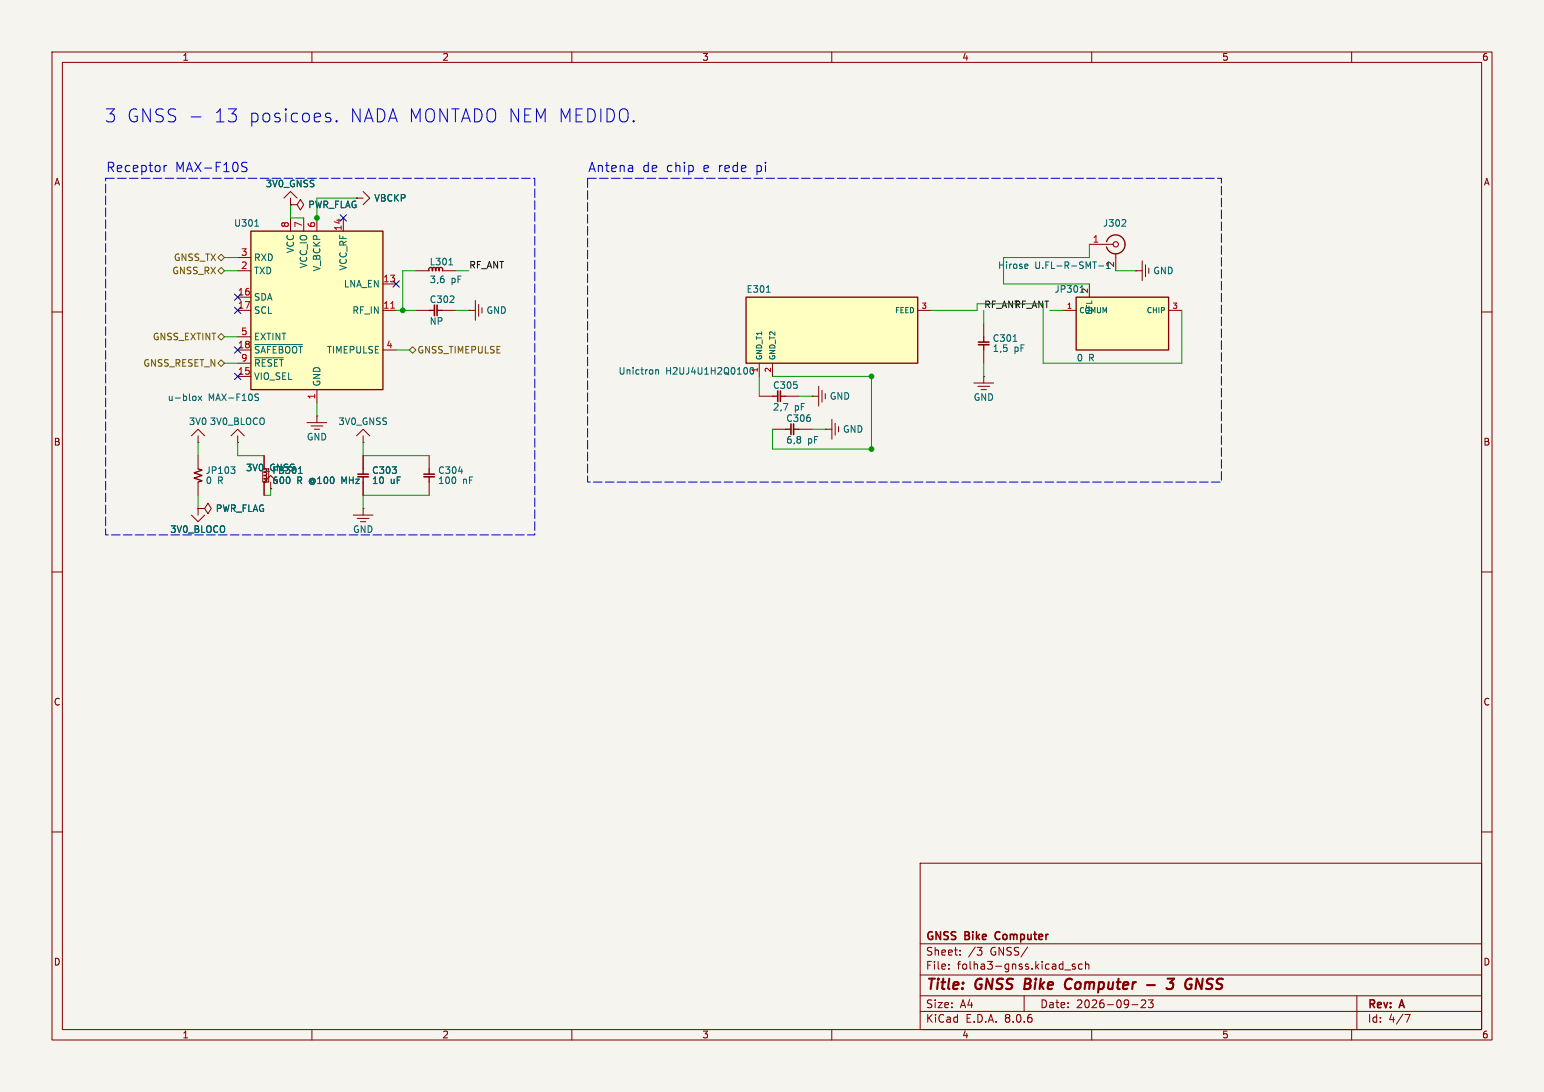
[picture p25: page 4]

3 GNSS - 13 posicoes. NADA MONTADO NEM MEDIDO.

Id: 4/7 Title: GNSS Bike Computer - 3 GNSS

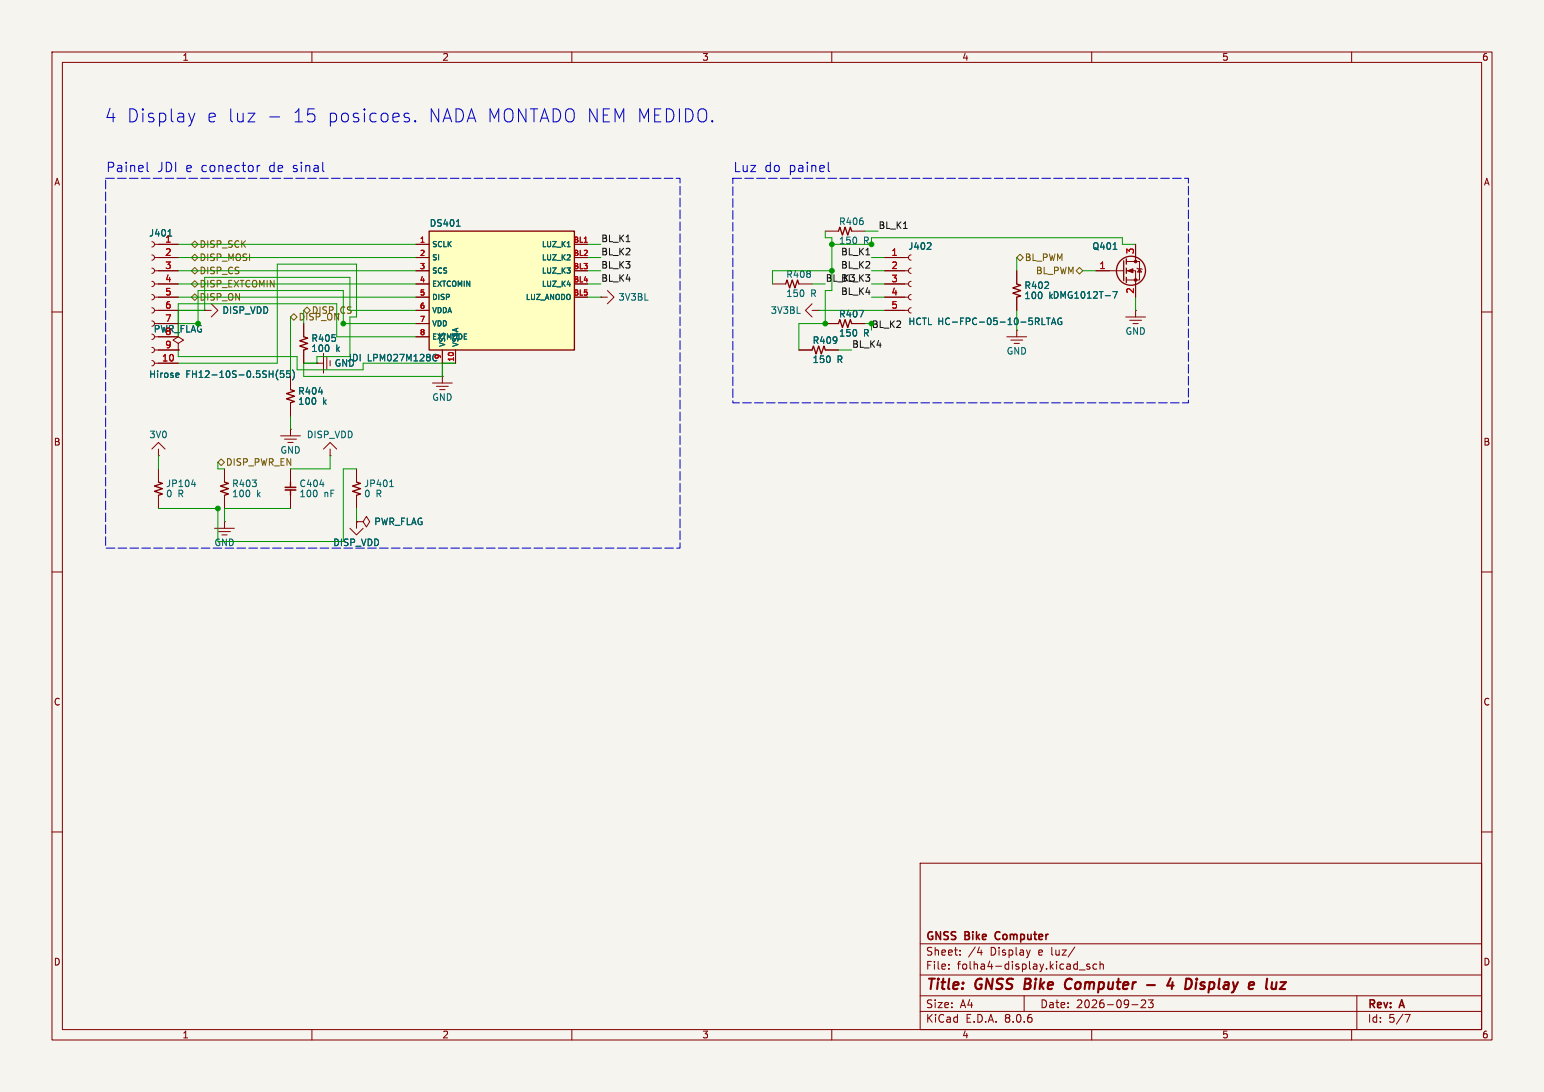
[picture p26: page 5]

4 Display e luz - 15 posicoes. NADA MONTADO NEM MEDIDO.

Id: 5/7 Title: GNSS Bike Computer - 4 Display e luz

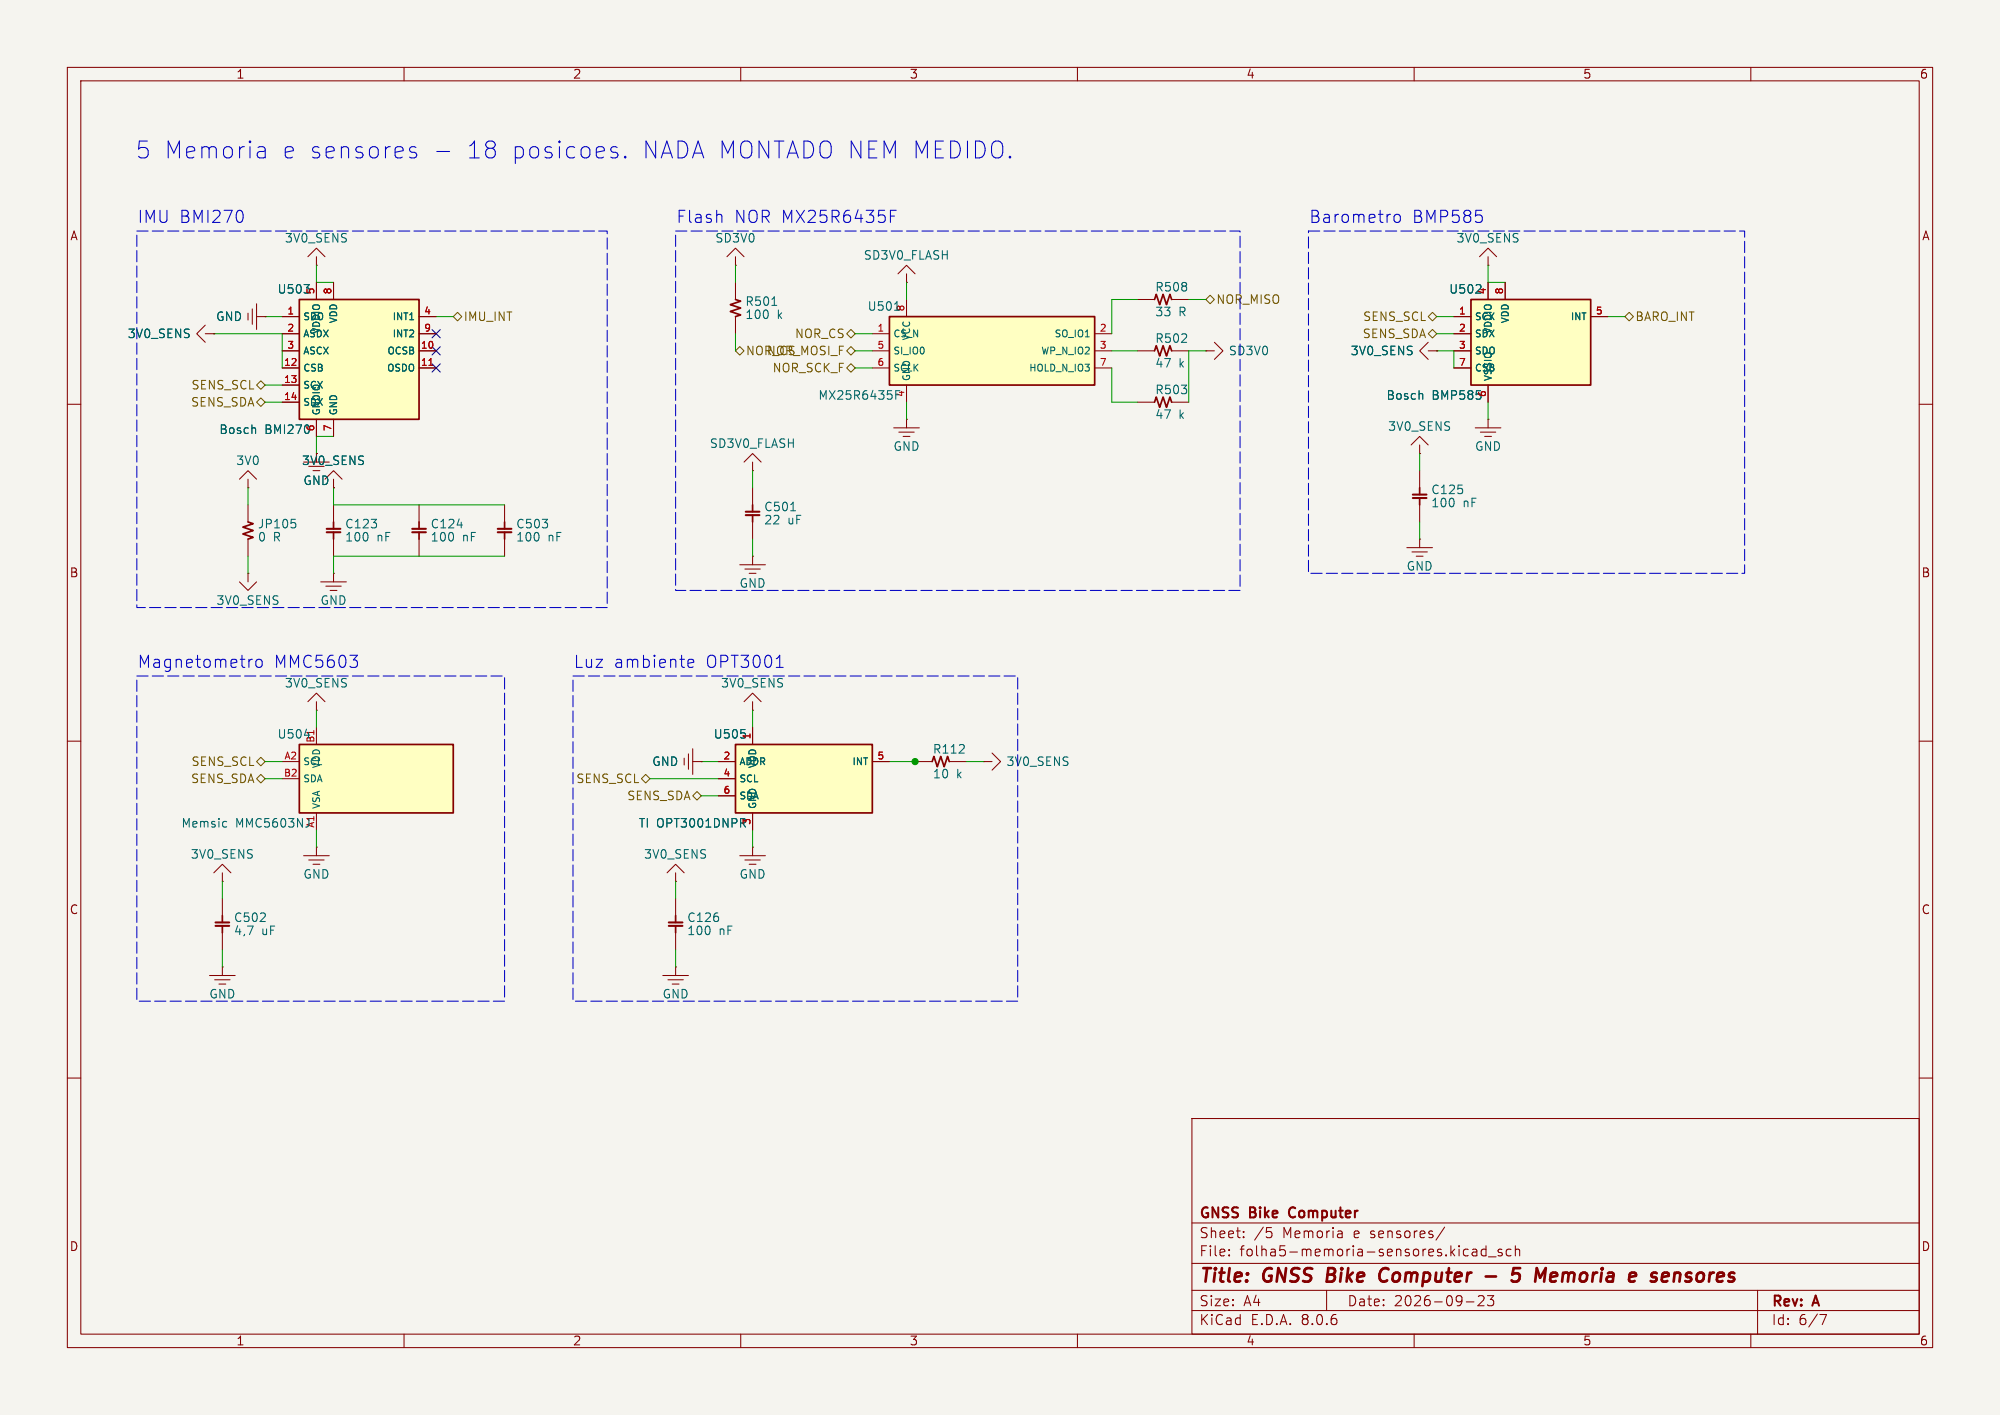
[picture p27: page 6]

5 Memoria e sensores - 18 posicoes. NADA MONTADO NEM MEDIDO.

Id: 6/7 Title: GNSS Bike Computer - 5 Memoria e sensores

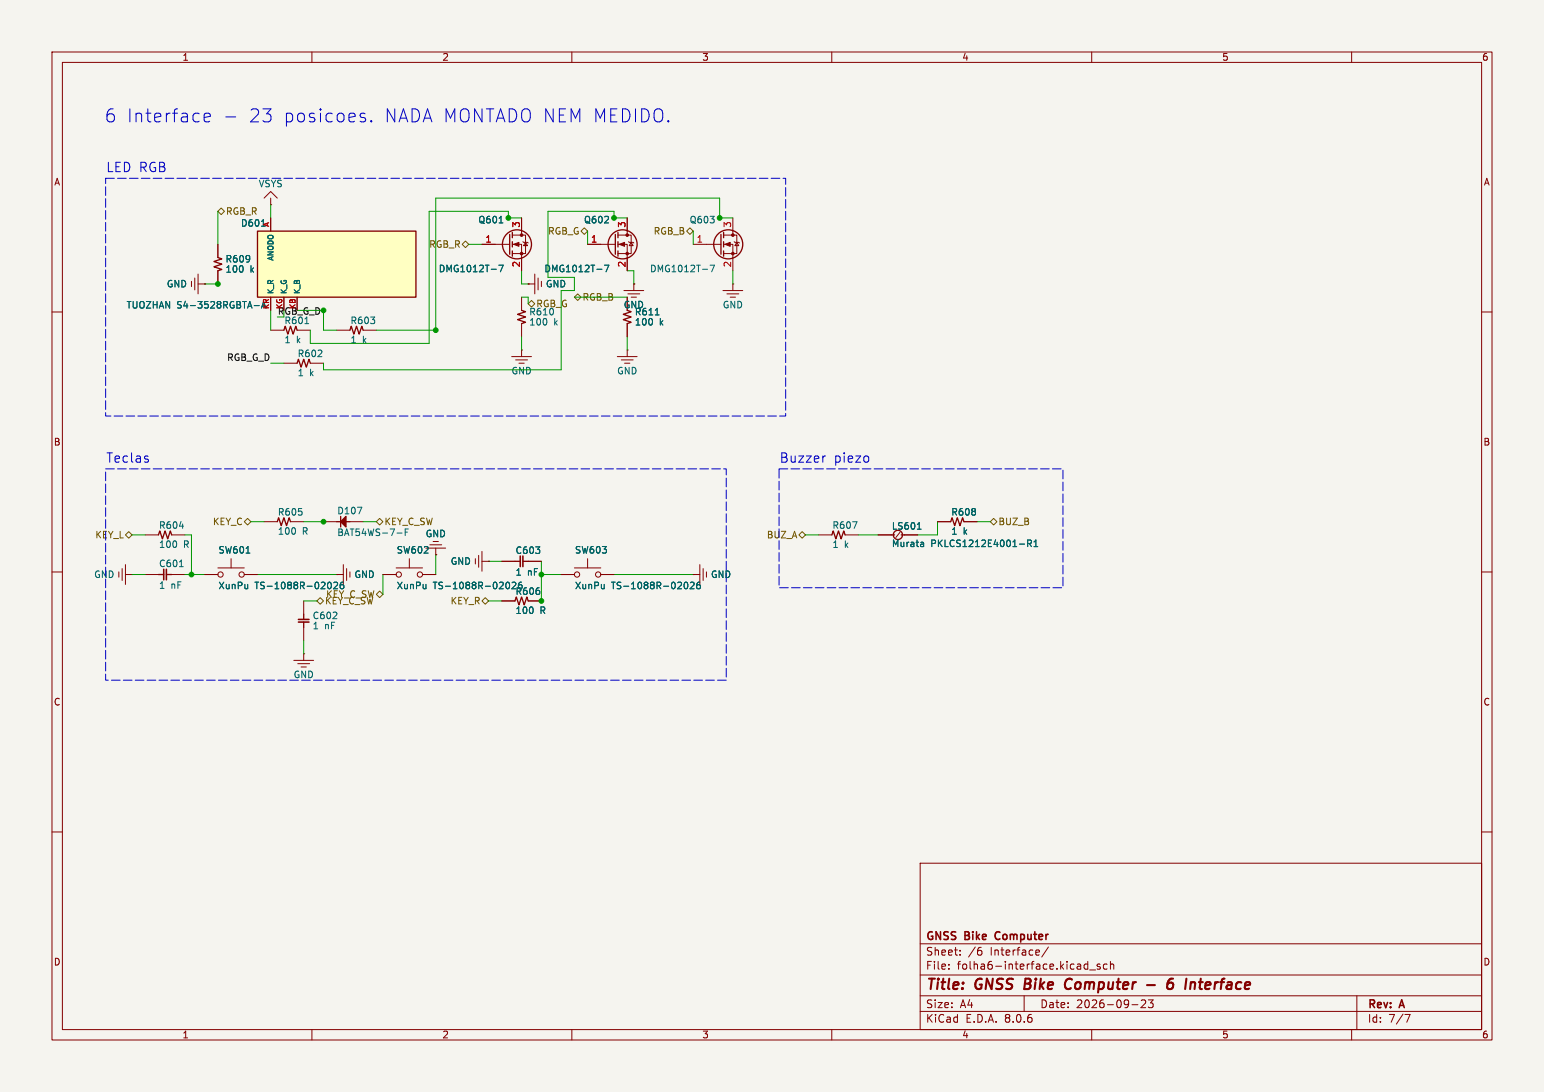
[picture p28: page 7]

A K_B KB K_G KG K_R KR D601 TUOZHAN S4-3528RGBTA-A GND GND

Id: 7/7 Title: GNSS Bike Computer - 6 Interface

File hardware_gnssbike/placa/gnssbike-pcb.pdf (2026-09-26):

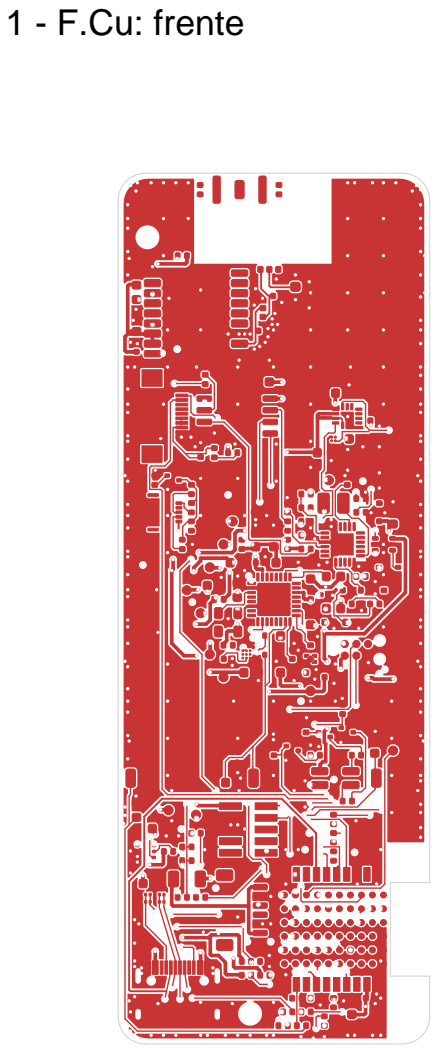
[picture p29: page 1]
1 - F.Cu: frente

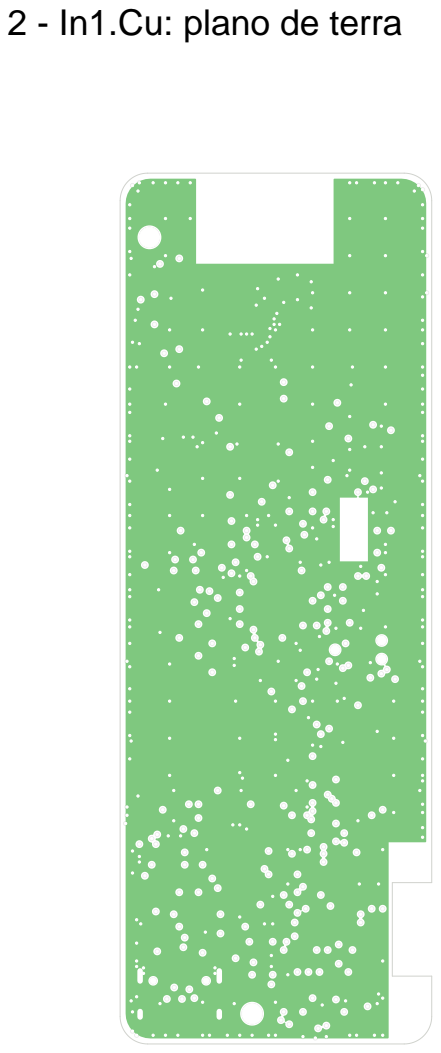
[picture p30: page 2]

2 - In1.Cu: plano de terra

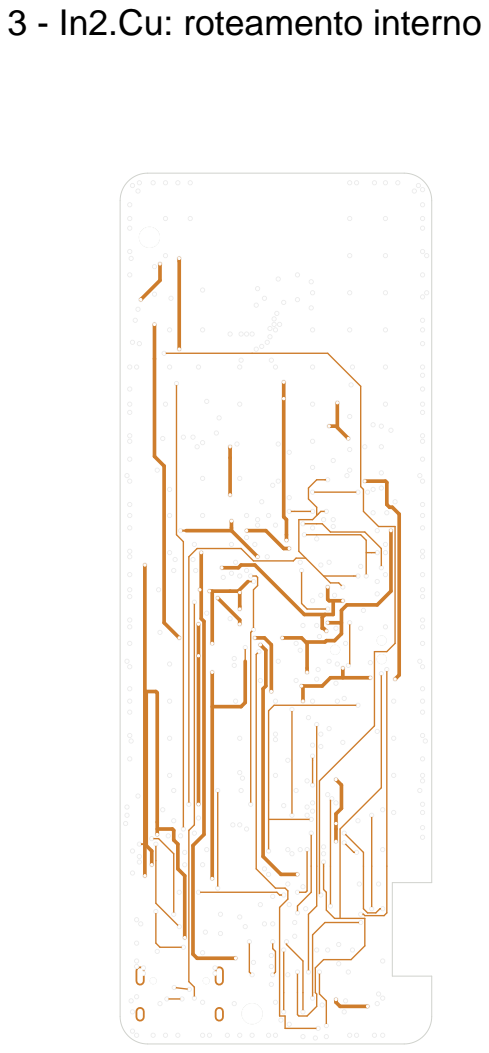
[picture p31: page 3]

3 - In2.Cu: roteamento interno

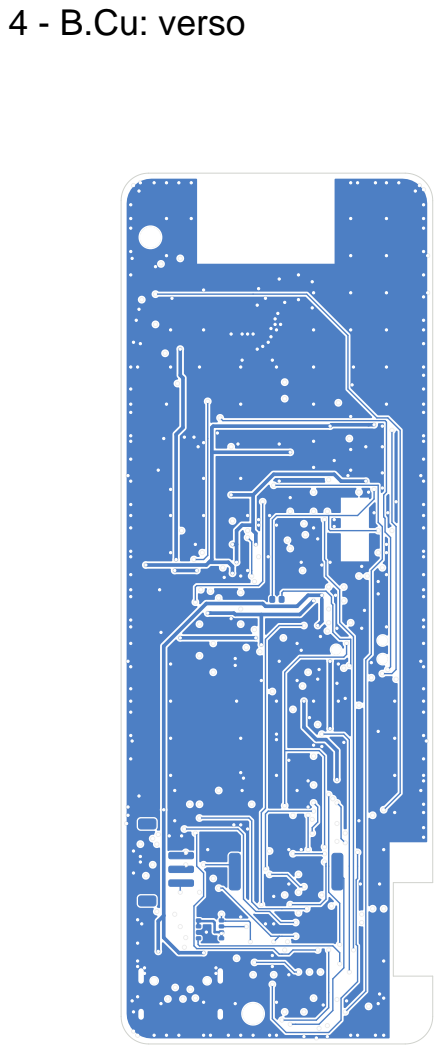
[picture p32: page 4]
4 - B.Cu: verso


5 - montagem da frente: serigrafia
L102 R112 D¹⁰²


6 - montagem do verso: serigrafia


7 - as quatro camadas juntas
L102 R112 D¹⁰²

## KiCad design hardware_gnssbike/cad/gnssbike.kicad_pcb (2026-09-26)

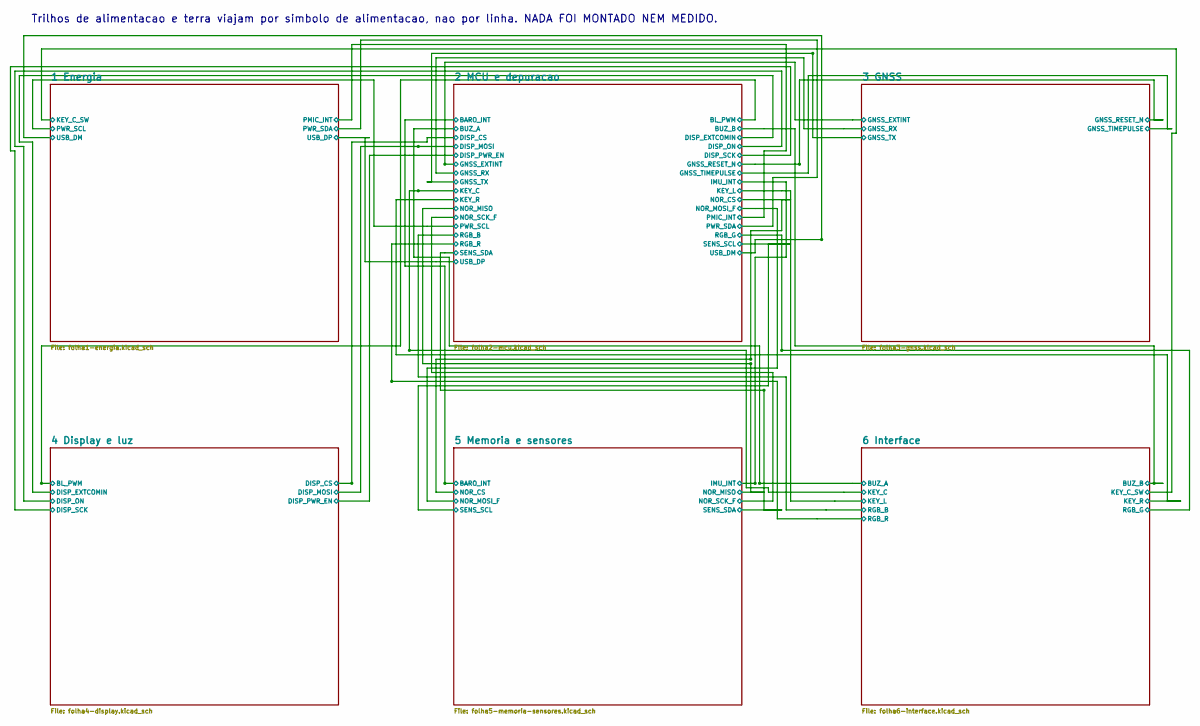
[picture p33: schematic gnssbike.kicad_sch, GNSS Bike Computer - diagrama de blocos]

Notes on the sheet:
Trilhos de alimentacao e terra viajam por simbolo de alimentacao, nao por linha. NADA FOI MONTADO NEM MEDIDO.

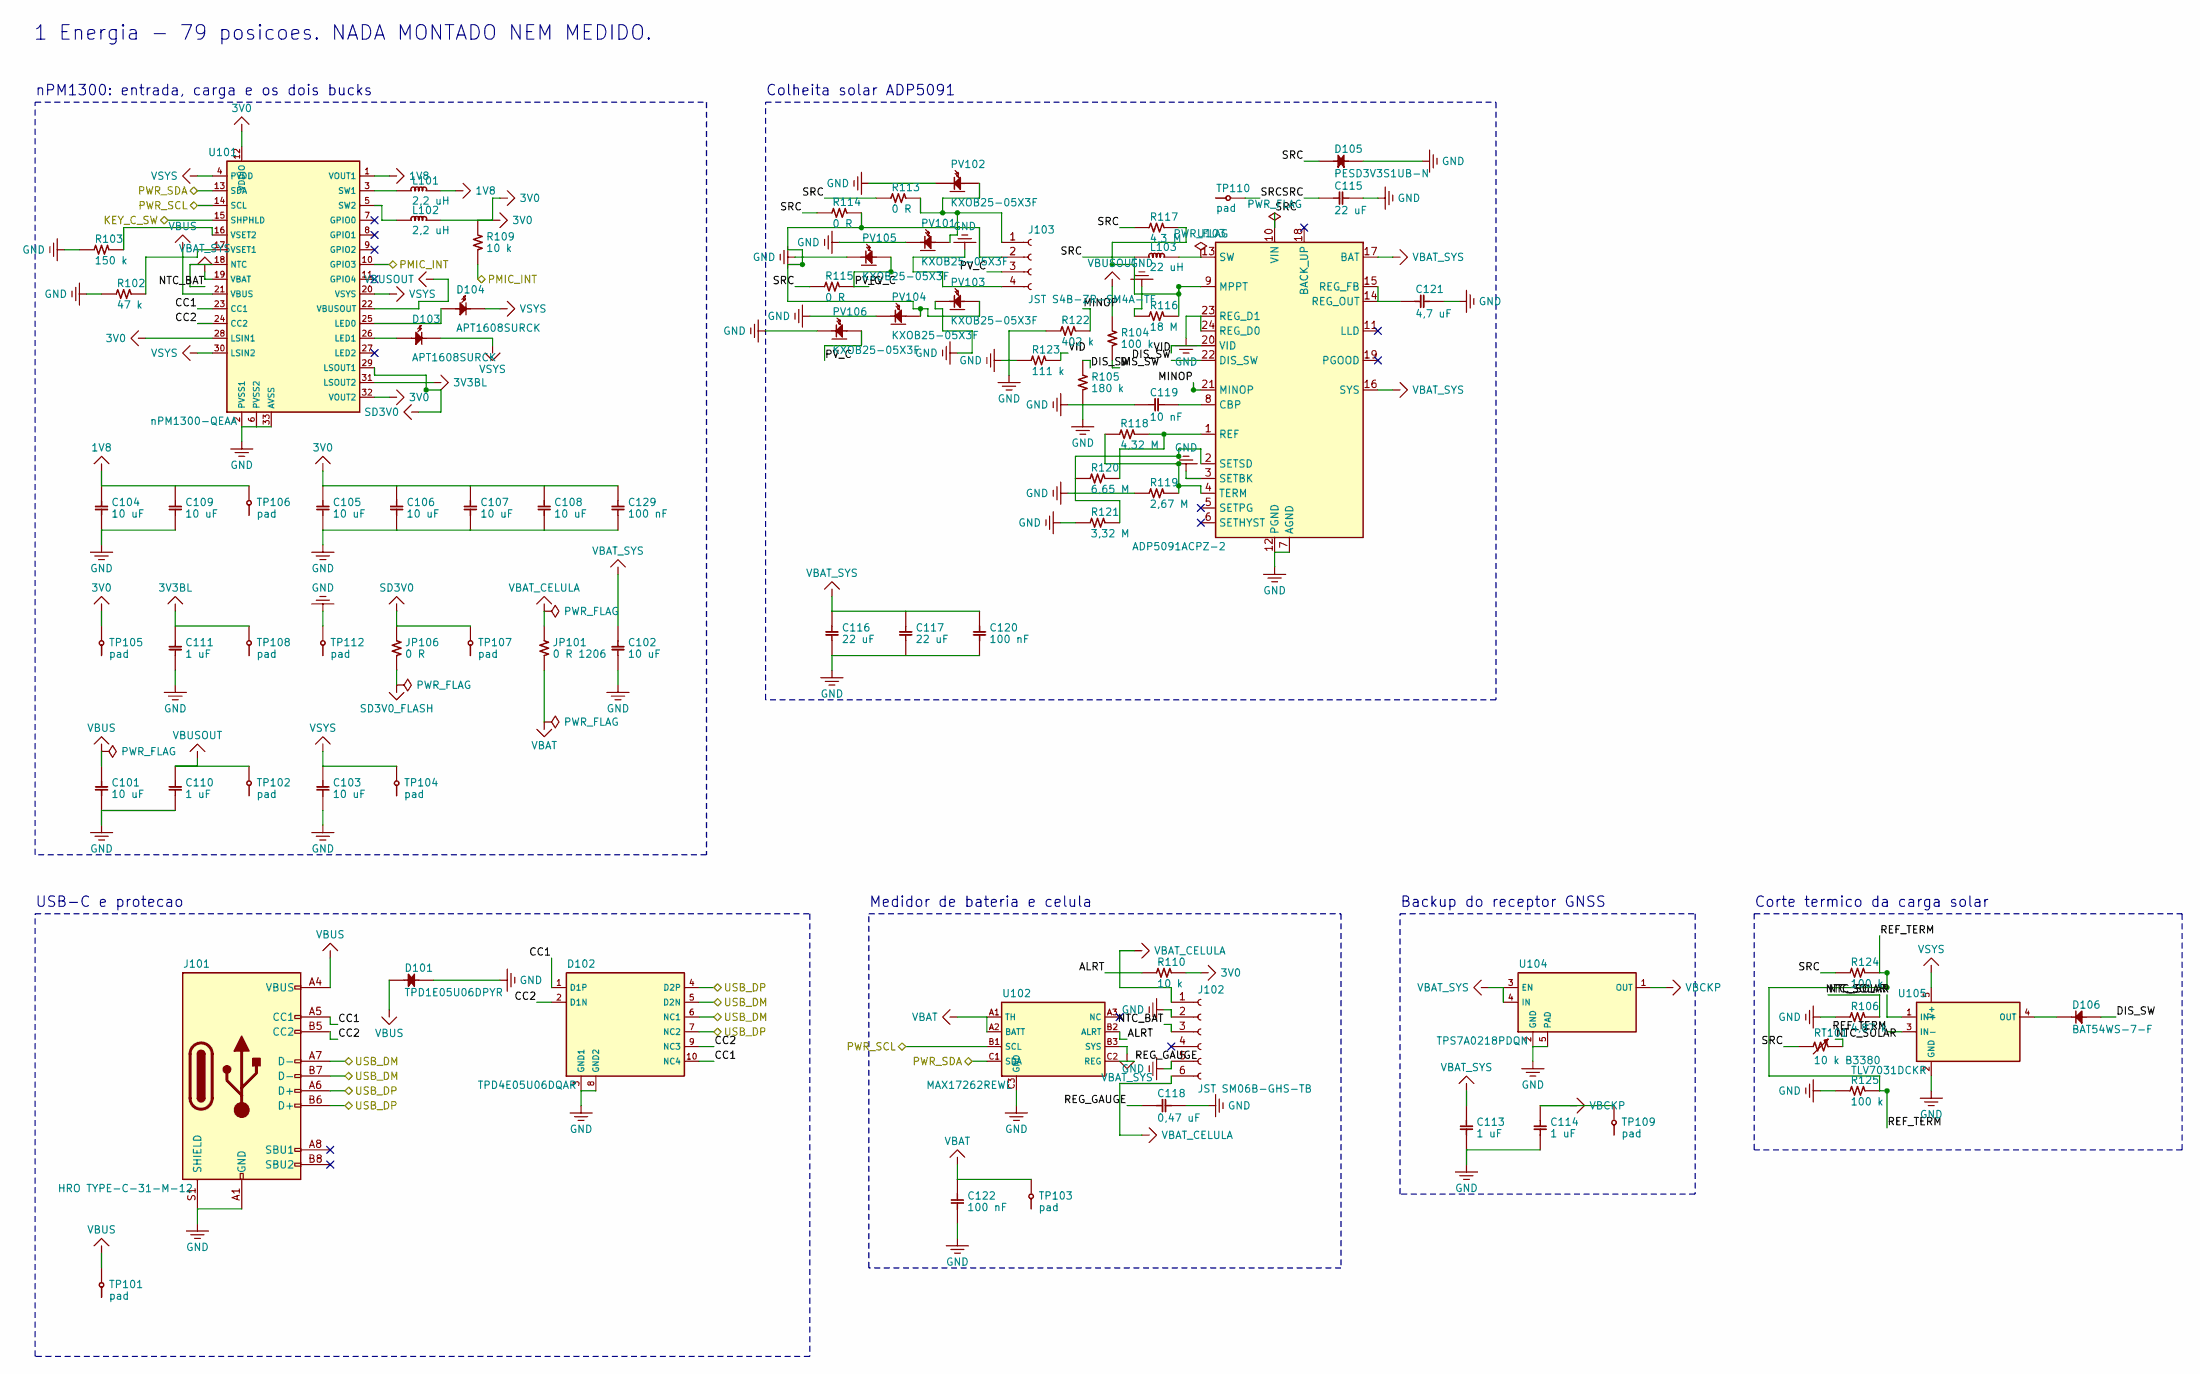
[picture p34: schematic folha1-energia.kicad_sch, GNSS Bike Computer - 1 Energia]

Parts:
C101, C102, C103, C104, C105, C106, C107, C108, C109: 10 uF; C_0603_1608Metric
C110, C111, C113, C114: 1 uF; C_0402_1005Metric
C115, C116: 22 uF; C_0402_1005Metric
C117: 22 uF; C_0603_1608Metric
C118: 0,47 uF; C_0402_1005Metric
C119: 10 nF; R_0402_1005Metric
C120: 100 nF; R_0402_1005Metric
C121: 4,7 uF; R_0402_1005Metric
C122, C129: 100 nF; C_0603_1608Metric
D101: TPD1E05U06DPYR; ESD761_X1SON-2_1x0.6mm
D102: TPD4E05U06DQAR; TPD4E05U06_USON-10_1x2.5mm_P0.5mm
D103, D104: APT1608SURCK; LED_0603_1608Metric
D105: PESD3V3S1UB-N; D_SOD-523
D106: BAT54WS-7-F; D_SOD-323
J101: HRO TYPE-C-31-M-12; USB_C_Receptacle_HRO_TYPE-C-31-M-12
J102: JST SM06B-GHS-TB; JST_GH_SM06B-GHS-TB_1x06-1MP_P1.25mm_Horizontal
J103: JST S4B-ZR-SM4A-TF; JST_ZH_S4B-ZR-SM4A-TF_1x04-1MP_P1.50mm_Horizontal
JP101: 0 R 1206; R_1206_3216Metric
JP106: 0 R; R_0402_1005Metric
L101, L102: 2,2 uH; L_0805_2012Metric
L103: 22 uH; L_1008_2520Metric
PV101, PV102, PV103, PV104, PV105, PV106: KXOB25-05X3F
R102: 47 k; R_0402_1005Metric
R103: 150 k; R_0402_1005Metric
R104, R124, R125: 100 k; R_0402_1005Metric
R105: 180 k; R_0402_1005Metric
R106: 4,87 k; R_0402_1005Metric
R109, R110: 10 k; R_0402_1005Metric
R113, R114, R115: 0 R; R_0402_1005Metric
R116: 18 M; R_0402_1005Metric
R117: 4,3 M; R_0402_1005Metric
R118: 4,32 M; R_0402_1005Metric
R119: 2,67 M; R_0402_1005Metric
R120: 6,65 M; R_0402_1005Metric
R121: 3,32 M; R_0402_1005Metric
R122: 402 k; R_0402_1005Metric
R123: 111 k; R_0402_1005Metric
RT101: 10 k B3380; R_0402_1005Metric
TP101, TP102, TP103, TP104, TP105, TP106, TP107, TP108, TP109, TP110, TP112: pad; TestPoint_Pad_D1.0mm
U101: nPM1300-QEAA; QFN-32-1EP_5x5mm_P0.5mm_EP3.45x3.45mm
U102: MAX17262REWL; MAX17262_WLP-9_1.4x1.4mm_P0.4mm
U103: ADP5091ACPZ-2; LFCSP-24-1EP_4x4mm_P0.5mm_EP2.3x2.3mm
U104: TPS7A0218PDQN; Texas_X2SON-4_1x1mm_P0.65mm
U105: TLV7031DCKR; SOT-353_SC-70-5

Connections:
1V8: C104.1, C109.1, L101.2, TP106.1, U101.1 (VOUT1)
3V0: C105.1, C106.1, C107.1, C108.1, C129.1, L102.2, R109.1, R110.1, TP105.1, U101.12 (VDDIO), U101.28 (LSIN1), U101.32 (VOUT2); also elsewhere on the board
3V3BL: C111.1, TP108.1, U101.31 (LSOUT2); also elsewhere on the board
ADP_REF: R118.1, R120.1, U103.1 (REF)
ALRT: R110.2, U102.B2 (ALRT)
BUCK1_SW: L101.1, U101.3 (SW1)
BUCK2_SW: L102.1, U101.5 (SW2)
CBP: C119.1, U103.8 (CBP)
CC1: D102.1 (D1P), D102.10 (NC4), J101.A5 (CC1), U101.23 (CC1)
CC2: D102.2 (D1N), D102.9 (NC3), J101.B5 (CC2), U101.24 (CC2)
DIS_SW: D106.1 (K), R104.2, R105.1, U103.22 (DIS_SW)
GND: C101.2, C102.2, C103.2, C104.2, C105.2, C106.2, C107.2, C108.2, C109.2, C110.2, C111.2, C113.2, C114.2, C115.2, C116.2, C117.2, C118.2, C119.2, C120.2, C121.2, C122.2, C129.2, D101.2 (GND), D102.3 (GND1), D102.8 (GND2), D105.2 (GND), J101.A1 (GND), J101.A12 (GND), J101.B1 (GND), J101.B12 (GND), J101.S1 (SHIELD), J102.2, J102.5, J103.4, PV101.2 (N), PV102.2 (N), PV103.2 (N), PV104.2 (N), PV105.2 (N), PV106.2 (N), R102.2, R103.2, R105.2, R106.2, R116.2, R119.2, R121.2, R122.2, R123.2, R125.2, TP112.1, U101.2 (PVSS1), U101.6 (PVSS2), U101.33 (AVSS), U102.C3 (GND), U103.3 (SETBK), U103.7 (AGND), U103.12 (PGND), U103.23 (REG_D1), U103.24 (REG_D0), U103.25 (AGND), U104.2 (GND), U104.5 (PAD), U105.2 (GND); also elsewhere on the board
KEY_C_SW: U101.15 (SHPHLD); also elsewhere on the board
LED_CHG: D103.1 (K), U101.26 (LED1)
LED_ERR: D104.1 (K), U101.25 (LED0)
MINOP: R122.1, U103.21 (MINOP)
MPPT: R116.1, R117.2, U103.9 (MPPT)
NTC_BAT: J102.3, U101.18 (NTC)
NTC_SOLAR: R106.1, RT101.2, U105.1 (IN+)
PMIC_INT: R109.2, U101.10 (GPIO3); also elsewhere on the board
PV_A: J103.1, PV101.1, PV102.1, R113.1
PV_B: J103.2, PV103.1, PV104.1, R114.1
PV_C: J103.3, PV105.1, PV106.1, R115.1
PWR_SCL: U101.14 (SCL), U102.B1 (SCL); also elsewhere on the board
PWR_SDA: U101.13 (SDA), U102.C1 (SDA); also elsewhere on the board
REF_TERM: R124.2, R125.1, U105.3 (IN-)
REG_GAUGE: C118.1, U102.C2 (REG)
REG_OUT: C121.1, U103.14 (REG_OUT), U103.15 (REG_FB)
RVSET1: R102.1, U101.17 (VSET1)
RVSET2: R103.1, U101.16 (VSET2)
SD3V0: JP106.1, TP107.1, U101.29 (LSOUT1); also elsewhere on the board
SD3V0_FLASH: JP106.2; also elsewhere on the board
SETSD: R120.2, R121.1, U103.2 (SETSD)
SRC: C115.1, D105.1 (IO), L103.1, R113.2, R114.2, R115.2, R117.1, R124.1, RT101.1, TP110.1, U103.10 (VIN)
SW_DCDC: L103.2, U103.13 (SW)
TERM: R118.2, R119.1, U103.4 (TERM)
TERM_QUENTE: D106.2 (A), U105.4 (OUT)
USB_DM: D102.5 (D2N), D102.6 (NC1), J101.A7 (D-), J101.B7 (D-); also elsewhere on the board
USB_DP: D102.4 (D2P), D102.7 (NC2), J101.A6 (D+), J101.B6 (D+); also elsewhere on the board
VBAT: C122.1, JP101.2, TP103.1, U102.A1 (TH), U102.A2 (BATT)
VBAT_CELULA: J102.1, J102.6, JP101.1
VBAT_SYS: C102.1, C113.1, C116.1, C117.1, C120.1, U101.19 (VBAT), U102.B3 (SYS), U103.16 (SYS), U103.17 (BAT), U104.3 (EN), U104.4 (IN)
VBCKP: C114.1, TP109.1, U104.1 (OUT); also elsewhere on the board
VBUS: C101.1, D101.1 (IO), J101.A4 (VBUS), J101.A9 (VBUS), J101.B4 (VBUS), J101.B9 (VBUS), TP101.1, U101.21 (VBUS)
VBUSOUT: C110.1, R104.1, TP102.1, U101.22 (VBUSOUT); also elsewhere on the board
VID: R123.1, U103.20 (VID)
VSYS: C103.1, D103.2 (A), D104.2 (A), TP104.1, U101.4 (PVDD), U101.20 (VSYS), U101.30 (LSIN2), U105.5 (V+); also elsewhere on the board

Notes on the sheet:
USB-C e protecao
nPM1300: entrada, carga e os dois bucks
Medidor de bateria e celula
Backup do receptor GNSS
Colheita solar ADP5091
Corte termico da carga solar
1 Energia - 79 posicoes. NADA MONTADO NEM MEDIDO.

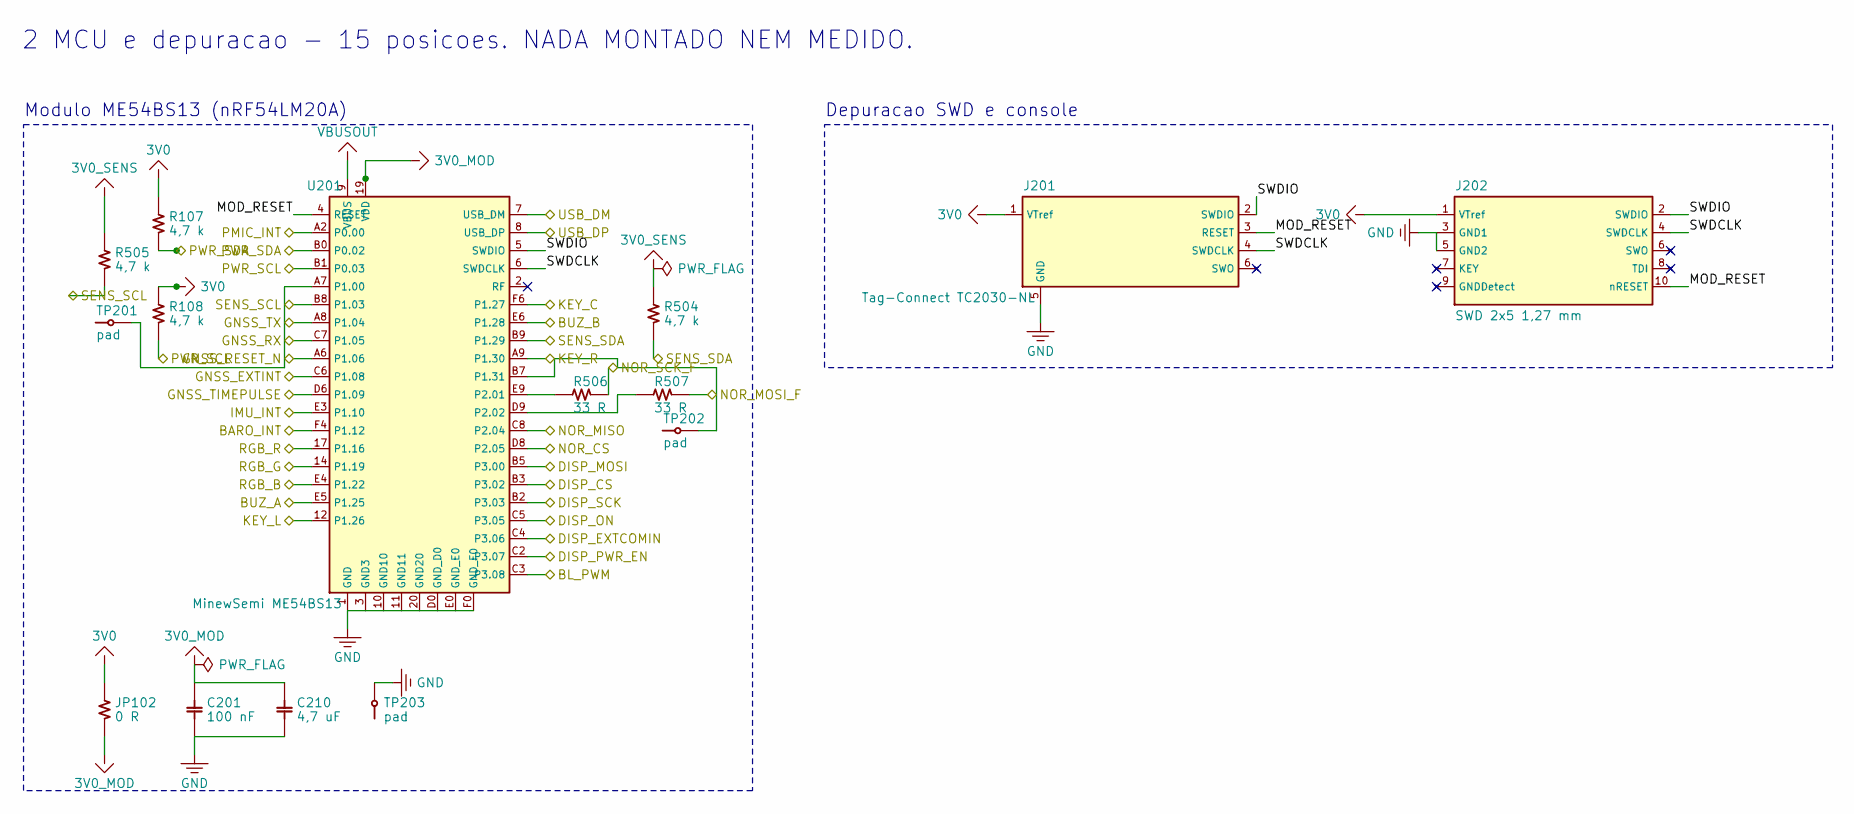
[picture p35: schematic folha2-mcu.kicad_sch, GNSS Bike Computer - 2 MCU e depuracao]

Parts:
C201: 100 nF; C_0402_1005Metric
C210: 4,7 uF; C_0603_1608Metric
J201: Tag-Connect TC2030-NL; Tag-Connect_TC2030-IDC-NL_2x03_P1.27mm_Vertical
J202: SWD 2x5 1,27 mm; PinHeader_2x05_P1.27mm_Vertical_SMD
JP102: 0 R; R_0402_1005Metric
R107, R108, R504, R505: 4,7 k; R_0402_1005Metric
R506, R507: 33 R; R_0402_1005Metric
TP201, TP202, TP203: pad; TestPoint_Pad_D1.0mm
U201: MinewSemi ME54BS13; MinewSemi_ME54BS13_16.5x12mm

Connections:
3V0: J201.1 (VTref), J202.1 (VTref), JP102.1, R107.1, R108.1; also elsewhere on the board
3V0_MOD: C201.1, C210.1, JP102.2, U201.19 (VDD)
3V0_SENS: R504.1, R505.1; also elsewhere on the board
BARO_INT: U201.F4 (P1.12); also elsewhere on the board
BL_PWM: U201.C3 (P3.08); also elsewhere on the board
BUZ_A: U201.E5 (P1.25); also elsewhere on the board
BUZ_B: U201.E6 (P1.28); also elsewhere on the board
CON_RX: TP202.1, U201.B7 (P1.31)
CON_TX: TP201.1, U201.A7 (P1.00)
DISP_CS: U201.B3 (P3.02); also elsewhere on the board
DISP_EXTCOMIN: U201.C4 (P3.06); also elsewhere on the board
DISP_MOSI: U201.B5 (P3.00); also elsewhere on the board
DISP_ON: U201.C5 (P3.05); also elsewhere on the board
DISP_PWR_EN: U201.C2 (P3.07); also elsewhere on the board
DISP_SCK: U201.B2 (P3.03); also elsewhere on the board
GND: C201.2, C210.2, J201.5 (GND), J202.3 (GND1), J202.5 (GND2), TP203.1, U201.1 (GND), U201.3 (GND3), U201.10 (GND10), U201.11 (GND11), U201.20 (GND20), U201.D0 (GND_D0), U201.E0 (GND_E0), U201.F0 (GND_F0); also elsewhere on the board
GNSS_EXTINT: U201.C6 (P1.08); also elsewhere on the board
GNSS_RESET_N: U201.A6 (P1.06); also elsewhere on the board
GNSS_RX: U201.C7 (P1.05); also elsewhere on the board
GNSS_TIMEPULSE: U201.D6 (P1.09); also elsewhere on the board
GNSS_TX: U201.A8 (P1.04); also elsewhere on the board
IMU_INT: U201.E3 (P1.10); also elsewhere on the board
KEY_C: U201.F6 (P1.27); also elsewhere on the board
KEY_L: U201.12 (P1.26); also elsewhere on the board
KEY_R: U201.A9 (P1.30); also elsewhere on the board
MOD_RESET: J201.3 (RESET), J202.10 (nRESET), U201.4 (RESET)
NOR_CS: U201.D8 (P2.05); also elsewhere on the board
NOR_MISO: U201.C8 (P2.04); also elsewhere on the board
NOR_MOSI: R507.1, U201.D9 (P2.02)
NOR_MOSI_F: R507.2; also elsewhere on the board
NOR_SCK: R506.1, U201.E9 (P2.01)
NOR_SCK_F: R506.2; also elsewhere on the board
PMIC_INT: U201.A2 (P0.00); also elsewhere on the board
PWR_SCL: R108.2, U201.B1 (P0.03); also elsewhere on the board
PWR_SDA: R107.2, U201.B0 (P0.02); also elsewhere on the board
RGB_B: U201.E4 (P1.22); also elsewhere on the board
RGB_G: U201.14 (P1.19); also elsewhere on the board
RGB_R: U201.17 (P1.16); also elsewhere on the board
SENS_SCL: R505.2, U201.B8 (P1.03); also elsewhere on the board
SENS_SDA: R504.2, U201.B9 (P1.29); also elsewhere on the board
SWDCLK: J201.4 (SWDCLK), J202.4 (SWDCLK), U201.6 (SWDCLK)
SWDIO: J201.2 (SWDIO), J202.2 (SWDIO), U201.5 (SWDIO)
USB_DM: U201.7 (USB_DM); also elsewhere on the board
USB_DP: U201.8 (USB_DP); also elsewhere on the board
VBUSOUT: U201.9 (VBUS); also elsewhere on the board

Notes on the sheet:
Modulo ME54BS13 (nRF54LM20A)
Depuracao SWD e console
2 MCU e depuracao - 15 posicoes. NADA MONTADO NEM MEDIDO.

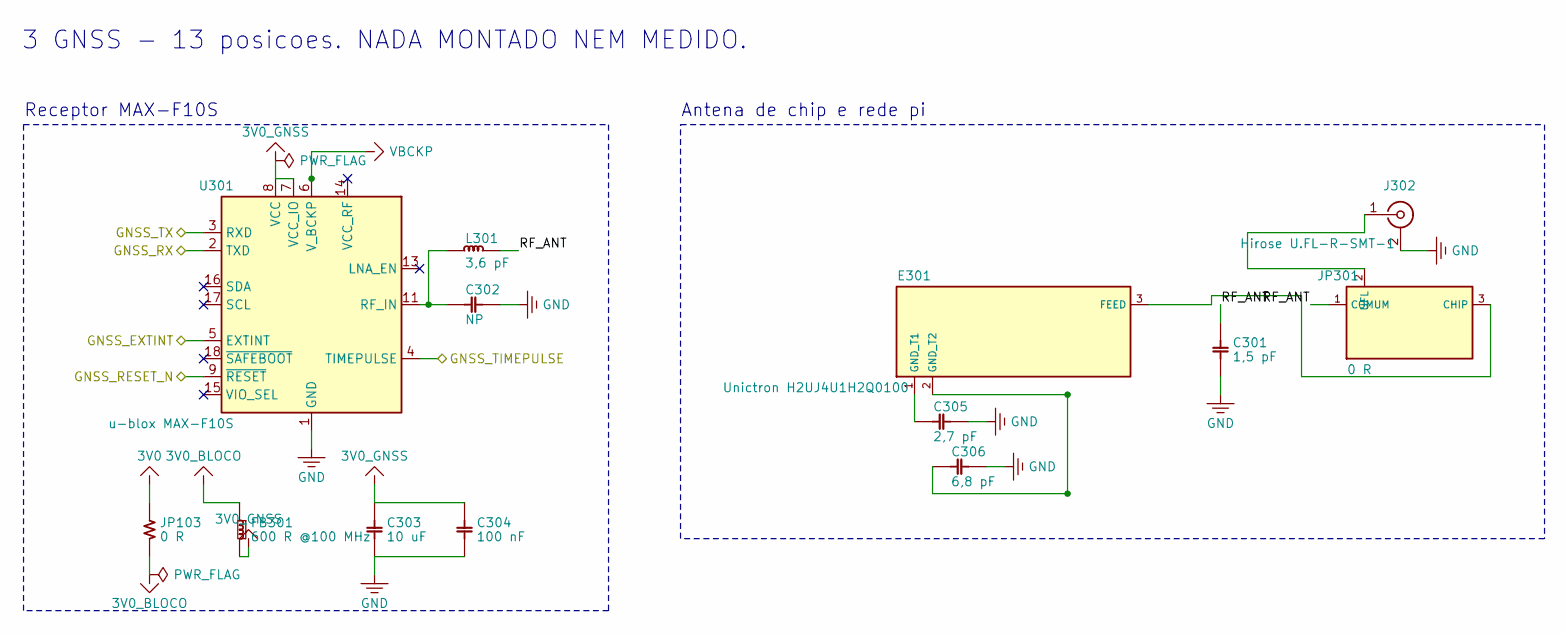
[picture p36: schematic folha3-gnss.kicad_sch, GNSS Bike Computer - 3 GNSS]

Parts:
C301: 1,5 pF; C_0402_1005Metric
C302: NP; C_0402_1005Metric
C303: 10 uF; C_0603_1608Metric
C304: 100 nF; C_0402_1005Metric
C305: 2,7 pF; R_0402_1005Metric
C306: 6,8 pF; R_0402_1005Metric
E301: Unictron H2UJ4U1H2Q0100; Antena_Unictron_H2UJ4U1H2Q0100_5x3mm
FB301: 600 R @100 MHz; L_0603_1608Metric
J302: Hirose U.FL-R-SMT-1; U.FL_Hirose_U.FL-R-SMT-1_Vertical
JP103: 0 R; R_0402_1005Metric
JP301: 0 R; JumperRF_3x0402
L301: 3,6 pF; L_0402_1005Metric
U301: u-blox MAX-F10S; u-blox_MAX_LCC-18_9.7x10.1mm

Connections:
3V0: JP103.1; also elsewhere on the board
3V0_BLOCO: FB301.1, JP103.2
3V0_GNSS: C303.1, C304.1, FB301.2, U301.7 (VCC_IO), U301.8 (VCC)
ANT_T1: C305.1, E301.1 (GND_T1)
ANT_T2: C306.1, E301.2 (GND_T2)
GND: C301.2, C302.2, C303.2, C304.2, C305.2, C306.2, J302.2 (Ext), U301.1 (GND), U301.10 (GND), U301.12 (GND); also elsewhere on the board
GNSS_EXTINT: U301.5 (EXTINT); also elsewhere on the board
GNSS_RESET_N: U301.9 (~RESET); also elsewhere on the board
GNSS_RX: U301.2 (TXD); also elsewhere on the board
GNSS_TIMEPULSE: U301.4 (TIMEPULSE); also elsewhere on the board
GNSS_TX: U301.3 (RXD); also elsewhere on the board
RF_ANT: C301.1, JP301.1 (COMUM), L301.1
RF_CHIP: E301.3 (FEED), JP301.3 (CHIP)
RF_IN: C302.1, L301.2, U301.11 (RF_IN)
RF_UFL: J302.1 (In), JP301.2 (UFL)
VBCKP: U301.6 (V_BCKP); also elsewhere on the board

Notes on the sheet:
Receptor MAX-F10S
Antena de chip e rede pi
3 GNSS - 13 posicoes. NADA MONTADO NEM MEDIDO.

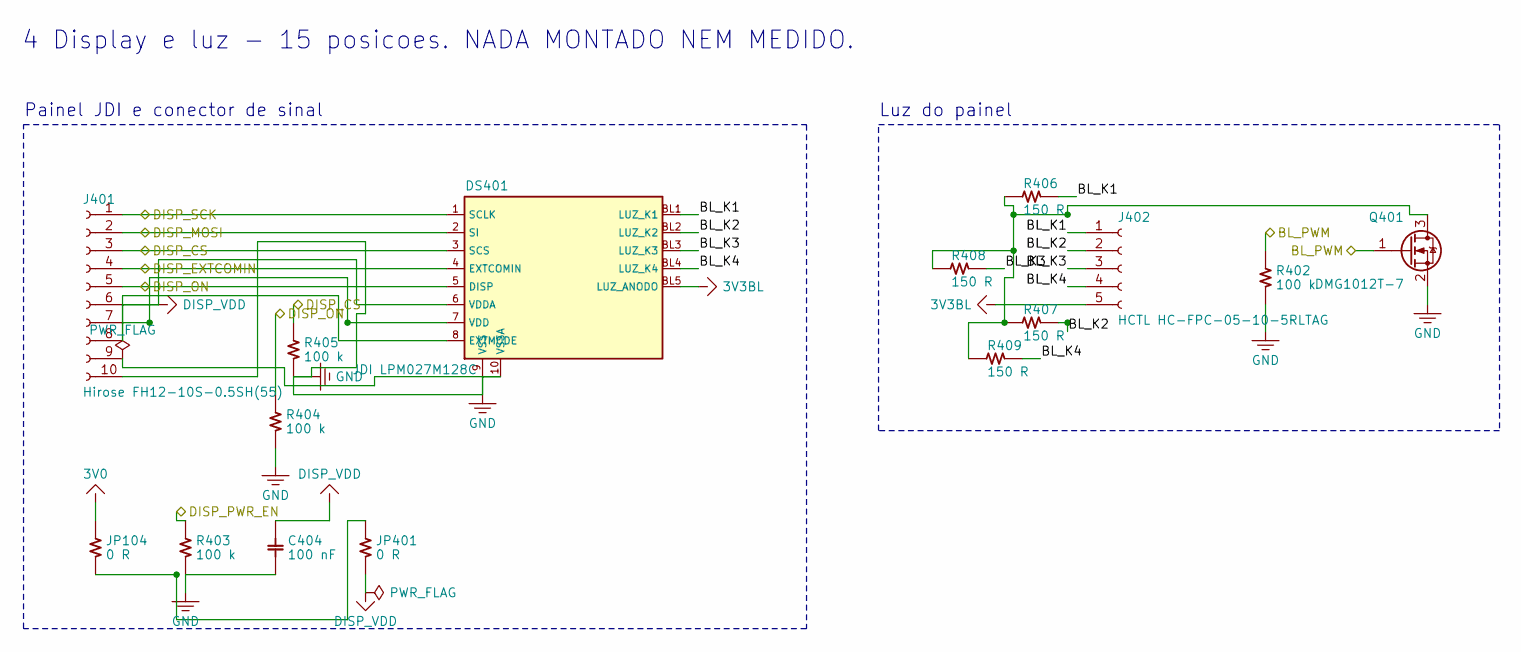
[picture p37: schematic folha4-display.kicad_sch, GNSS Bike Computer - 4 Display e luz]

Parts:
C404: 100 nF; C_0402_1005Metric
DS401: JDI LPM027M128C
J401: Hirose FH12-10S-0.5SH(55); Hirose_FH12-10S-0.5SH_1x10-1MP_P0.50mm_Horizontal
J402: HCTL HC-FPC-05-10-5RLTAG; HC-FPC-05-10-5RLTAG
JP104, JP401: 0 R; R_0402_1005Metric
Q401: DMG1012T-7; SOT-523
R402, R403, R404, R405: 100 k; R_0402_1005Metric
R406, R407, R408, R409: 150 R; R_0402_1005Metric

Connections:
3V0: JP104.1; also elsewhere on the board
3V3BL: DS401.BL5 (LUZ_ANODO), J402.5; also elsewhere on the board
BL_CATODO: Q401.3 (D), R406.2, R407.2, R408.2, R409.2
BL_K1: DS401.BL1 (LUZ_K1), J402.1, R406.1
BL_K2: DS401.BL2 (LUZ_K2), J402.2, R407.1
BL_K3: DS401.BL3 (LUZ_K3), J402.3, R408.1
BL_K4: DS401.BL4 (LUZ_K4), J402.4, R409.1
BL_PWM: Q401.1 (G), R402.1; also elsewhere on the board
DISP_CS: DS401.3 (SCS), J401.3, R405.1; also elsewhere on the board
DISP_EXTCOMIN: DS401.4 (EXTCOMIN), J401.4; also elsewhere on the board
DISP_MOSI: DS401.2 (SI), J401.2; also elsewhere on the board
DISP_ON: DS401.5 (DISP), J401.5, R404.1; also elsewhere on the board
DISP_PWR_EN: R403.1; also elsewhere on the board
DISP_SCK: DS401.1 (SCLK), J401.1; also elsewhere on the board
DISP_VDD: C404.1, DS401.6 (VDDA), DS401.7 (VDD), DS401.8 (EXTMODE), J401.6, J401.7, J401.8, JP401.2
DISP_VDD_SEL: JP104.2, JP401.1
GND: C404.2, DS401.9 (VSS), DS401.10 (VSSA), J401.9, J401.10, Q401.2 (S), R402.2, R403.2, R404.2, R405.2; also elsewhere on the board

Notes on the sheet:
Painel JDI e conector de sinal
Luz do painel
4 Display e luz - 15 posicoes. NADA MONTADO NEM MEDIDO.

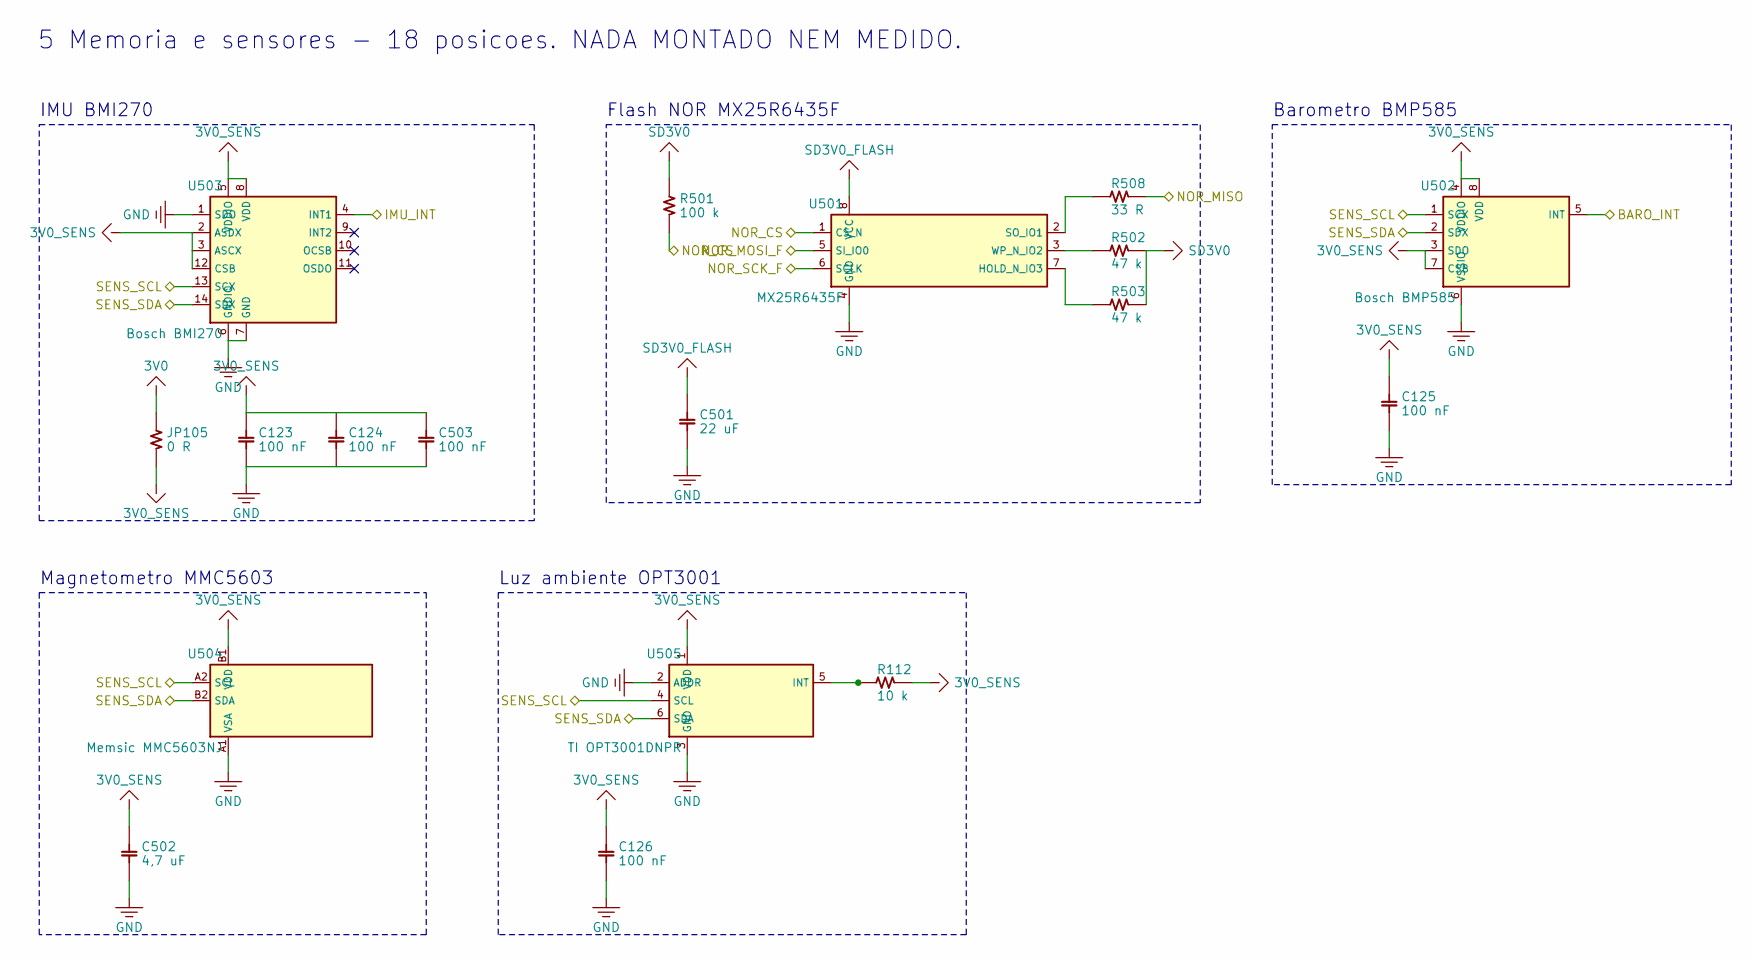
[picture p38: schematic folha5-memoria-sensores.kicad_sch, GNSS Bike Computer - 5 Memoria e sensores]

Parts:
C123, C124, C125, C126: 100 nF; C_0603_1608Metric
C501: 22 uF; C_0603_1608Metric
C502: 4,7 uF; C_0603_1608Metric
C503: 100 nF; C_0402_1005Metric
JP105: 0 R; R_0402_1005Metric
R112: 10 k; R_0402_1005Metric
R501: 100 k; R_0402_1005Metric
R502, R503: 47 k; R_0402_1005Metric
R508: 33 R; R_0402_1005Metric
U501: MX25R6435F; SOIC-8_5.275x5.275mm_P1.27mm
U502: Bosch BMP585; BMP585_LGA-8_3.25x3.25mm
U503: Bosch BMI270; Bosch_LGA-14_3x2.5mm_P0.5mm
U504: Memsic MMC5603NJ; MMC5603_WLP-4_0.82x0.82mm
U505: TI OPT3001DNPR; OPT3001_USON-6_2x2mm_P0.65mm

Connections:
3V0: JP105.1; also elsewhere on the board
3V0_SENS: C123.1, C124.1, C125.1, C126.1, C502.1, C503.1, JP105.2, R112.1, U502.3 (SDO), U502.4 (VDDIO), U502.7 (CSB), U502.8 (VDD), U503.2 (ASDX), U503.3 (ASCX), U503.5 (VDDIO), U503.8 (VDD), U503.12 (CSB), U504.B1 (VDD), U505.1 (VDD); also elsewhere on the board
BARO_INT: U502.5 (INT); also elsewhere on the board
GND: C123.2, C124.2, C125.2, C126.2, C501.2, C502.2, C503.2, U501.4 (GND), U502.6 (VSSIO), U503.1 (SDO), U503.6 (GNDIO), U503.7 (GND), U504.A1 (VSA), U505.2 (ADDR), U505.3 (GND); also elsewhere on the board
IMU_INT: U503.4 (INT1); also elsewhere on the board
INT_OPT: R112.2, U505.5 (INT)
NOR_CS: R501.2, U501.1 (CS_N); also elsewhere on the board
NOR_HOLD: R503.2, U501.7 (HOLD_N_IO3)
NOR_MISO: R508.1; also elsewhere on the board
NOR_MISO_F: R508.2, U501.2 (SO_IO1)
NOR_MOSI_F: U501.5 (SI_IO0); also elsewhere on the board
NOR_SCK_F: U501.6 (SCLK); also elsewhere on the board
NOR_WP: R502.2, U501.3 (WP_N_IO2)
SD3V0: R501.1, R502.1, R503.1; also elsewhere on the board
SD3V0_FLASH: C501.1, U501.8 (VCC); also elsewhere on the board
SENS_SCL: U502.1 (SCX), U503.13 (SCX), U504.A2 (SCL), U505.4 (SCL); also elsewhere on the board
SENS_SDA: U502.2 (SDX), U503.14 (SDX), U504.B2 (SDA), U505.6 (SDA); also elsewhere on the board

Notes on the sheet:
Flash NOR MX25R6435F
IMU BMI270
Barometro BMP585
Magnetometro MMC5603
Luz ambiente OPT3001
5 Memoria e sensores - 18 posicoes. NADA MONTADO NEM MEDIDO.

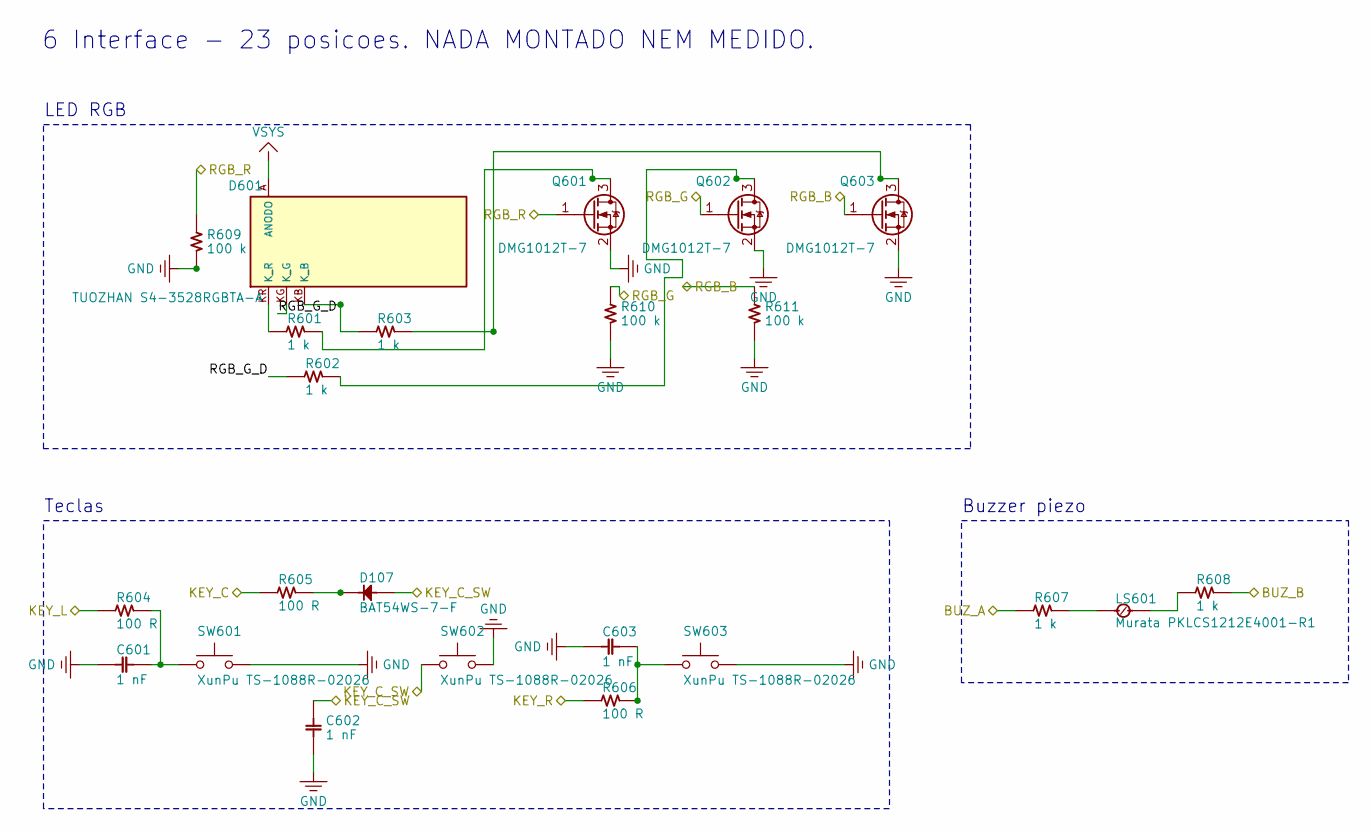
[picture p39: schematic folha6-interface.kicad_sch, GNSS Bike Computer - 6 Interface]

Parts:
C601, C602, C603: 1 nF; C_0603_1608Metric
D107: BAT54WS-7-F; D_SOD-323
D601: TUOZHAN S4-3528RGBTA-A; LED_RGB_3528_3.5x2.8mm
LS601: Murata PKLCS1212E4001-R1; Buzzer_PKLCS1212E4001_12x12mm
Q601, Q602, Q603: DMG1012T-7; SOT-523
R601, R602, R603, R607, R608: 1 k; R_0402_1005Metric
R604, R605, R606: 100 R; R_0402_1005Metric
R609, R610, R611: 100 k; R_0402_1005Metric
SW601, SW602, SW603: XunPu TS-1088R-02026; SW_TS-1088R_3.9x3mm

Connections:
BUZ_A: R607.1; also elsewhere on the board
BUZ_A_LS: LS601.1 (A), R607.2
BUZ_B: R608.1; also elsewhere on the board
BUZ_B_LS: LS601.2 (B), R608.2
GND: C601.2, C602.2, C603.2, Q601.2 (S), Q602.2 (S), Q603.2 (S), R609.2, R610.2, R611.2, SW601.2, SW602.2, SW603.2; also elsewhere on the board
KEY_C: R605.1; also elsewhere on the board
KEY_C_D: D107.2 (A), R605.2
KEY_C_SW: C602.1, D107.1 (K), SW602.1; also elsewhere on the board
KEY_L: R604.1; also elsewhere on the board
KEY_L_SW: C601.1, R604.2, SW601.1
KEY_R: R606.1; also elsewhere on the board
KEY_R_SW: C603.1, R606.2, SW603.1
RGB_B: Q603.1 (G), R611.1; also elsewhere on the board
RGB_B_D: D601.KB (K_B), R603.1
RGB_B_Q: Q603.3 (D), R603.2
RGB_G: Q602.1 (G), R610.1; also elsewhere on the board
RGB_G_D: D601.KG (K_G), R602.1
RGB_G_Q: Q602.3 (D), R602.2
RGB_R: Q601.1 (G), R609.1; also elsewhere on the board
RGB_R_D: D601.KR (K_R), R601.1
RGB_R_Q: Q601.3 (D), R601.2
VSYS: D601.A (ANODO); also elsewhere on the board

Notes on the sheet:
Teclas
LED RGB
Buzzer piezo
6 Interface - 23 posicoes. NADA MONTADO NEM MEDIDO.

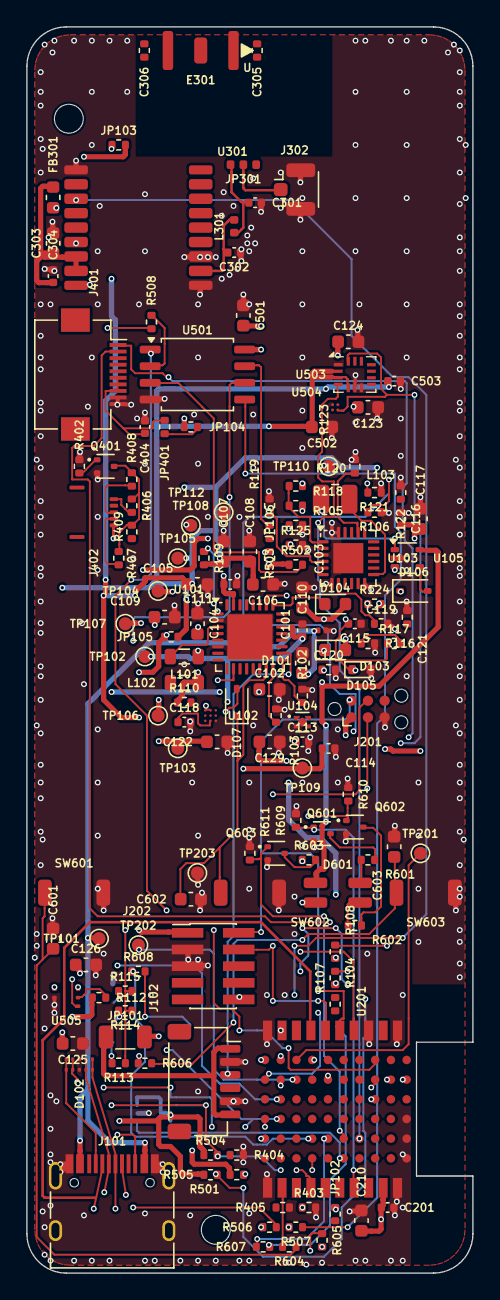
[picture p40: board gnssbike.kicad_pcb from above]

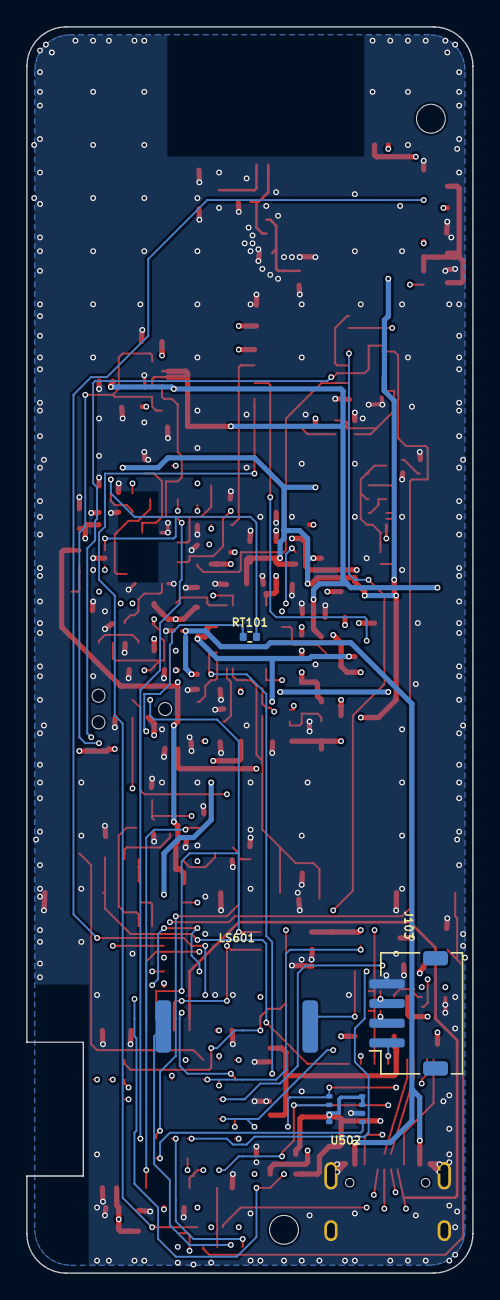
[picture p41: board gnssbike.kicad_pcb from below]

Board: 4 copper layers, 34.0 x 95.0 mm, 156 parts (4 on the bottom side), 114 nets.

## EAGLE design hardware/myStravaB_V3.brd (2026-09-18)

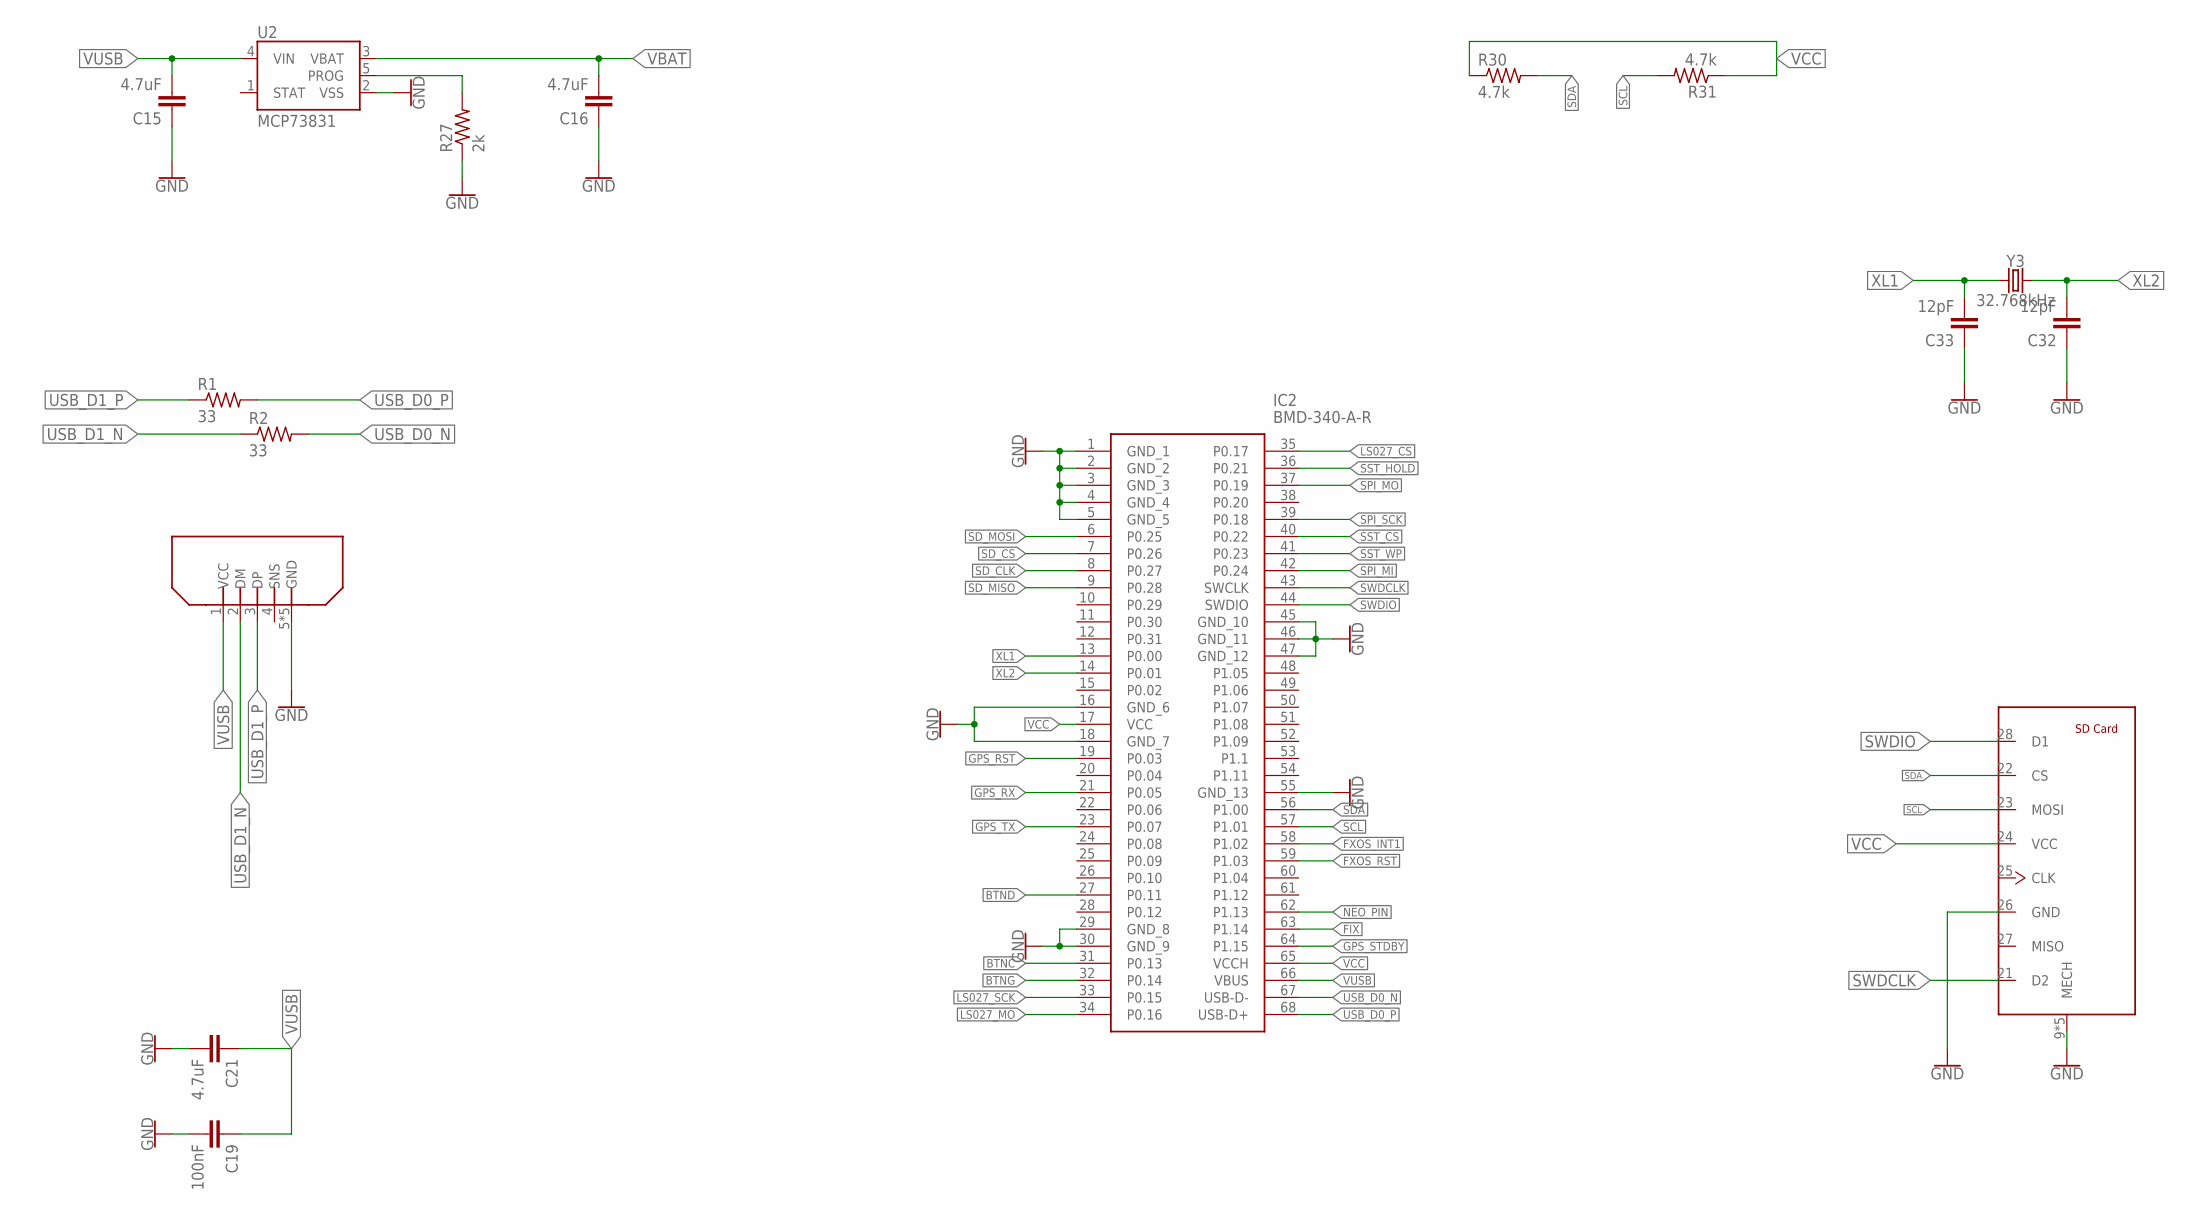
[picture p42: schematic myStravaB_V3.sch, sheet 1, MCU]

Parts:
C15, C16, C21: 4.7uF; C0805
C19: 100nF; C0603
C32, C33: 12pF; C0603
IC2: BMD-340-A-R; BMD340AR
J1: 47571-0001
R1, R2: 33; R0603
R27: 2k; R0603
R30, R31: 4.7k; R0603
U2: MCP73831; SOT23-5
U$3: ZX80B5P
Y3: 32.768kHz; CRYSTAL-SMD-3.2X1.5MM

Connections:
BTNC: IC2.31 (P0.13); also elsewhere on the board
BTND: IC2.27 (P0.11); also elsewhere on the board
BTNG: IC2.32 (P0.14); also elsewhere on the board
FIX: IC2.63 (P1.14); also elsewhere on the board
FXOS_INT1: IC2.58 (P1.02); also elsewhere on the board
FXOS_RST: IC2.59 (P1.03); also elsewhere on the board
GND: C15.1, C16.1, C19.2, C21.2, C32.1, C33.1, IC2.1 (GND_1), IC2.2 (GND_2), IC2.3 (GND_3), IC2.4 (GND_4), IC2.5 (GND_5), IC2.16 (GND_6), IC2.18 (GND_7), IC2.29 (GND_8), IC2.30 (GND_9), IC2.45 (GND_10), IC2.46 (GND_11), IC2.47 (GND_12), IC2.55 (GND_13), J1.9 (MECH), J1.10 (MECH), J1.11 (MECH), J1.12 (MECH), J1.13 (MECH), J1.26 (GND), R27.1, U2.2 (VSS), U$3.5 (GND), U$3.GND1 (GND), U$3.GND2 (GND), U$3.GND3 (GND), U$3.GND4 (GND); also elsewhere on the board
GPS_RST: IC2.19 (P0.03); also elsewhere on the board
GPS_RX: IC2.21 (P0.05); also elsewhere on the board
GPS_STDBY: IC2.64 (P1.15); also elsewhere on the board
GPS_TX: IC2.23 (P0.07); also elsewhere on the board
LS027_CS: IC2.35 (P0.17); also elsewhere on the board
LS027_MO: IC2.34 (P0.16); also elsewhere on the board
LS027_SCK: IC2.33 (P0.15); also elsewhere on the board
unnamed: R27.2, U2.5 (PROG)
NEO_PIN: IC2.62 (P1.13); also elsewhere on the board
SCL: IC2.57 (P1.01), J1.23 (MOSI), R31.2; also elsewhere on the board
SDA: IC2.56 (P1.00), J1.22 (CS), R30.2; also elsewhere on the board
SD_CLK: IC2.8 (P0.27); also elsewhere on the board
SD_CS: IC2.7 (P0.26); also elsewhere on the board
SD_MISO: IC2.9 (P0.28); also elsewhere on the board
SD_MOSI: IC2.6 (P0.25); also elsewhere on the board
SPI_MI: IC2.42 (P0.24); also elsewhere on the board
SPI_MO: IC2.37 (P0.19); also elsewhere on the board
SPI_SCK: IC2.39 (P0.18); also elsewhere on the board
SST_CS: IC2.40 (P0.22); also elsewhere on the board
SST_HOLD: IC2.36 (P0.21); also elsewhere on the board
SST_WP: IC2.41 (P0.23); also elsewhere on the board
SWDCLK: IC2.43 (SWCLK), J1.21 (D2)
SWDIO: IC2.44 (SWDIO), J1.28 (D1)
USB_D0_N: IC2.67 (USB-D-), R2.2
USB_D0_P: IC2.68 (USB-D+), R1.2
USB_D1_N: R2.1, U$3.2 (DM)
USB_D1_P: R1.1, U$3.3 (DP)
VBAT: C16.2, U2.3 (VBAT); also elsewhere on the board
VCC: IC2.17 (VCC), IC2.65 (VCCH), J1.24 (VCC), R30.1, R31.1; also elsewhere on the board
VUSB: C15.2, C19.1, C21.1, IC2.66 (VBUS), U2.4 (VIN), U$3.1 (VCC); also elsewhere on the board
XL1: C33.2, IC2.13 (P0.00), Y3.P$1 (1)
XL2: C32.2, IC2.14 (P0.01), Y3.P$2 (2)

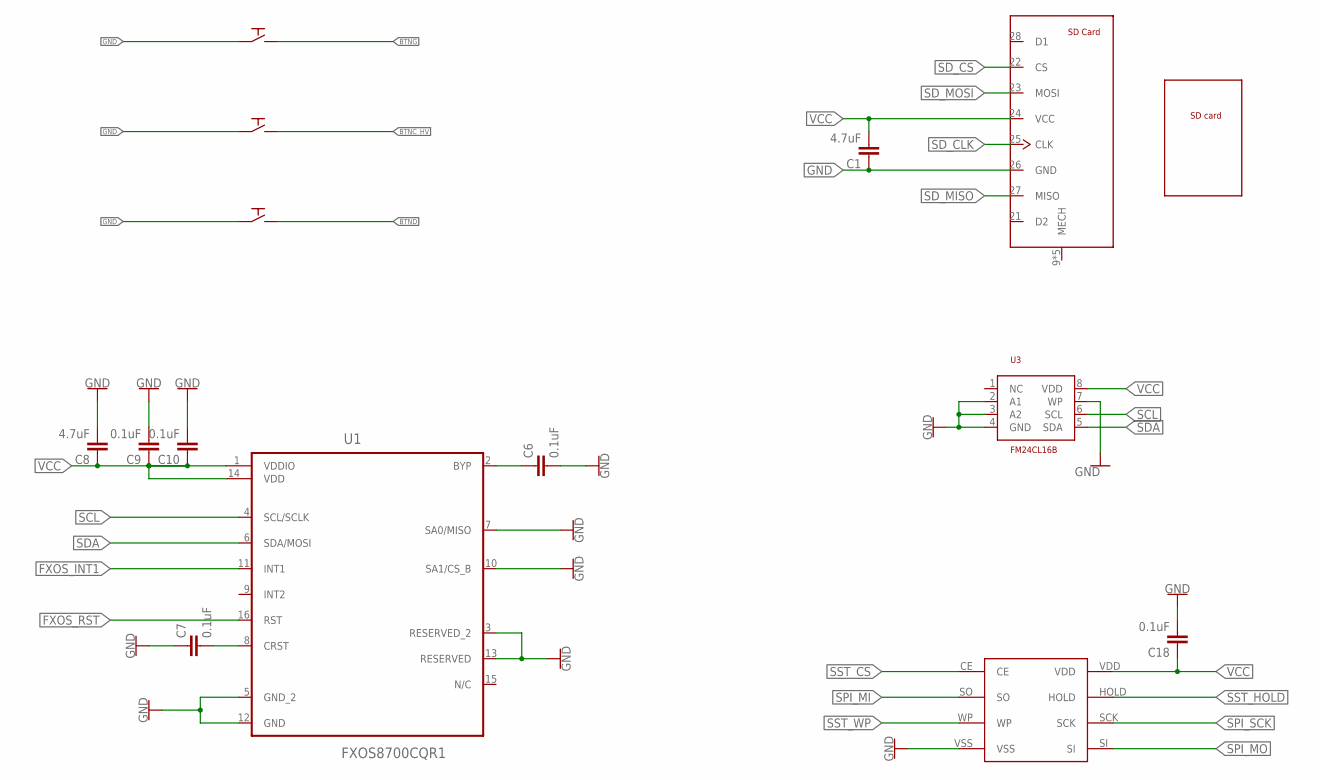
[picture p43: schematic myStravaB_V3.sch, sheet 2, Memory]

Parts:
B1: MICRO-SD_FOOTPRINT; MICRO-SD-FOOTPRINT
C1, C8: 4.7uF; 0603
C6, C7, C9, C10, C18: 0.1uF; 0603
SD: 47571-0001
SPST1, SPST2, SPST3: PTS526SK08; PTS526SKG15SMTR2LFS
U1: FXOS8700CQR1; QFN50P300X300X120-16N
U3: FM24CL16B; SOIC127P600X175-8N
U$2: FLASH; SOIC8

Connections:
BTNC_HV: SPST2.3, SPST2.4; also elsewhere on the board
BTND: SPST3.3, SPST3.4; also elsewhere on the board
BTNG: SPST1.3, SPST1.4; also elsewhere on the board
BYP: C6.1, U1.2 (BYP)
CRST: C7.2, U1.8 (CRST)
FXOS_INT1: U1.11 (INT1); also elsewhere on the board
FXOS_RST: U1.16 (RST); also elsewhere on the board
GND: C1.1, C6.2, C7.1, C8.2, C9.2, C10.2, C18.2, SD.26 (GND), SPST1.1, SPST1.2, SPST2.1, SPST2.2, SPST3.1, SPST3.2, U1.3 (RESERVED_2), U1.5 (GND_2), U1.7 (SA0/MISO), U1.10 (SA1/CS_B), U1.12 (GND), U1.13 (RESERVED), U3.2 (A1), U3.3 (A2), U3.4 (GND), U3.7 (WP), U$2.VSS; also elsewhere on the board
SCL: U1.4 (SCL/SCLK), U3.6 (SCL); also elsewhere on the board
SDA: U1.6 (SDA/MOSI), U3.5 (SDA); also elsewhere on the board
SD_CLK: SD.25 (CLK); also elsewhere on the board
SD_CS: SD.22 (CS); also elsewhere on the board
SD_MISO: SD.27 (MISO); also elsewhere on the board
SD_MOSI: SD.23 (MOSI); also elsewhere on the board
SPI_MI: U$2.SO; also elsewhere on the board
SPI_MO: U$2.SI; also elsewhere on the board
SPI_SCK: U$2.SCK; also elsewhere on the board
SST_CS: U$2.CE; also elsewhere on the board
SST_HOLD: U$2.HOLD; also elsewhere on the board
SST_WP: U$2.WP; also elsewhere on the board
VCC: C1.2, C8.1, C9.1, C10.1, C18.1, SD.24 (VCC), U1.1 (VDDIO), U1.14 (VDD), U3.8 (VDD), U$2.VDD; also elsewhere on the board

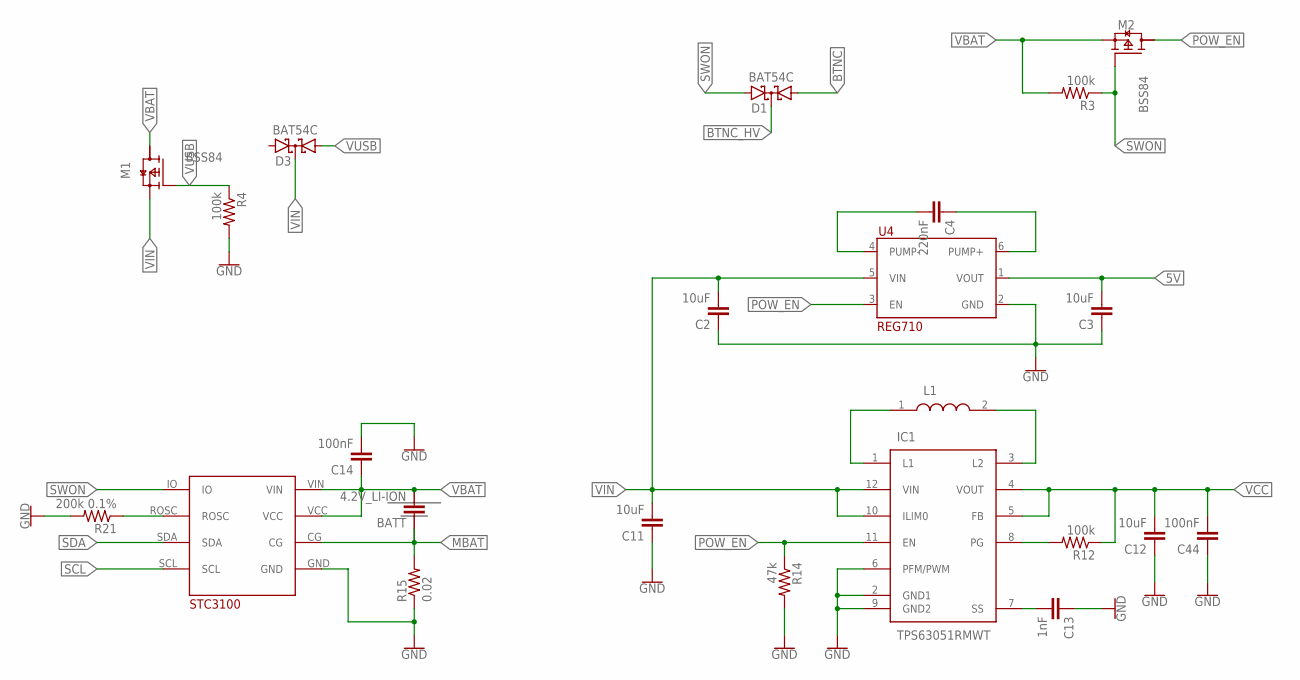
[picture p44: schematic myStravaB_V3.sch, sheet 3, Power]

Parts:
BATT: 4.2V_LI-ION; C1210
C2, C3, C11: 10uF; C0805
C4: 220nF; C0805
C12: 10uF; C0603
C13: 1nF; C0603
C14, C44: 100nF; C0603
D1, D3: BAT54C; SOT23
IC1: TPS63051RMWT; QFN50P250X250X100-12N
L1: 1269AS-H-1R5M=P2; INDC2520X110N
M1, M2: BSS84; SOT65P210X110-3N
R3, R4, R12: 100k; R0603
R14: 47k; R0603
R15: 0.02; R0603
R21: 200k 0.1%; R0603
U4: REG710; SOT457
U$6: STC3100

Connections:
5V: C3.2, U4.1 (VOUT); also elsewhere on the board
BTNC: D1.1 (A1); also elsewhere on the board
BTNC_HV: D1.3 (CC); also elsewhere on the board
GND: C2.1, C3.1, C11.1, C12.1, C13.1, C14.2, C44.1, IC1.2 (GND1), IC1.6 (PFM/PWM), IC1.9 (GND2), R4.2, R14.2, R15.1, R21.2, U4.2 (GND), U$6.GND; also elsewhere on the board
L1: IC1.1 (L1), L1.1
L2: IC1.3 (L2), L1.2
MBAT: BATT.1, R15.2, U$6.CG
unnamed: C4.1, U4.6 (PUMP+)
unnamed: C4.2, U4.4 (PUMP-)
PG: IC1.8 (PG), R12.2
POW_EN: IC1.11 (EN), M2.3 (D), R14.1, U4.3 (EN)
ROSC: R21.1, U$6.ROSC
SCL: U$6.SCL; also elsewhere on the board
SDA: U$6.SDA; also elsewhere on the board
SS: C13.2, IC1.7 (SS)
SWON: D1.2 (A2), M2.1 (G), R3.1, U$6.IO
VBAT: BATT.2, C14.1, M1.3 (D), M2.2 (S), R3.2, U$6.VCC, U$6.VIN; also elsewhere on the board
VCC: C12.2, C44.2, IC1.4 (VOUT), IC1.5 (FB), R12.1; also elsewhere on the board
VIN: C2.2, C11.2, D3.3 (CC), IC1.10 (ILIM0), IC1.12 (VIN), M1.2 (S), U4.5 (VIN)
VUSB: D3.1 (A1), M1.1 (G), R4.1; also elsewhere on the board


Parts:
C36: 100nF; C0603
C37: 4.7uF; C0603
C40, C41: C-EUC0603; C0603
U$4: SR4G008
U$5: M10578-A3; M10578

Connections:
ANT: U$4.P$2 (FEED), U$5.P$3 (RF_IN)
FIX: U$5.P$13 (FIX); also elsewhere on the board
GND: C36.1, C37.1, C40.2, C41.2, U$4.P$3 (GND), U$4.P$4 (GND), U$4.P$6 (GND), U$5.P$1 (GND1), U$5.P$2 (GND2), U$5.P$4 (GND3), U$5.P$5 (GND4), U$5.P$16 (GND6); also elsewhere on the board
GPS_RST: C41.1, U$5.P$7 (HW_R); also elsewhere on the board
GPS_RX: U$5.P$9 (RX); also elsewhere on the board
GPS_STDBY: C40.1, U$5.P$8 (HW_S); also elsewhere on the board
GPS_TX: U$5.P$10 (TX); also elsewhere on the board
PPS: U$5.P$6 (PPS)
VBAT: U$5.P$14 (BV); also elsewhere on the board
VCC: C36.2, C37.2, U$5.P$15 (VCC); also elsewhere on the board


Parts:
C17, C43: 0.1uF; 0603
IC3: BME280
L4: WS2812B
Q2: BSS138BKW; SOT65P210X110-3N
R13, R16, R17: 10k; 0603
R18, R19: 47k; 0603
U$15: SHARP27_FOOTPRINT; LCD27
U$16: SHARP27

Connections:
5V: L4.1-VDD (VDD), R18.2, U$16.6 (VDDA), U$16.7 (VDD); also elsewhere on the board
DISP1: C43.2, R17.2, U$16.5 (DISP)
EXTCOMM1: R16.2, U$16.4 (EXTCOMM)
EXTMODE1: R13.1, U$16.8 (EXTMODE)
GND: C17.2, C43.1, IC3.1 (GND), IC3.5 (SDO), IC3.7 (GND), L4.3-GND (GND), R13.2, R16.1, U$16.9 (VSS), U$16.10 (VSSA); also elsewhere on the board
LS027_CS: U$16.3 (CS); also elsewhere on the board
LS027_MO: U$16.2 (MOSI); also elsewhere on the board
LS027_SCK: U$16.1 (SCLK); also elsewhere on the board
NEO_DIN: L4.4-DIN (DIN), Q2.3 (D), R18.1
NEO_PIN: Q2.2 (S), R19.1; also elsewhere on the board
SCL: IC3.4 (SCK); also elsewhere on the board
SDA: IC3.3 (SDI); also elsewhere on the board
VCC: C17.1, IC3.2 (CSB), IC3.6 (VDDIO), IC3.8 (VDD), Q2.1 (G), R17.1, R19.2; also elsewhere on the board



Board: 2 copper layers, 52.3 x 77.5 mm, 72 parts (65 on the bottom side), 59 nets.

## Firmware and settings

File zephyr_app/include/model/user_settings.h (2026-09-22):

/**
 * @file user_settings.h
 * @brief User settings storage and management
 * @note Follows MISRA C:2012 guidelines
 *
 * Manages persistent user settings stored in FRAM/NVS including:
 * - ANT+ device IDs (HRM, BSC, FEC, Glasses)
 * - User profile (FTP, Weight)
 * - Magnetometer calibration
 * - Configuration version and CRC validation
 */

#ifndef MODEL_USER_SETTINGS_H_
#define MODEL_USER_SETTINGS_H_

#include <stdint.h>
#include <stdbool.h>
#include "app_types.h"
#include "model/alerts.h"

#ifdef __cplusplus
extern "C" {
#endif

/* ==========================================================================
 * Configuration
 * ========================================================================== */

/** Settings storage address in FRAM/NVS */
#define SETTINGS_STORAGE_ADDRESS    0x0000U

/** Current settings version - increment when structure changes */
#define SETTINGS_VERSION            0x0004U

/** Default FTP value in watts */
#define DEFAULT_FTP                 240U

/** Default weight in hectograms (e.g., 750 = 75.0 kg) */
#define DEFAULT_WEIGHT              790U /* USER_WEIGHT of the legacy, 79 kg */

/** Default HRM device ID */
#define DEFAULT_HRM_DEVID           0x0D22U

/** Default BSC device ID */
#define DEFAULT_BSC_DEVID           0U

/** Default FEC device ID */
#define DEFAULT_FEC_DEVID           2846U

/** Default Glasses device ID */
#define DEFAULT_GLA_DEVID           0U

/** Magnetometer calibration present marker */
#define MAG_CAL_PRESENT_ID          0xCAFEU

/* ==========================================================================
 * Type Definitions
 * ========================================================================== */

/**
 * @brief Magnetometer calibration data
 */
typedef struct {
    int16_t calib[3];       /**< X, Y, Z offset values */
    uint16_t is_present;    /**< Set to MAG_CAL_PRESENT_ID if valid */
} mag_cal_t;

/**
 * @brief User parameters structure
 * @note Union allows byte-level access for CRC calculation
 */
typedef union {
    struct {
        uint16_t hrm_devid;     /**< Heart Rate Monitor device ID */
        uint16_t bsc_devid;     /**< Bike Speed/Cadence device ID */
        uint16_t gla_devid;     /**< Glasses device ID */
        uint16_t fec_devid;     /**< FE-C (trainer) device ID */
        uint16_t ftp;           /**< Functional Threshold Power (watts) */
        uint16_t weight;        /**< Weight in hectograms */
        uint16_t version;       /**< Settings version number */
        /**
         * The alerts the rider set (`model/alerts.h`), one value each in
         * the unit of its alert; **zero means the alert is off**, which is
         * why no separate flag is stored. Added in version 4, and the
         * version check is what throws away a block saved by an earlier
         * one rather than reading these bytes as whatever was there.
         */
        uint16_t alerts[ALERT_COUNT];
        mag_cal_t mag_cal;      /**< Magnetometer calibration */
        uint16_t crc;           /**< CRC-8 checksum (stored as uint16 for alignment) */
    };
    uint8_t flat_params[1];     /**< Byte access for CRC calculation */
} user_params_t;

/**
 * @brief User settings manager context
 */
typedef struct {
    user_params_t params;       /**< Current parameters */
    bool is_loaded;             /**< True if params loaded from storage */
    bool is_dirty;              /**< True if params modified but not saved */
} user_settings_t;

/* ==========================================================================
 * Public Functions
 * ========================================================================== */

/**
 * @brief Initialize user settings manager
 * @param settings Pointer to settings structure
 * @return APP_OK on success, error code otherwise
 */
app_err_t user_settings_init(user_settings_t *settings);

/**
 * @brief Load settings from persistent storage
 * @param settings Pointer to settings structure
 * @return APP_OK on success, APP_ERR_CHECKSUM if CRC invalid
 */
app_err_t user_settings_load(user_settings_t *settings);

/**
 * @brief Save settings to persistent storage
 * @param settings Pointer to settings structure
 * @return APP_OK on success, error code otherwise
 */
app_err_t user_settings_save(user_settings_t *settings);

/**
 * @brief Check if settings are valid (version and CRC)
 * @param settings Pointer to settings structure
 * @return true if valid, false otherwise
 */
bool user_settings_is_valid(const user_settings_t *settings);

/**
 * @brief Reset settings to factory defaults
 * @param settings Pointer to settings structure
 * @return APP_OK on success
 */
app_err_t user_settings_reset(user_settings_t *settings);

/**
 * @brief Ensure valid settings (load or reset if invalid)
 * @param settings Pointer to settings structure
 * @return APP_OK on success
 */
app_err_t user_settings_enforce(user_settings_t *settings);

/**
 * @brief Get HRM device ID
 * @param settings Pointer to settings structure
 * @return Device ID or 0 if settings NULL
 */
uint16_t user_settings_get_hrm_devid(const user_settings_t *settings);

/**
 * @brief Set HRM device ID
 * @param settings Pointer to settings structure
 * @param devid New device ID
 */
void user_settings_set_hrm_devid(user_settings_t *settings, uint16_t devid);

/**
 * @brief Get BSC device ID
 * @param settings Pointer to settings structure
 * @return Device ID or 0 if settings NULL
 */
uint16_t user_settings_get_bsc_devid(const user_settings_t *settings);

/**
 * @brief Set BSC device ID
 * @param settings Pointer to settings structure
 * @param devid New device ID
 */
void user_settings_set_bsc_devid(user_settings_t *settings, uint16_t devid);

/**
 * @brief Get FEC device ID
 * @param settings Pointer to settings structure
 * @return Device ID or 0 if settings NULL
 */
uint16_t user_settings_get_fec_devid(const user_settings_t *settings);

/**
 * @brief Set FEC device ID
 * @param settings Pointer to settings structure
 * @param devid New device ID
 */
void user_settings_set_fec_devid(user_settings_t *settings, uint16_t devid);

/**
 * @brief Get FTP value
 * @param settings Pointer to settings structure
 * @return FTP in watts or 0 if settings NULL
 */
uint16_t user_settings_get_ftp(const user_settings_t *settings);

/**
 * @brief The value of one alert, 0 when the rider turned it off
 * @param id enum alert_id
 */
uint16_t user_settings_get_alert(const user_settings_t *settings, uint8_t id);

/**
 * @brief Set one alert; 0 turns it off
 * @param id enum alert_id
 */
void user_settings_set_alert(user_settings_t *settings, uint8_t id, uint16_t value);

/**
 * @brief Set FTP value
 * @param settings Pointer to settings structure
 * @param ftp New FTP value in watts
 */
void user_settings_set_ftp(user_settings_t *settings, uint16_t ftp);

/**
 * @brief Get weight value
 * @param settings Pointer to settings structure
 * @return Weight in hectograms or 0 if settings NULL
 */
uint16_t user_settings_get_weight(const user_settings_t *settings);

/**
 * @brief Set weight value
 * @param settings Pointer to settings structure
 * @param weight New weight in hectograms
 */
void user_settings_set_weight(user_settings_t *settings, uint16_t weight);

/**
 * @brief Get magnetometer calibration
 * @param settings Pointer to settings structure
 * @return Pointer to mag_cal structure or NULL
 */
const mag_cal_t *user_settings_get_mag_cal(const user_settings_t *settings);

/**
 * @brief Set magnetometer calibration
 * @param settings Pointer to settings structure
 * @param cal Pointer to calibration data
 */
void user_settings_set_mag_cal(user_settings_t *settings, const mag_cal_t *cal);

/**
 * @brief Check if magnetometer is calibrated
 * @param settings Pointer to settings structure
 * @return true if calibration data is present
 */
bool user_settings_is_mag_calibrated(const user_settings_t *settings);

/**
 * @brief Get global user settings instance
 * @return Pointer to global settings
 */
user_settings_t *user_settings_get_global(void);

#ifdef __cplusplus
}
#endif

#endif /* MODEL_USER_SETTINGS_H_ */

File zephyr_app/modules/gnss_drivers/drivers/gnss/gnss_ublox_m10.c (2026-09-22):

/**
 * @file gnss_ublox_m10.c
 * @brief u-blox M10 and F10 receivers on a UART, by UBX
 *
 * The Zephyr of the NCS v3.3.0 has drivers for the u-blox M8 and F9P, not for
 * the M10: the M8 configures with the legacy UBX-CFG messages, which the M10
 * does not accept, and the F9P is an RTK receiver with buffers and messages
 * that this board does not need. This driver uses the UBX layer of Zephyr
 * (modem_ubx over a UART pipe) with the frames of ubx_m10.c, which the host
 * tests check against the u-blox documents.
 *
 * The board takes two parts in the same footprint, and the driver serves
 * both: the single-band MAX-M10N-10B ("u-blox,max-m10") and the dual-band
 * MAX-F10S ("u-blox,max-f10"), which is what the new board carries.
 *
 * | What | Where |
 * |---|---|
 * | Configuration by UBX-CFG-VALSET in the RAM and BBR layers | interface description 3.10.5, 5.3 |
 * | LEAP by CFG-PM-OPERATEMODE = 2, 1 Hz, without time pulse | integration manual 3.7.2 |
 * | Software standby by UBX-RXM-PMREQ, waking on the UART RX | integration manual 3.7.4.2 |
 * | One UBX-NAV-PVT per epoch, UBX-NAV-SAT for the sky plot | interface description 3.15.11, 3.15.13 |
 * | L1 and L5 together, NavIC, and no CFG-PM at all | F10 SPG 6.00 UBX-23002975 R02, 4.9.20 |
 *
 * The receiver may miss a message while it duty cycles in LEAP (integration
 * manual 3.7.2): every configuration goes out with retries, and the driver
 * takes the receiver to full power before a batch of them. On the F10 there
 * is no LEAP to leave: the part tracks at full power and the energy comes
 * back from the standby, which the GNSS service drives.
 */

#define DT_DRV_COMPAT u_blox_max_m10

#include "drivers/gnss/ublox_m10.h"
#include "drivers/gnss/ubx_m10.h"

#include <zephyr/drivers/gnss.h>
#include <zephyr/drivers/gnss/gnss_publish.h>
#include <zephyr/drivers/gpio.h>
#include <zephyr/drivers/regulator.h>
#include <zephyr/kernel.h>
#include <zephyr/logging/log.h>
#include <zephyr/modem/backend/uart.h>
#include <zephyr/modem/pipe.h>
#include <zephyr/modem/ubx.h>

LOG_MODULE_REGISTER(ublox_m10, CONFIG_GNSS_LOG_LEVEL);

/* A UBX-NAV-SAT with 32 satellites takes 8 + 32 x 12 + 8 = 400 bytes */
#define M10_RX_BUF_SIZE     512
#define M10_TX_BUF_SIZE     128
/* The largest request is the signal batch of the F10: seven keys of one byte
 * in one UBX-CFG-VALSET, 47 bytes. ubx_m10_valset_many() refuses to build a
 * frame that does not fit, so a batch that grows past this fails loudly. */
#define M10_REQ_BUF_SIZE    96
#define M10_RSP_BUF_SIZE    128

/* modem_ubx splits the timeout across the attempts: 4 x 250 ms here */
#define M10_SCRIPT_TIMEOUT  K_SECONDS(1)
#define M10_SCRIPT_RETRIES  3
#define M10_LOCK_TIMEOUT    K_SECONDS(2)
/** Not measured on the board: time for the receiver to boot after a wake-up */
#define M10_WAKEUP_MS       100
/** RESET_N is active low for at least 1 ms (integration manual, 4.2) */
#define M10_RESET_LOW_MS    2
/**
 * A change in the CFG-SIGNAL group resets the GNSS subsystem: "wait first for
 * the acknowledgement from the receiver and then 0.5 seconds before sending
 * the next command" (F10 SPG 6.00 interface description, 4.9.20).
 */
#define M10_SIGNAL_RESET_MS 500

struct m10_config {
    const struct device *uart;
    const struct gpio_dt_spec reset;
    const struct device *vcc;
    gnss_systems_t systems;     /**< what the part can receive */
    uint16_t fix_rate_ms;
    uint8_t dyn_model;
    uint8_t power_mode;
    uint8_t sat_rate;
    bool timepulse;
    bool dual_band;             /**< F10: L1 and L5 together, and no CFG-PM */
    bool navic;
};

struct m10_data {
    const struct device *dev;
    struct {
        struct modem_pipe *pipe;
        struct modem_backend_uart uart_backend;
        uint8_t receive_buf[M10_RX_BUF_SIZE];
        uint8_t transmit_buf[M10_TX_BUF_SIZE];
    } backend;
    struct {
        struct modem_ubx inst;
        uint8_t receive_buf[M10_RX_BUF_SIZE];
    } ubx;
    struct {
        struct modem_ubx_script inst;
        uint8_t request_buf[M10_REQ_BUF_SIZE];
        uint8_t response_buf[M10_RSP_BUF_SIZE];
        struct k_sem lock;
    } script;
    uint8_t power_mode;     /**< enum ublox_m10_power_mode, what was applied */
    uint8_t psm_state;      /**< psmState of the last epoch */
    bool standby;
#if defined(CONFIG_GNSS_SATELLITES)
    struct gnss_satellite satellites[CONFIG_GNSS_UBLOX_M10_SATELLITES];
    struct ubx_m10_sat parsed[CONFIG_GNSS_UBLOX_M10_SATELLITES];
#endif
};

/* Messages that arrive on their own */

static void pvt_handler(struct modem_ubx *ubx, const struct ubx_frame *frame, size_t len,
                        void *user_data)
{
    ARG_UNUSED(ubx);

    struct m10_data *data = user_data;
    struct ubx_m10_pvt pvt;

    if (len < UBX_M10_FRAME_LEN(UBX_M10_NAV_PVT_LEN)) {
        return;
    }
    if (!ubx_m10_parse_pvt(frame->payload_and_checksum, len - UBX_M10_OVERHEAD, &pvt)) {
        return;
    }

    data->psm_state = pvt.psm_state;

    struct gnss_data out = {0};

    if (pvt.fix_ok && !pvt.llh_invalid) {
        switch (pvt.fix_type) {
        case UBX_M10_FIX_2D:
        case UBX_M10_FIX_3D:
            out.info.fix_status = GNSS_FIX_STATUS_GNSS_FIX;
            out.info.fix_quality = GNSS_FIX_QUALITY_GNSS_SPS;
            break;
        case UBX_M10_FIX_DEAD_RECKONING:
        case UBX_M10_FIX_GNSS_DR:
            out.info.fix_status = GNSS_FIX_STATUS_ESTIMATED_FIX;
            out.info.fix_quality = GNSS_FIX_QUALITY_ESTIMATED;
            break;
        default:
            break;
        }
    }

    /* the receiver gives pDOP; the horizontal alone would need UBX-NAV-DOP */
    out.info.satellites_cnt = pvt.num_sv;
    out.info.hdop = (uint32_t)pvt.pdop_e2 * 10U;
    out.info.geoid_separation = pvt.height_mm - pvt.hmsl_mm;

    int32_t bearing = pvt.head_motion_e5 / 100; /* 1e-5 degree to millidegree */

    if (bearing < 0) {
        bearing += 360000;
    }
    out.nav_data.latitude = (int64_t)pvt.lat_e7 * 100;   /* 1e-7 degree to nanodegree */
    out.nav_data.longitude = (int64_t)pvt.lon_e7 * 100;
    out.nav_data.bearing = (uint32_t)bearing;
    out.nav_data.speed = (pvt.ground_speed_mms > 0) ? (uint32_t)pvt.ground_speed_mms : 0U;
    out.nav_data.altitude = pvt.hmsl_mm;

    if (pvt.date_valid && pvt.time_valid) {
        int32_t ms = ((int32_t)pvt.second * 1000) + (pvt.nano / 1000000);

        if (ms < 0) {
            ms = 0;
        } else if (ms > 60999) {
            ms = 60999;
        } else {
            /* inside the range of struct gnss_time */
        }
        out.utc.hour = pvt.hour;
        out.utc.minute = pvt.minute;
        out.utc.millisecond = (uint16_t)ms;
        out.utc.month_day = pvt.day;
        out.utc.month = pvt.month;
        out.utc.century_year = (uint8_t)(pvt.year % 100U);
    }

    gnss_publish_data(data->dev, &out);
}

#if defined(CONFIG_GNSS_SATELLITES)
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

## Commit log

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2026-09-19 feat(vue): run the LVGL screens on the memory-in-pixel display
    Add a display driver of our own as a Zephyr module inside the
    application (zephyr_app/modules/gnss_drivers): JDI LPM027M128B/C in
    3 bits and Sharp LS027B7DH01 in 1 bit, in portrait as the legacy
    setRotation(3), RGB565 quantised by the same header the host renderer
    uses, the frame kept in wire format so that runs of changed lines go
    out in one SPI transfer at the end of each LVGL frame, the COM inverted
    by the EXTCOMIN pin from a kernel timer or by the serial VCOM bit (V3),
    and the power sequences of the datasheets.
    The ui thread now owns LVGL: model snapshots, notifications, mode,
    keys, the USB and shutdown screens with the prog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
    [memlcd.c]
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2026-09-19 feat(drivers): read the MAX17262 fuel gauge and act on a low battery
    Add a MAX17262 driver of our own to zephyr_app/modules/gnss_drivers
    (compatible adi,max17262) on the Zephyr fuel gauge API. After each
    power-on reset of the gauge it writes the ModelGauge m5 EZ
    configuration (DesignCap, IChgTerm, VEmpty, ModelCfg, and ETHRM off
    when TH is tied to BATT), and it reads in the units of the datasheet
    (Table 2: 0.5 mAh, 156.25 uA, 78.125 uV, 5.625 s), kept in a plain
    header with host tests. The driver of the Zephyr tree
    (maxim,max17262) writes the capacity and the termination current
    without those steps, returns capacities off by two and never sees an
    unknown time to empty.
    The power service rea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
    [max17262.c]
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2026-09-19 feat(drivers): charge from the panel with the AEM10900
    Add an AEM10900 driver of our own to zephyr_app/modules/gnss_drivers
    (compatible e-peas,aem10900, with the e-peas vendor prefix in the
    module's list) on the Zephyr charger API. At start it checks the part
    number and takes over from the configuration pins by I2C, to charge up
    to 4.05 V with the board on (the pins charge to 3.90 V); only the
    thresholds and the average power monitor are written, since the
    register reset values equal the pins of the board for the rest. An
    AEM that resets comes back on its pins, and the driver writes its
    configuration again when it sees CTRL.UPDATE cleared.
    The power service reads every 10 s whether the pane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
    [aem10900.c]
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2026-09-20 fix(model): estimate power with the formula of the legacy
    The port had its own physics model (rolling 0.005, CdA 0.15, rider plus a
    10 kg bike, default 75 kg) and gave 88 W at 30 km/h on the flat against the
    147 W of the legacy. The formula of Attitude::computePower
    (legacy/source/model/Attitude.cpp:556-575) now lives in its own module:
    P = 1.025 x [9.81 x W x vit_asc + 0.004 x 9.81 x W x v + 0.204 x v^3]
    with W the rider alone, whose default goes back to the 79 kg of
    USER_WEIGHT, and vit_asc from the altitude filter. Power may be negative
    going downhill, as the int16_t of SAtt.pwr, and saturates instead of
    wrapping; the field and the ones that carry it (log point, ride screen, SD
    entr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
    [user_settings.h]
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2026-09-24 fix(hardware): fail the schematic check when a pin sits in two nets
    A pin in two nets is a short, and the check merged the two nets instead of
    complaining: U103's SDA was in both PWR_SDA and the 3V0 rail, which tied the
    whole power bus to 3.0 V and shorted out R107, and the merge hid it. Now any
    pin in two nets fails, except for the connectors declared in PASSA_DIRETO,
    where a connector and the part behind it really are one node drawn as two.
    Three more things the check then caught, all in the energy sheet:
    - the AEM10900's inductor had one end on a net of its own going nowhere.
    It boosts 1.67 V to 3.9 V, so the far end belongs on SRC; the open item
    now says to confirm it against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
    [folha1-energia.kicad_sch, folha5-memoria-sensores.kicad_sch]
2026-09-24 fix(hardware): place the board by the rules the datasheets actually give
    Five defects that no design rule check can catch, because none of them is
    about copper.
    The USB-C receptacle faced INTO the board. Its footprint puts the body on
    the far side of the pads, so at 180 degrees the opening pointed inward and
    the cable had nowhere to go; the battery connector had the same problem at
    90. Both are fixed, and orientacao.py now MEASURES which way each part that
    leaves the case is facing, from the geometry of its own footprint, so it
    cannot go wrong quietly again.
    The ME54BS13 asks for 20 mm between its antenna and any switching converter
    or inductor (V1.0.0, 7.3). That forbids a PART, not coppe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
    [zonas.dxf]
2026-09-24 feat(hardware): route the board without breaking a single design rule
    Half of the board is routed and it passes: 90 of the 177 signal and power
    connections, 524 segments, 250 vias, and zero DRC errors. The first version
    of this router produced copper that failed 974 rules, so what follows is
    what each of those was.
    Two grids, not one. A track is 0.15 mm wide, a via is 0.45 with a 0.25 mm
    hole, and a single grid inflated for the track put every via about 0.15 mm
    too close to its neighbours. One grid says where a track may run, the other
    where the CENTRE of a via may land.
    Pads are rectangles, with their rotation applied, and a custom pad is read
    from its primitives: the TPS7A02's anchor is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
    [gnssbike.kicad_pcb]
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2026-09-24 fix(hardware): the antenna rules are the ones the datasheet really writes
    This file carried a rule that does not exist. It said "20 mm between the
    module's antenna and any switching converter or inductor, datasheet 7.3", and
    the ME54BS13 datasheet V1.0.0 says no such thing. Reading it instead of a
    summary of it:
    7.3 no copper pour, no component and no fully enclosed metal housing over
    the antenna area, and the RF side never faces inward;
    7.4 the module at the edge or a corner, "no signal traces, metal objects,
    or other interference sources within 3-5 mm around the antenna area",
    and the PCB beneath the antenna HOLLOWED OUT so it hangs free;
    7.2 the decoupling c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
    [gnssbike.kicad_pcb, zonas.dxf]
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2026-09-24 fix(hardware): 45 degree corners, a 50 ohm line, and the stack-up that allows it
    Three things the owner was right to call out, and one of them ran deeper than
    it looked.
    The router could only move four ways, so EVERY corner it drew was a right
    angle. It now moves eight, with the guard that a diagonal step may not cut a
    corner: both orthogonal cells it passes between have to be free too. Of 755
    segments, 331 are now diagonal.
    The RF line was left unrouted with the excuse that the 50 ohm width "does not
    exist yet". It does: the stack-up is in the board file. Solving Hammerstad's
    microstrip formula for 50 ohm on the dielectric that was there, 0.22 mm, gives
    0.431 mm of track - and that is why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
    [contorno-r3.dxf, contorno-r4.dxf, gnssbike.kicad_pcb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]
2026-09-24 feat(hardware): the AEM10900's own layout rules, and two real heights
    The energy harvester's datasheet has a layout section and this board was not
    following it. Section 13 of DS-AEM1090x-v2.4.0, word for word: "PCB track
    capacitance must be reduced as much as possible on the boost converter
    switching node SWDCDC. This is done as follows: keep the connection between
    the SWDCDC pin and the inductor short; REMOVE THE GROUND AND POWER PLANES
    UNDER THE SWDCDC NODE - the polygon on the opposite external layer may also
    be removed - increase the distance between SWDCDC and the ground polygon on
    the external PCB layer where the AEM1090x is mounted." And the same for
    TH_REF.
    Every pour on this board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
    [gnssbike.kicad_pcb]
2026-09-24 fix(hardware): the solar panel and the antenna had nowhere to touch the board
    This board could not be built. The six solar modules live in the case and
    connect to SRC and GND; the GNSS antenna element lives in the case wall and
    connects to RF_ANT and GND. On the board, SRC reached only the harvester, its
    capacitor and its inductor, and RF_ANT reached only the pi network. There was
    no pad for either of them. The wires had nowhere to land.
    04-pcb-e-caixa.md had already decided how they arrive - the antenna "com
    contatos de mola" on line 271, the panels "em 3 grupos, mola ou FPC" on line
    388 - and line 661 listed as open that "a area dos pads de mola e dos
    conectores dos tres grupos de paineis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
    [folha1-energia.kicad_sch, folha3-gnss.kicad_sch, gnssbike.kicad_pcb]
2026-09-24 fix(hardware): each package built from its own datasheet's drawing
    The bodies were built from the footprint outline and a height table, and a
    land pattern is not a package: it is deliberately bigger than the part that
    sits on it. Where the height came from the part's own datasheet it said so,
    but six of them said "usual for the package" instead, which is a guess
    wearing a number.
    Six packages now carry the dimensions their own mechanical drawing gives,
    each with the document and the drawing cited beside it:
    AEM10900 QFN-28 4.00 x 4.00 x 0.80, exposed pad 2.60 x 2.60, terminal
    0.20 x 0.40, pitch 0.40 (DS-AEM1090x-v2.4.0, fig. 29)
    TPS7A02 X2SON-4 1.00 x 1.00 x 0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
    [gnssbike.kicad_pcb]
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2026-09-24 fix(hardware): draw every package from its own datasheet, and fill the pours
    The 3D view drew twenty-three parts as the same black cuboid of the
    courtyard's size. kicad-cli's GLB export reads STEP only, so the VRML
    bodies this project writes never reached it, and make_3d.py built its own
    boxes in one hard coded colour - which made the radio module, the GNSS
    receiver, the three keys, the buzzer and the USB-C receptacle five
    identical bricks in the view that exists to check that a part is the part
    you think it is. It now reads the .wrl: shape and colour both. 264
    triangles became 3588.
    With that fixed the bodies themselves are worth drawing. Three more
    packages carry the cotes of their own me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
    [gnssbike.kicad_pcb]
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2026-09-24 feat(hardware): the test points, a readable silkscreen, and paper that fits
    Eleven of the sixteen test points of 06-conectores-e-pontos-de-teste.md were
    not on the board. Only the three of the console sheet existed; a rail you
    cannot put a probe on is a rail you cannot debug. VBUS, VBUSOUT, VBAT, VSYS,
    3V0, 1V8, SD3V0, 3V3BL, VBCKP, VINT and the ground reference are there now,
    each beside the thing it measures, and each takes what is LEFT: placed with
    the rest of JUNTO they pushed three decoupling capacitors off their rings,
    one of them to 4.0 mm from a pin that wants 2. The two that are still
    missing are the document's own absences - TP111 measures ST_STO, which the
    AEM10900 datasheet does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
    [folha1-energia.kicad_sch, folha2-mcu.kicad_sch, folha3-gnss.kicad_sch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]
2026-09-24 fix(hardware): put the silkscreen where it can be read, in 2D and in 3D
    The 3D had no silkscreen at all. kicad-cli's GLB export has no option for
    it, so the view showed a green rectangle with parts on it and not one
    reference designator - in the picture whose whole job is telling you which
    part is which. The SVG export does carry it, and carries it as the simplest
    possible thing: 6484 one-segment paths, glyphs included, so no font is
    needed and nothing is approximated. Exported over the full page, the SVG's
    millimetres are the board file's own coordinates.
    Putting it in exposed a bigger error. Measured in the GLB, the substrate
    runs z 0 to 0.820 and the copper to 0.855, but this renderer us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
    [gnssbike.kicad_pcb]
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2026-09-25 feat(hardware): the four parts LCSC forced out, drawn from their drawings
    The switch, the buzzer, the RGB LED and the magnetometer all had to
    change, and each one came back from its drawing with something the
    catalogue does not say.
    SW601..603 Omron B3S-1002P -> XunPu TS-1088R-02026 (C455280). It has
    TWO terminals, not four, so the land pattern is new even though
    the schematic already treated the key as two ends. Body 3,90 x
    3,00 x 2,00 against 6,6 x 6 x 3,4, which frees half the area the
    three keys took on the edge, and 260 gf against 230 - firmer,
    which is what gloves want. But the plunger rises only 0,50 mm
    above the steel cap against th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
    [folha5-memoria-sensores.kicad_sch, folha6-interface.kicad_sch, gnssbike.kicad_pcb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]
2026-09-25 feat(hardware): the GNSS antenna comes onto the board, and the cut-out shrinks
    The TE L000670-01 is zero at LCSC, and it was never going to work here
    anyway: it asked for 40,5 x 14,5 mm with no copper on ANY layer, which is
    wider than this whole 34 mm board, and its own efficiency curve collapsed
    with a short ground plane - 62 % in L5 at 90 mm of ground, 43 % at 70,
    29 % at 50. L5 is the entire reason the MAX-F10S was chosen.
    The Unictron H2UJ4U1H2Q0100 (C6569550, 5.491 in stock) replaces it. Its
    cut-out is 15,00 x 9,35 mm on the top layer and 15,00 x 9,88 on the
    bottom, measured from the BOARD EDGE, and the part is 5,0 x 3,0 x 0,5 mm
    against 14 x 10,75 x 1.
    E301 was the only part still li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
    [folha3-gnss.kicad_sch, folha4-display.kicad_sch, gnssbike.kicad_pcb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]
2026-09-25 fix(hardware): the antenna cut-out follows the drawing, and the board says which way round
    The cut-out was 20,08 mm wide because the data sheet's 15,00 is
    asymmetric about the antenna - 2,46 mm one side, 7,54 the other - and
    which side was which had not been determined, so 7,54 went on both.
    It has now been determined, by measuring the drawings rather than by
    reading a line of text, because the data sheet never states it: the wide
    side is the side of the "U" printed on top. The "U" is off-centre by
    1,10 mm, 22 % of the part's length, and falls on the portion facing the
    wide cut-out in two independent figures - the dimension drawing and the
    evaluation board. The asymmetry is deliberate: on t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
    [gnssbike.kicad_pcb, zonas.dxf]
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2026-09-25 fix(hardware): the router measures copper to the edge, not centre lines
    The DRC found two errors on the routed board: a GND track 0,100 mm from
    the board outline and a stitching via 0,075 mm from it, against the
    0,300 mm the board setup asks for.
    The cause was in the grid, and it was a category mistake rather than a
    wrong number. BORDA_COBRE is the clearance the DRC wants between COPPER
    and the outline, but what sits on a grid point is a CENTRE LINE. A via
    of 0,45 mm centred 0,3 mm from the edge leaves copper at 0,075, and the
    router drops a via wherever it changes layer, so every grid point has to
    hold the widest thing that can land on it - the via, not the track.
    The margin is now BORDA_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
    [gnssbike.kicad_pcb]
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2026-09-25 fix(hardware): the debug connector had RESET on the wrong contact
    This one would have cost a board. The Tag-Connect TC2030 footprint had
    pin 3 as no-connect and RESET on pin 6. The manufacturer's own data
    sheet, TC2030-CTX_1.pdf, table "Connections", says the opposite: on the
    six-pin footprint it is 3 = nRESET and 6 = SWO/TDO.
    Where the mistake came from is worth writing down, because it is easy to
    make twice: 1 VCC, 2 SWDIO, 3 GND, 4 SWCLK, 5 GND, 6 SWO is the
    numbering of the ten-way Cortex header on the PROBE side, not of the
    six-pin footprint on the board. Mixing the two gives exactly what was
    written here.
    What it would have done: the probe's nRESET is an open drain output, so
    it woul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
    [folha1-energia.kicad_sch, folha2-mcu.kicad_sch, folha3-gnss.kicad_sch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]
2026-09-25 fix(hardware): six pins of the solar harvester were swapped
    The second board-killing mistake of the day, and it was caught the same
    way as the first: two sources disagreed, and the data sheet decided.
    A first reading of the ADP5091 data sheet swapped SIX pins, in two
    permutations of three - 2/4/6 (SETHYST, SETSD, TERM) and 7/9/10 (MPPT,
    VIN, AGND). It only surfaced because KiCad's own Battery_Management:
    ADP5091 symbol disagreed, and because the symbol check had just been
    taught to compare pin NAMES and not only numbers. The numbers matched;
    the signals did not.
    Table 5, pages 8 and 9 of Rev. A (D14145-0-5/17(A)), with Figure 3
    confirming side by side, says KiCad is right on all 24. Three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
    [folha1-energia.kicad_sch, gnssbike.kicad_pcb]
2026-09-25 feat(hardware): the ERC runs, and 52 hidden errors became 4 deliberate ones
    check_sch.py compared our netlist against the one KiCad extracts, pin by
    pin, and was good at that and blind to everything else. KiCad's own ERC
    had never been run on this schematic. It found 52 errors, and among them
    a capacitor with BOTH terminals in the air.
    They were of four kinds, and three of them were the drawing failing to
    say what it meant rather than the circuit being wrong:
    34 open pins with no flag. The NC pins of the ESD array, the GPIOs
    nobody uses, the receiver's SDA and SCL - it speaks UART - the
    programmer's SWO. Every one of them deliberate, and indistinguishable
    from a forgotten wire. The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
    [folha1-energia.kicad_sch, folha2-mcu.kicad_sch, folha3-gnss.kicad_sch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]
2026-09-25 feat(hardware): route the board again and cut the deliverables
    With the harvester's six pins fixed, the debug connector's RESET moved
    and fifteen symbols coming from KiCad's library, everything downstream
    had to be made again.
    Board: 966 segments, 450 vias, 151 connections routed, the KiCad DRC
    with 0 violations and 0 unconnected items, and 18 of the datasheet rules
    measured and met. The one that is not is US1, the USB differential pair,
    which still needs hand finishing at 0,352 mm.
    Schematic: 6 sheets, the ERC accusing no error outside the four that are
    listed with their reason.
    Out of it: the schematic PDF, the board layer by layer, the assembly
    drawing with 110 of 144 references on lea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
    [gnssbike.kicad_pcb]
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2026-09-25 fix(hardware): the USB-C mouth pointed into the board
    J101 sat at 180 degrees, which put the opening 10.04 mm inside the board
    instead of at its edge: no cable would ever have reached it. The owner said
    so twice, and was right both times - the first time I "corrected" it the
    wrong way round, from a rotation worked out in my head instead of measured.
    How it is measured now, and how the new rule ME4 measures it on every run:
    a ray is cast along the connector's axis, through its centre, at half the
    height of the cavity, against the manufacturer's STEP. On the mouth side it
    enters the outer wall and meets nothing again for 3.30 mm - the gap the plug
    slides into. On the back side it hits materia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
    [gnssbike.kicad_pcb]
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2026-09-25 fix(hardware): the manufacturer STEP of the USB-C and the JST came turned
    The owner said it three times - "the USB's STEP is 180 degrees inverted",
    "the mouth of the usb is pointing into the PCB", "the usb 3D needs to rotate
    180" - and he meant the MODEL, not the placement. Twice I turned the
    footprint instead, which was the one thing that was right, and made it
    worse.
    The STEP that LCSC publishes for the HRO TYPE-C-31-M-12 is 180 degrees out
    of the footprint's frame: as it comes, the 16 contact pads sit 1.45 mm
    BEYOND the body, on the opposite side, and the mouth faces the middle of the
    board. The JST ZH has the same fault plus 1.61 mm of offset in x, which left
    one of its two mounting pad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
    [gnssbike.kicad_pcb]
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2026-09-25 fix(hardware): one screw did not hold the board, so now there are two
    The board carried a single M2 hole at (3.2; 45.0), decided on 2026-09-23 to
    leave area for parts and tracks. Measured against the force that actually
    reaches it, one screw does not hold it.
    Plugging in a USB-C applies, at the worst case of the standard, 20 N at
    40.8 mm from that screw - 816 N.mm. An M2 in a printed plastic boss resists
    about 40 N.mm by friction under its head: 0.05 N.m of tightening, a 125 N
    preload, mu 0.2 on a 1.6 mm bearing radius. Twenty times short. A gentle 5 N
    insertion is still five times short and pressing the centre key already ties
    with it, and with 12 mm of clearance to the cavity wall on each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
    [gnssbike.kicad_pcb, zonas.dxf]
2026-09-26 feat(hardware): GNSS receiver on the 3V0 rail, and the electrical items closed with the owner
    The receiver ran at 1.8 V from BUCK1 through a TXU0204 level shifter, and
    table 35 of the MAX-F10S integration manual asks +-2 % of a 1.8 V supply
    where the nPM1300 buck gives +-5 %. A +-1 % LDO from 3V0 fixed the
    tolerance and cost 35 mW at the battery (the receiver paid at 3.0 V with
    1.2 V burnt in the LDO); option 1 of the same table - VCC and V_IO tied at
    3.0 V, VIO_SEL open - costs 11 mW and removes the shifter. The owner chose
    option 1. The receiver now sits on 3V0 through JP103 and the ferrite, the
    four digital lines go pin to pin, the shifter and the LDO leave with four
    capacitors, and BUCK1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
    [folha1-energia.kicad_sch, folha3-gnss.kicad_sch, folha4-display.kicad_sch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]
2026-09-26 fix(hardware): route the USB pair by hand, make the rules measure, and stop saying zero
    Three things in the board chain were reporting results they had never
    measured, and the third dry-run of the project is built on fixing them.
    The DRC ran with --severity-error, which hides unrouted connections
    because KiCad files them as warnings: two documents announced "0
    connections without a track" with 47 and 55 open. Rule RT1 now runs the
    full DRC and counts; check_pcb.py says it does not judge that.
    Rule ME2 (part height under the display and the cell) passed for days
    without a shadow rectangle to measure: the case drawing is the one of the
    old 55 x 97 board, and no file said where the display an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
    [gnssbike.kicad_pcb, zonas.dxf]
2026-09-26 fix(hardware): measure every 3D body against its pads, and fix the two that were turned
    The owner saw, in the 3D view, the solar connector with its solder legs
    pointing at the board edge and its pads on the inside, and asked whether
    passives and ICs were turned too. Both questions are answered by measure
    now, not by eye, and both found something.
    Rule ME5 asks each edge connector on which side of the body the solder
    tails leave it: the faces of the GLB that stand above the copper (the
    GLB carries the board's own copper, and a pad is a flat gold face lying
    exactly where a tail lies; a tail starts above 0.855 mm) and outside the
    fabrication outline, projected on the axis from the body centre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
    [gnssbike.kicad_pcb]
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2026-09-26 feat(hardware): the 10-way SWD header, and a case proposal around the board
    Two of the owner's requests of 2026-09-26.
    J202: the ARM Cortex Debug Connector, 2 x 5 at 1,27 mm, SMD and without
    its shroud (2,5 mm: the shrouded part, 4,83 mm, does not fit under the
    lid), beside the Tag-Connect pads and on the same nets, where the J-Link's
    9-pin Cortex-M adapter plugs in without a clip. SWDCLK and nRESET are
    passive on it so that the ERC does not see two outputs on one net. Left as
    a JUNTO of the module the placer put it under the display; it is placed
    explicitly at (11,3; 72,2), below the keys, right of the M2 hole's square
    and left of the USB pair's corridor. Schematic re-verified against the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
    [caixa-cobertura-chanfro.stl, caixa-cobertura-faceta.stl, caixa-concha.stl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]
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

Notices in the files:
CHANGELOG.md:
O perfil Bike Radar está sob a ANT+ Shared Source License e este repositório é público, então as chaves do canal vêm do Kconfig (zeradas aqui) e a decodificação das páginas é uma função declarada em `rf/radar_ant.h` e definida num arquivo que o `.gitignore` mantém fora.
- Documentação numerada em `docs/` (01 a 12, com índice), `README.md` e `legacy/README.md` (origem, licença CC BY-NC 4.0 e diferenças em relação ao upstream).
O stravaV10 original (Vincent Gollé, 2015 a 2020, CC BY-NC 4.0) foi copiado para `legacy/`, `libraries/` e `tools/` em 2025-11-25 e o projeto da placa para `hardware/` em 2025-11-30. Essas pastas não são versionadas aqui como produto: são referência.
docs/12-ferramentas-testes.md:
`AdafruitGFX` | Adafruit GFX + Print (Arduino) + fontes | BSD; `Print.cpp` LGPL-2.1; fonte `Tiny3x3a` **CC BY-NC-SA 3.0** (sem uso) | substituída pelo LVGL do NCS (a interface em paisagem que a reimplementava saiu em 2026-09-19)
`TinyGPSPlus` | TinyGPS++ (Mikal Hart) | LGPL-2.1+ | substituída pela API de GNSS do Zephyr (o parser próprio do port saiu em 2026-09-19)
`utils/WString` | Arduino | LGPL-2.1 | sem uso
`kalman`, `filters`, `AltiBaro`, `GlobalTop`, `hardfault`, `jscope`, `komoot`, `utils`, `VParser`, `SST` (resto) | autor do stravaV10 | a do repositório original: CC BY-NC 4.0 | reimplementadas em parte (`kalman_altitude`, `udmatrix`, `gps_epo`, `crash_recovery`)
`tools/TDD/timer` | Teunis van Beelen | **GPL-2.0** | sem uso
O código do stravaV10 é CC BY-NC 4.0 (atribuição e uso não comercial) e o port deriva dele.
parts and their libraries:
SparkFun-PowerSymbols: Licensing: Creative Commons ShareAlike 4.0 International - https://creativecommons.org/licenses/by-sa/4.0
